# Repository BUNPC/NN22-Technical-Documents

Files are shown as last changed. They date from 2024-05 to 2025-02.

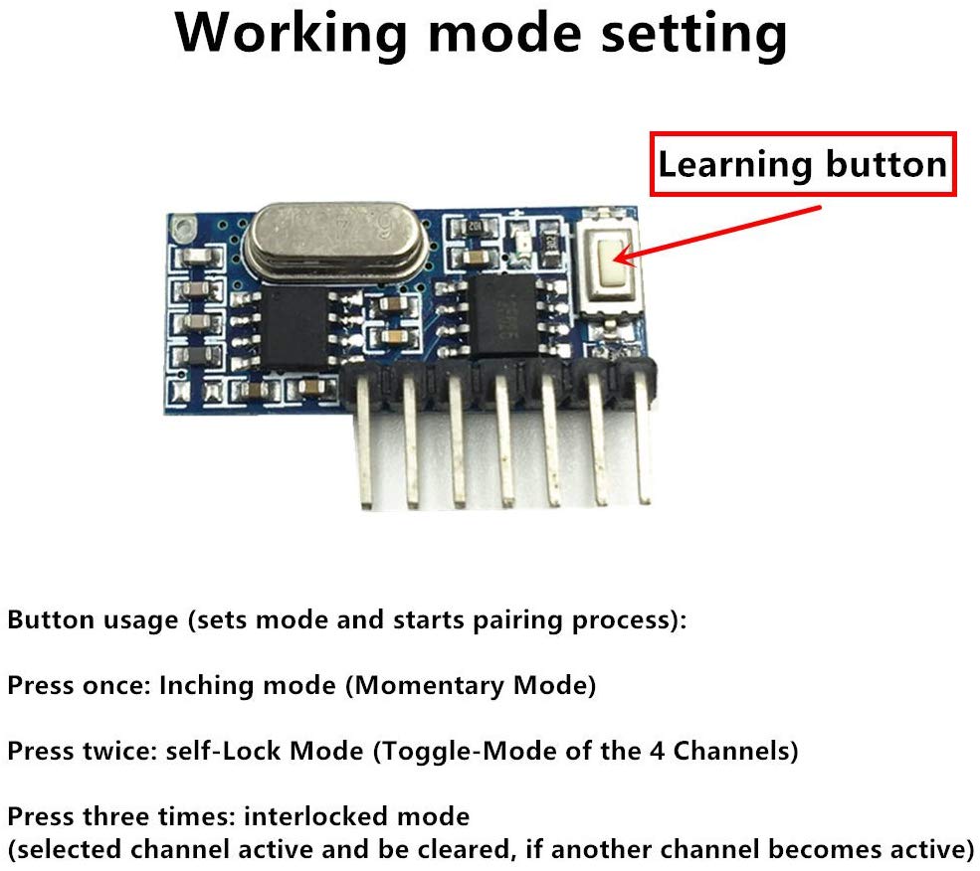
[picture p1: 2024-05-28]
Hardware Peripherial/ninjaNIRS Triggerbox/hardware/Rev1a_Eagle/61eN8m-au2L._AC_SL1001_.jpg

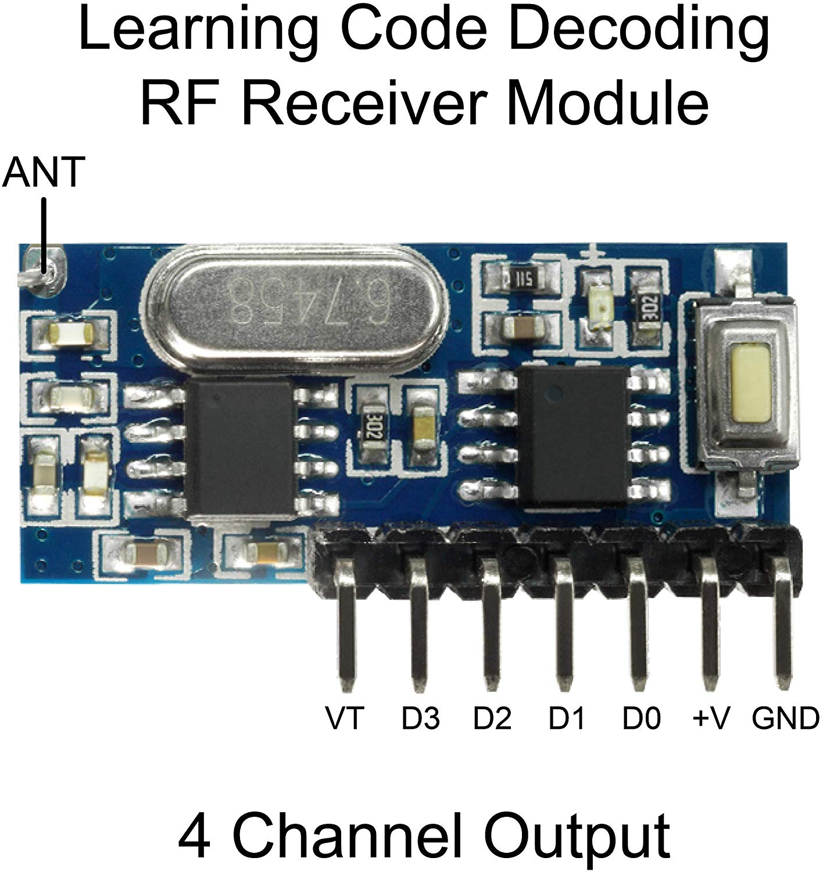
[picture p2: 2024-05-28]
Hardware Peripherial/ninjaNIRS Triggerbox/hardware/Rev1a_Eagle/81+gmd-v-IL._AC_SL1500_.jpg

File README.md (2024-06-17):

This repository contains the technical documentation used to create all parts of the NN22 whole-head fNIRS system.

A description of the documents contained in this respository and other instructions related to the ninjaNIRS system can be found at openfnirs.org [here](https://openfnirs.org/hardware/ninjanirs2022/).

Please use the [Hardware Forum](https://openfnirs.org/community/hardware-forum/) at openfnirs.org to discuss anything about the ninjaNIRS system.

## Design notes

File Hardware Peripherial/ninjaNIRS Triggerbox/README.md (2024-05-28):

# ninjaNIRS-triggerbox

This is a remote wireless trigger/IO box for the ninjaNIRS system.

## Rev 2 board To-Do

* polarity marks on LED
* fix up silkscreen and add text

## Development Log

*2023-08-07* Testing Rev 2.0 board with wireless link

All good.  Only issue is that channels 3 and 4 are swapped.

*2023-05-22* Look at Hammond box 1593XAL.  Nope!  Maybe 1598B?

Meeting with Bernhard.  Agreed-

* Proceed with new design for Hammond box
* Add an LDO on USB power input to run on e.g. 4.1V
* Adjust component values, update a few circuit issues
* Measure I-V curve on logic inputs to radio Tx, ensure 2N3904 can drive them

*2023-05-19* Footprinting and initial placement

*2023-05-17* Test Rev1a boards

*2023-05-15* Capture initial schematic in KiCAD

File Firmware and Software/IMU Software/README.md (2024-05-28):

# NN24 IMU board software

## Notes

MCU is an ATmega168 in a 28MLF package.

Pinout:

	22 PC3 - LED
    23 PC4 - SDA  (hardware TWI)
	24 PC5 - SCL  (hardware TWI)
	26 PD0 - RxD  (USART Rx)
	27 PD1 - TxD  (USART Tx)
	
Software should be pretty straightforward, since the built-in peripherals can be used.

## Software in this folder

| Folder | Description |
|---|---|
| `arduino-demo` | C code (not Arduino) to test the IMU on an Arduino uno |
| | Prints lines of text with 7 values |
| | |
| `avr-imu-readout`  | C code to receive command byte and send IMU data in binary |
| | |
| `avr-imu-blinky` | Blink the LED for quick hardware test |
| | |
| `avr-imu-led-test` | Read the IMU and encode somehow on the LED |
| | (for easy testing without a UART) |
| | |
| `linux-imu-client` | Linux client to read and display binary data from IMU |
| | |
| `BZ_example_code`  | Yes |
| | |

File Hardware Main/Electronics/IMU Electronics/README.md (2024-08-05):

# IMU Electronics
## Updated 5 August, 2024

All IMU electronics files are located in this folder. 

There is not a dedicated IMU backboard part as the IMU interface cards are intended to be used with the existing detector backplanes in place of a detector interface card.

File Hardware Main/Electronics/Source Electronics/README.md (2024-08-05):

# Source Electronics
## Updated 5 August, 2024

All source related files are located within this folder.

Two versions of the backplane are available, the 7 layer and single layer. 
- The 7 layer folder contains the files for the full height backplane to allow for up to 7 source interface cards to be connected.
- The single layer folder contains the files for the system configuration with only one interface card per backboard slot.

Two optode types are available, one standard source optode and one co-located optode.
- Standard source optode has been designed to fit in the spring loaded cap mounts made for the NIRx NIRSport 2 system
- Colocated source optode has been designed to mount on top of the active wet electrodes for the LiveAmp 8/16/32/64 EEG systems. All enclosure documents have also been included.

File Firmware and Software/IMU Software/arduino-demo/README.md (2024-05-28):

# arduino-demo

Initial IMU demo to run on an AVR "bare metal" (gcc-avr and avr-libc).

It initializes everything and prints the 7 values in decimal
(floats are too expensive).

Based on:

Bernhard Z's demo code

I2C code from USC I've used before

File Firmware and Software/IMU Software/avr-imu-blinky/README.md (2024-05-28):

# Blinky

This blinks the LED on an arduino board at 1Hz
(assuming the clock is set to 8MHz)

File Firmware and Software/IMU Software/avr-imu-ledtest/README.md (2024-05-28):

# avr-imu-readout

Readout the IMU in response to a serial command byte

send 7 signed 16-bit integers (low byte first)

see the code for more details

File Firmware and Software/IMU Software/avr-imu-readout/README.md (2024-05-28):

# avr-imu-readout

Readout the IMU in response to a serial command byte.
There are two compile-time options:

1.  Any byte recieved sends the return message
2.  'A' sends IMU data, 'T' sends 1111, 2222, 3333 etc test data

Normal data.  All 16-bit values sent LSB first.

| Offset | Value | Size | Notes |
|---|---|---|---|
| 0 | echo | 8 bits  | received byte |
| 1 | count | 8 bits  | = 14 |
| 2, 3 | temp | 16 bits | raw temperature |
| 4, 5 | gyro_x | 16 bits | raw gyro reading |
| 6, 7 | gyro_y | 16 bits | |
| 8, 9 | gyro_z | 16 bits | |
| 10, 11 | accel_x  | 16 bits | |
| 12, 13 | accel_y  | 16 bits | |
| 14, 15 | accel_z  | 16 bits | |
| 16 | checksum | 8 bits  | unsigned sum of offsets 1..15 |

Error response (may not be a complete list):

| Offset | Value | Size | Notes | |
|---|---|---|---|---|
| 0 | echo | 8 bits | received byte | |
| 1 | count | 8 bits | = 1 | |
| 2 | error | 8 bits | | |
| | | | 0x20 | NAK received after sending device address for writing |
| | | | 0x30 | NAK received after sending data |
| | | | 0x38 | Arbitration lost with address or data |
| | | | 0x48 | NAK received after sending device address for reading |
| | | | 0xff | unexpected data from IMU |
| 3 | checksum | 8 bits | | unsigned sum of offsets 1, 2 |

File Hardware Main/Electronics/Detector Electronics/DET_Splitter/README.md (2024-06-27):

# readout-splitter

This is a splitter board designed to be plug-compatible with the TIGRIS one.
See top-level README for some more details.

Connector from readout system is a Samtec SHF-117-01-L-D-SM shrouded 34-pin header
with 0.05" pitch.

Detector connector is Samtec SFMC-118-02-S-D 36-pin socket strip with 0.05" pitch.
Note that the TIGRIS schematic and layout use mirrored pinout for the detector connector
(odd-even swap).

Designed LDOs:

* Negative: ADP7182ACPZN-R7
* Positive: ADP7142ACPZN5.0-R7

The negative adjustable regulator should output -15.0V with the resistors shown.
There is an additional filter in the design (R+C on front side) which can
(according to the datasheet) reduce the noise a bit in the negative regulator.
There is no such provision for the positive regulator.

This is a 4-layer board and a bit dense.  There were a few compromises
made in routing with shared vias, etc but hopefully it will be OK.

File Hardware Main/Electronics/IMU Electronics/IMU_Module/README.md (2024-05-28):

# ninjanirs-imu

IMU and multiplexer designs for ninjaNIRS

## IMU Board

Board designed in early 2024 along with various adapters and a splitter.
The IMU board has an ATMeg168 so plenty of resources.

### UART connector pinout

    1 - VCC (5V or 3.3V)
	2 - TxD (output from MCU)
	3 - RxD (input to MCU)
	4 - GND
	
### RJ Adapter board pinout

    GND     1
	RxD        2
	TxD     3
	VCC        4

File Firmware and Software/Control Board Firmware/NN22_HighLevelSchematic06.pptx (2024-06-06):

## NinjaNIRS 2022 Firmware Schematic and Data Format Specification

Version 2023-8-17
Bernhard Zimmermann – bzim@bu.edu

## Control Card Block Diagram

Boston University Neurophotonics Center

Source Backplane

Detector Backplanes

Detector Backplanes

Detector Backplanes

Detector Backplanes

1 Backplane Connector
21 GPIO
(3 rows + 7x2 columns + 3 power select + 1 spare)

4 Backplane Connectors
Per Connector 17 GPIO
(5 common + 4x3 direct)

UART + SWD + 1 GPIO

2 GPIO (incl I2C)

Aux ADCs

PSRAM

PSRAM

6 GPIO

4 GPIO

2 GPIO

Aux DigIO

Remote Dig In

15 GPIO
UART with CTS/RTS or parallel data

2x6 GPIO

FPGA

4 GPIO

7 GPIO

Spare Con2

Spare Con.

12 GPIO

9 GPIO (incl RPi 0 SPI)

6 GPIO

FTDI USB

UART with RTS/CTS

RP2040

RPi Zero

## FPGA Firmware Block Diagram

27 x 1024
State Sequence RAM A

18 x 1024
Acquisition Sequence RAM B

Status Registers

8 rows
8 columns
3 power select

Source Backplane

Host PC

FTDI USB

USB

UART with RTS/CTS

UART Rx

Config
FSM

Program
Counter A

1 Trigger
1 Trigger Status
1 End Cycle
16 Board Select

+1

Detector Backplanes

Program
Counter B

+1

UART Rx

Clock Divider

readback

Acq
FSM/MUX

FPGA

UART Tx

FIFO

Aux ADC
Interface

## RAM Data Formats

RAM A: State Sequence

| 26 | 25 | 24 | 23 | 22 | 21 | 20 | 19 | 18 | 17 | 16 | 15 | 14 | 13 | 12 | 11 | 10 | 9 | 8 | 7 | 6 | 5 | 4 | 3 | 2 | 1 | 0
state 0 | end | X reserved | | | | stat | power | stat | power | column select | | column select | data source | | packet count | | | Lsr id | | | | | | X | row select
⁞
S 1023

End: 1 if last state in sequence: will jump to state 0 next; 0 otherwise: will jump to state i+1 next
X Reserved: reserved for later use
Status: ‘1’ send status packets instead of regular light level packets; ‘0’ send regular packets
Power: select LED power level. 0b001: high power, 0b010: mid power, 0b100: low power, 0b000: off (dark state)
Column select: Select column of LED to be illuminated. Even numbers correspond to XXX nm, odd numbers to YYY nm. This is selecting source boards.
Row select: Select row of LED to be illuminated. This is switching between LEDs in a source board

RAM B: Acquisition Sequence

| 17 | 16 | 15 | 14 | 13 | 12 | 11 | 10 | 9 | 8 | 7 | 6 | 5 | 4 | 3 | 2 | 1 | 0
State 0 | End | X | X | X | X | X | X | X | Acq Trg | End cyc | PC Tx Trg | Aux Tx Trg | DetB Rx En | X | UART Rx Mux

End: 1 if last state in sequence: will jump to state 0 next; 0 otherwise: will jump to state i+1 next
X Reserved: reserved for later use
Acq Trg: Transition form ‘0’ to ‘1’ will trigger the acquisition of one sample in the detector boards
End Cyc: Transition form ‘0’ to ‘1’ will cause the detector boards to move the current measurements to the transmit buffer, and reset the sample sums to 0
PC Tx Trg: Program counter A transmit trigger. Transition form ‘0’ to ‘1’ will cause the current program counter A (state) to be transmitted
Aux Tx Trg: Auxillary transmit trigger. Transition form ‘0’ to ‘1’ will cause the current auxiliary ADC values to be transmitted.
DetB Rx En: Enable reception of data from the detector board selected by UART Rx Mux. Sets CTS for the selected board.
UART Rx Mux: Selects from which detector board to receive data.

## Status Register Format

Status Register

| 23 | 22 | 21 | 20 | 19 | 18 | 17 | 16 | 15 | 14 | 13 | 12 | 11 | 10 | 9 | 8 | 7 | 6 | 5 | 4 | 3 | 2 | 1 | 0
| VN22Clk en | VN3P4 en | VN22 en | V9P0 en | V5P1src en | V5P1RPi en | V5P1B23 en | V5P1B01 en | Clk Div | | | | | | | | X | Rst Ram | Rst PC A | Rst DetB | | | Rst DetB | Run

Clk Div: Clock divider setting. RAM B state period = ClkDiv*8/96MHz
Rst Ram: Reset the PSRAM chip used in the external FIFO.
Rst PC A: Reset program counter A to 0
Rst DetB: Reset the microcontroller on the detector boards by pulling the RUN pins low. Each bit corresponds to one backplane.
Run: ‘1’: the clock divider and program counters A and B will run. ‘0’: Divider continues to run until PC B and the divider reach Zero, and then stay there. LED power will be set to 0 immediately.

## Command Format

Command sequence

| byte[0] | byte[1] | byte[2] | byte[3] | byte[4] | byte[5] | byte[6]
| 255 | addr[0] | addr[1] | rdat[0] | rdat[1] | rdat[2] | rdat[3]

Each command starts with a header byte (‘255’), then 2 address bytes, then 4 command payload bytes.
Addr: Address of data to be written or read. (see below)
Rdat: Register or RAM data to be written. Write all ‘0’ when reading a register / RAM location.

Command address format

| 15 | 14 | 13 | 12 | 11 | 10 | 9 | 8 | 7 | 6 | 5 | 4 | 3 | 2 | 1 | 0
| addr[1] | | | | | | | | addr[0]
| r̄/w | addr | X | X | X | X | Acq Trg | End cyc | PC Tx Trg | Aux Tx Trg | DetB Rx En | X | UART Rx Mux

r̄/w: ‘1’: write to the location specified by ‘addr’. ‘0’: read from location ‘addr’. Read is only save if Run = ‘0’.
Addr: Address to be read or written.
0b001 0000 0000 0000 through 0b 001 0011 1111 1111 : RAM A
0b010 0000 0000 0000 through 0b 001 0011 1111 1111 : RAM B
0b100 0000 0000 0001 : Status Register

## Output Data Packet Format

Note: The order of the individual data blocks below is determined by the contents of RAM A. The order shown below is a typical example as also implemented in the MATLAB helper functions.

Output data sequence

| byte[0..2] | byte[(0..7)+3] | byte[(0..27)+11] | … | byte[(0..27)+(n-1)*28+11] | byte[(0..17)+n*28+11]
| PC A packet | Auxiliary pkt | Det adapter pkt | … | Det adapter pkt | Accelerometer pkt

n: number of plugged in Detector Adapter Boards
See following slides for details on the individual packets.

## Program Counter A Packet Format

Packet generated by the FPGA, usually placed at the beginning of a sample/RAM B cycle to help framing the data.
See also PC TX Trg signal in RAM B data format slide.

Output data sequence

| byte[0] | byte[1] | byte[2]
| 254 | PC A [0] | PC A [1]

PC A [1]: high byte of program counter A
PC A [0]: low byte of program counter A

## Auxiliary Packet Format

Data packet generated by the FPGA. Contains the values of the two on-board auxiliary analog to digital converters (ADC). The ADCs are sampled and averaged at the same time and in the same manner as the main ADCs on the detector boards.
The packet also contains the status of the remote trigger signals and the Aux Digital inputs. These signals are sampled a few clock cycles after the rising edge of the “Aux Trg Tx” signal (see RAM B description).

| byte[0] | byte[1] | byte[2] | byte[3] | byte[4] | byte[5] | byte[6] | byte[7]
| 250 | Dig In | ADC0[0] | ADC0[1] | ADC0[2] | ADC1[0] | ADC1[1] | ADC1[2]

Dig In: Remote trigger and aux digital inputs sampled at time of “Aux Trg Tx” signal.
Bits (0..3): remote trigger signals.
Bits (4..5): aux digital inputs.
ADCx: 24 bit sum of all conversions since last “Aux Trg Tx” signal. [2] is the high byte (little endian). Unsigned integer.

Output data sequence

## Detector Adapter Packet Format

Data packet from the RP2040 microcontroller on a detector adapter board. Contains the main light intensity data.

| byte[0] | byte[1] | byte[2] | byte[3] | byte[4] | byte[5] | … | byte[24] | byte[25] | byte[26] | byte[27]
| 253 | 252 | Smp cnt | ADC0[0] | ADC0[1] | ADC0[2] | | ADC7[0] | ADC7[1] | ADC7[2] | 0

Smp cnt: Count of transmitted samples (modulo 256) since last restart of the detector adapter card.
ADCx: 24 bit sum of all conversions since last ‘end cycle’ signal. [2] is the high byte (little endian). Signed integer / two’s complement.

Output data sequence

## Detector Adapter Status Packet Format

Status data packet from the RP2040 microcontroller on a detector adapter board.

| byte[0] | byte[1] | byte[2] | byte[3] | … | byte[10] | byte[11] | byte[12] | byte[13] | byte[14] | byte[15] | byte[16] | byte[17]
| 237 | 236 | Smp cnt | UID[0] | | UID[7] | FWv[0] | FWv[1] | Temp[0] | Temp[1] | 0 | 0 | 0

Smp cnt: Count of transmitted samples (modulo 256) since last restart of the microcontroller.
UID: 64 bit unique ID from flash attached to microcontroller
FW: Firmware version.
Temp: Microcontroller internal temperature.
Conn flag: accelerometer connected flags (acc_connected_before_run<<1) || acc_connected_curr)

Output data sequence

## Accelerometer Packet Format

Data packet from the RP2040 microcontroller on the main control board. Contains the data read out from an IMU attached to the QWIIC port.

| byte[0] | byte[1] | byte[2] | byte[3] | byte[4] | … | byte[15] | byte[16] | byte[17]
| 249 | 248 | Smp cnt | Data0[0] | Data0[1] | | Data6[0] | Data6[1] | 0

Smp cnt: Count of transmitted samples (modulo 256) since last restart of the microcontroller.
Datax: 16 bit data words from the IMU, obtained right after last “End cyc” signal. [1] is the high byte (little endian). Signed integer / two’s complement.
Data0: Temperature
Data1: Gyro X
Data2: Gyro Y
Data3: Gyro Z
Data4: Accelerometer X
Data5: Accelerometer Y
Data6: Accelerometer Z

Output data sequence

## Accelerometer Status Packet Format

Status data packet from the RP2040 microcontroller on the main control board. Contains the controller temperature and board input voltage.

| byte[0] | byte[1] | byte[2] | byte[3] | … | byte[10] | byte[11] | byte[12] | byte[13] | byte[14] | byte[15] | byte[16] | byte[17] | byte[18] | byte[19]
| 237 | 236 | Smp cnt | UID[0] | | UID[7] | FWv[0] | FWv[1] | Temp[0] | Temp[1] | Vin[0] | Vin[1] | Conn flag | 0 | 0

Smp cnt: Count of transmitted samples (modulo 256) since last restart of the microcontroller.
UID: 64 bit unique ID from flash attached to microcontroller
FW: Firmware version.
Temp: Microcontroller internal temperature.
Vin: Control board input voltage.
Conn flag: accelerometer connected flags (acc_connected_before_run<<1) || acc_connected_curr)

Output data sequence

## Summary of Packet Headers

Summary of packet headers from the different data sources.

Packet Type | Header
Command from PC to FPGA | [255]
Reply to command (FPGA => PC) | [240]
Program Counter A Packet | [254]
Auxiliary Data Packet | [250]
Detector Adapter Data Packet | [253 252]
Detector Adapter Status Packet | [239 238]
IMU Controller Data Packet | [249 248]
IMU Controller Status Packet | [237 236]

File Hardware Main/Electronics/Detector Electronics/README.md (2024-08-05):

# Detector Electronics
## Updated 5 August, 2024

All detector related files are located within this folder.

Two versions of the backplane are available, the 6 layer and single layer. The 6 layer folder contains the files for the full height backplane to allow for up to 6 detector interface cards to be connected and the single layer folder contains the files for the system configuration with only one interface card per backboard slot.

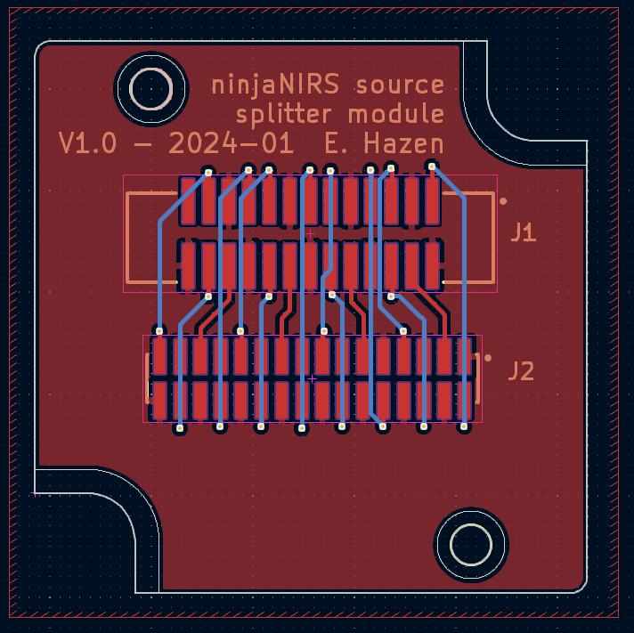
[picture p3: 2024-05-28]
Hardware Main/Electronics/Source Electronics/SRC_Splitter/source-splitter-layout-view.png

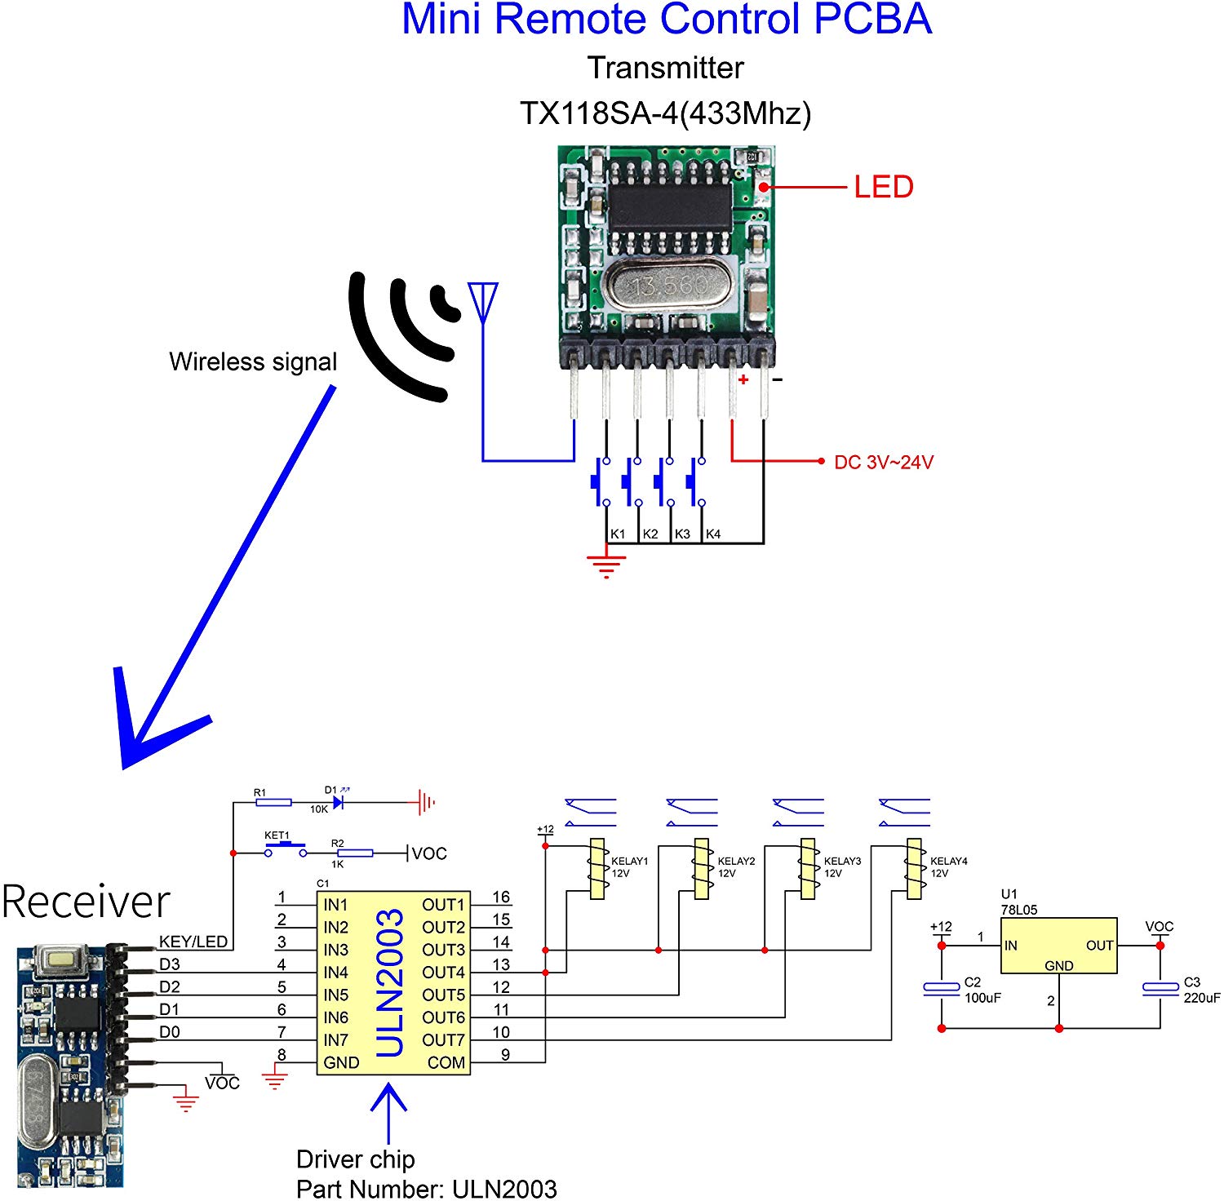
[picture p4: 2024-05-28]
Hardware Peripherial/ninjaNIRS Triggerbox/hardware/Rev1a_Eagle/81bwLxzH8NL._AC_SL1500_.jpg

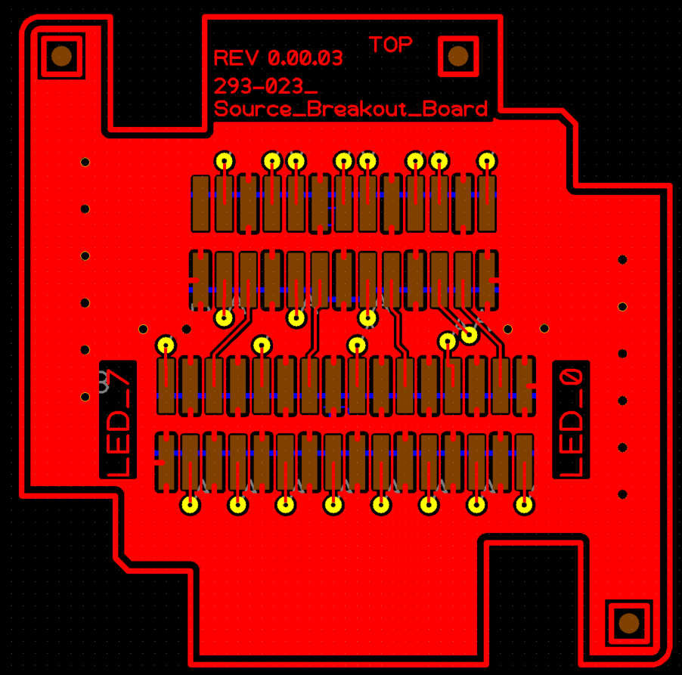
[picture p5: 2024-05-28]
Hardware Main/Electronics/Source Electronics/SRC_Optode/Standard Optode/PCB Files/Datasheets/SRC_BOX_Layout.png

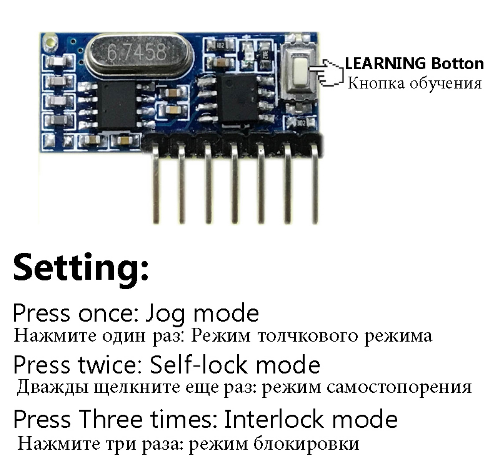
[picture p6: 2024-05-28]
Hardware Peripherial/ninjaNIRS Triggerbox/hardware/Rev1a_Eagle/423790-1a9fda4640fa45f28f44fabd3a5eae38_600x.png

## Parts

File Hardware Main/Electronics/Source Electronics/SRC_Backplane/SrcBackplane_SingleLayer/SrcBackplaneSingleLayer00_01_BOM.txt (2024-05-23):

connectors are Adam Tech ESMC-F-40-SGR-SMT-T/R

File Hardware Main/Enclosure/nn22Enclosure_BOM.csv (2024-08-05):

Line | Qty. | Item | Vendor | Part No.
1 | 2 | M4x0.7mm, 100mm Lg Socket Head Screws | McMaster Carr | 91290A185
2 | 3 | M4x0.7mm, 18mm Lg Socket Head Screws | McMaster Carr | 91290A164 | 1x fan attachment to case (interface card lower corner), 2x upper nylon strap holder (one each on end closest to ribbon cables)
3 | 9 | M4x0.7mm, 12mm Lg Socket Head Screws | McMaster Carr | 91290A148 | 4x fan filter, 1x fan attachment to case (main pcb upper corner), 2x upper nylon strap holder (one each on end closest to control board), 2x bottom ribbon cable support attachment
4 | 14 | M4x0.7mm Hex Nut | McMaster Carr | 90591A255
5 | 4 | M3x0.5mm, 8mm Lg Low-Profile Socket Head Screws | McMaster Carr | 93070A064
6 | 4 | M3x0.5mm, 5mm Lg Male-Female Threaded Hex Standoffs | McMaster Carr | 93655A091
7 | 4 | M3x0.5mm Nylon Insert Locknut | McMaster Carr | 90576A811
8 | 8 | 3/16"x3/16" Neodymium Cylinder Magnet | McMaster Carr | 5862K108 | If this size is unavailable another diameter can be used if models are altered
9 | 1 | 3/16" thick, 1/4" Wd Foam Strip w/ adhesive backing | McMaster Carr | 8694K124
10 | 1 | 3/16" thick acrylic | McMaster Carr | 8505K748
11 | 1 | 1/4" thick acrylic | McMaster Carr | 8505K754

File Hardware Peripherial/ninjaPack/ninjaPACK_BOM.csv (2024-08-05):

Line | Qty. | Item | Vendor | Part No.
1 | 4 | M3x0.5mm, 30mm Lg (Enclosure Corners) | McMaster Carr | 92125A140
2 | 4 | M3x0.5mm, 12mm Lg (PCB Corners) | McMaster Carr | 91290A117
3 | 4 | M3 nylon washer (PCB Corners) | McMaster Carr | 95610A330
4 | 8 | M3x0.5mm Hex Nut | McMaster Carr | 90591A250
5 | 4 | M4x0.7mm, 15mm Lg (Battery Carriers) | McMaster Carr | 91290A306
6 | 4 | M4x0.7mm Hex Nut | McMaster Carr | 90591A255
7 | 2 | Dewalt 12V battery adapter | Amazon | B09N42RJKW | https://a.co/d/3aEim6k
8 | 1 | WOJ-DBENC-001-RevAB (Dual Battery Enclosure Lid)
9 | 1 | WOJ-DBENC-002-RevAB (Dual Battery Enclosure Base)
10 | 1 | WOJ-DBPCB-SA-001-RevAB (Dual Battery PCB Subassembly)

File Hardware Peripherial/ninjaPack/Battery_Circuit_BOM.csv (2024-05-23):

Part | Value | Device | Package | Description | ARROW_PART_NUMBER | ARROW_PRICE-STOCK | DESCRIPTION | HEIGHT | MANUFACTURER_NAME | MANUFACTURER_PART_NUMBER | MOUSER_PART_NUMBER | MOUSER_PRICE-STOCK | PROD_ID | VALUE
C1 | 0.1uF | 0.1UF-KIT-EZ-50V-20% | CAP-PTH-SMALL-KIT | 0.1µF ceramic capacitors |  |  |  |  |  |  |  |  | CAP-08370 | 0.1uF
C2 | 0.1uF | 0.1UF-KIT-EZ-50V-20% | CAP-PTH-SMALL-KIT | 0.1µF ceramic capacitors |  |  |  |  |  |  |  |  | CAP-08370 | 0.1uF
IC2 | LTC4357IMS8#TRPBF | LTC4357IMS8#TRPBF | SOP65P490X110-8N | Hot Swap Controller 1-CH 80V N-Channel Positive High Voltage Automotive 8-Pin MSOP T/R | LTC4357IMS8#TRPBF | https://www.arrow.com/en/products/ltc4357ims8trpbf/analog-devices?region=nac | Hot Swap Controller 1-CH 80V N-Channel Positive High Voltage Automotive 8-Pin MSOP T/R | 1.1mm | Analog Devices | LTC4357IMS8#TRPBF | 584-LTC4357IMS8TRPBF | https://www.mouser.co.uk/ProductDetail/Analog-Devices/LTC4357IMS8TRPBF?qs=hVkxg5c3xu9xOCu4lpdF5Q%3D%3D
IC3 | LTC4357IMS8#TRPBF | LTC4357IMS8#TRPBF | SOP65P490X110-8N | Hot Swap Controller 1-CH 80V N-Channel Positive High Voltage Automotive 8-Pin MSOP T/R | LTC4357IMS8#TRPBF | https://www.arrow.com/en/products/ltc4357ims8trpbf/analog-devices?region=nac | Hot Swap Controller 1-CH 80V N-Channel Positive High Voltage Automotive 8-Pin MSOP T/R | 1.1mm | Analog Devices | LTC4357IMS8#TRPBF | 584-LTC4357IMS8TRPBF | https://www.mouser.co.uk/ProductDetail/Analog-Devices/LTC4357IMS8TRPBF?qs=hVkxg5c3xu9xOCu4lpdF5Q%3D%3D
Q1 | RD3P08BBDTL | RD3P08BBDTL | RD3P175SNFRATL | RD3P08BBDTL N-Channel MOSFET, 80 A, 100 V RD3P08BBD, 3-Pin DPAK ROHM |  |  | RD3P08BBDTL N-Channel MOSFET, 80 A, 100 V RD3P08BBD, 3-Pin DPAK ROHM | mm | ROHM Semiconductor | RD3P08BBDTL | 755-RD3P08BBDTL | https://www.mouser.co.uk/ProductDetail/ROHM-Semiconductor/RD3P08BBDTL?qs=qSfuJ%252Bfl%2Fd6NkJEicmek1A%3D%3D
Q2 | RD3P08BBDTL | RD3P08BBDTL | RD3P175SNFRATL | RD3P08BBDTL N-Channel MOSFET, 80 A, 100 V RD3P08BBD, 3-Pin DPAK ROHM |  |  | RD3P08BBDTL N-Channel MOSFET, 80 A, 100 V RD3P08BBD, 3-Pin DPAK ROHM | mm | ROHM Semiconductor | RD3P08BBDTL | 755-RD3P08BBDTL | https://www.mouser.co.uk/ProductDetail/ROHM-Semiconductor/RD3P08BBDTL?qs=qSfuJ%252Bfl%2Fd6NkJEicmek1A%3D%3D
R1 | 100 | 100OHM-HORIZ-1/4W-1% | AXIAL-0.3 | 100Ω resistor |  |  |  |  |  |  |  |  | RES-12181 | 100
R2 | 100 | 100OHM-HORIZ-1/4W-1% | AXIAL-0.3 | 100Ω resistor |  |  |  |  |  |  |  |  | RES-12181 | 100
S1 | A8L-21-12N2 | A8L-21-12N2 | A8L2112N2 | Rocker Switches ROCKER SWITCH |  |  | Rocker Switches ROCKER SWITCH | 22.1mm | Omron Electronics | A8L-21-12N2 | 653-A8L-21-12N2 | https://www.mouser.co.uk/ProductDetail/Omron-Electronics/A8L-21-12N2?qs=wE98CiVmOw76dmZWfHCJ3A%3D%3D

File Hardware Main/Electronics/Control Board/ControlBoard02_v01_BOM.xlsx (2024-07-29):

Designator | Value | Footprint | Populate | MPN | Manufacturer | MPN | Manufacturer
C1001 | 0.1u | 0402-CAP | 1 | GRM155R71H104KE14D | Murata
C1002 | 0.1u | 0402-CAP | 1 | GRM155R71H104KE14D | Murata
C1003 | 4.7u | 0402-CAP | 1 | CL05A475MP5NRNC | Samsung
C1004 | 22u | 0805-CAP | 1 | CL21A226MAYNNNE | Samsung
C1005 | 10n | 0603-CAP | 1 | GRM1885C1H103JA01D | Murata
C1006 | 0.1u | 0402-CAP | 1 | GRM155R71H104KE14D | Murata
C1007 | 4.7u | 0402-CAP | 1 | CL05A475MP5NRNC | Samsung
C1008 | 4.7u | 0402-CAP | 1 | CL05A475MP5NRNC | Samsung
C1009 | 0.1u | 0402-CAP | 1 | GRM155R71H104KE14D | Murata
C101 | 0.1u | 0402-CAP | 1 | GRM155R71H104KE14D | Murata
C1010 | 0.1u | 0402-CAP | 1 | GRM155R71H104KE14D | Murata
C201 | 0.1u | 0402-CAP | 1 | GRM155R71H104KE14D | Murata
C202 | 0.1u | 0402-CAP | 1 | GRM155R71H104KE14D | Murata
C203 | 0.1u | 0402-CAP | 1 | GRM155R71H104KE14D | Murata
C204 | 0.1u | 0402-CAP | 1 | GRM155R71H104KE14D | Murata
C205 | 27p | 0402-CAP | 1 | GCM1555C1H270JA16D | Murata
C206 | 27p | 0402-CAP | 1 | GCM1555C1H270JA16D | Murata
C207 | 0.1u | 0402-CAP | 1 | GRM155R71H104KE14D | Murata
C301 | 0.1u | 0402-CAP | 1 | GRM155R71H104KE14D | Murata
C501 | 0.1u | 0402-CAP | 1 | GRM155R71H104KE14D | Murata
C502 | 4.7u | 0402-CAP | 1 | CL05A475MP5NRNC | Samsung
C503 | 10n | 0603-CAP | 1 | GRM1885C1H103JA01D | Murata
C504 | 0.1u | 0402-CAP | 1 | GRM155R71H104KE14D | Murata
C505 | 10n | 0603-CAP | 1 | GRM1885C1H103JA01D | Murata
C506 | 22u | 0805-CAP | 1 | CL21A226MAYNNNE | Samsung
C507 | 0.1u | 0402-CAP | 1 | GRM155R71H104KE14D | Murata
C508 | 0.1u | 0402-CAP | 1 | GRM155R71H104KE14D | Murata
C509 | 4.7u | 0402-CAP | 1 | CL05A475MP5NRNC | Samsung
C510 | 4.7u | 0402-CAP | 1 | CL05A475MP5NRNC | Samsung
C601 | 4.7u | 0402-CAP | 1 | CL05A475MP5NRNC | Samsung
C602 | 4.7u | 0402-CAP | 1 | CL05A475MP5NRNC | Samsung
C603 | 0.1u | 0402-CAP | 1 | GRM155R71H104KE14D | Murata
C604 | 4.7u | 0402-CAP | 1 | CL05A475MP5NRNC | Samsung
C605 | 4.7u | 0402-CAP | 1 | CL05A475MP5NRNC | Samsung
C606 | 0.1u | 0402-CAP | 1 | GRM155R71H104KE14D | Murata
C607 | 0.1u | 0402-CAP | 1 | GRM155R71H104KE14D | Murata
C608 | 0.1u | 0402-CAP | 1 | GRM155R71H104KE14D | Murata
C609 | 22u | 0805-CAP | 1 | CL21A226MAYNNNE | Samsung
C610 | 4.7u | 0402-CAP | 1 | CL05A475MP5NRNC | Samsung
C611 | 27p | 0402-CAP | 1 | GCM1555C1H270JA16D | Murata
C612 | 27p | 0402-CAP | 1 | GCM1555C1H270JA16D | Murata
C613 | 0.1u | 0402-CAP | 1 | GRM155R71H104KE14D | Murata
C614 | 0.1u | 0402-CAP | 1 | GRM155R71H104KE14D | Murata
C615 | 0.1u | 0402-CAP | 1 | GRM155R71H104KE14D | Murata
C616 | 0.1u | 0402-CAP | 1 | GRM155R71H104KE14D | Murata
C617 | 0.1u | 0402-CAP | 1 | GRM155R71H104KE14D | Murata
C618 | DNP | 1210 | 0
C619 | 0.1u | 0402-CAP | 1 | GRM155R71H104KE14D | Murata
C620 | 0.1u | 0402-CAP | 1 | GRM155R71H104KE14D | Murata
C621 | 0.1u | 0402-CAP | 1 | GRM155R71H104KE14D | Murata
C622 | 0.1u | 0402-CAP | 1 | GRM155R71H104KE14D | Murata
C623 | 0.1u | 0402-CAP | 1 | GRM155R71H104KE14D | Murata
C624 | 0.1u | 0402-CAP | 1 | GRM155R71H104KE14D | Murata
C625 | 0.1u | 0402-CAP | 1 | GRM155R71H104KE14D | Murata
C626 | 0.1u | 0402-CAP | 1 | GRM155R71H104KE14D | Murata
C701 | 22p | 0402-CAP | 1 | GCM1555C1H220JA16D | Murata
C702 | 22u | 0805-CAP | 1 | CL21A226MAYNNNE | Samsung
C703 | 22u | 0805-CAP | 1 | CL21A226MAYNNNE | Samsung
C704 | 22u | 0805-CAP | 1 | CL21A226MAYNNNE | Samsung
C705 | 100u/25V | 2917-CAP | 1 | TCJD107M025R0055 | KYOCERA AVX
C706 | 22u | 0805-CAP | 1 | CL21A226MAYNNNE | Samsung
C707 | 100u/25V | 2917-CAP | 1 | TCJD107M025R0055 | KYOCERA AVX
C708 | 100u/25V | 2917-CAP | 1 | TCJD107M025R0055 | KYOCERA AVX
C709 | 22u | 0805-CAP | 1 | CL21A226MAYNNNE | Samsung
C710 | 22u | 0805-CAP | 1 | CL21A226MAYNNNE | Samsung
C711 | 39p | 0402-CAP | 1 | CC0402JRNPO9BN390 | Yageo
C712 | 22u | 0805-CAP | 1 | CL21A226MAYNNNE | Samsung
C713 | 22u | 0805-CAP | 1 | CL21A226MAYNNNE | Samsung
C714 | 22u | 0805-CAP | 1 | CL21A226MAYNNNE | Samsung
C715 | 39p | 0402-CAP | 1 | CC0402JRNPO9BN390 | Yageo
C716 | 22u | 0805-CAP | 1 | CL21A226MAYNNNE | Samsung
C717 | 22u | 0805-CAP | 1 | CL21A226MAYNNNE | Samsung
C718 | 330u/25V | CAP-SMD-POL-8X10 | 1 | EEE-FP1E331AP | Panasonic
C719 | 22u | 0805-CAP | 1 | CL21A226MAYNNNE | Samsung
C720 | 39p | 0402-CAP | 1 | CC0402JRNPO9BN390 | Yageo
C721 | 22u | 0805-CAP | 1 | CL21A226MAYNNNE | Samsung
C722 | 22u | 0805-CAP | 1 | CL21A226MAYNNNE | Samsung
C723 | 22u | 0805-CAP | 1 | CL21A226MAYNNNE | Samsung
C724 | 39p | 0402-CAP | 1 | CC0402JRNPO9BN390 | Yageo
C725 | 22u | 0805-CAP | 1 | CL21A226MAYNNNE | Samsung
C726 | 22u | 0805-CAP | 1 | CL21A226MAYNNNE | Samsung
C727 | 22u | 0805-CAP | 1 | CL21A226MAYNNNE | Samsung
C728 | 22u | 0805-CAP | 1 | CL21A226MAYNNNE | Samsung
C729 | 10n | 0603-CAP | 1 | GRM1885C1H103JA01D | Murata
C730 | 1n | 0603-CAP | 1 | GRM1885C1H102JA01D | Murata
C731 | 22u | 0805-CAP | 1 | CL21A226MAYNNNE | Samsung
C801 | 100u/25V | 2917-CAP | 1 | TCJD107M025R0055 | KYOCERA AVX
C802 | 4.7u | 0805-CAP | 1 | CL21A475KBQNNNE | Samsung
C803 | 4.7u | 0805-CAP | 1 | CL21A475KBQNNNE | Samsung
C804 | 10u | 1206 | 1 | CL31A106MBHNNNE | Samsung
C805 | 10u | 1206 | 1 | CL31A106MBHNNNE | Samsung
C806 | 10u | 1206 | 1 | CL31A106MBHNNNE | Samsung
C807 | 4.7u | 0805-CAP | 1 | CL21A475KBQNNNE | Samsung
C808 | 4.7u | 0805-CAP | 1 | CL21A475KBQNNNE | Samsung
C809 | 4.7u | 0805-CAP | 1 | CL21A475KBQNNNE | Samsung
C810 | 4.7u | 0805-CAP | 1 | CL21A475KBQNNNE | Samsung
C811 | 1u | 0603-CAP | 1 | CL10A105KB8NNNC | Samsung
C812 | 100u/25V | 2917-CAP | 1 | TCJD107M025R0055 | KYOCERA AVX
C813 | 4.7u | 0805-CAP | 1 | CL21A475KBQNNNE | Samsung
C814 | 4.7u | 0805-CAP | 1 | CL21A475KBQNNNE | Samsung
C815 | 10u | 1206 | 1 | CL31A106MBHNNNE | Samsung
C816 | 10u | 1206 | 1 | CL31A106MBHNNNE | Samsung
C817 | 10u | 1206 | 1 | CL31A106MBHNNNE | Samsung
C818 | 4.7u | 0805-CAP | 1 | CL21A475KBQNNNE | Samsung
C819 | 4.7u | 0805-CAP | 1 | CL21A475KBQNNNE | Samsung
C820 | 4.7u | 0805-CAP | 1 | CL21A475KBQNNNE | Samsung
C821 | 4.7u | 0805-CAP | 1 | CL21A475KBQNNNE | Samsung
C822 | 1u | 0603-CAP | 1 | CL10A105KB8NNNC | Samsung
C823 | 4.7u | 0805-CAP | 1 | CL21A475KBQNNNE | Samsung
C824 | 4.7u | 0805-CAP | 1 | CL21A475KBQNNNE | Samsung
C825 | 100u | 1206 | 1 | CL31A107MQHNNNE | Samsung
C826 | 100u | 1206 | 1 | CL31A107MQHNNNE | Samsung
C827 | DNP | 1206 | 0
C828 | 4.7u | 0805-CAP | 1 | CL21A475KBQNNNE | Samsung
C829 | 4.7u | 0805-CAP | 1 | CL21A475KBQNNNE | Samsung
C830 | 1u | 0603-CAP | 1 | CL10A105KB8NNNC | Samsung
C831 | 100u/25V | 2917-CAP | 1 | TCJD107M025R0055 | KYOCERA AVX
C901 | 22u | 0805-CAP | 1 | CL21A226MAYNNNE | Samsung
C902 | 22u | 0805-CAP | 1 | CL21A226MAYNNNE | Samsung
C903 | 22u | 0805-CAP | 1 | CL21A226MAYNNNE | Samsung
C904 | 4.7u | 0402-CAP | 1 | CL05A475MP5NRNC | Samsung
C905 | 4.7u | 0402-CAP | 1 | CL05A475MP5NRNC | Samsung
C906 | 4.7u | 0402-CAP | 1 | CL05A475MP5NRNC | Samsung
C907 | 4.7u | 0402-CAP | 1 | CL05A475MP5NRNC | Samsung
C908 | 4.7u | 0402-CAP | 1 | CL05A475MP5NRNC | Samsung
C909 | 4.7u | 0402-CAP | 1 | CL05A475MP5NRNC | Samsung
C910 | 4.7u | 0402-CAP | 1 | CL05A475MP5NRNC | Samsung
C911 | 4.7u | 0402-CAP | 1 | CL05A475MP5NRNC | Samsung
C912 | 4.7u | 0402-CAP | 1 | CL05A475MP5NRNC | Samsung
C913 | 4.7u | 0402-CAP | 1 | CL05A475MP5NRNC | Samsung
C914 | 4.7u | 0402-CAP | 1 | CL05A475MP5NRNC | Samsung
C915 | DNP | 0805-CAP | 0
C916 | 0.1u | 0402-CAP | 1 | GRM155R71H104KE14D | Murata
C917 | 0.1u | 0402-CAP | 1 | GRM155R71H104KE14D | Murata
C918 | 0.1u | 0402-CAP | 1 | GRM155R71H104KE14D | Murata
C919 | 0.1u | 0402-CAP | 1 | GRM155R71H104KE14D | Murata
C920 | 0.1u | 0402-CAP | 1 | GRM155R71H104KE14D | Murata
C921 | 0.1u | 0402-CAP | 1 | GRM155R71H104KE14D | Murata
C922 | 0.1u | 0402-CAP | 1 | GRM155R71H104KE14D | Murata
C923 | 0.1u | 0402-CAP | 1 | GRM155R71H104KE14D | Murata
C924 | 0.1u | 0402-CAP | 1 | GRM155R71H104KE14D | Murata
C925 | 0.1u | 0402-CAP | 1 | GRM155R71H104KE14D | Murata
C926 | 0.1u | 0402-CAP | 1 | GRM155R71H104KE14D | Murata
C927 | 0.1u | 0402-CAP | 1 | GRM155R71H104KE14D | Murata
C928 | 0.1u | 0402-CAP | 1 | GRM155R71H104KE14D | Murata
C929 | 0.1u | 0402-CAP | 1 | GRM155R71H104KE14D | Murata
C930 | 0.1u | 0402-CAP | 1 | GRM155R71H104KE14D | Murata
C931 | 0.1u | 0402-CAP | 1 | GRM155R71H104KE14D | Murata
C932 | 0.1u | 0402-CAP | 1 | GRM155R71H104KE14D | Murata
C933 | 0.1u | 0402-CAP | 1 | GRM155R71H104KE14D | Murata
C934 | 0.1u | 0402-CAP | 1 | GRM155R71H104KE14D | Murata
C935 | 0.1u | 0402-CAP | 1 | GRM155R71H104KE14D | Murata
C936 | 0.1u | 0402-CAP | 1 | GRM155R71H104KE14D | Murata
C937 | 0.1u | 0402-CAP | 1 | GRM155R71H104KE14D | Murata
C938 | 0.1u | 0402-CAP | 1 | GRM155R71H104KE14D | Murata
C939 | 0.1u | 0402-CAP | 1 | GRM155R71H104KE14D | Murata
C940 | 0.1u | 0402-CAP | 1 | GRM155R71H104KE14D | Murata
C941 | 0.1u | 0402-CAP | 1 | GRM155R71H104KE14D | Murata
C942 | 0.1u | 0402-CAP | 1 | GRM155R71H104KE14D | Murata
C943 | 22p | 0402-CAP | 1 | GCM1555C1H220JA16D | Murata
C944 | 22u | 0805-CAP | 1 | CL21A226MAYNNNE | Samsung
D101 | D1213A-02SO | SOT23-6 | 1 | D1213A-02SO-7 | Diodes Inc.
D201 | D1213A-02SO | SOT23-6 | 1 | D1213A-02SO-7 | Diodes Inc.
D202 | D1213A-02SO | SOT23-6 | 1 | D1213A-02SO-7 | Diodes Inc.
D203 |  | SOD523 | 1 | SBR1A20T5-7 | Diodes Inc.
D204 | D1213A-02SO | SOT23-6 | 1 | D1213A-02SO-7 | Diodes Inc.
D501 | D1213A-02SO | SOT23-6 | 1 | D1213A-02SO-7 | Diodes Inc.
D502 | D1213A-02SO | SOT23-6 | 1 | D1213A-02SO-7 | Diodes Inc.
D503 | D1213A-02SO | SOT23-6 | 1 | D1213A-02SO-7 | Diodes Inc.
D601 | PACDN042 | SOT23-3 | 1 | PACDN042Y3R | onsemi
D602 | D1213A-02SO | SOT23-6 | 1 | D1213A-02SO-7 | Diodes Inc.
D701 |  | SOD128 | 1 | CMS05(TE12L,Q,M) | Toshiba
D702 |  | SOD128 | 1 | CMS05(TE12L,Q,M) | Toshiba
D703 |  | SOD128 | 1 | CMS05(TE12L,Q,M) | Toshiba
D704 |  | SOD128 | 1 | CMS05(TE12L,Q,M) | Toshiba
F101 | 0ZCM0010FF2G | 0603-RES | 1 | 0ZCM0010FF2G | Bel Fuse
F201 | 0ZCM0010FF2G | 0603-RES | 1 | 0ZCM0010FF2G | Bel Fuse
F202 | 0ZCM0010FF2G | 0603-RES | 1 | 0ZCM0010FF2G | Bel Fuse
F203 | 0ZCM0010FF2G | 0603-RES | 1 | 0ZCM0010FF2G | Bel Fuse
F701 | 2920L600/16MR | 2920-FUSE | 1 | 2920L600/16MR | Littelfuse
FID901 | FIDUCIALUFIDUCIAL | MICRO-FIDUCIAL | 0
FID902 | FIDUCIALUFIDUCIAL | MICRO-FIDUCIAL | 0
FID903 | FIDUCIALUFIDUCIAL | MICRO-FIDUCIAL | 0
FID904 | FIDUCIALUFIDUCIAL | MICRO-FIDUCIAL | 0
FID905 | FIDUCIALUFIDUCIAL | MICRO-FIDUCIAL | 0
FID906 | FIDUCIALUFIDUCIAL | MICRO-FIDUCIAL | 0
FID907 | FIDUCIALUFIDUCIAL | MICRO-FIDUCIAL | 0
J1001 | U.FL | U.FL | 1 | 1909763-1 | TE Connectivity
J101 | M20X2_PTH | M20X2_PTH | 1 | PPPC202LFBN-RC | Sullins
J102 | M04X1_JST_SH_RA | M04X1_JST_SH_SM_RA | 1 | SM04B-SRSS-TB(LF)(SN) | JST
J103 | M04X1_JST_SH_RA | M04X1_JST_SH_SM_RA | 1 | SM04B-SRSS-TB(LF)(SN) | JST
J201 | M04X1_JST_SH_RA | M04X1_JST_SH_SM_RA | 1 | SM04B-SRSS-TB(LF)(SN) | JST
J202 | M04X1_JST_SH_RA | M04X1_JST_SH_SM_RA | 1 | SM04B-SRSS-TB(LF)(SN) | JST
J203 | USB-MICRO | USB-MICRO | 1 | 10118194-0001LF | Amphenol Communications Solutions
J204 | M04X2_0.050_SMD_NO_CREAM | M04X2_0.050_SMD_NO_CREAM | 0
J205 | M04X2_0.050_SMD_NO_CREAM | M04X2_0.050_SMD_NO_CREAM | 0
J206 |  | MOLEX-1X3 | 1 | 22-11-2032 | Molex
J207 |  | MOLEX-1X3 | 0 | 22-11-2032 | Molex
J301 | M04X2_0.050_SMD_NO_CREAM | M04X2_0.050_SMD_NO_CREAM | 0
J302 | M03X2PTH | 2X3-NS | 1 | 67997-206HLF | Amphenol Communications Solutions
J303 | M05X2_SMD_0.050_NOCREAM | M05X2_0.050_SMD_NO_CREAM | 0
J304 | M05X2_SMD_0.050_NOCREAM | M05X2_0.050_SMD_NO_CREAM | 0
J401 | M20X2_HARFLEX_M | M20X2_HARFLEX_M | 1 | 15150402601000 | HARTING Elektronik
J402 | M20X2_HARFLEX_M | M20X2_HARFLEX_M | 1 | 15150402601000 | HARTING Elektronik
J403 | M20X2_HARFLEX_M | M20X2_HARFLEX_M | 1 | 15150402601000 | HARTING Elektronik
J404 | M20X2_HARFLEX_M | M20X2_HARFLEX_M | 1 | 15150402601000 | HARTING Elektronik
J405 | M20X2_HARFLEX_M | M20X2_HARFLEX_M | 1 | 15150402601000 | HARTING Elektronik
J501 | SMAMMCX_PTH | MMCX_PTH_STR | 1 | 73415-1001 | Molex
J502 | SMAMMCX_PTH | MMCX_PTH_STR | 1 | 73415-1001 | Molex
J503 | SMAMMCX_PTH | MMCX_PTH_STR | 1 | 73415-1001 | Molex
J504 | SMAMMCX_PTH | MMCX_PTH_STR | 1 | 73415-1001 | Molex
J505 | SMAMMCX_PTH | MMCX_PTH_STR | 1 | 73415-1001 | Molex
J506 | SMAMMCX_PTH | MMCX_PTH_STR | 1 | 73415-1001 | Molex
J507 | U.FL | U.FL | 1 | 1909763-1 | TE Connectivity
J601 | USB-MICRO | USB-MICRO | 1 | 10118194-0001LF | Amphenol Communications Solutions
J602 | M04X2_0.050_SMD_NO_CREAM | M04X2_0.050_SMD_NO_CREAM | 0
J603 | M13X2_0.050_SHF_NO_CREAM | M13X2_0.050_SHF_NO_CREAM | 0
J604 | M07X1_PTH | M07X1_PTH | 1 | PPPC071LFBN-RC | Sullins
J701 | M04X2_SHROUDED | M04X2-SHROUDED | 1 | 75869-332LF | Amphenol Communications Solutions
J702 | POWERJACK_PJ051AH | PJ051AH | 1 | PJ-051AH | CUI Devices
LED101 | LTST-C191KRKT | LED-0603 | 1 | LTST-C191KRKT | Lite-On
LED102 | LTST-C191KGKT | LED-0603 | 1 | LTST-C191KGKT | Lite-On
LED201 | LTST-C191KRKT | LED-0603 | 1 | LTST-C191KRKT | Lite-On
LED202 | LTST-C191KGKT | LED-0603 | 1 | LTST-C191KGKT | Lite-On
LED203 | LTST-C191KGKT | LED-0603 | 1 | LTST-C191KGKT | Lite-On
LED301 | LTST-C191KRKT | LED-0603 | 1 | LTST-C191KRKT | Lite-On
LED302 | LTST-C191KGKT | LED-0603 | 1 | LTST-C191KGKT | Lite-On
LED303 | LTST-C191KRKT | LED-0603 | 1 | LTST-C191KRKT | Lite-On
LED304 | LTST-C191KGKT | LED-0603 | 1 | LTST-C191KGKT | Lite-On
LED305 | LTST-C191KRKT | LED-0603 | 1 | LTST-C191KRKT | Lite-On
LED306 | LTST-C191KGKT | LED-0603 | 1 | LTST-C191KGKT | Lite-On
LED601 | LTST-C191KGKT | LED-0603 | 1 | LTST-C191KGKT | Lite-On
LED602 | LTST-C191KGKT | LED-0603 | 1 | LTST-C191KGKT | Lite-On
LED603 | LTST-C191KRKT | LED-0603 | 1 | LTST-C191KRKT | Lite-On
LED604 | LTST-C191KGKT | LED-0603 | 1 | LTST-C191KGKT | Lite-On
LED605 | LTST-C191KRKT | LED-0603 | 1 | LTST-C191KRKT | Lite-On
LED606 | LTST-C191KRKT | LED-0603 | 1 | LTST-C191KRKT | Lite-On
LED901 | LTST-C191KRKT | LED-0603 | 1 | LTST-C191KRKT | Lite-On
LF501 | FERRITE1206 | 1206 | 1 | MH3261-601Y | Bourns
LF601 | FERRITE0603 | 0603-FER | 1 | BLM18PG121SN1D | Murata
LF602 | FERRITE0603 | 0603-FER | 1 | BLM18PG121SN1D | Murata
LF603 | FERRITE1206 | 1206 | 1 | MH3261-601Y | Bourns
LF701 | FERRITE1206 | 1206 | 1 | MH3261-601Y | Bourns
LS601 | PKMCS0909E4000-R1 | XDCR_PKMCS0909E4000-R1 | 1 | PKMCS0909E4000-R1 | Murata
Q201 | MOSFET-NCHANNELSMD | SOT23-3 | 1 | DMG3402L-7 | Diodes Inc.
Q701 | MOSFET-NCHANNELSMD | SOT23-3 | 1 | DMG3402L-7 | Diodes Inc.
Q702 | MOSFET-PCHANNEL_SO8 | SO08 | 1 | SI4431CDY-T1-GE3 | Vishay
R1001 | 15 | 0402-RES | 1 | RC0402FR-0715RL | Yageo
R1002 | 100 | 0402-RES | 1 | RC0402FR-07100RL | Yageo
R1003 | 470 | 0402-RES | 1 | RC0402FR-07470RL | Yageo
R101 | 10k | 0402-RES | 1 | RC0402FR-0710KL | Yageo
R102 | 10k | 0402-RES | 1 | RC0402FR-0710KL | Yageo
R103 | 10k | 0402-RES | 1 | RC0402FR-0710KL | Yageo
R104 | 470 | 0402-RES | 1 | RC0402FR-07470RL | Yageo
R105 | 470 | 0402-RES | 1 | RC0402FR-07470RL | Yageo
R201 | 1k | 0402-RES | 1 | RC0402FR-071KL | Yageo
R202 | DNP | 0402-RES | 0
R203 | 10k | 0402-RES | 1 | RC0402FR-0710KL | Yageo
R204 | 10k | 0402-RES | 1 | RC0402FR-0710KL | Yageo
R205 | 100k | 0402-RES | 1 | RC0402FR-07100KL | Yageo
R206 | 47k | 0402-RES | 1 | RC0402FR-0747KL | Yageo
R207 | 10k | 0402-RES | 1 | RC0402FR-0710KL | Yageo
R208 | 10k | 0402-RES | 1 | RC0402FR-0710KL | Yageo
R209 | 27 | 0402-RES | 1 | RC0402FR-0727RL | Yageo
R210 | 10k | 0402-RES | 1 | RC0402FR-0710KL | Yageo
R211 | 27 | 0402-RES | 1 | RC0402FR-0727RL | Yageo
R212 | DNP | 0402-RES | 0
R213 | 1.2k | 0402-RES | 1 | RC0402FR-071K2L | Yageo
R214 | DNP | 0402-RES | 0
R215 | 470 | 0402-RES | 1 | RC0402FR-07470RL | Yageo
R216 | 470 | 0402-RES | 1 | RC0402FR-07470RL | Yageo
R217 | 100k | 0402-RES | 1 | RC0402FR-07100KL | Yageo
R218 | 10k | 0402-RES | 1 | RC0402FR-0710KL | Yageo
R219 | 470 | 0402-RES | 1 | RC0402FR-07470RL | Yageo
R220 | 470 | 0402-RES | 1 | RC0402FR-07470RL | Yageo
R221 | 100k | 0402-RES | 1 | RC0402FR-07100KL | Yageo
R222 | 470 | 0402-RES | 1 | RC0402FR-07470RL | Yageo
R301 | 10k | 0402-RES | 1 | RC0402FR-0710KL | Yageo
R302 | 10k | 0402-RES | 1 | RC0402FR-0710KL | Yageo
R303 | DNP | 0402-RES | 0
R304 | DNP | 0402-RES | 0
R305 | 10k | 0402-RES | 1 | RC0402FR-0710KL | Yageo
R306 | 10k | 0402-RES | 1 | RC0402FR-0710KL | Yageo
R307 | 10k | 0402-RES | 1 | RC0402FR-0710KL | Yageo
R308 | 470 | 0402-RES | 1 | RC0402FR-07470RL | Yageo
R309 | 470 | 0402-RES | 1 | RC0402FR-07470RL | Yageo
R310 | 470 | 0402-RES | 1 | RC0402FR-07470RL | Yageo
R311 | 470 | 0402-RES | 1 | RC0402FR-07470RL | Yageo
R312 | 10k | 0402-RES | 1 | RC0402FR-0710KL | Yageo
R313 | 470 | 0402-RES | 1 | RC0402FR-07470RL | Yageo
R314 | 470 | 0402-RES | 1 | RC0402FR-07470RL | Yageo
R501 | 1k | 0402-RES | 1 | RC0402FR-071KL | Yageo
R502 | 82 | 0402-RES | 1 | RC0402FR-0782RL | Yageo
R503 | DNP | 0805 | 0
R504 | 10k | 0402-RES | 1 | RC0402FR-0710KL | Yageo
R505 | 1k | 0402-RES | 1 | RC0402FR-071KL | Yageo
R506 | 82 | 0402-RES | 1 | RC0402FR-0782RL | Yageo
R507 | DNP | 0805 | 0
R508 | 10k | 0402-RES | 1 | RC0402FR-0710KL | Yageo
R509 | 100 | 0402-RES | 1 | RC0402FR-07100RL | Yageo
R510 | DNP | 0805 | 0
R511 | 10k | 0402-RES | 1 | RC0402FR-0710KL | Yageo
R512 | 100 | 0402-RES | 1 | RC0402FR-07100RL | Yageo
R513 | DNP | 0805 | 0
R514 | 10k | 0402-RES | 1 | RC0402FR-0710KL | Yageo
R515 | 100 | 0402-RES | 1 | RC0402FR-07100RL | Yageo
R516 | DNP | 0805 | 0
R517 | 10k | 0402-RES | 1 | RC0402FR-0710KL | Yageo
R518 | DNP | 0805 | 0
R519 | 10k | 0402-RES | 1 | RC0402FR-0710KL | Yageo
R520 | 100 | 0402-RES | 1 | RC0402FR-07100RL | Yageo
R521 | 100 | 0402-RES | 1 | RC0402FR-07100RL | Yageo
R601 | 470 | 0402-RES | 1 | RC0402FR-07470RL | Yageo
R602 | 1k | 0402-RES | 1 | RC0402FR-071KL | Yageo
R603 | 10k | 0402-RES | 1 | RC0402FR-0710KL | Yageo
R604 | 10k | 0402-RES | 1 | RC0402FR-0710KL | Yageo
R605 | 10k | 0402-RES | 1 | RC0402FR-0710KL | Yageo
R606 | 1k | 0402-RES | 1 | RC0402FR-071KL | Yageo
R607 | 1k | 0402-RES | 1 | RC0402FR-071KL | Yageo
R608 | 1k | 0402-RES | 1 | RC0402FR-071KL | Yageo
R609 | 3.48k | 0402-RES | 1 | RC0402FR-073K48L | Yageo
R610 | 1k | 0402-RES | 1 | RC0402FR-071KL | Yageo
R611 | 12k | 0402-RES | 1 | RC0402FR-0712KL | Yageo
R612 | 1k | 0402-RES | 1 | RC0402FR-071KL | Yageo
R613 | 1k | 0402-RES | 1 | RC0402FR-071KL | Yageo
R614 | 1k | 0402-RES | 1 | RC0402FR-071KL | Yageo
R615 | 1k | 0402-RES | 1 | RC0402FR-071KL | Yageo
R616 | 1k | 0402-RES | 1 | RC0402FR-071KL | Yageo
R617 | 1k | 0402-RES | 1 | RC0402FR-071KL | Yageo
R618 | 1M | R2010 | 1 | RC2010FK-071ML | Yageo
R619 | 1k | 0402-RES | 1 | RC0402FR-071KL | Yageo
R702 | 47k | 0402-RES | 1 | RC0402FR-0747KL | Yageo
R703 | 100k | 0402-RES | 1 | RC0402FR-07100KL | Yageo
R704 | 6.2k | 0402-RES | 1 | RC0402FR-076K2L | Yageo
R705 | 1k | 0402-RES | 1 | RC0402FR-071KL | Yageo
R706 | 47k | 0402-RES | 1 | RC0402FR-0747KL | Yageo
R707 | 100k | 0402-RES | 1 | RC0402FR-07100KL | Yageo
R708 | 8.66k | 0402-RES | 1 | RC0402FR-078K66L | Yageo
R709 | 1k | 0402-RES | 1 | RC0402FR-071KL | Yageo
R710 | 47k | 0402-RES | 1 | RC0402FR-0747KL | Yageo
R711 | 100k | 0402-RES | 1 | RC0402FR-07100KL | Yageo
R712 | 8.66k | 0402-RES | 1 | RC0402FR-078K66L | Yageo
R713 | 1k | 0402-RES | 1 | RC0402FR-071KL | Yageo
R714 | 47k | 0402-RES | 1 | RC0402FR-0747KL | Yageo
R715 | 100k | 0402-RES | 1 | RC0402FR-07100KL | Yageo
R716 | 8.66k | 0402-RES | 1 | RC0402FR-078K66L | Yageo
R717 | 1k | 0402-RES | 1 | RC0402FR-071KL | Yageo
R718 | 47k | 0402-RES | 1 | RC0402FR-0747KL | Yageo
R719 | 15k | 0402-RES | 1 | RC0402FR-0715KL | Yageo
R720 | 6.2k | 0402-RES | 1 | RC0402FR-076K2L | Yageo
R721 | 100k | 0402-RES | 1 | RC0402FR-07100KL | Yageo
R722 | 0.01 | 1206 | 1 | LVT12R0100FER | Ohmite
R723 | 0.01 | 1206 | 1 | LVT12R0100FER | Ohmite
R724 | 10M | 0805 | 1 | RC0805FR-0710ML | Yageo
R801 | 82 | 0402-RES | 1 | RC0402FR-0782RL | Yageo
R802 | 180k | 0402-RES | 1 | RC0402FR-07180KL | Yageo
R803 | 220k | 0402-RES | 1 | RC0402FR-07220KL | Yageo
R804 | 100k | 0402-RES | 1 | RC0402FR-07100KL | Yageo
R805 | 82 | 0402-RES | 1 | RC0402FR-0782RL | Yageo
R806 | 180k | 0402-RES | 1 | RC0402FR-07180KL | Yageo
R807 | 15 | 0402-RES | 1 | RC0402FR-0715RL | Yageo
R808 | 68k | 0402-RES | 1 | RC0402FR-0768KL | Yageo
R901 | 47k | 0402-RES | 1 | RC0402FR-0747KL | Yageo
R902 | 100k | 0402-RES | 1 | RC0402FR-07100KL | Yageo
R904 | 3.48k | 0402-RES | 1 | RC0402FR-073K48L | Yageo
R905 | 100 | 0402-RES | 1 | RC0402FR-07100RL | Yageo
R906 | 1k | 0402-RES | 1 | RC0402FR-071KL | Yageo
S101 | SWITCH-MOMENTARY-2SMD-3 | TACTILE_SWITCH_SMD-3 | 1 | KMR231NGLFS | C&K Components
S201 | SWITCH-MOMENTARY-2SMD-3 | TACTILE_SWITCH_SMD-3 | 1 | KMR231NGLFS | C&K Components
S202 | SWITCH-MOMENTARY-2SMD-3 | TACTILE_SWITCH_SMD-3 | 1 | KMR231NGLFS | C&K Components
TP1001 | TESTPOINT_ROUND | TESTPAD_ROUND | 0
TP1002 | TESTPOINT_ROUND | TESTPAD_ROUND | 0
TP201 | TESTPOINT_ROUND | TESTPAD_ROUND | 0
TP202 | TESTPOINT_ROUND | TESTPAD_ROUND | 0
TP301 | TESTPOINT_ROUND | TESTPAD_ROUND | 0
TP302 | TESTPOINTPADSMALL | TESTPAD_SMALL | 0
TP501 | TESTPOINT_ROUND | TESTPAD_ROUND | 0
TP502 | TESTPOINT_ROUND | TESTPAD_ROUND | 0
TP601 | TESTPOINT_ROUND | TESTPAD_ROUND | 0
TP602 | TESTPOINT1X01 | 1X01 | 0
TP701 | TESTPOINT_ROUND | TESTPAD_ROUND | 0
TP702 | TESTPOINT_ROUND | TESTPAD_ROUND | 0
TP703 | TESTPOINT_ROUND | TESTPAD_ROUND | 0
TP704 | TESTPOINT_ROUND | TESTPAD_ROUND | 0
TP705 | TESTPOINT_ROUND | TESTPAD_ROUND | 0
TP706 | TESTPOINT_ROUND | TESTPAD_ROUND | 0
TP801 | TESTPOINT_ROUND | TESTPAD_ROUND | 0
TP802 | TESTPOINT_ROUND | TESTPAD_ROUND | 0
TP803 | TESTPOINT_ROUND | TESTPAD_ROUND | 0
TP804 | TESTPOINT_ROUND | TESTPAD_ROUND | 0
TP805 | TESTPOINT_ROUND | TESTPAD_ROUND | 0
TP806 | TESTPOINT_ROUND | TESTPAD_ROUND | 0
TP807 | TESTPOINT_ROUND | TESTPAD_ROUND | 0
TP808 | TESTPOINT_ROUND | TESTPAD_ROUND | 0
TP809 | TESTPOINT_ROUND | TESTPAD_ROUND | 0
TP810 | TESTPOINT_ROUND | TESTPAD_ROUND | 0
TP901 | TESTPOINT_ROUND | TESTPAD_ROUND | 0
TP902 | TESTPOINT_ROUND | TESTPAD_ROUND | 0
TP903 | TESTPOINTTUR | TURRET | 1 | 1573-2 | Keystone
U1001 | REF30XX | SOT23-3 | 1 | NCP51460SN33T1G | onsemi
U1002 | INA21X_DCK | SOT363 | 1 | INA214AIDCKR | Texas Instruments
U1003 | ADS7886 | SOT363 | 1 | ADS7886SDCKT | Texas Instruments
U1004 | ADP7182_WSON | WSON6 | 1 | ADP7182ACPZN-R7 | Analog Devices
U1005 | INA21X_DCK | SOT363 | 1 | INA214AIDCKR | Texas Instruments
U201 | RP2040 | QFN-56_EP | 1 | SC0914(13) | Raspberry Pi
U202 | W25Q_USON | USON8L-2X3MM | 1 | W25Q16JVUXIQ TR | Winbond
U301 | MACHXO2_FTBGA256 | LBGA-256 | 1 | LCMXO2-7000HC-6FTG256C | Lattice Semiconductor
U501 | ADS7886 | SOT363 | 1 | ADS7886SDCKT | Texas Instruments
U502 | LT1801 | SOP65P490X110-8N | 1 | LTC2051HVIMS8#PBF | Analog Devices | TSV912IYST | STMicroelectronics
U503 | ADS7886 | SOT363 | 1 | ADS7886SDCKT | Texas Instruments
U504 | REF30XX | SOT23-3 | 1 | NCP51460SN33T1G | onsemi
U505 | ADP7182_WSON | WSON6 | 1 | ADP7182ACPZN-R7 | Analog Devices
U601 | MCP1755_DFN | DFN8_2X3MM | 1 | MCP1755T-3302E/MC | Microchip
U602 | 93LC56 | SOT23-6 | 1 | 93LC56BT-I/OT | Microchip
U603 | APS6404L | USON8L-2X3MM | 1 | APS6404L-3SQR-ZR | AP Memory
U604 | FT2232H_QFP | QFP50P1200X1200X160-64N | 1 | FT2232HL-REEL | FTDI
U605 | ISO7742_DBQ | SSOP16 | 1 | ISO7742DBQ | Texas Instruments
U606 | ISO7742_DBQ | SSOP16 | 1 | ISO7742DBQ | Texas Instruments
U701 | MPM3630_FULL_CREAM | QFN-20-MPS_FULL_CREAM | 1 | MPM3630GQV-Z | Monolithic Power Systems
U702 | RPL-30 | RPL-30 | 1 | RPL-3.0-R | Recom Power
U703 | RPL-30 | RPL-30 | 1 | RPL-3.0-R | Recom Power
U704 | RPL-30 | RPL-30 | 1 | RPL-3.0-R | Recom Power
U705 | RPL-30 | RPL-30 | 1 | RPL-3.0-R | Recom Power
U801 | LTM4651 | BGA-77 | 1 | LTM4651EY#PBF | Analog Devices
U802 | LTM4651 | BGA-77 | 1 | LTM4651EY#PBF | Analog Devices
U803 | LTM4651 | BGA-77 | 1 | LTM4651EY#PBF | Analog Devices
U901 | MPM3630_FULL_CREAM | QFN-20-MPS_FULL_CREAM | 1 | MPM3630GQV-Z | Monolithic Power Systems
X201 | 403I35D12M00000 | CRYSTAL-3.2-2.5 | 1 | 403I35D12M00000 | CTS Components
X601 | 403I35D12M00000 | CRYSTAL-3.2-2.5 | 1 | 403I35D12M00000 | CTS Components
XO301 | OSCILLATOR_TXO2520 | TXO2520 | 1 | ECS-2520MV-480-CN-TR | ECS International

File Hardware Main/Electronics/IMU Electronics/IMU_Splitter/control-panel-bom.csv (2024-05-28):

Reference | Value | Datasheet | Footprint | Qty | DNP
C1 | 10uF | ~ | Capacitor_SMD:C_0805_2012Metric_Pad1.18x1.45mm_HandSolder | 1
C2 | 22uF | ~ | Capacitor_SMD:C_0805_2012Metric_Pad1.18x1.45mm_HandSolder | 1
D1,D2 | LED | ~ | LED_SMD:LED_0805_2012Metric_Pad1.15x1.40mm_HandSolder | 2
J1,J2,J3,J4,J5,J6 | 4P4C | ~ | my_RJ:A-2004-3-4-LP | 6
J7 | 3220-26-0200-00 | ~ | models:SAMTEC_SHF-113-01-L-D-RA | 1
J8 | Conn_01x04 | ~ | Connector_PinHeader_1.27mm:PinHeader_1x04_P1.27mm_Vertical | 1
J9 | Conn_01x05 | ~ | Connector_PinHeader_2.54mm:PinHeader_1x05_P2.54mm_Vertical | 1
R1 | 1.5k | ~ | Resistor_SMD:R_0805_2012Metric_Pad1.20x1.40mm_HandSolder | 1
R2 | 510 | ~ | Capacitor_SMD:C_0805_2012Metric_Pad1.18x1.45mm_HandSolder | 1
U1 | AP2114H-3.3TRG1 | https://www.diodes.com/assets/Datasheets/AZ1117.pdf | Package_TO_SOT_SMD:SOT-223-3_TabPin2 | 1

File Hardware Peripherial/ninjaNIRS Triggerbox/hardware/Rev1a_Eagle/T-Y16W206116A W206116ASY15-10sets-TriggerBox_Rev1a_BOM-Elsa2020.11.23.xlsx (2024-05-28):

 |  |  | ninjaNIRS_TriggerBox_Rev1a
Item # | *Designator | *Qty | Manufacturer | *Mfg Part # | Description / Value | *Package/Footprint | Type | Your Instructions / Notes | Unit Price 10sets | Total Price | Note
1 | R1, R16, R18, R20, R22 | 5 | Yageo | RC1206FR-07100RL | RES SMD 100 OHM 1% 1/4W 1206 | 1206 | SMD |  | $0.022 | $1.100
2 | C2, C3, C10 | 3 | Kemet | C0805C104M3RACTU | CAP CER 0.1UF 25V X7R 0805 | 0805 | SMD |  | $0.022 | $0.660
3 | R3, R4, R5, R6, R7, R8, R9, R10 | 8 | Yageo | RC1206JR-0710KL | RES SMD 10K OHM 5% 1/4W 1206 | 1206 | SMD |  | $0.022 | $1.760
4 | C1, C4, C9 | 3 | Samsung | CL32B106KOULNNE | CAP CER 10UF 16V X7R 1210 | 1206 | SMD |  | $0.141 | $4.230 | According to part number, correct package is 1210, not 1206, ok? | OK
5 | R2, R15, R17, R19, R21, R23, R24, R25, R26 | 9 | Yageo | RC1206JR-071KL | RES SMD 1K OHM 5% 1/4W 1206 | 1206 | SMD |  | $0.022 | $1.980
6 | R11, R12, R13, R14 | 4 | Stackpole | RMCF1206FT39R0 | RES 39 OHM 1% 1/4W 1206 | 1206 | SMD |  | $0.022 | $0.880
7 | C5, C6, C7, C8 | 4 | Kemet | C0805C473K3RACTU | CAP CER 0.047UF 25V X7R 0805 | 1206 | SMD |  | $0.043 | $1.720 | According to part number, correct package is 0805, not 1206, OK? | OK
8 | JP2 | 0 |  |  | Antenna |  |  | DNP |  | $0.000 | DNP
9 | JP1 | 1 | Mill-Max | 801-43-007-20-001000 | CONN RCPT 7POS 0.1 GOLD PCB R/A |  | PTH |  |  |  | Not available, out of stock. Plz recommend replacements. | Please use Sullins PPTC071LGBN-RC
10 | S2, S3, S4, S5 | 4 | E-switch | 800BWSP9SM6RE | SWITCH PUSH SPST-NO 0.4VA 20V |  | SMD |  | $6.386 | $255.440 | 7-10work days | How come it is this expensive? Price at Digikey is $4.14
11 | LED2, LED3, LED4, LED5 | 4 | Kingbright | APA1606QBC/D | LED BLUE CLEAR CHIP SMD R/A |  | SMD |  | $0.424 | $16.960 | 5-7work days
12 | LED1 | 1 | Lite-on | LTST-C191KGKT | LED GREEN CLEAR SMD | 0603 | SMD |  | $0.080 | $0.800
13 | X1 | 1 | Hirose | UX60A-MB-5ST | CONN RCPT USB2.0 MINI B SMD R/A |  | SMD |  | $1.247 | $12.470
14 | T1, T2, T3, T4, T5, T6, T7, T8 | 8 | Diodes | MMBT3906-7-F | TRANS PNP 40V 0.2A SOT23-3 | SOT 23-3 | SMD |  | $0.037 | $2.960
15 | IC1 | 1 | Texas Instruments | SN74HCS08QDRQ1 | IC LOGIC GATE | SO-14 | SMD |  | $0.507 | $5.070 | 5-7work days
16 | X2, X3, X4, X5 | 4 | TE Connectivity | 5227161-9 | CONN BNC JACK R/A 50 OHM PCB |  | PTH |  | $4.262 | $170.480 | 5-7work days | How come it is this expensive? Price at Digikey is $3.18
 |  |  |  |  |  |  |  |  |  | 476.51
Need a quick and accurante quote? Need an efficient production? Please read SMT Ordering Necessary Files & Info in 1 minute. Thank you very much!
Click for Instructions on How to Create a BOM (https://www.pcbway.com/blog/PCB_Assembly/How_to_Build_a_BOM__Bill_Of_Materials_.html)
 |  |  |  |  |  |  |  |  | we quoted according to the list of *Mfg Part #, all OK? |  |  | OK

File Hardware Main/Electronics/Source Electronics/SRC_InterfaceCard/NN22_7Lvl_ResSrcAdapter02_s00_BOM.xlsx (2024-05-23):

 | NN22_7Lvl_ResSrcAdapter02_s00_BOM
 | Initial version created 2023-03-15 |  | Bernhard Zimmermann / BU Neurophotonics Center |  |  | bzim@bu.edu
Item # | Designator | Qty | Mfg Part Number | Description | Values | Package | Type | Notes
1 | C4, C7, C8, C9 | 4 | GRM155R71H104KE14D | CAP CER 0.1UF 50V X7R 0402 | 0.1u | 0402-CAP | SMD
2 | R9 | 1 | RR1220P-122-D | RES SMD 1.2K OHM 0.5% 1/10W 0805 | 1.2k | 0805 | SMD
3 | R19, R20, R21, R22, R24, R25, R26, R27 | 8 | RT0805DRD075R1L | RES SMD 5.1 OHM 0.5% 1/8W 0805 | 5.1 | 0805 | SMD
4 | R3, R4, R5, R18, R23, R32 | 6 | RC0402FR-07100KL | RES 100K OHM 1% 1/16W 0402 | 100k | 0402-RES | SMD
5 | C1 | 1 | TCJY107M016R0050 | CAP TANT POLY 100UF 16V 2917 | 100u | 2917-CAP | SMD
6 | R28, R29, R30, R31, R33, R34, R35, R36 | 8 | RT0805DRD076R2L | RES SMD 6.2 OHM 0.5% 1/8W 0805 | 6.2 | 0805 | SMD
7 | R1 | 1 | ERA-2AED272X | RES SMD 2.7K OHM 0.5% 1/16W 0402 | 2.7k | 0402-RES | SMD
8 | C2, C3, C6, C10, C11 | 5 | CL31A226KAHNNNE | CAP CER 22UF 25V X5R 1206 | 22u | 1206 | SMD
9 | R7, R8, R15 | 3 | RR1220P-271-D | 270 Ohms ±0.5% 0.1W, 1/10W Chip Resistor 0805 (2012 Metric) Thin Film | 270 | 0805 | SMD
10 | R10, R13, R14 | 3 | RT0805DRD0739RL | RES SMD 39 OHM 0.5% 1/8W 0805 | 39 | 0805 | SMD
11 | R2 | 1 | ERA-2AEB3650X | RES SMD 365 OHM 0.1% 1/16W 0402 | 365 | 0402-RES | SMD
12 | R16, R17 | 2 | 4-1625868-4 | RES SMD 15 OHM 0.1% 1/4W 0805 | 15 | 0805 | SMD
13 | C5 | 1 | CL05C470JB5NNNC | CAP CER 47PF 50V C0G/NP0 0402 | 47p | 0402-CAP | SMD
14 | R12 | 1 | RR1220P-561-D | RES SMD 560 OHM 0.5% 1/10W 0805 | 560 | 0805 | SMD
15 | U2 | 1 | SN74HCS138PWR | IC DECODER/DEMUX 1X3:8 16TSSOP | 74HC138_TSSOP | TSSOP16 | SMD
16 | U3, U4 | 2 | SN74HCS238PWR | IC DECODER/DEMUX 1X3:8 16TSSOP | 74HC238_TSSOP | TSSOP16 | SMD
17 | R6, R11 | 2 |  |  | DNP | 0805 | DNP
18 | LF1 | 1 | BLM18KG121TN1D | FERRITE BEAD 120 OHM 0603 1LN | FERRITE0603 | 0603-FER | SMD
19 | FID1, FID2, FID3, FID4, FID5, FID6 | 6 |  |  | FIDUCIALUFIDUCIAL | MICRO-FIDUCIAL | DNP
20 | U1 | 1 | ISL80103IRAJZ-TK | IC REG LINEAR POS ADJ 3A 10DFN | ISL80103 | DFN10_ISL | SMD
21 | J2 | 1 | 3220-26-0300-00 | CONN HEADER SMD 26POS 1.27MM | M13X2_0.050_SHF | M13X2_0.050_SHF | SMD
22 | J1 | 1 | "15150402601000" | CONN HEADER SMD R/A 40POS 1.27MM | M20X2_HARFLEX_M | M20X2_HARFLEX_M | SMD
23 | Q5, Q6, Q7, Q8, Q9, Q10, Q11, Q12 | 8 | SSM6N67NU,LF | SMALL LOW RON DUAL NCH MOSFETS I | MOSFET-DUAL-N-UDFN8 | UDFN8 | SMD
24 | Q1, Q2, Q3, Q4 | 4 | SSM6P69NU,LF | SMALL SIGNAL MOSFET P-CHX2 VDSS- | MOSFET-DUAL-P-UDFN8 | UDFN8 | SMD
25 | D1, D2, D3, D4, D5, D6, D7, D8, D9, D10, D11, D12, D13, D14, D15, D16 | 16 | SBR1A20T5-7 | DIODE SBR 20V 1A SOD523 | SBR1A20T5 | SOD523 | SMD
26 | F1 | 1 | SMD0805B050TF | P PTC SMD 0805, 6V 0.5A | SMD0805B050TF | 0805 | SMD
27 | TP6 | 1 |  |  | TESTPOINT1X01 | 1X01 | DNP
28 | TP1, TP2, TP3, TP4, TP5 | 5 |  |  | TESTPOINT_ROUND | TESTPAD_ROUND | DNP

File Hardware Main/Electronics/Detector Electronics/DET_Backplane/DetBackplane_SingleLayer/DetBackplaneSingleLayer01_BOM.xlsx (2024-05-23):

 | DetBackplaneSingleLayer01
 | Initial version created 2023-05-31 |  | Bernhard Zimmermann / BU Neurophotonics Center |  |  | bzim@bu.edu
Item # | Designator | Qty | Mfg Part Number | Description | Values | Package | Type | Notes
1 | J1, J2 | 2 | ESMC-F-40-SGR-SMT-T/R | CONN RCPT R/A SMT 40POS 1.27MM |  |  | SMD
2 | TP2 | 1 |  | Test point through hole |  |  | DNP
3 | TP1, TP3, TP4 | 3 |  | Test pad |  |  | DNP

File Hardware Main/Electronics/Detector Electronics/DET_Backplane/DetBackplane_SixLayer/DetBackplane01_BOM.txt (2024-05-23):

all main conncectors are Harting 15210402401000

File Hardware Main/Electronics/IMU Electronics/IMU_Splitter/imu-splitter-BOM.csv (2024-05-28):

Reference | Value | Qty | CatNo | MfgNo
C1 | 10uF | 1 | 1276-1096-1-ND | CL21A106KOQNNNE
C2 | 22uF | 1 | 1276-6526-1-ND | CL21A226KOQNNNE
D1,D2 | LED | 2 | 350-5973006607FCT-ND | 5973006607F
J1,J2,J3,J4,J5,J6 | 4P4C | 6 | AE10381-ND | A-2004-3-4-LP-N-R
J7 | 3220-26-0200-00 | 1 | 1175-1640-ND | 3220-26-0200-00
J8 | Conn_01x04 | 1 | SAM10242-ND | TMS-104-01-G-S
J9 | Conn_01x05 | 1 | 609-3462-ND | 68000-105HLF
J10 | 3221-26-0100-00 | 1 | 1175-1745-ND | 3221-26-0100-00
N1 | 1551T | 1
R1 | 1.5k | 1 | 311-1.50KCRCT-ND | RC0805FR-071K5L
R2 | 510 | 1 | 311-510CRCT-ND | RC0805FR-07510RL
U1 | AP2114H-3.3TRG1 | 1 | AP2114H-3.3TRG1DICT-ND | AZ1117CH-3.3TRG1

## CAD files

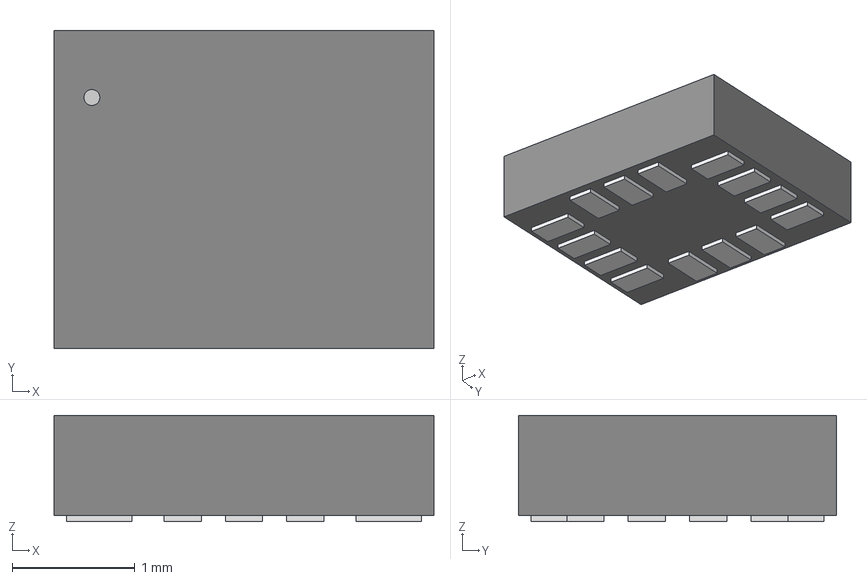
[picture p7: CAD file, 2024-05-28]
Hardware Main/Electronics/IMU Electronics/IMU_Module/models/LGA-14L_STM.step
3.10 x 2.59 x 0.866 mm

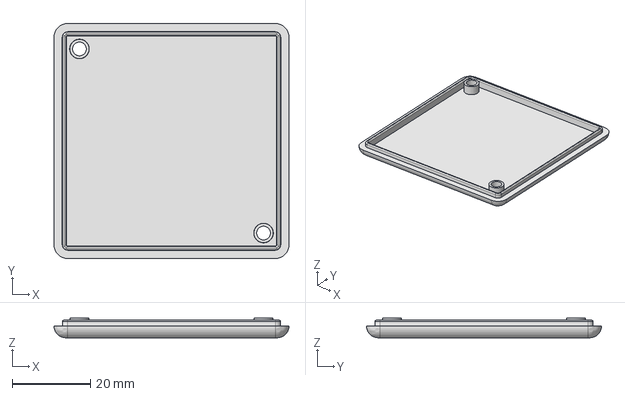
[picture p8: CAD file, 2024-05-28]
Hardware Main/Electronics/IMU Electronics/IMU_Splitter/3D/1551T_Lid_transparent.FCStd
60.0 x 60.0 x 5.00 mm

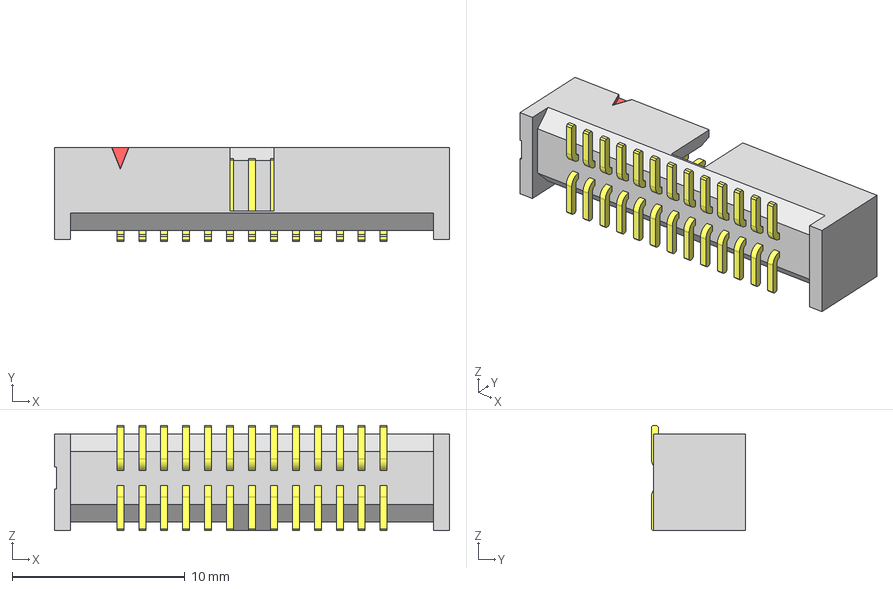
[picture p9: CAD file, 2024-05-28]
Hardware Main/Electronics/IMU Electronics/IMU_Splitter/models/SHF-113-01-L-D-SM.step
22.9 x 5.46 x 6.10 mm
T-1S71-02-13-D-SM
SHF-First_Position_Indicator
SHF-113-01-D_header

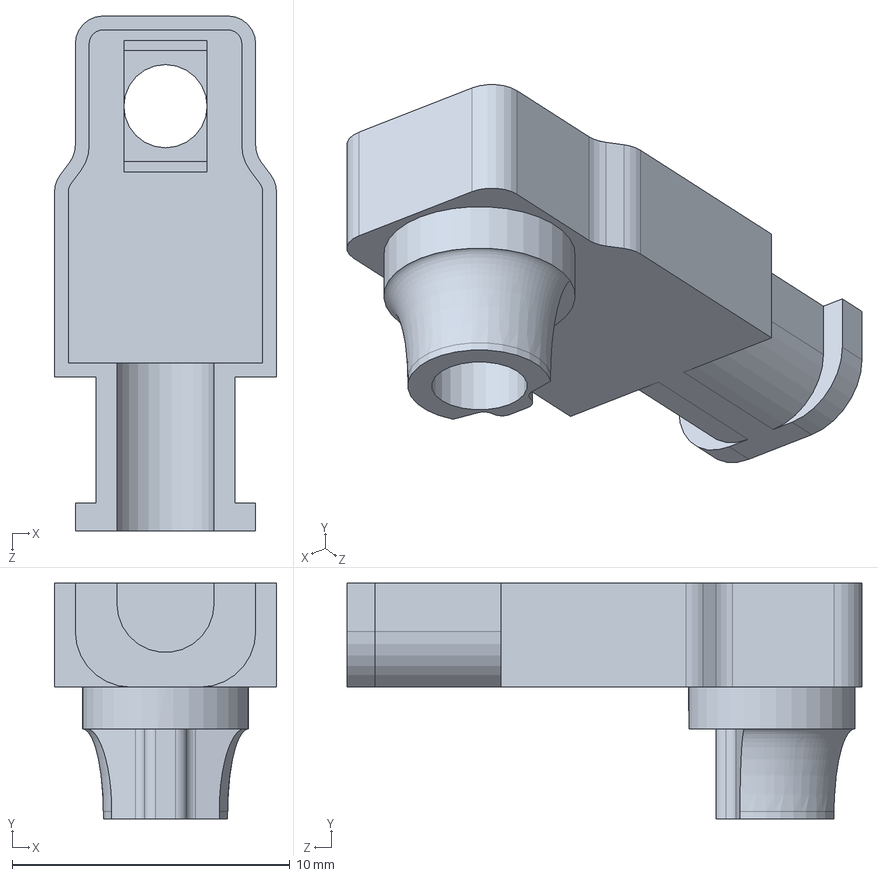
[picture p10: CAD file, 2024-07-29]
Hardware Main/Electronics/Source Electronics/SRC_Optode/Colocated Source/CAD Files/WOJ-NNEEG-EA-003-RevAD.SLDPRT
8.00 x 8.50 x 18.6 mm

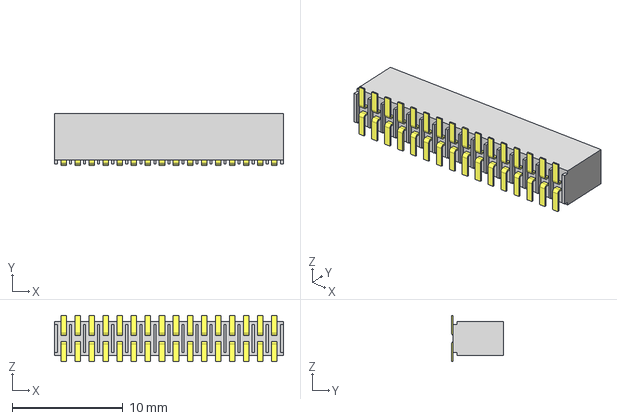
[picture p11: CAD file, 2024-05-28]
Hardware Main/Electronics/Source Electronics/SRC_Splitter/models/SFMC-116-02-S-D.step
20.7 x 4.70 x 4.19 mm
C-16-02_spins
SFMC-116-02_socket

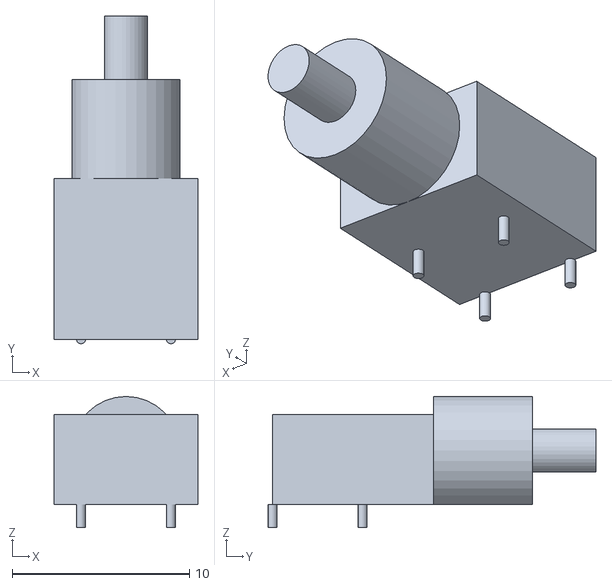
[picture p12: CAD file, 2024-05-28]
Hardware Peripherial/ninjaNIRS Triggerbox/hardware/Rev2_KiCAD/3D/sw_800.stl
8.13 x 18.5 x 7.40

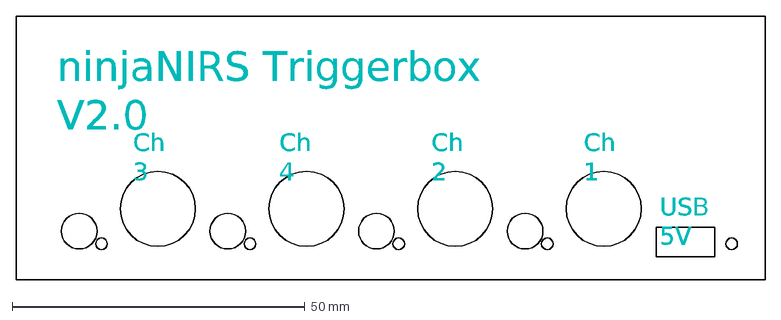
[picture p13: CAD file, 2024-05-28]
Hardware Peripherial/ninjaNIRS Triggerbox/hardware/Rev2_KiCAD/panel/panel_only.dxf
ninjaNIRS Triggerbox V2.0
Ch 1
Ch 2
Ch 4
Ch 3
USB 5V

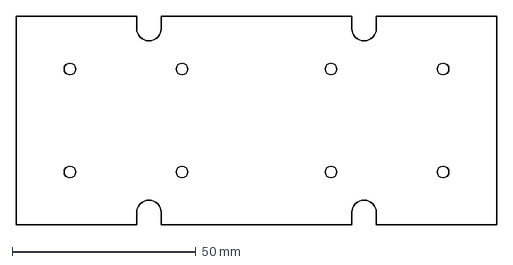
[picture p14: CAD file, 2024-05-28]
Hardware Peripherial/ninjaNIRS Triggerbox/hardware/Rev2_KiCAD/trigger-board/hammond_pcb.dxf
130.7 x 56.6 mm

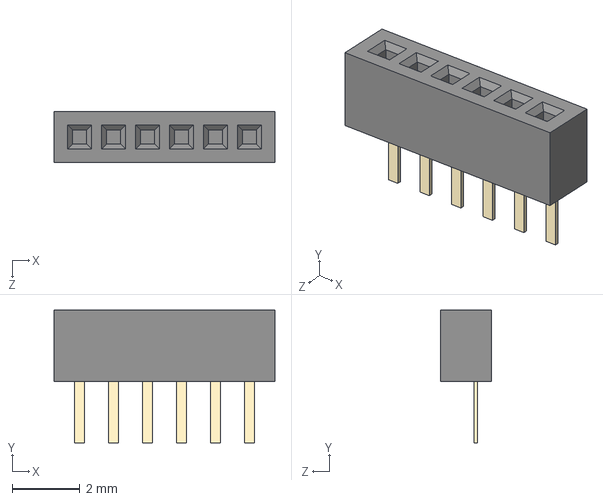
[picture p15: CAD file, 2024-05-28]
IMU-bundle/ninjanirs-imu-main/KiCAD/(Delete) imu-board/models/BC065-06-A-L-D.STEP
6.50 x 3.90 x 1.50 mm
BC065-xxx body_06
pin^BC065- xxxx Ass x 6

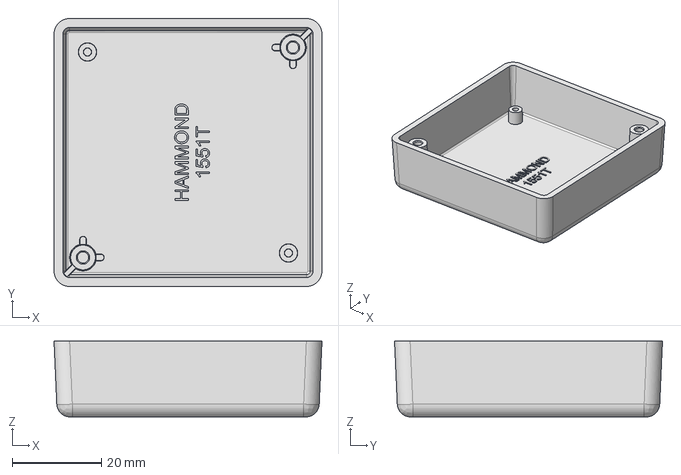
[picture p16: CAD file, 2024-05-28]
IMU-bundle/ninjanirs-imu-main/KiCAD/(Delete) imu-splitter/3D/1551T_Box.step
60.0 x 60.0 x 17.0 mm

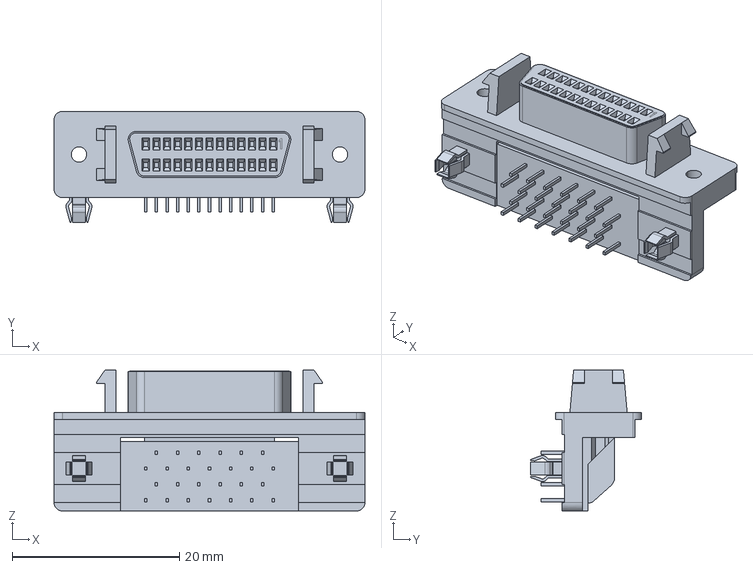
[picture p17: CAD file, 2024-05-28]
IMU-bundle/ninjanirs-imu-main/KiCAD/(Delete) imu-splitter/models/c-5787082-2-a-3d.stp
37.2 x 13.3 x 16.9 mm

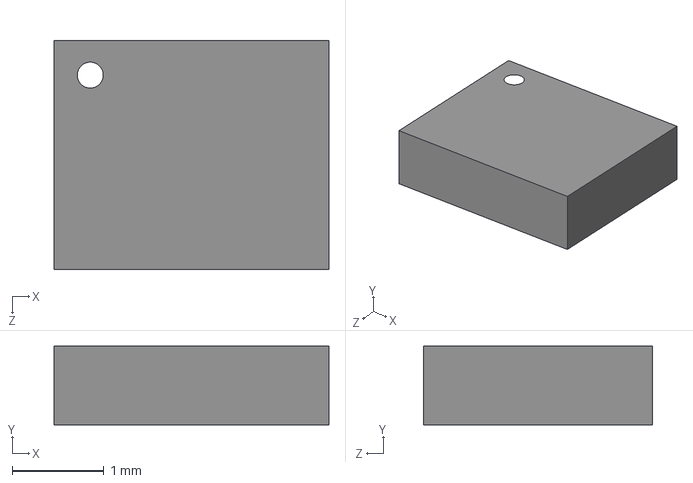
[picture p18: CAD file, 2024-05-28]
Hardware Main/Electronics/IMU Electronics/IMU_Module/models/ISM330DHCX.step
3.00 x 0.86 x 2.50 mm

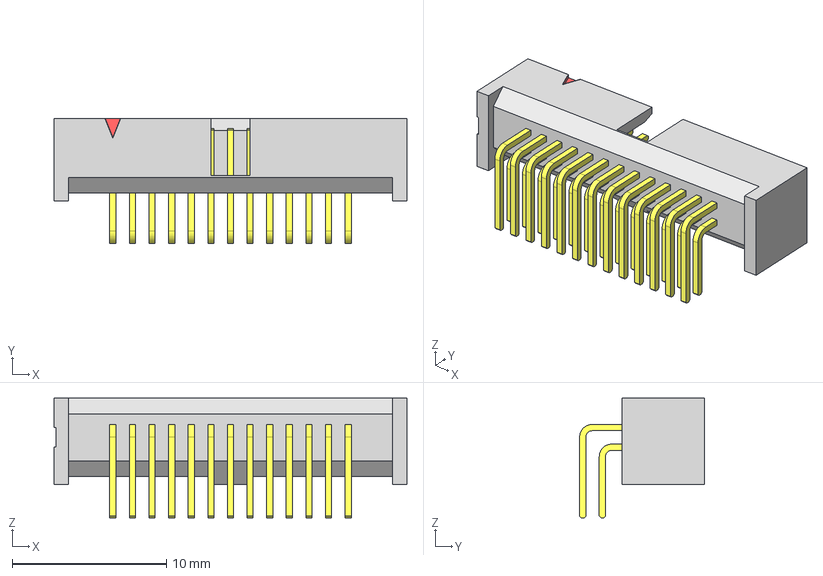
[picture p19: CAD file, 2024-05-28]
Hardware Main/Electronics/IMU Electronics/IMU_Splitter/models/SHF-113-01-L-D-RA.step
22.9 x 8.08 x 7.75 mm
T-1S71-02-13-D-RA
SHF-First_Position_Indicator
SHF-113-01-D_header

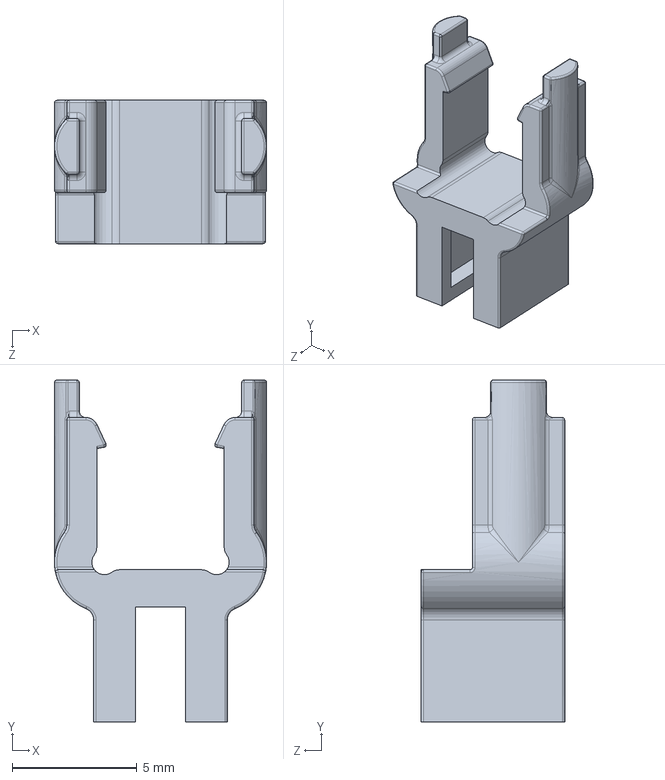
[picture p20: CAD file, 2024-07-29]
Hardware Main/Electronics/Source Electronics/SRC_Optode/Colocated Source/CAD Files/WOJ-NNEEG-EA-005-RevAE.SLDPRT
8.50 x 13.7 x 5.75 mm

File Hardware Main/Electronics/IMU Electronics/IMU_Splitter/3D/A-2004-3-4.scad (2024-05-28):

//
// Assman 4 pin RJ connector
// A-2004-3-4-LP-N
//

e = 0.1;
function mm(x)=x*25.4;
$fn=32;

pin_dia = mm(0.7);
pin_len = mm(3.25);

peg_dia = mm(2.5);
peg_len = mm(3.25);

body_wid = mm(11.2);
body_len = mm(18);
body_hgt = mm(11.7);

pin_dx = mm(1.27);
pin_dy = mm(2.54);

peg_dx = mm(7.62);

pin_x0 = (body_wid-3*pin_dx)/2;
pin_y0 = mm(14.2);

module pin_at(x,y) {
  translate( [x, y, -pin_len])
    cylinder(h=pin_len, d=pin_dia);
}

module peg_at(x,y) {
  translate( [x, y, -peg_len])
    cylinder(h=peg_len, d=peg_dia);
}

cut_wid = mm(8);
cut_hgt = mm(6);
cut_len = mm(4);

module body() {
  difference() {
    cube( [body_wid, body_len, body_hgt]);
    translate( [(body_wid-cut_wid)/2, -e, (body_hgt-cut_hgt)/2])
      cube( [cut_wid, cut_len, cut_hgt]);
  }
}


module rj() {
  body();
  peg_at( (body_wid-peg_dx)/2, mm(7.85));
  peg_at( (body_wid-peg_dx)/2+peg_dx, mm(7.85));
  pin_at( pin_x0, pin_y0);
  pin_at( pin_x0+pin_dx, pin_y0+pin_dy);
  pin_at( pin_x0+2*pin_dx, pin_y0);
  pin_at( pin_x0+3*pin_dx, pin_y0+pin_dy);
}


rj();

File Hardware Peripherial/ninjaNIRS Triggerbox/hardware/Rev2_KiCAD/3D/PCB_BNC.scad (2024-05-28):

//
// Amphenol / Adamtech PCB BNC
//

// center on signal pin

e = 0.1;
$fn = 32;

box_x = 14.75;
box_y = 14.20;
box_z = 13.11;

pin_z = 3.80;
pin_y = -2.55;
sig_d = 0.70;
gnd_d = 1.80;

thr_len = 8.8;
thr_d = 12;
cyl_len = 12;
cyl_d = 9.6;


translate( [-box_x/2, -2.02, 0]) {
     color("darkgrey")
     cube( [box_x, box_y, box_z]);
}
translate( [0, 0, -pin_z])  cylinder( d=sig_d, h=pin_z);
translate( [pin_y, 0, -pin_z])  cylinder( d=sig_d, h=pin_z);
translate( [-5.08, 5.08, -pin_z]) cylinder( d=gnd_d, h=pin_z);
translate( [ 5.08, 5.08, -pin_z]) cylinder( d=gnd_d, h=pin_z);


translate( [0, pin_y+box_y+thr_len, box_z/2])
rotate( [90, 0, 0])
cylinder( h=thr_len, d=thr_d);

translate( [0, pin_y+box_y+thr_len+cyl_len, box_z/2])
rotate( [90, 0, 0])
cylinder( h=cyl_len, d=cyl_d);

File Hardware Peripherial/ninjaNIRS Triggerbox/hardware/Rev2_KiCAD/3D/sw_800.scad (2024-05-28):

//
// E-switch 800SP9B6M6RE
//
$fn = 32;

box_x = 8.13;
box_y = 9.09;
box_z = 5.08;

pin_len = 1.3;
pin_dia = 0.51;

module pin_at(x,y) {
     translate( [x, y, -pin_len])
	  cylinder( d=pin_dia, h=pin_len);
}

module switch() {

translate( [-box_x/2, -2.54, 0])
cube( [box_x, box_y, box_z]);

translate( [0, box_y-2.54, 6.1/2] )
  rotate( [-90, 0, 0])
  cylinder( h=5.59, d=6.1);

translate( [0, box_y-2.54+5.59, 6.1/2] )
  rotate( [-90, 0, 0])
  cylinder( h=3.56, d=2.45);

pin_at(2.54,2.54);
pin_at(2.54,-2.54);
pin_at(-2.54,2.54);
pin_at(-2.54,-2.54);

}

switch();

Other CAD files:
IMU-bundle/ninjanirs-imu-main/Adapter/outline.dxf
Hardware Peripherial/ninjaNIRS Triggerbox/hardware/Rev2_KiCAD/3D/1598B Top.stp
Hardware Main/Electronics/IMU Electronics/IMU_Module/models/ATTINY10-MAHR.step
Hardware Main/Electronics/IMU Electronics/IMU_Splitter/3D/1551T.dxf
Hardware Main/Electronics/IMU Electronics/IMU_Splitter/3D/1551TGY.stp
Hardware Main/Electronics/IMU Electronics/IMU_Splitter/3D/1551T_Lid.step
Hardware Main/Electronics/IMU Electronics/IMU_Splitter/3D/1551T_Lid_trans.step
Hardware Main/Electronics/IMU Electronics/IMU_Splitter/3D/A-2004-3-4-Group.step
Hardware Main/Electronics/Source Electronics/SRC_Optode/Colocated Source/CAD Files/WOJ-NNEEG-EA-003-RevAD.STL
Hardware Main/Electronics/Source Electronics/SRC_Optode/Colocated Source/CAD Files/WOJ-NNEEG-EA-005-RevAE.STL
Hardware Peripherial/ninjaNIRS Triggerbox/hardware/Rev2_KiCAD/3D/1598B Bottom.igs
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

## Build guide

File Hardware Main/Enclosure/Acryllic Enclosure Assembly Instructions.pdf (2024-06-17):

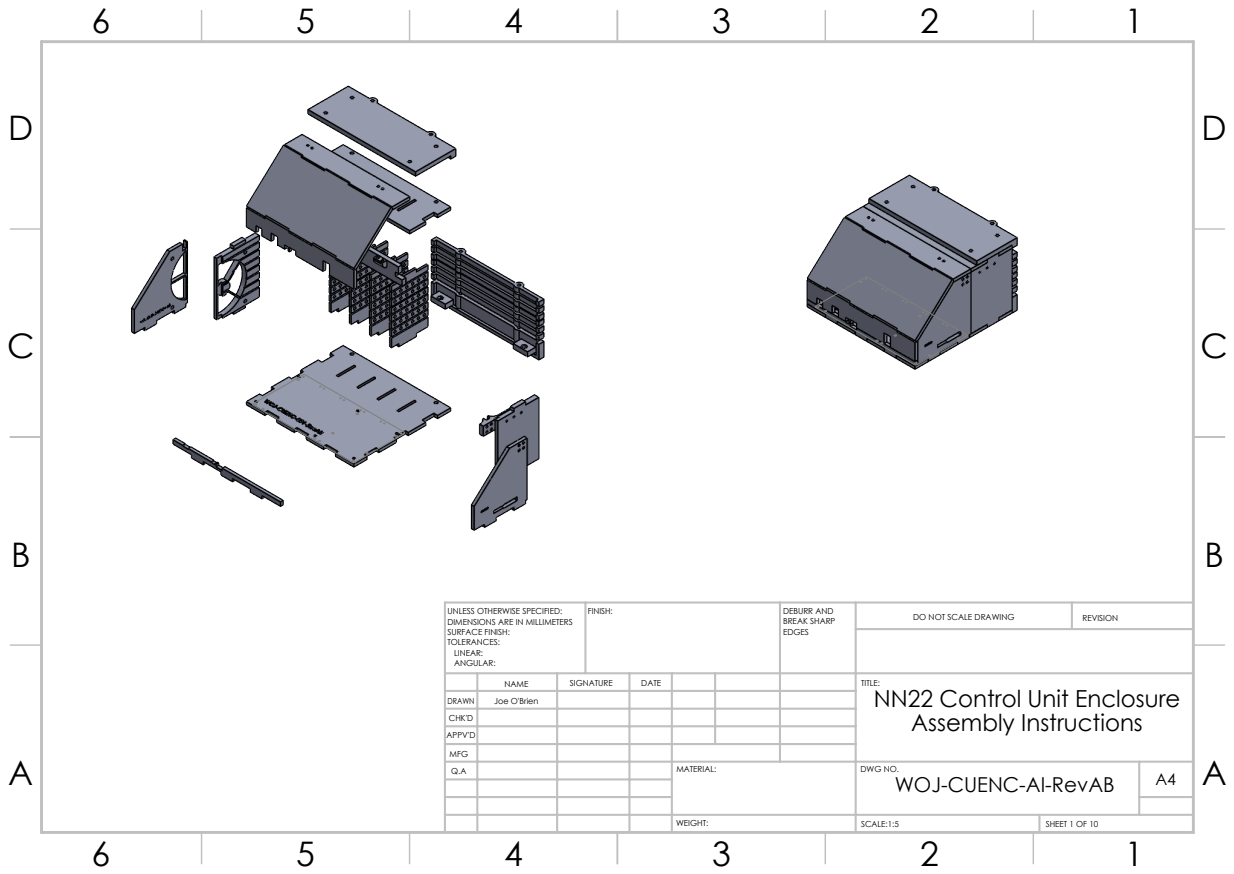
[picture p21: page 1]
FINISH:; DEBURR AND; BREAK SHARP; DO NOT SCALE DRAWING; REVISION; SCALE:1:5; SHEET 1 OF 10

UNLESS OTHERWISE SPECIFIED:
DIMENSIONS ARE IN MILLIMETERS
SURFACE FINISH:
TOLERANCES:
LINEAR:
ANGULAR:

NAME | SIGNATURE | DATE | | | | TITLE: NN22 Control Unit Enclosure Assembly Instructions

DRAWN | Joe O'Brien
CHK'D
APPV'D
MFG
Q.A | | | | MATERIAL: | DWG NO. WOJ-CUENC-AI-RevAB | A4

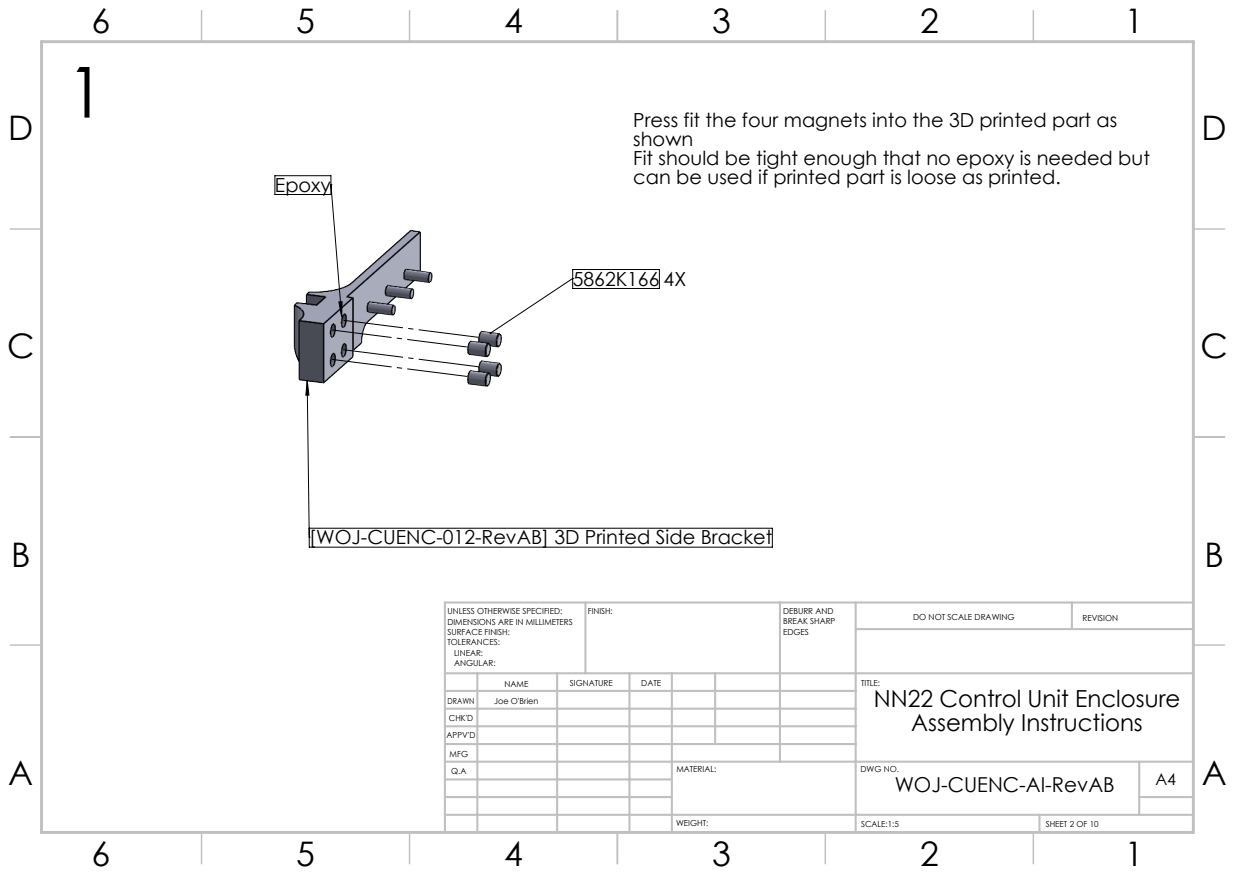
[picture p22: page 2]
FINISH:; DEBURR AND; BREAK SHARP; DO NOT SCALE DRAWING; REVISION

Press fit the four magnets into the 3D printed part as
shown
Fit should be tight enough that no epoxy is needed but
can be used if printed part is loose as printed.

[WOJ-CUENC-012-RevAB] 3D Printed Side Bracket

UNLESS OTHERWISE SPECIFIED:
DIMENSIONS ARE IN MILLIMETERS
SURFACE FINISH:
TOLERANCES:
LINEAR:
ANGULAR:

NAME | SIGNATURE | DATE | | | | TITLE: NN22 Control Unit Enclosure Assembly Instructions

DRAWN | Joe O'Brien
CHK'D
APPV'D
MFG
Q.A | | | | MATERIAL: | DWG NO. WOJ-CUENC-AI-RevAB | A4

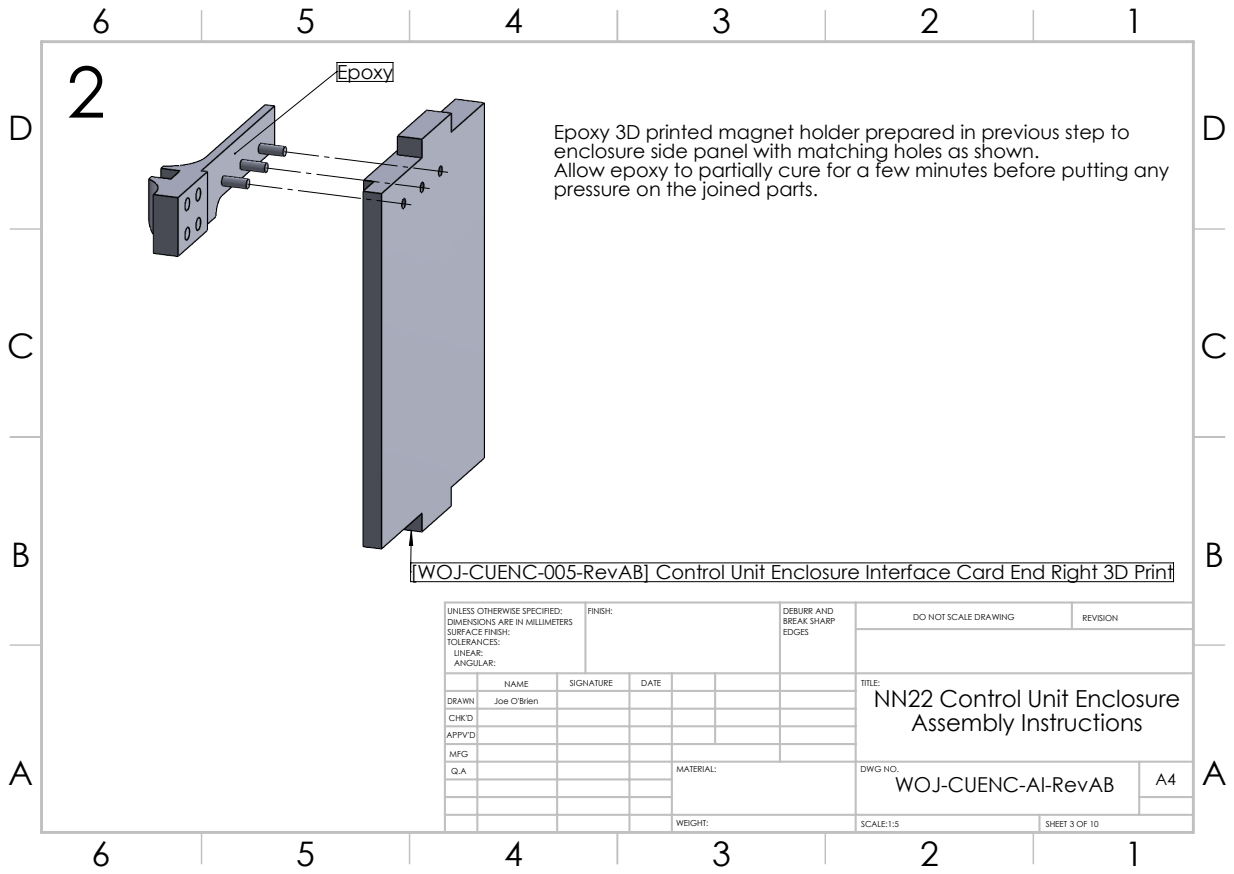
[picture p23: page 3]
FINISH:; DEBURR AND; BREAK SHARP; DO NOT SCALE DRAWING; REVISION

Epoxy 3D printed magnet holder prepared in previous step to
enclosure side panel with matching holes as shown.
Allow epoxy to partially cure for a few minutes before putting any
pressure on the joined parts.

[WOJ-CUENC-005-RevAB] Control Unit Enclosure Interface Card End Right 3D Print

UNLESS OTHERWISE SPECIFIED:
DIMENSIONS ARE IN MILLIMETERS
SURFACE FINISH:
TOLERANCES:
LINEAR:
ANGULAR:

NAME | SIGNATURE | DATE | | | | TITLE: NN22 Control Unit Enclosure Assembly Instructions

DRAWN | Joe O'Brien
CHK'D
APPV'D
MFG
Q.A | | | | MATERIAL: | DWG NO. WOJ-CUENC-AI-RevAB | A4

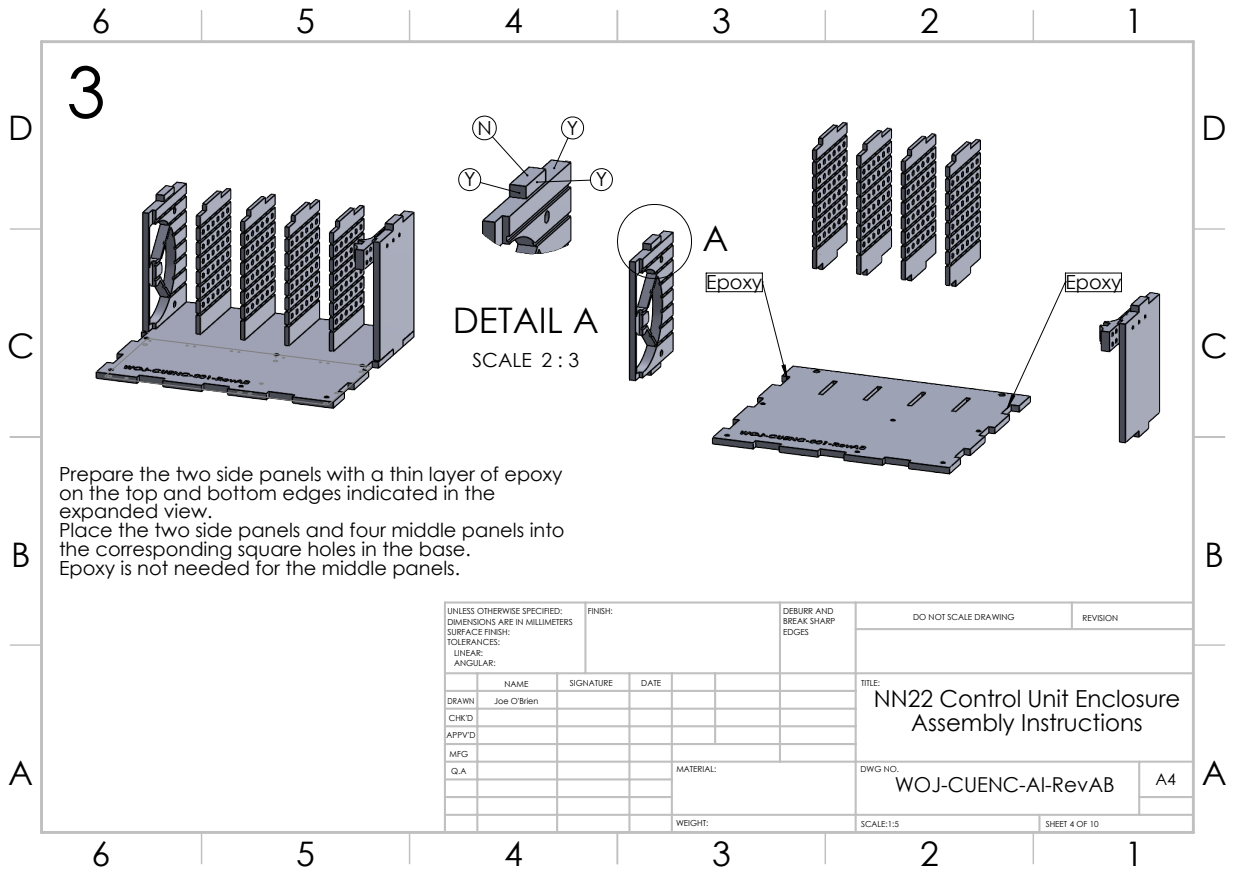
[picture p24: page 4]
DETAIL A; SCALE 2 : 3; FINISH:; DEBURR AND; BREAK SHARP; DO NOT SCALE DRAWING; REVISION

Prepare the two side panels with a thin layer of epoxy
on the top and bottom edges indicated in the
expanded view.
Place the two side panels and four middle panels into
the corresponding square holes in the base.
Epoxy is not needed for the middle panels.

UNLESS OTHERWISE SPECIFIED:
DIMENSIONS ARE IN MILLIMETERS
SURFACE FINISH:
TOLERANCES:
LINEAR:
ANGULAR:

NAME | SIGNATURE | DATE | | | | TITLE: NN22 Control Unit Enclosure Assembly Instructions

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

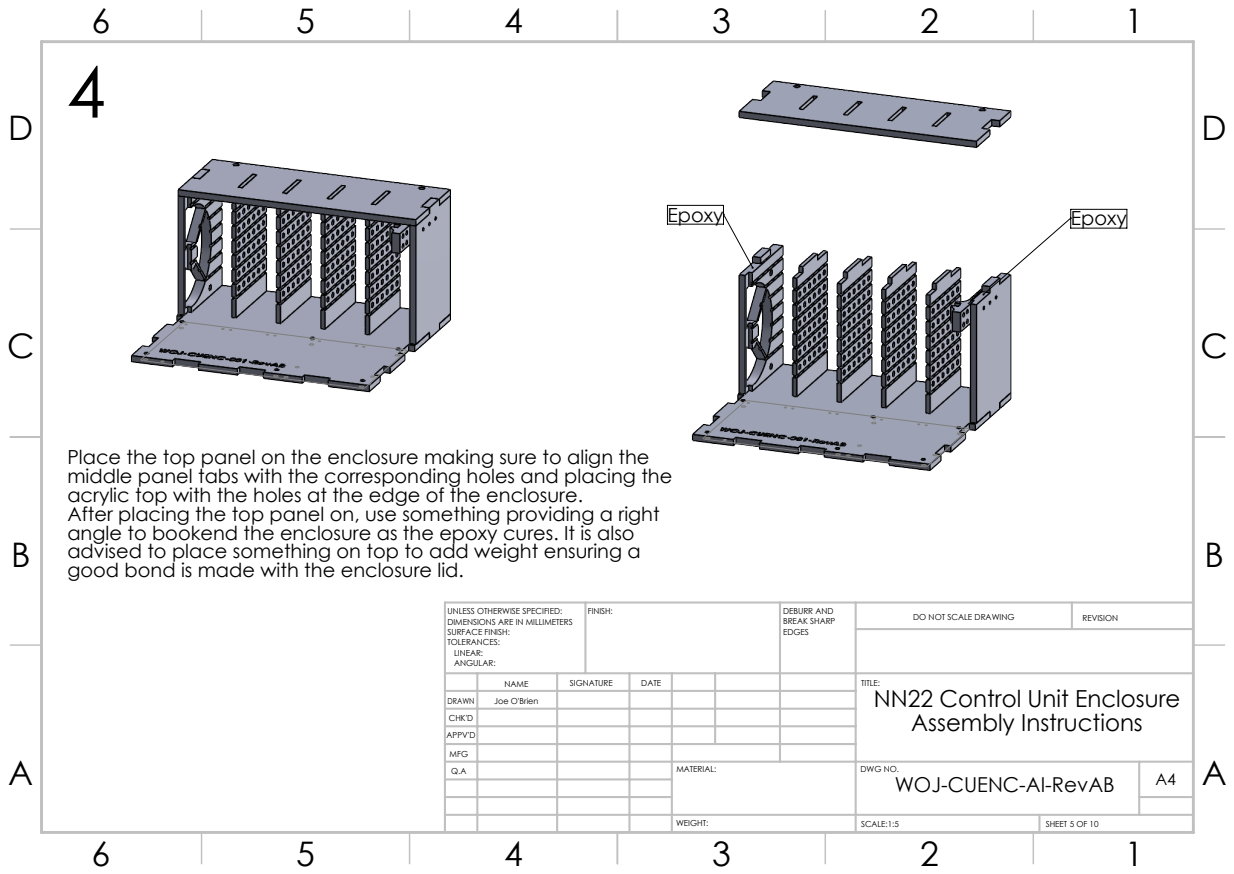
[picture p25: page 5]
FINISH:; DEBURR AND; BREAK SHARP; DO NOT SCALE DRAWING; REVISION

Place the top panel on the enclosure making sure to align the
middle panel tabs with the corresponding holes and placing the
acrylic top with the holes at the edge of the enclosure.
After placing the top panel on, use something providing a right
angle to bookend the enclosure as the epoxy cures. It is also
advised to place something on top to add weight ensuring a
good bond is made with the enclosure lid.

UNLESS OTHERWISE SPECIFIED:
DIMENSIONS ARE IN MILLIMETERS
SURFACE FINISH:
TOLERANCES:
LINEAR:
ANGULAR:

NAME | SIGNATURE | DATE | | | | TITLE: NN22 Control Unit Enclosure Assembly Instructions

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

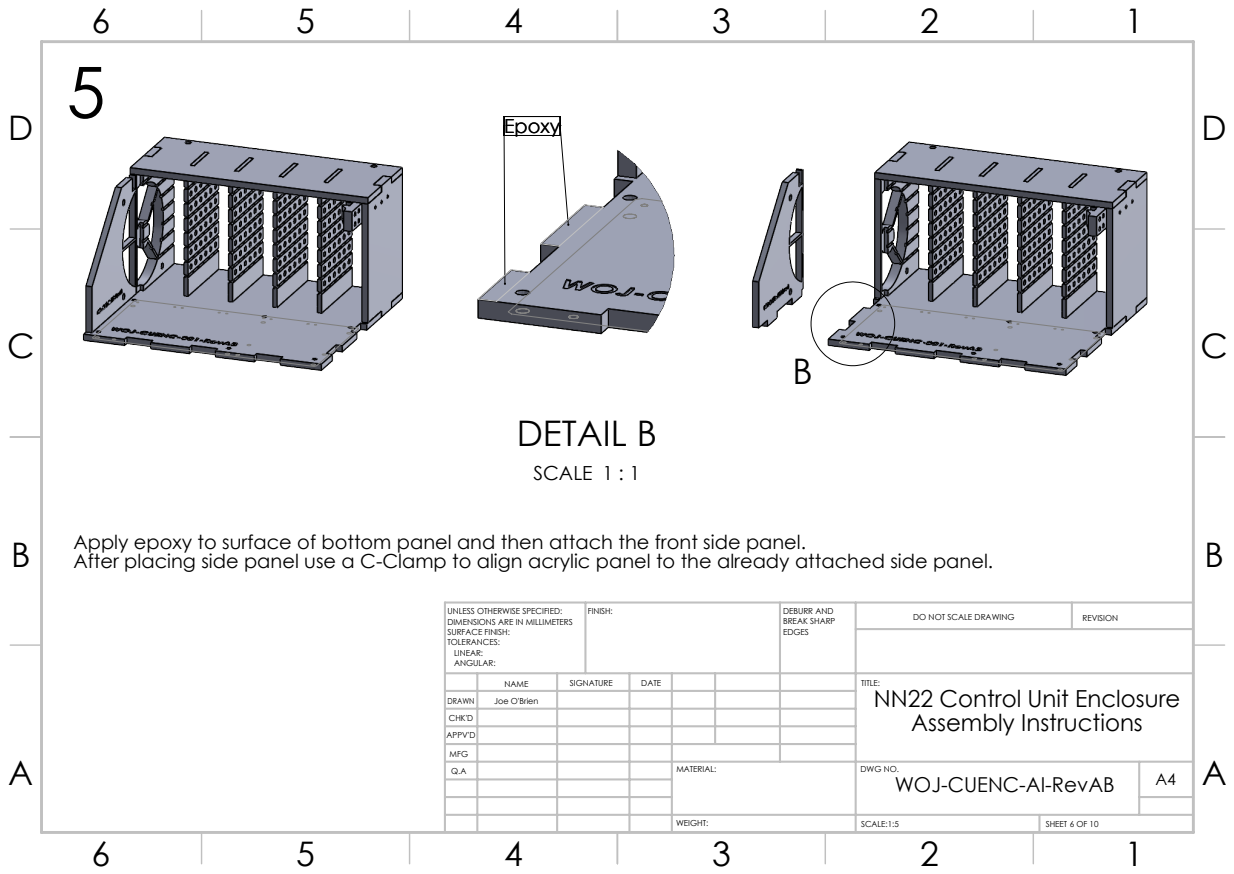
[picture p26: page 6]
DETAIL B; SCALE 1 : 1; FINISH:; DEBURR AND; BREAK SHARP; DO NOT SCALE DRAWING; REVISION

Apply epoxy to surface of bottom panel and then attach the front side panel.
After placing side panel use a C-Clamp to align acrylic panel to the already attached side panel.

UNLESS OTHERWISE SPECIFIED:
DIMENSIONS ARE IN MILLIMETERS
SURFACE FINISH:
TOLERANCES:
LINEAR:
ANGULAR:

NAME | SIGNATURE | DATE | | | | TITLE: NN22 Control Unit Enclosure Assembly Instructions

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

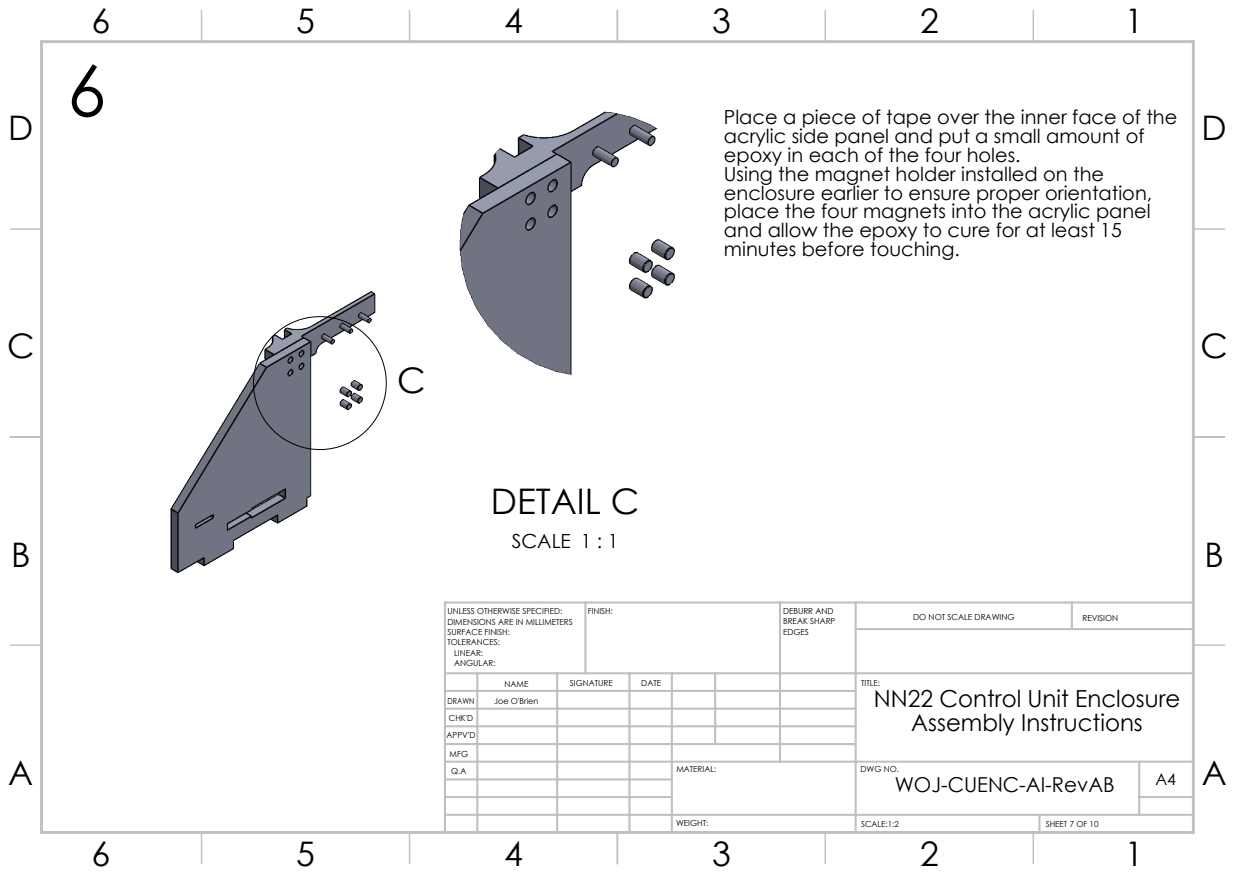
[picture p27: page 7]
DETAIL C; SCALE 1 : 1; FINISH:; DEBURR AND; BREAK SHARP; DO NOT SCALE DRAWING; REVISION; SCALE:1:2; SHEET 7 OF 10

Place a piece of tape over the inner face of the
acrylic side panel and put a small amount of
epoxy in each of the four holes.
Using the magnet holder installed on the
enclosure earlier to ensure proper orientation,
place the four magnets into the acrylic panel
and allow the epoxy to cure for at least 15
minutes before touching.

UNLESS OTHERWISE SPECIFIED:
DIMENSIONS ARE IN MILLIMETERS
SURFACE FINISH:
TOLERANCES:
LINEAR:
ANGULAR:

NAME | SIGNATURE | DATE | | | | TITLE: NN22 Control Unit Enclosure Assembly Instructions

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

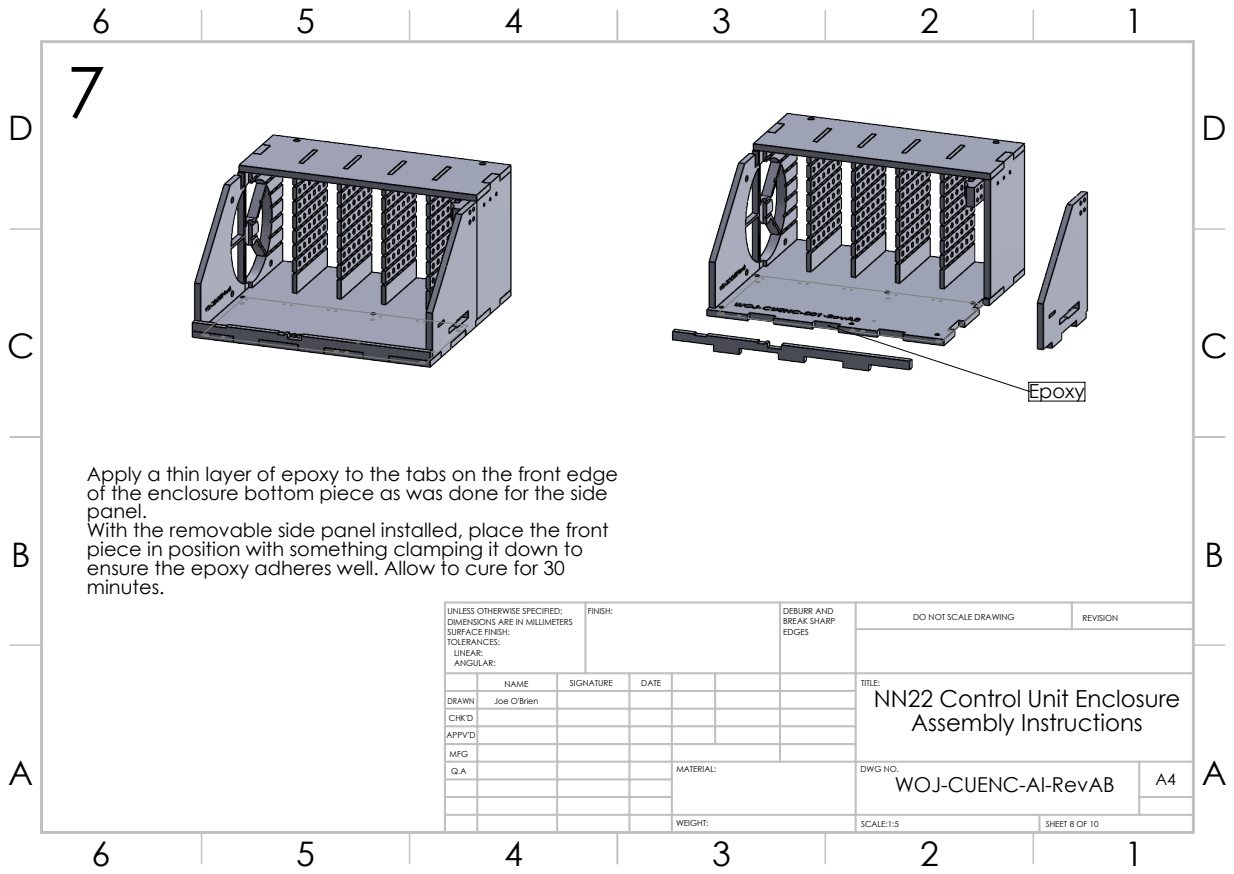
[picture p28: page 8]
FINISH:; DEBURR AND; BREAK SHARP; DO NOT SCALE DRAWING; REVISION

Apply a thin layer of epoxy to the tabs on the front edge
of the enclosure bottom piece as was done for the side
panel.
With the removable side panel installed, place the front
piece in position with something clamping it down to
ensure the epoxy adheres well. Allow to cure for 30
minutes.

UNLESS OTHERWISE SPECIFIED:
DIMENSIONS ARE IN MILLIMETERS
SURFACE FINISH:
TOLERANCES:
LINEAR:
ANGULAR:

NAME | SIGNATURE | DATE | | | | TITLE: NN22 Control Unit Enclosure Assembly Instructions

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

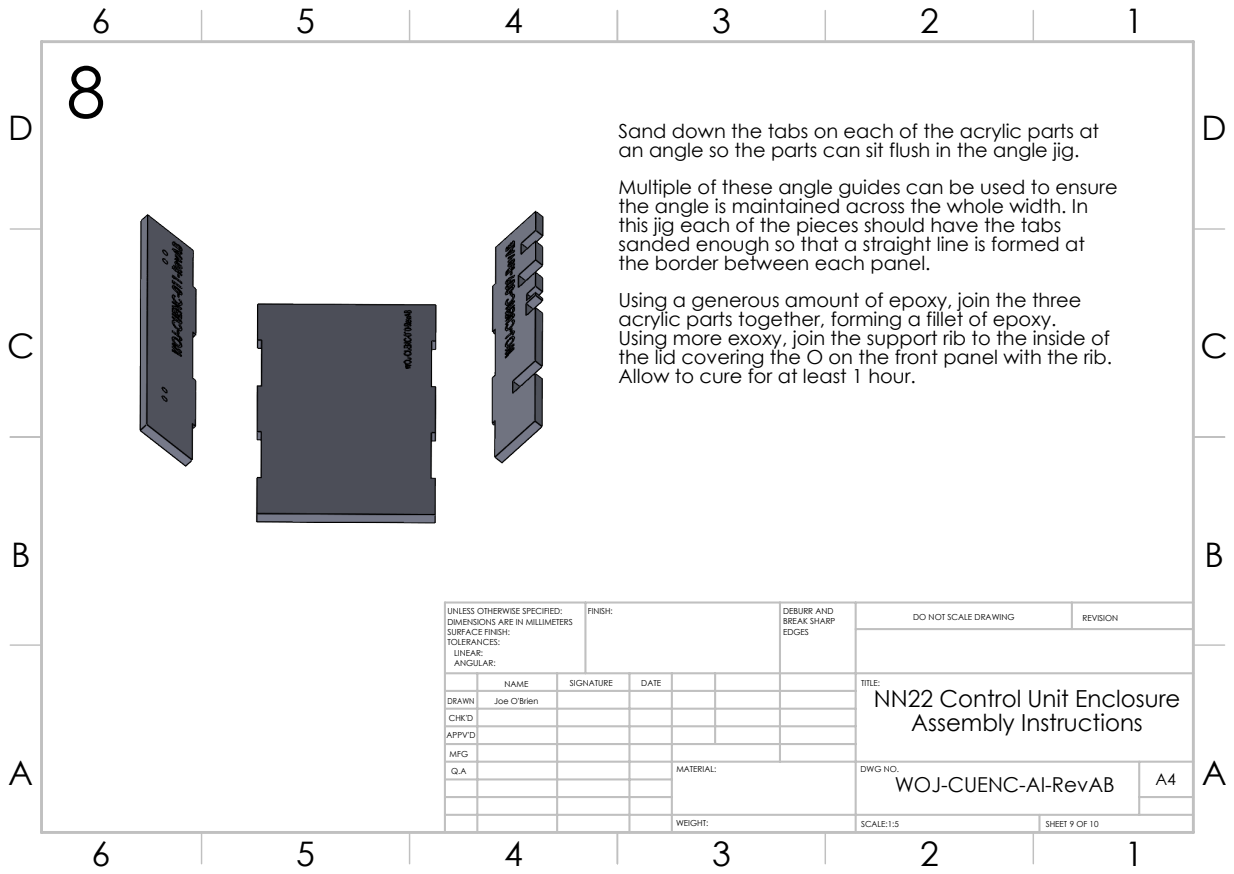
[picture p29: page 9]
FINISH:; DEBURR AND; BREAK SHARP; DO NOT SCALE DRAWING; REVISION

Sand down the tabs on each of the acrylic parts at
an angle so the parts can sit flush in the angle jig.
Multiple of these angle guides can be used to ensure
the angle is maintained across the whole width. In
this jig each of the pieces should have the tabs
sanded enough so that a straight line is formed at
the border between each panel.
Using a generous amount of epoxy, join the three
acrylic parts together, forming a fillet of epoxy.
Using more exoxy, join the support rib to the inside of
the lid covering the O on the front panel with the rib.
Allow to cure for at least 1 hour.

UNLESS OTHERWISE SPECIFIED:
DIMENSIONS ARE IN MILLIMETERS
SURFACE FINISH:
TOLERANCES:
LINEAR:
ANGULAR:

NAME | SIGNATURE | DATE | | | | TITLE: NN22 Control Unit Enclosure Assembly Instructions

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

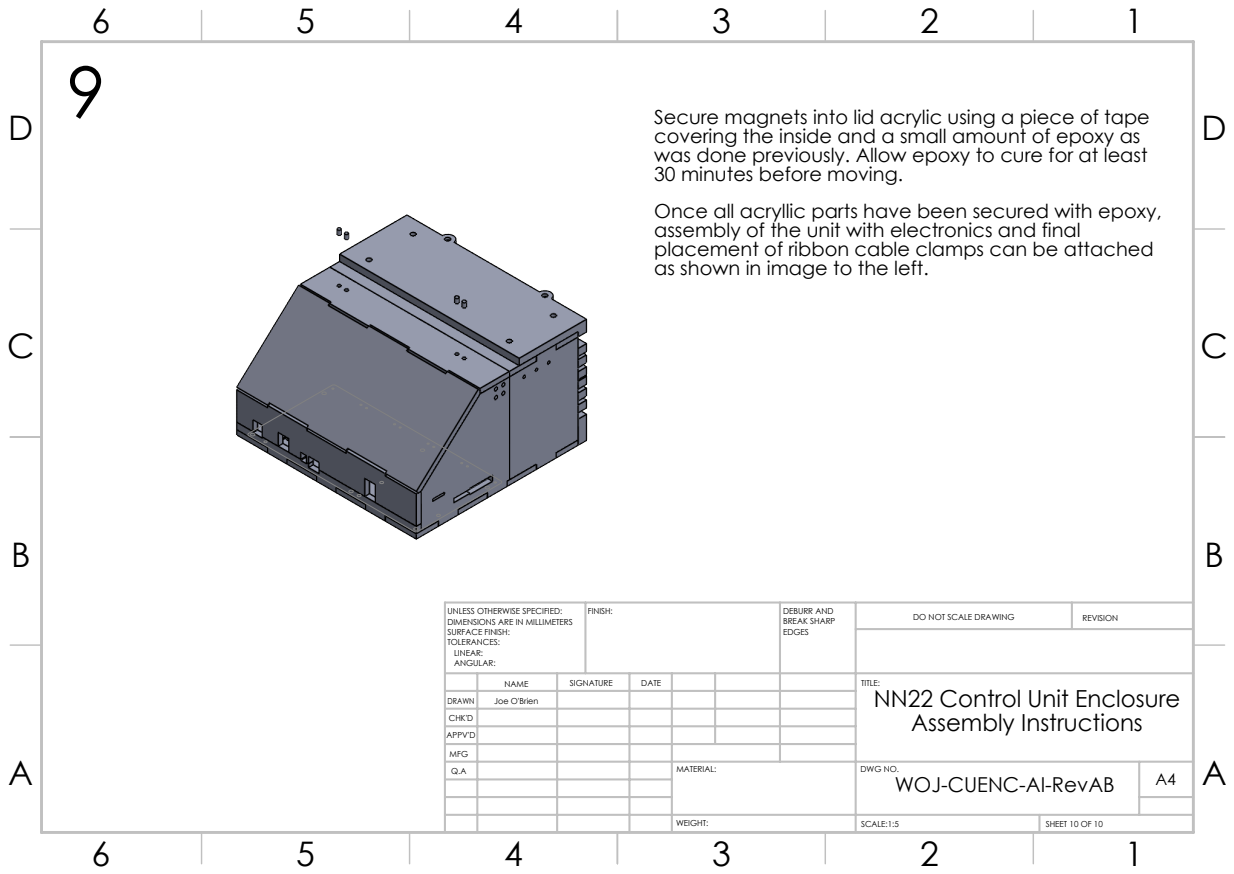
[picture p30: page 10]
FINISH:; DEBURR AND; BREAK SHARP; DO NOT SCALE DRAWING; REVISION

Secure magnets into lid acrylic using a piece of tape
covering the inside and a small amount of epoxy as
was done previously. Allow epoxy to cure for at least
30 minutes before moving.
Once all acryllic parts have been secured with epoxy,
assembly of the unit with electronics and final
placement of ribbon cable clamps can be attached
as shown in image to the left.

UNLESS OTHERWISE SPECIFIED:
DIMENSIONS ARE IN MILLIMETERS
SURFACE FINISH:
TOLERANCES:
LINEAR:
ANGULAR:

NAME | SIGNATURE | DATE | | | | TITLE: NN22 Control Unit Enclosure Assembly Instructions

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

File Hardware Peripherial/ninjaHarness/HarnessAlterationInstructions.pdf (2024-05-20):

Sewing machine settings
I used a Singer 4423 Heavy Duty Sewing Machine to sew the straps onto the harnesses. I recommend using heavy-duty needles (size 110/18), especially when you want to sew the buckle straps.
Stitch: I used double straight stretch stitches (= = = =) for everything. At the time I’m writing this, I haven’t heard of any of the stitches on the harnesses fraying.
Width: 0
Length: 1.5 - 2
Tension: Might vary with the machine, but I usually set mine as high as possible; otherwise, the thread will bird nest under the fabric.
Color: I used black thread because it matches the harness and Velcro straps.
Other materials: For cutting seams, I’d recommend using a small pair of scissors with a microtop (example: https://www.amazon.com/Westcott-Straight-Titanium-Bonded-Scissors/dp/B072RV8SC7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). (https://www.amazon.com/Westcott-Straight-Titanium-Bonded-Scissors/dp/B072RV8SC7) It requires less effort than the seam rippers that come with every sewing kit.

### 1. Cutting out the baby holder

Use scissors to snip out the baby-holding part of the harness. Make sure you don’t cut the parts of the harness behind it.

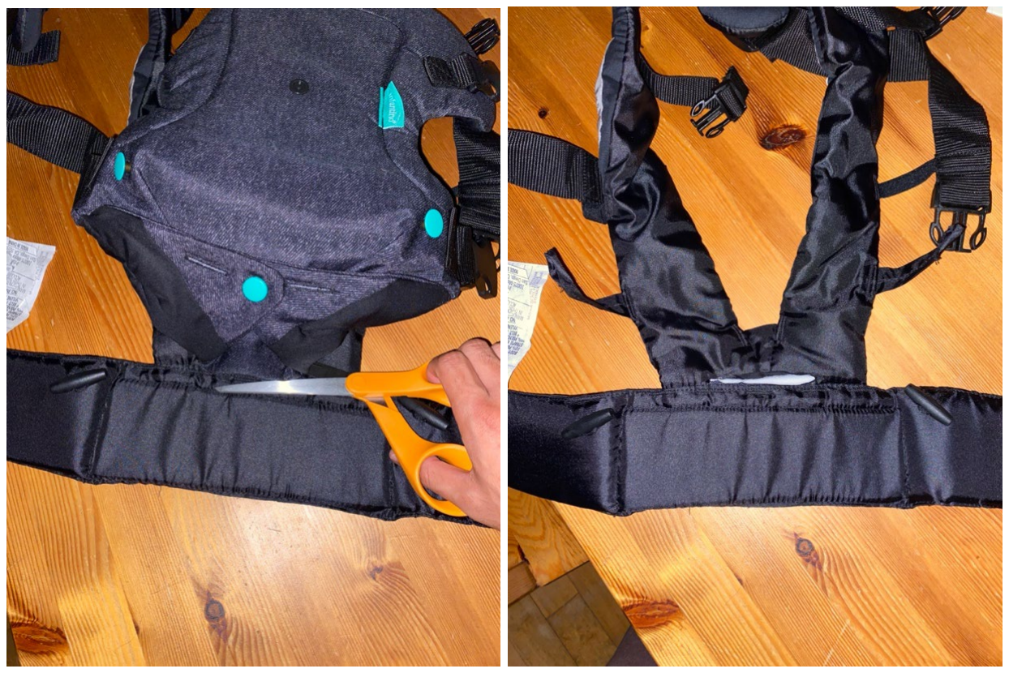
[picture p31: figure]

### 2. Removing the buckle straps

We’re going to remove the buckle straps on the front of the harness by cutting the seams and not the straps. We’ll later re-sew them to the other side of the pads (the side that touches the wearer), going sideways instead of up and down.

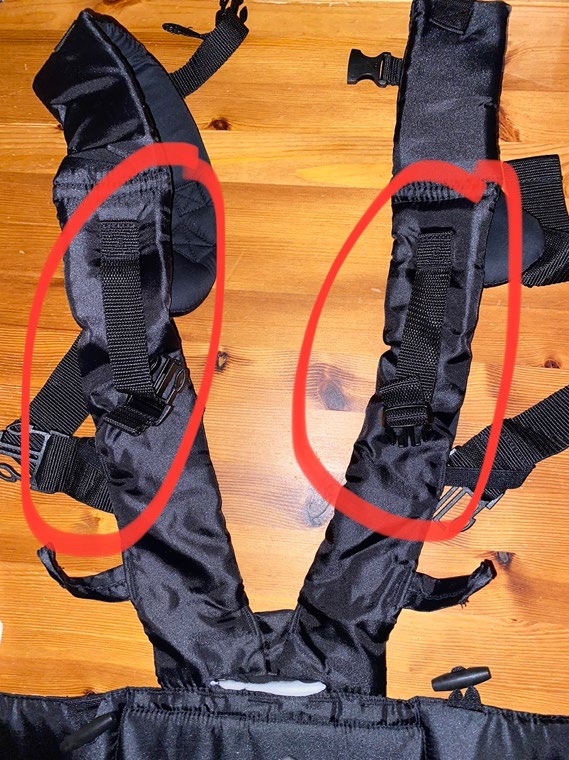
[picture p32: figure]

For this part, you can use a seam ripper or small fabric scissors. The best place to start is the zigzag seam on the other side, as your seam ripper/scissors can easily cut through the middle of the seam. Once that’s done, the seams on the other side are easier to expose. Cut through the seams (and maybe flip back and forth between sides) to fully remove the straps.

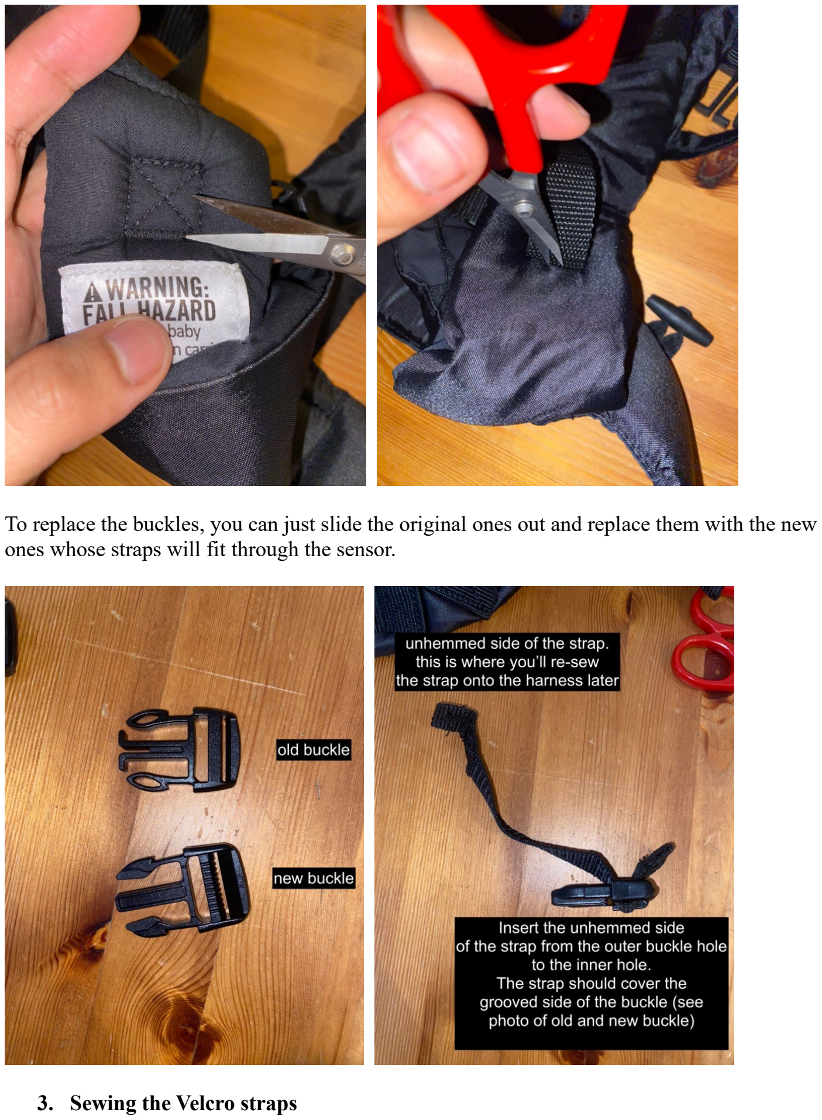
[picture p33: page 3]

To replace the buckles, you can just slide the original ones out and replace them with the new ones whose straps will fit through the sensor.

### 3. Sewing the Velcro straps

For this part, I’d recommend either having someone wear the harness to measure the required strap length. If you don’t have a willing model, you can also lay the harness flat on a table and take the measurements that way. The straps should be a little bit long to give some slack when someone wears the harness.
I start with the bottom-most strap, which will be above the horizontal pad/strap of the harness itself. I like to align the middle of the Velcro strap with the fabric hoops (circled in red) on the harness, and here, the strap is about 6.75” long:

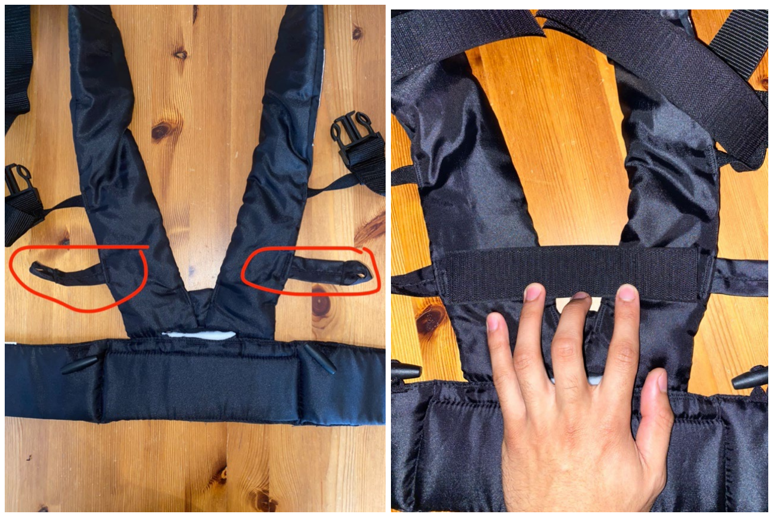
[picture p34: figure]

Tip on sewing the Velcro straps :
- For the first side of the strap (doesn’t matter which), your starting position will be on the inner edge of the harness, since the “forward” direction of the sewing machine will move the garment/harness away from you.
- I like to have very little clearance between the seam and the edge of the strap (left photo).
- Usually, about an inch into the seam, I do a reverse stitch so that this part of the seam, which will see the most tension when the harness is used, is extra secure.
- I then sew once over the strap, ending at the opposite side of where I started the seam. I don’t usually sew back to where I started (right photo), but it’s up to you. Regardless, when you end your seam, you should do a forward-reverse-forward like you did at the start.

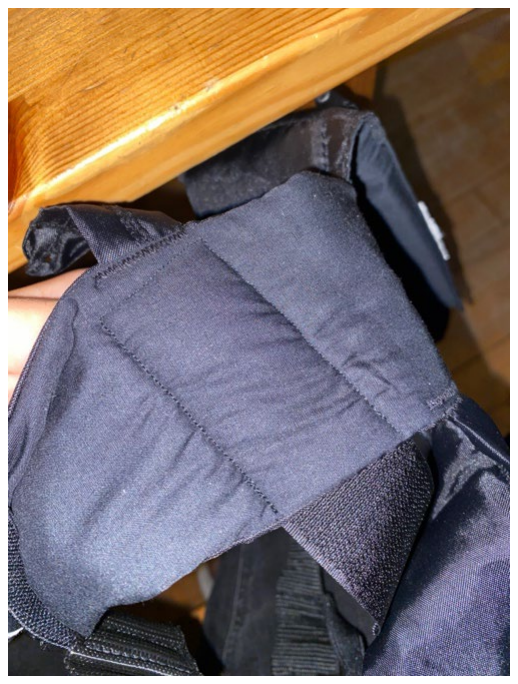
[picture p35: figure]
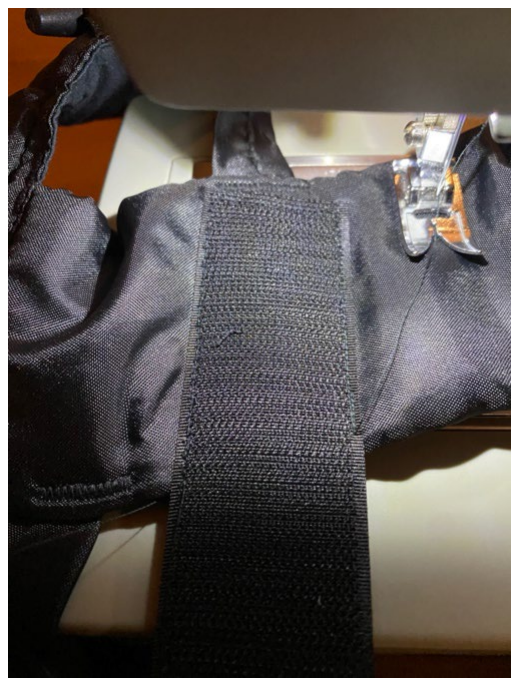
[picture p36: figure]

Sewing very close to the edge See how I don’t completely finish the seam
Repeat the process for the other side of the Velcro strap.
Second strap: The next strap is aligned with the thin middle straps on the harness and measures about 8” in this example:

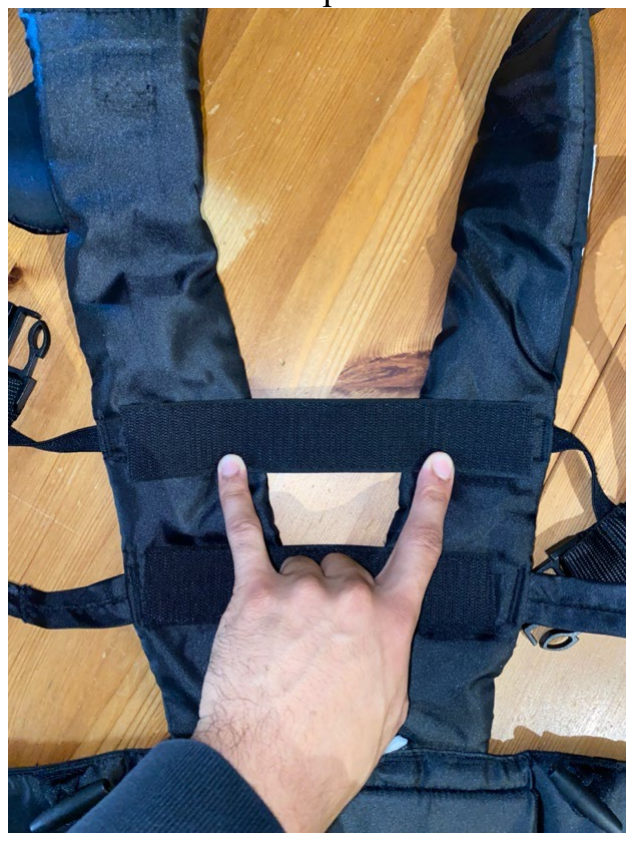
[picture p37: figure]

Repeat the same things you did for the first strap.
Re-sewing the buckle straps (probably the trickiest part of the whole process):

You will re-sew the free end of the buckle strap onto the back side of the harness (the one with the white Warning label), as close to the outer edge of the harness as you like. The two photos below show where I like to sew them:

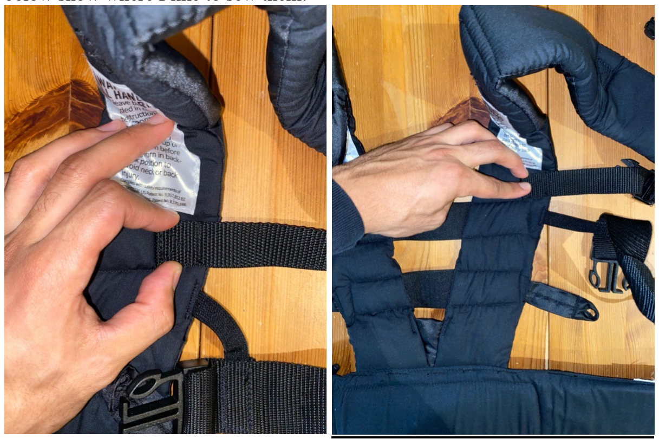
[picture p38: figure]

For both straps, I also like to keep the folded part tucked inside the seam.
The next two photos show 1) the starting point for the seam and 2) the entire path for the seam. I like to make the same X shape along the folded part of the strap, and then double over on the left and right sides for extra security.

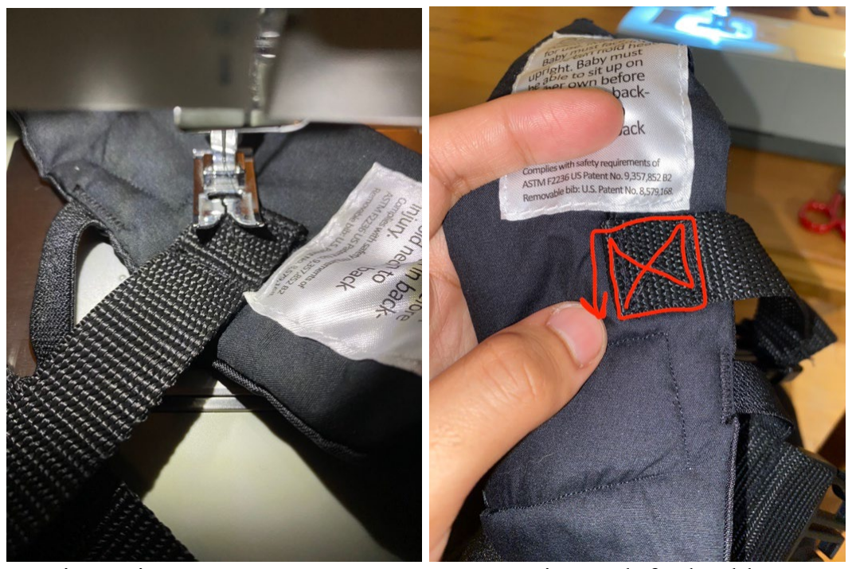
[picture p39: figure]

Starting point | Sewing path for buckle straps

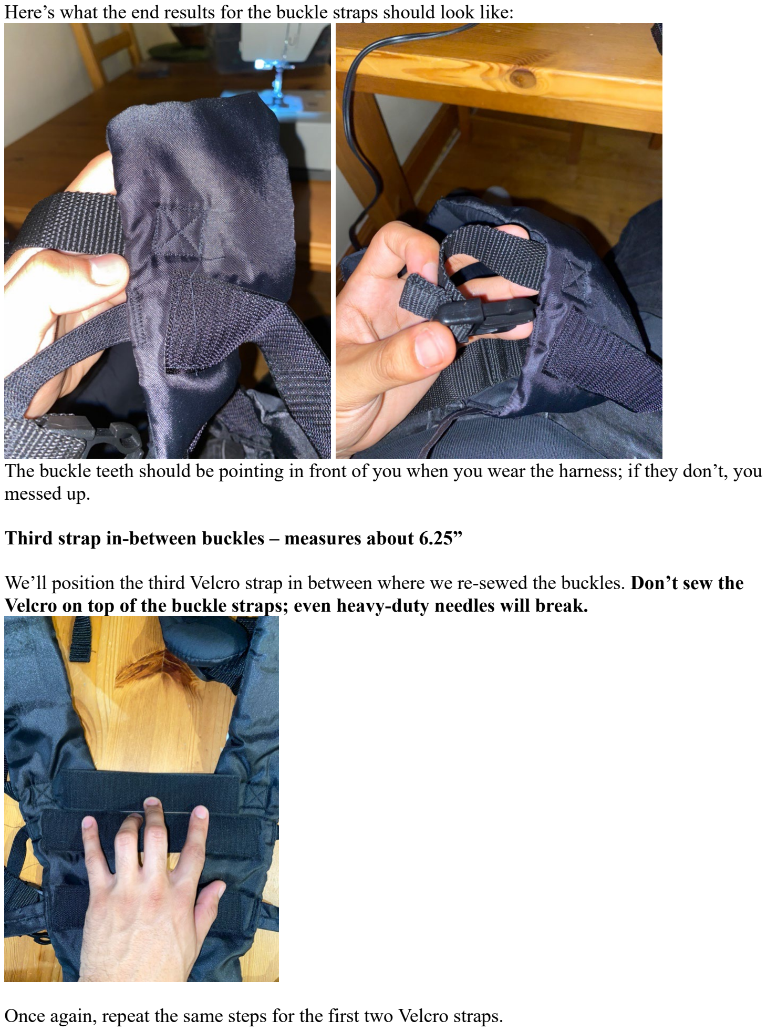
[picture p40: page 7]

Here’s what the end results for the buckle straps should look like:

The buckle teeth should be pointing in front of you when you wear the harness; if they don’t, you messed up.
Third strap in-between buckles – measures about 6.25”
We’ll position the third Velcro strap in between where we re-sewed the buckles. Don’t sew the Velcro on top of the buckle straps; even heavy-duty needles will break.

Once again, repeat the same steps for the first two Velcro straps.

Fourth and final strap – measures about 8.5”

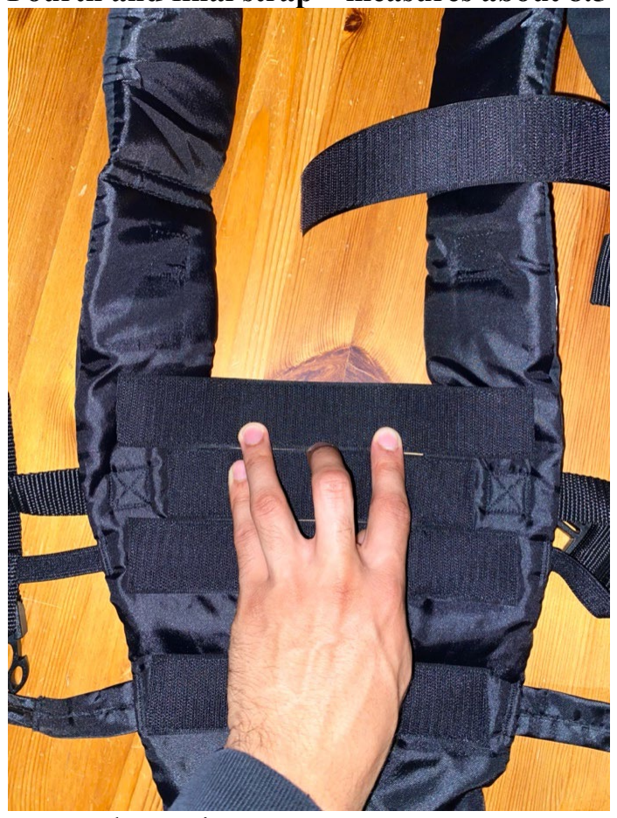
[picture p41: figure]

Repeat the sewing steps.
COMPLETE:

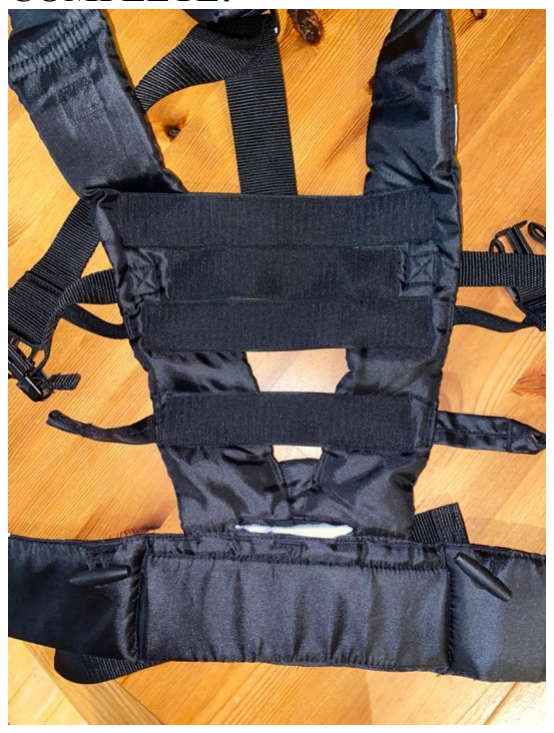
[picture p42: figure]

Final note: You might have noticed or felt that the harness above the last strap has thicker padding than the parts we sewed the Velcro and buckle straps onto. I would not recommend trying to sew any Velcro straps on these thicker parts.

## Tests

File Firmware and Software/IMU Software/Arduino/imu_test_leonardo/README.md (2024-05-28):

# imu_test_leonardo.ino

This is an arduino sketch to test readout of the NN IMU at 250k baud.
I will run on an Arduino Pro Micro with an ATMega32U4 processor.
Known to work with Arduino IDE 2.3.2.

Two serial ports are implemented:

* *Serial* is the USB interface to the computer
* *Serial1* is the Tx/Rx port on pins 0, 1

The code just prints a prompt ">" and waits for the user to either
just hit Enter or type a numeric byte to send.  Then it receives
the message from the IMU and prints the raw data, both as a byte
stream and as 16-bit IMU values.  For example, with the IMU more or
less right-side up to +Z is about 1G (8500 or so).
Note the checksum calculated and received are both displayed
and should match!

    >
    Send: 85
    Count: IMU data:
    942 171 -273 22 257 -114 8413 
    Sum rx calc: 249 249
    raw dump:
    17
    0: 85
    1: 14
    2: -82
    3: 3
    4: -85
    5: 0
    6: -17
    7: -2
    8: 22
    9: 0
    10: 1
    11: 1
    12: -114
    13: -1
    14: -35
    15: 32
    16: -7
    >

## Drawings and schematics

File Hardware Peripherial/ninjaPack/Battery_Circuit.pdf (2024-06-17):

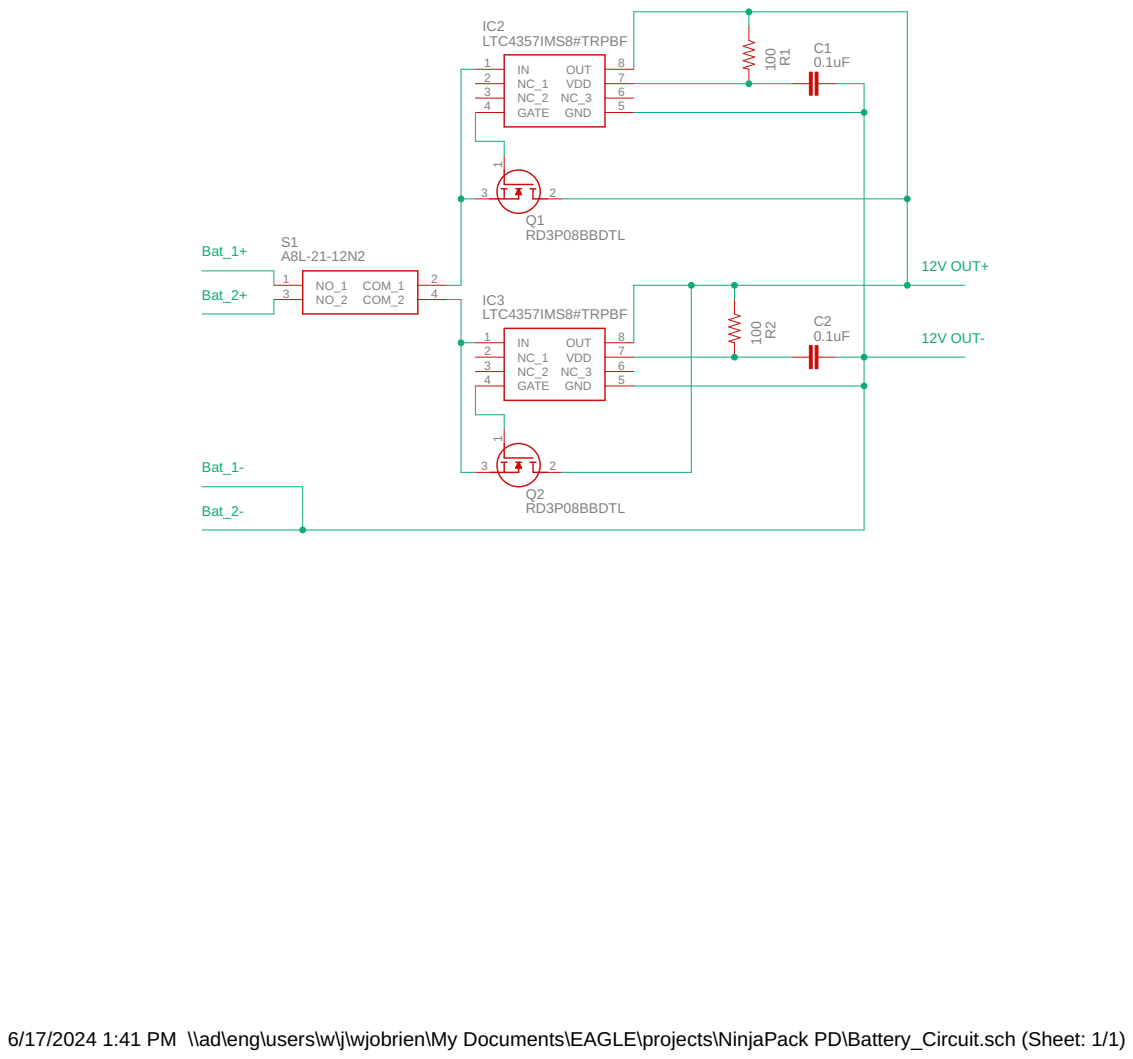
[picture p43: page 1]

6/17/2024 1:41 PM \\ad\eng\users\w\j\wjobrien\My Documents\EAGLE\projects\NinjaPack PD\Battery_Circuit.sch (Sheet: 1/1)

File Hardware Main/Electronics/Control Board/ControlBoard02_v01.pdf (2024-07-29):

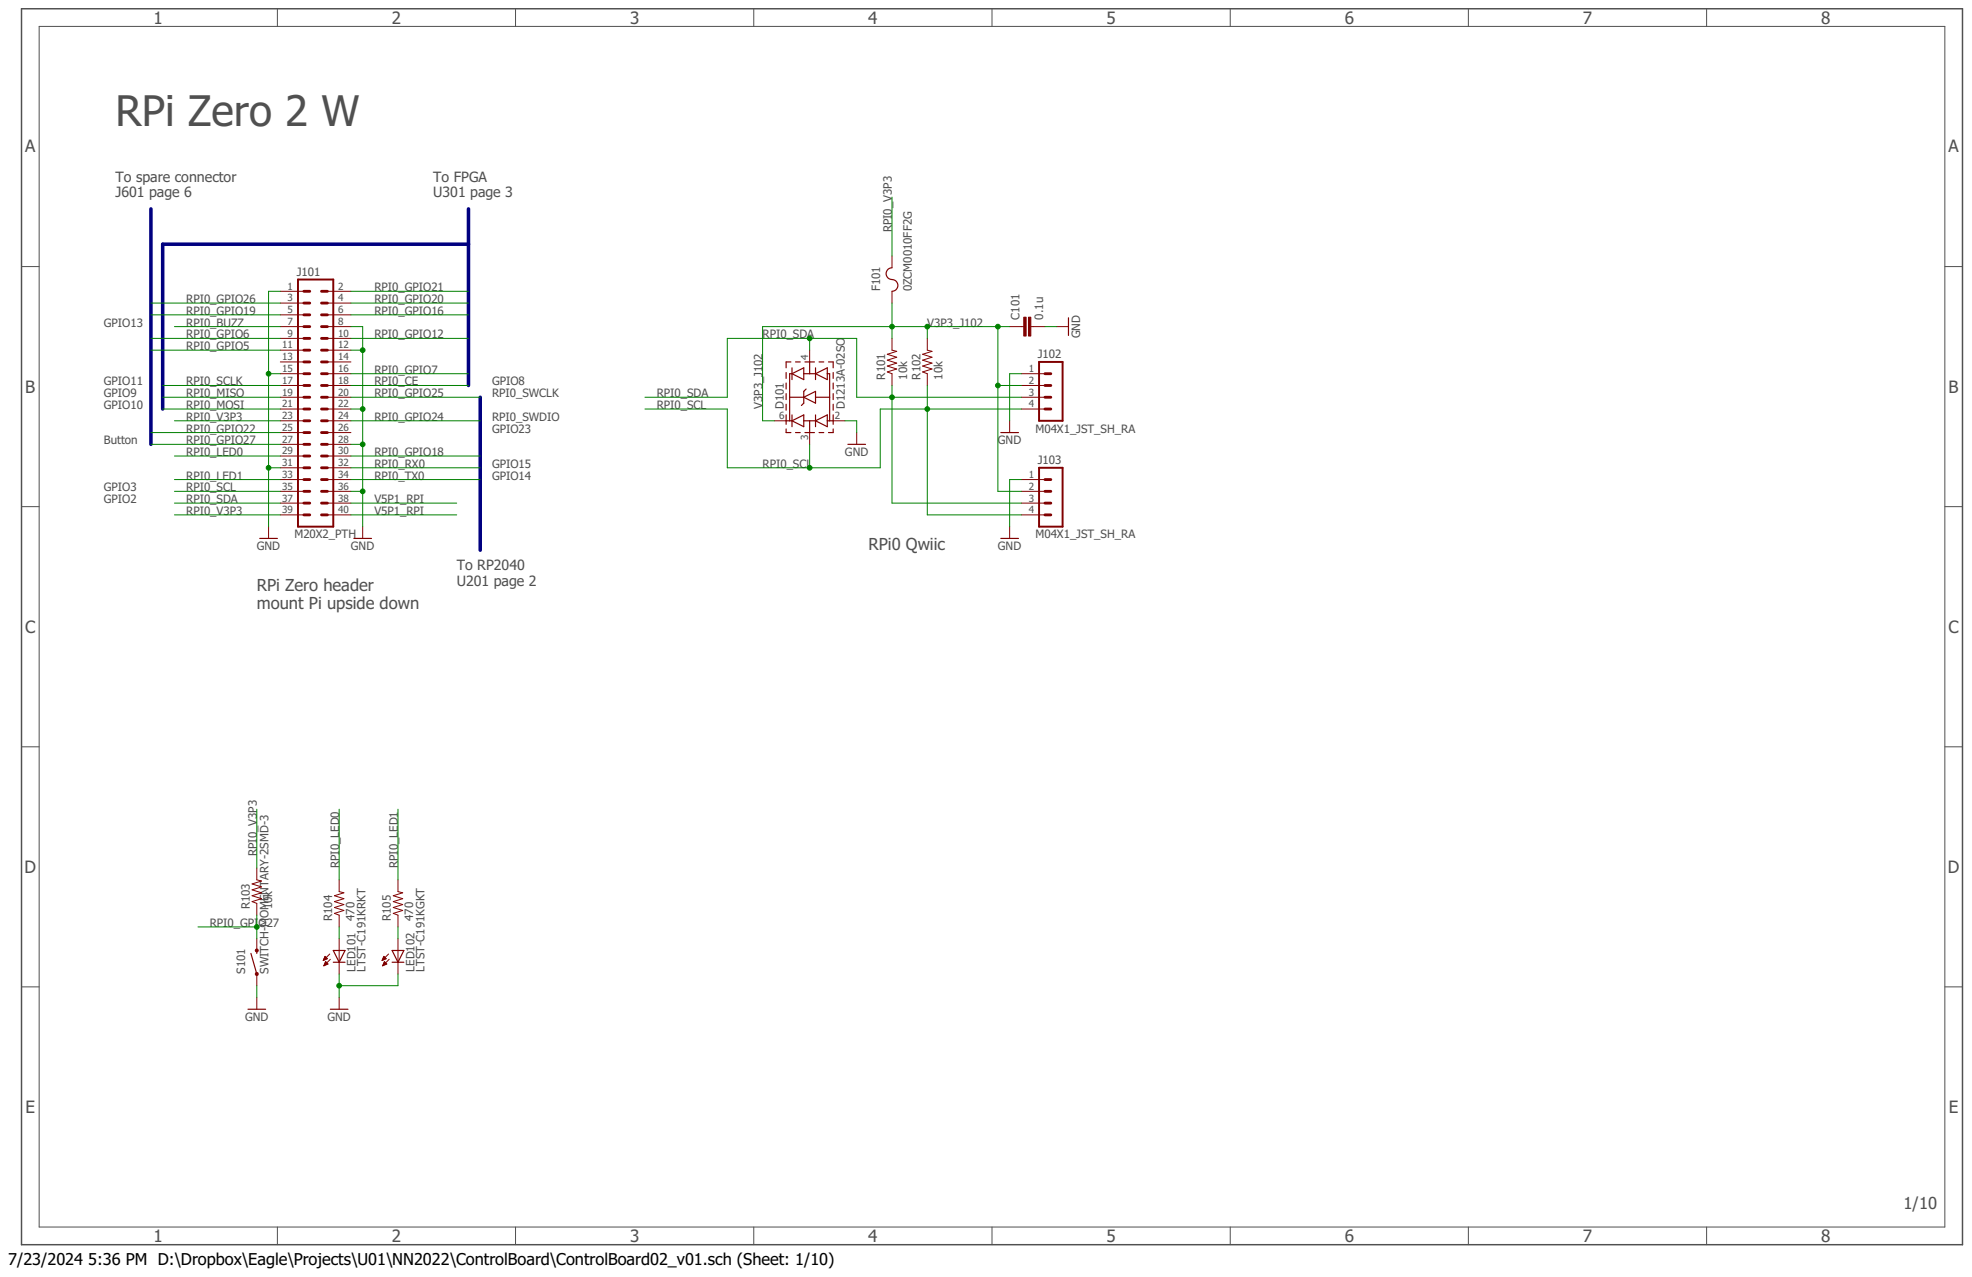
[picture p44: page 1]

RPi Zero header
mount Pi upside down

7/23/2024 5:36 PM D:\Dropbox\Eagle\Projects\U01\NN2022\ControlBoard\ControlBoard02_v01.sch (Sheet: 1/10)

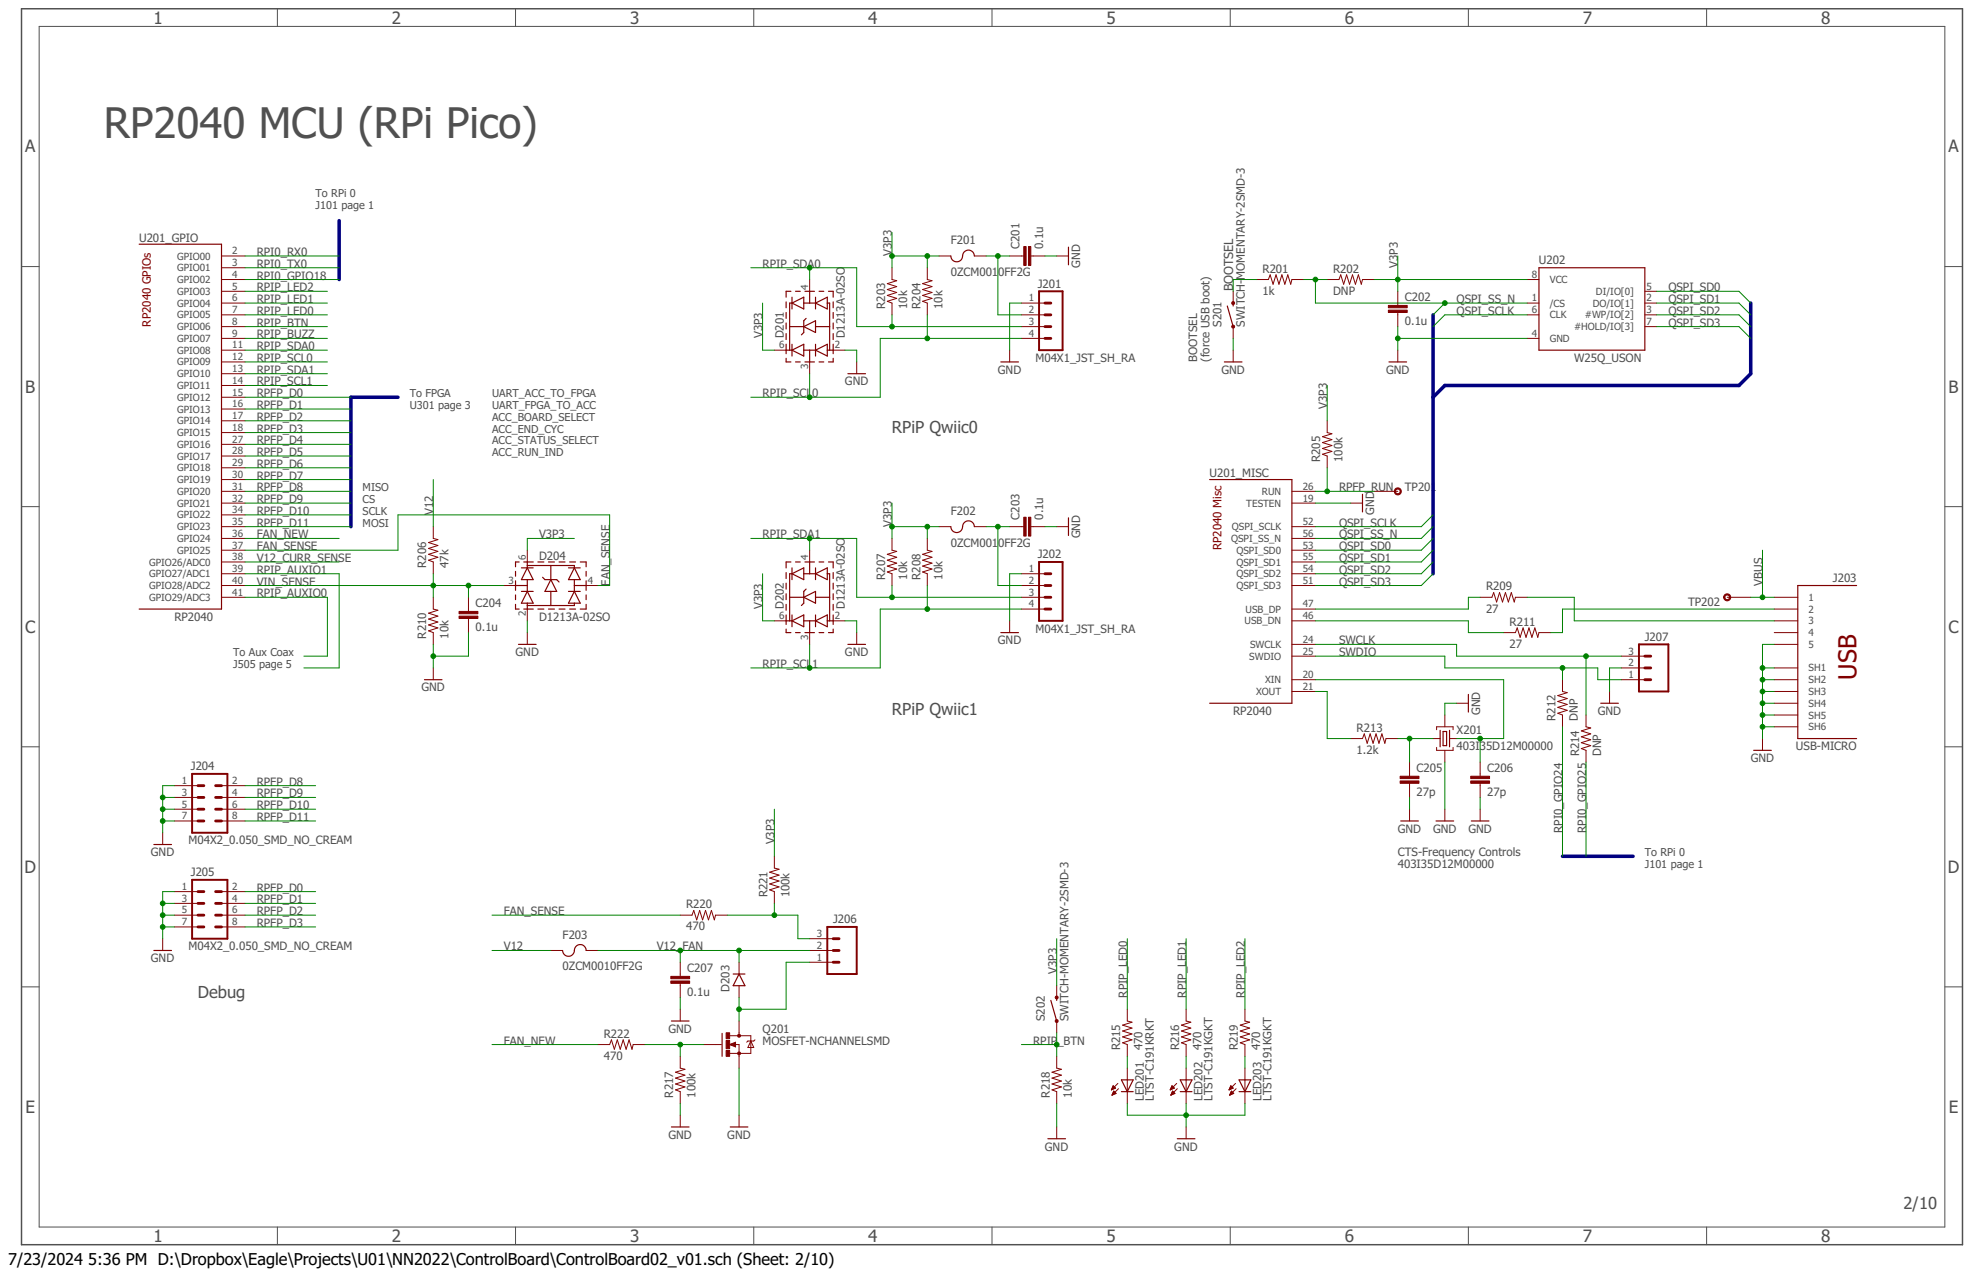
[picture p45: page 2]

7/23/2024 5:36 PM D:\Dropbox\Eagle\Projects\U01\NN2022\ControlBoard\ControlBoard02_v01.sch (Sheet: 2/10)

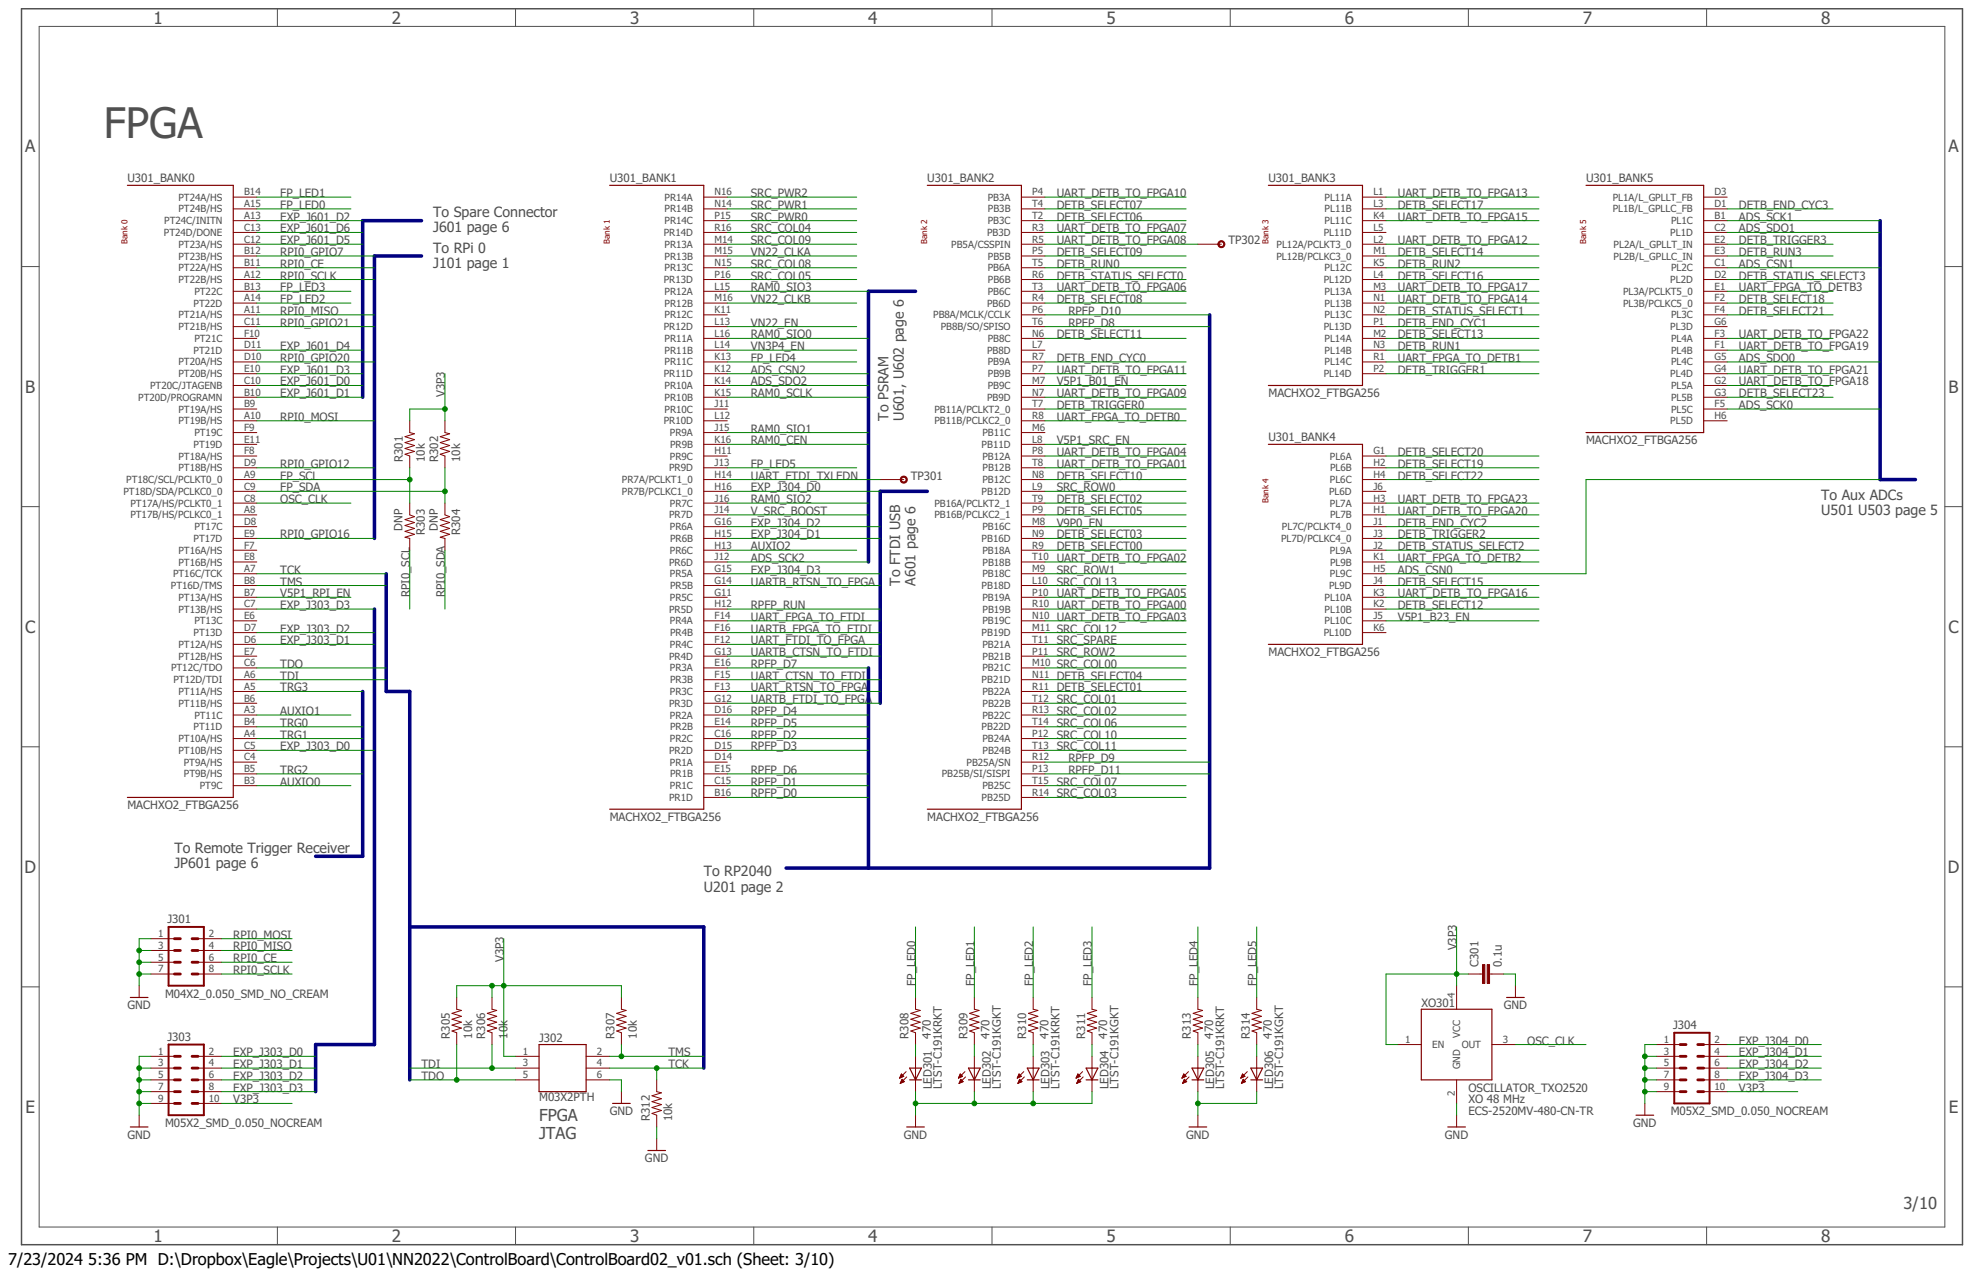
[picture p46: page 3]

To Remote Trigger Receiver
JP601 page 6

OSCILLATOR_TXO2520
XO 48 MHz ECS-2520MV-480-CN-TR

7/23/2024 5:36 PM D:\Dropbox\Eagle\Projects\U01\NN2022\ControlBoard\ControlBoard02_v01.sch (Sheet: 3/10)

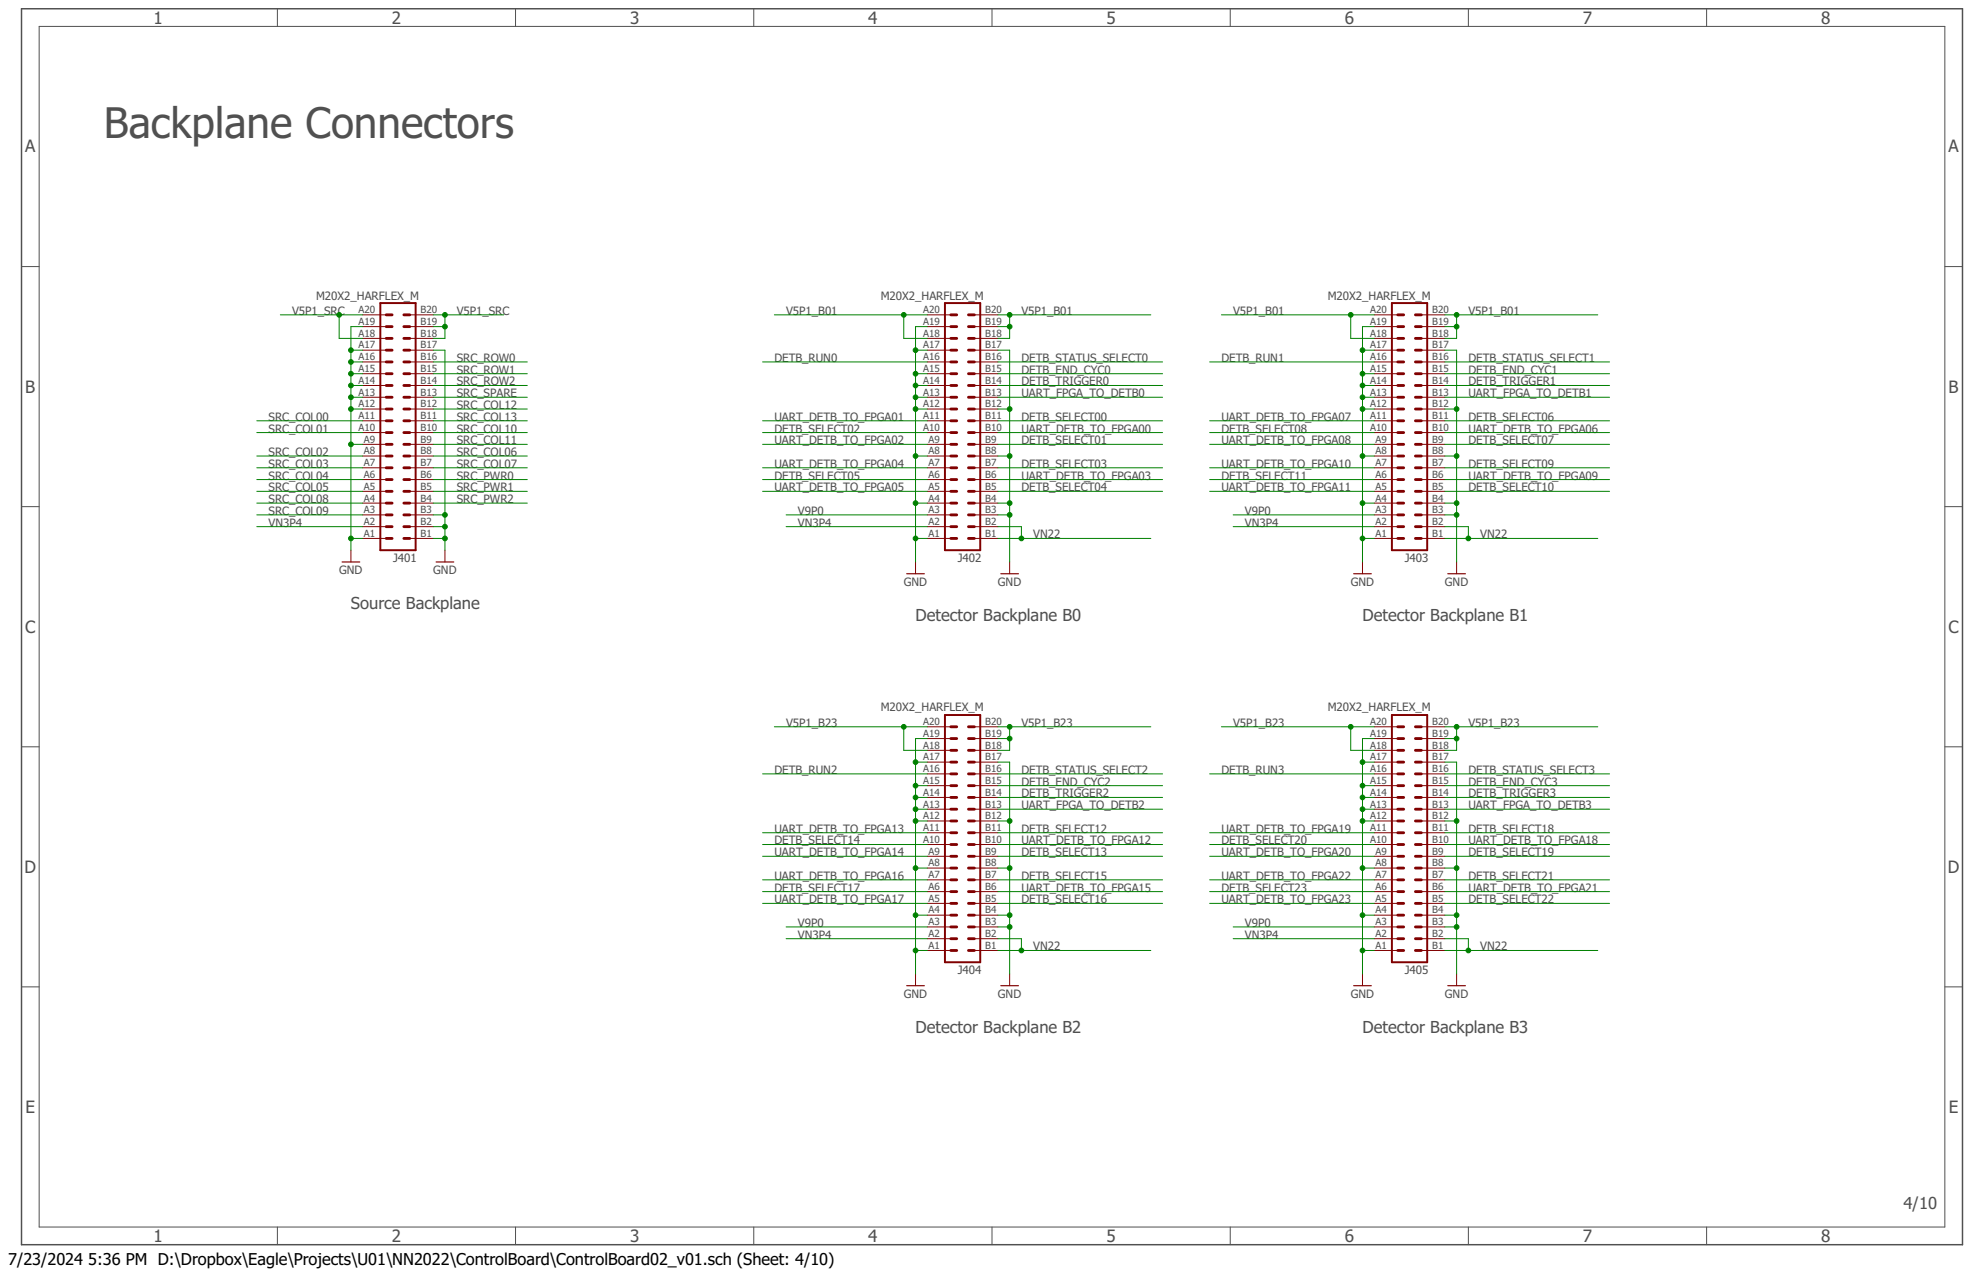
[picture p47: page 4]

7/23/2024 5:36 PM D:\Dropbox\Eagle\Projects\U01\NN2022\ControlBoard\ControlBoard02_v01.sch (Sheet: 4/10)

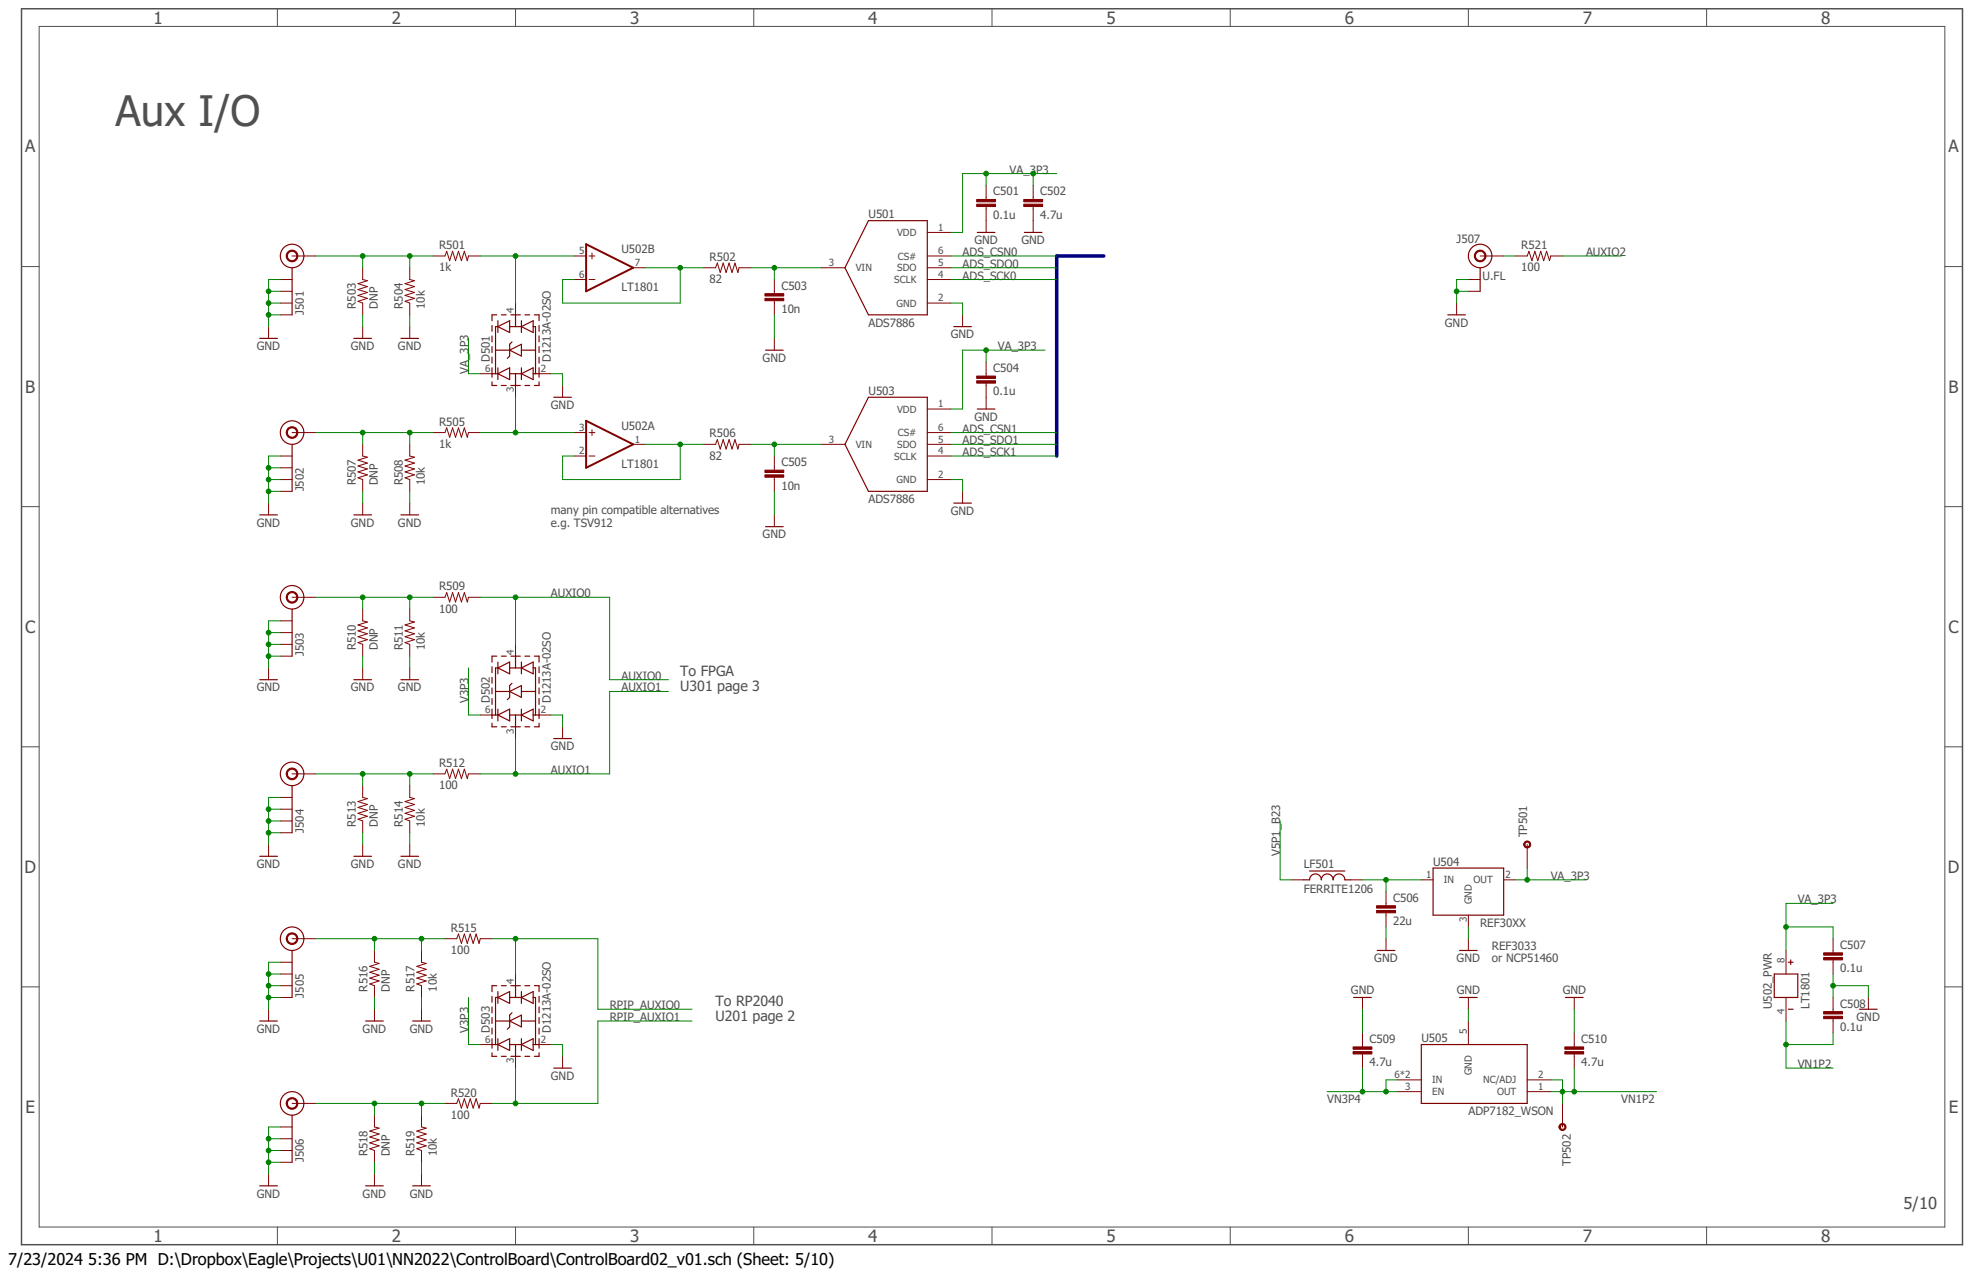
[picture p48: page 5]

many pin compatible alternatives e.g. TSV912

7/23/2024 5:36 PM D:\Dropbox\Eagle\Projects\U01\NN2022\ControlBoard\ControlBoard02_v01.sch (Sheet: 5/10)

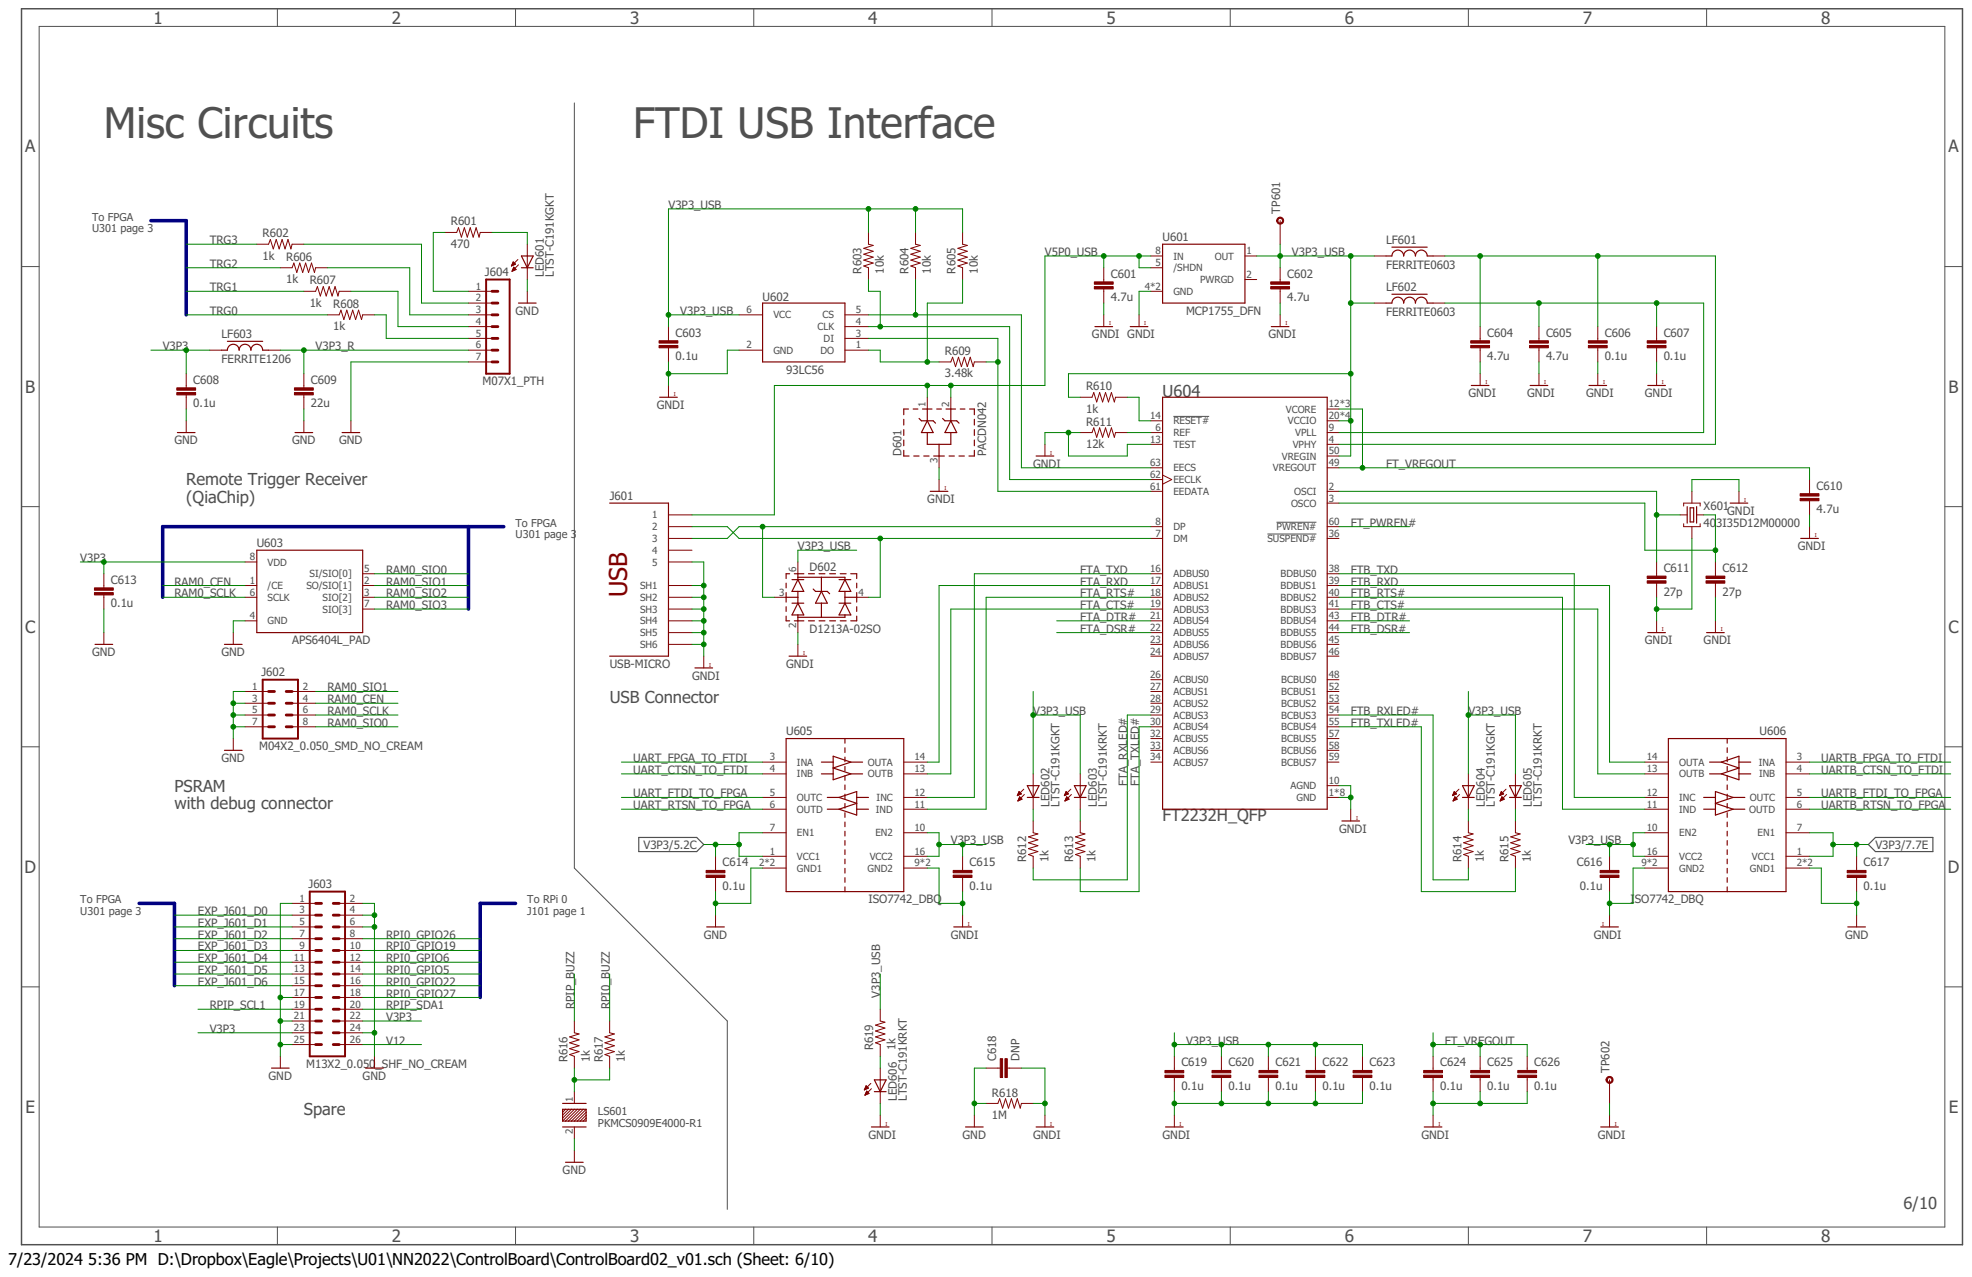
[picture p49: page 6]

7/23/2024 5:36 PM D:\Dropbox\Eagle\Projects\U01\NN2022\ControlBoard\ControlBoard02_v01.sch (Sheet: 6/10)

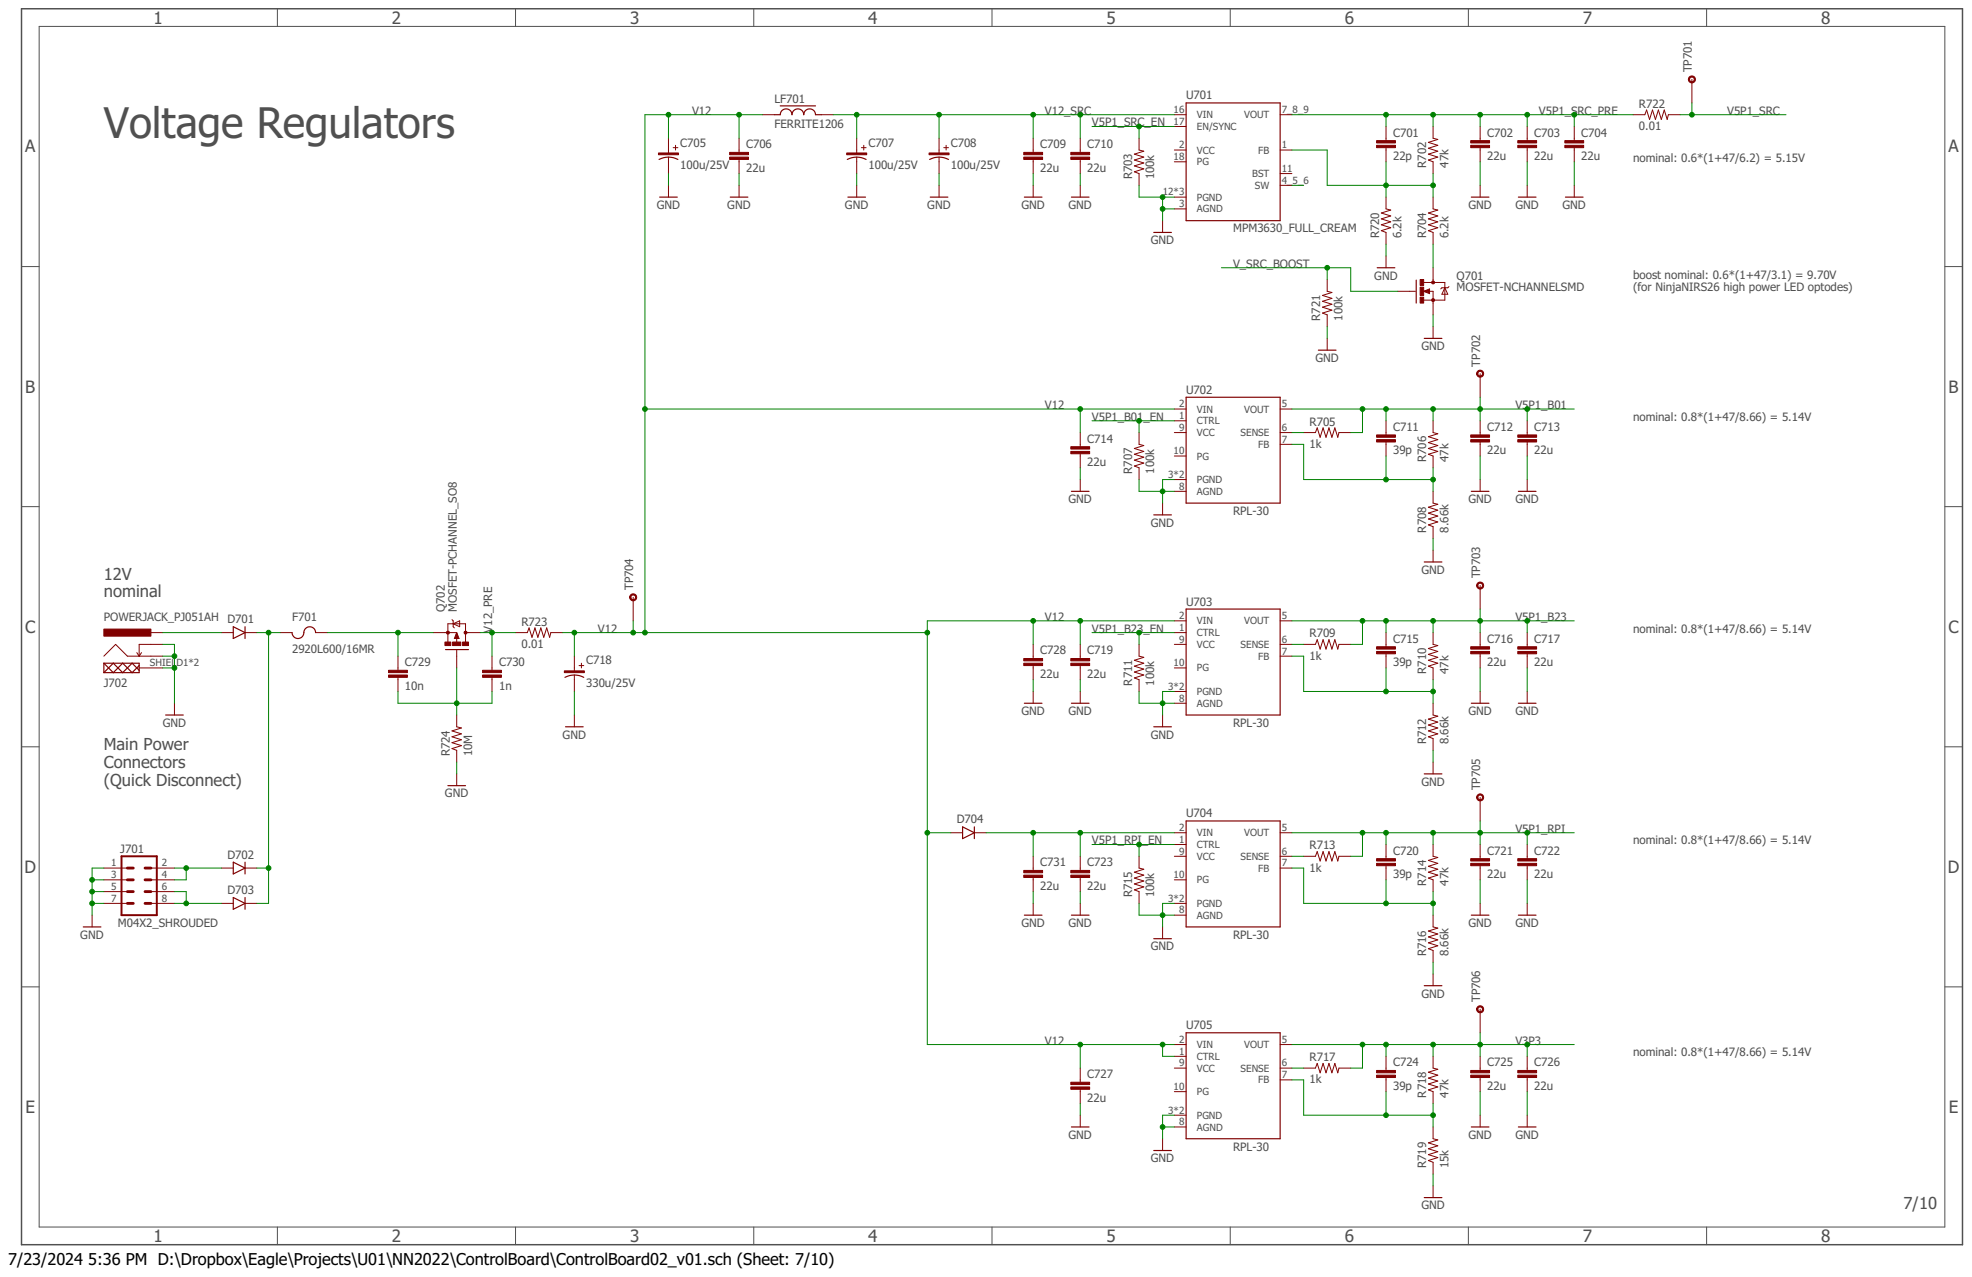
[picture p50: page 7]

boost nominal: 0.6*(1+47/3.1) = 9.70V
(for NinjaNIRS26 high power LED optodes)

7/23/2024 5:36 PM D:\Dropbox\Eagle\Projects\U01\NN2022\ControlBoard\ControlBoard02_v01.sch (Sheet: 7/10)

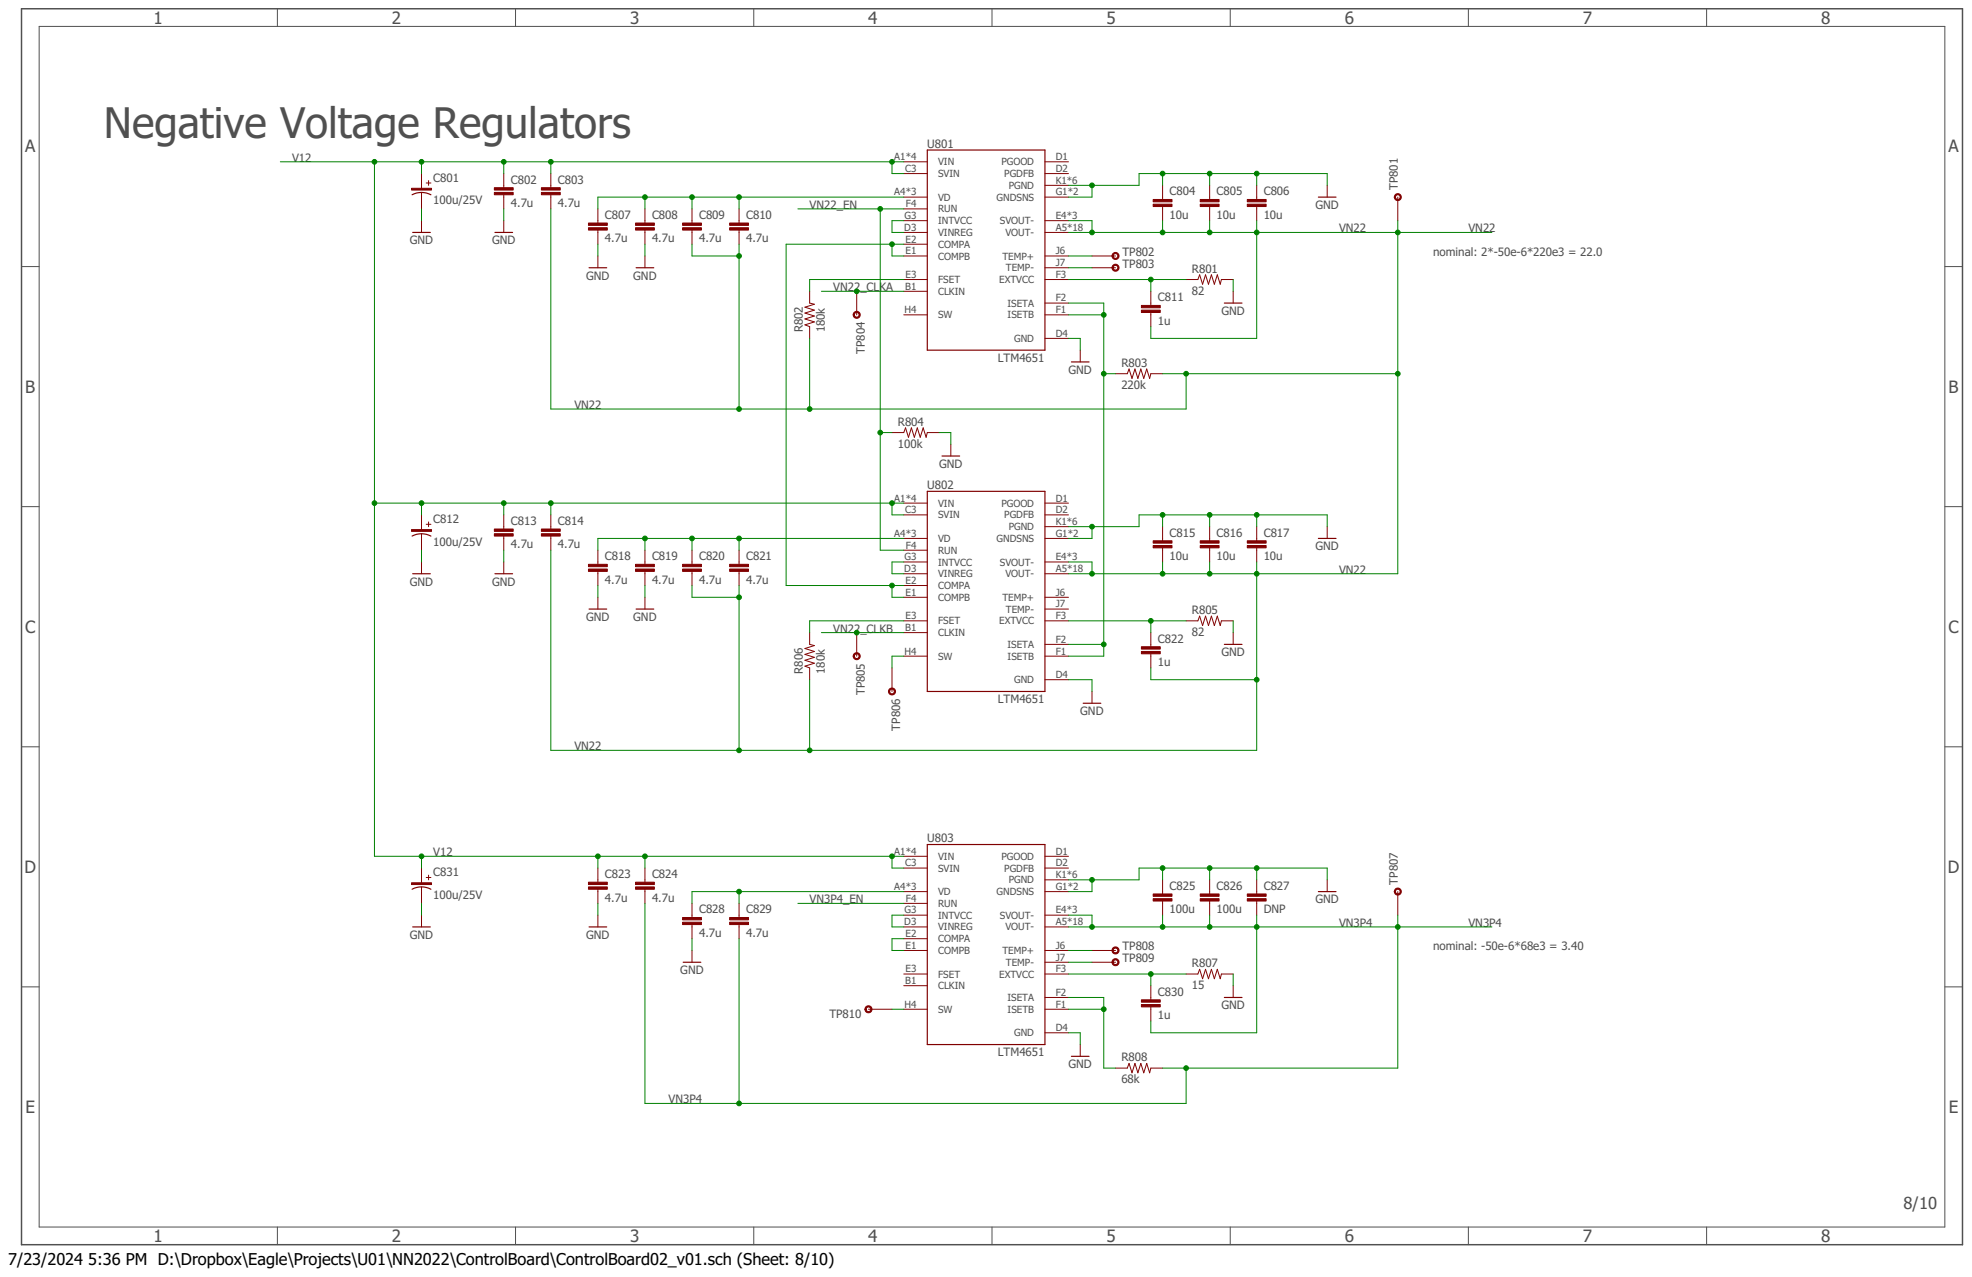
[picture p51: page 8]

F4
VINREG D3 INTVCC G3 | J6 TEMP-J7 EXTVCC F3

7/23/2024 5:36 PM D:\Dropbox\Eagle\Projects\U01\NN2022\ControlBoard\ControlBoard02_v01.sch (Sheet: 8/10)

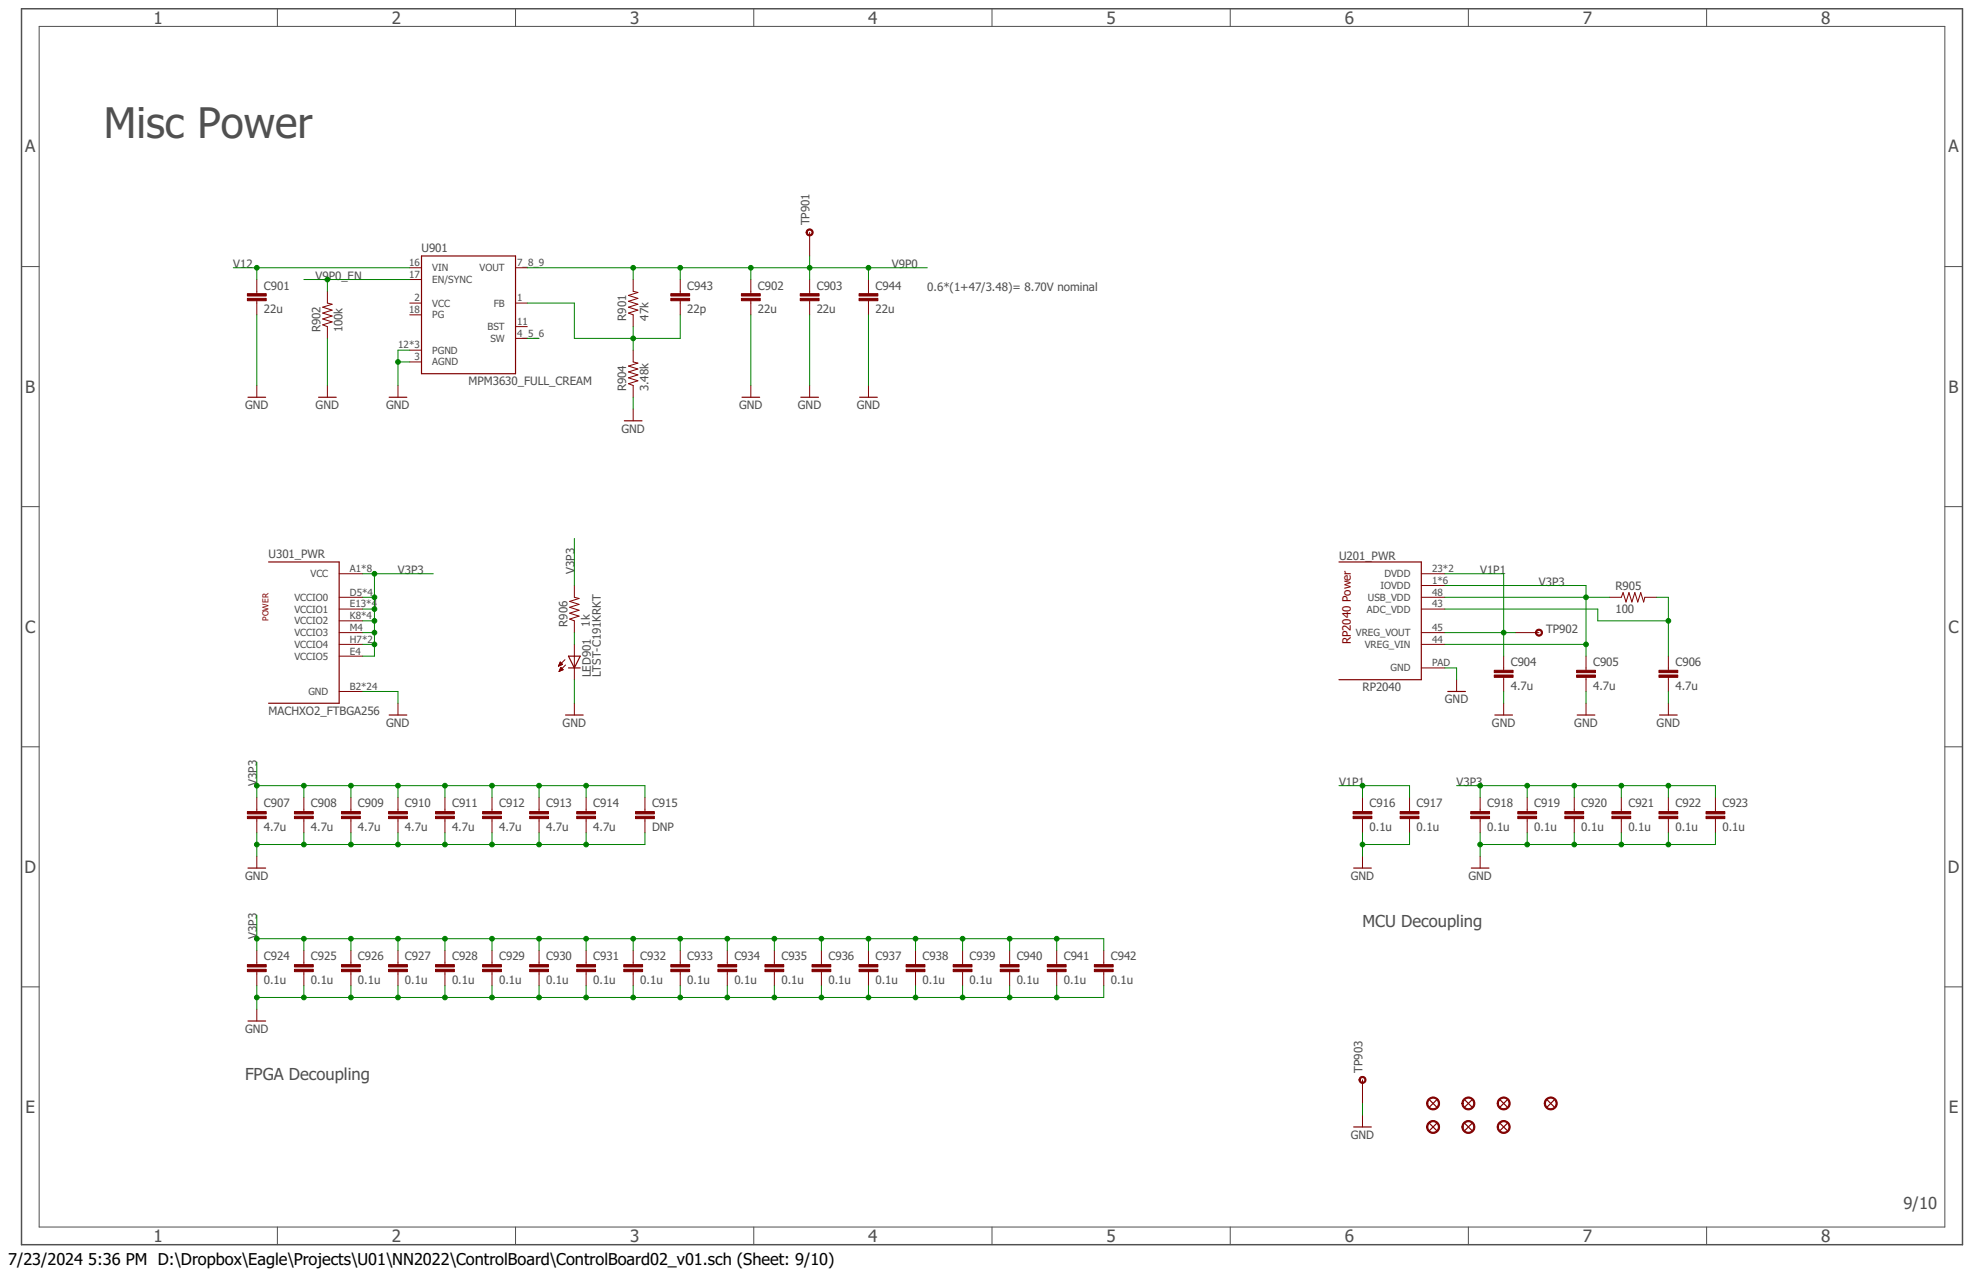
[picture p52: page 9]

48 ADC_VDD | TP902 DVDD

43 VREG_VOUT 45 VREG_VIN

44 GND PAD GND

7/23/2024 5:36 PM D:\Dropbox\Eagle\Projects\U01\NN2022\ControlBoard\ControlBoard02_v01.sch (Sheet: 9/10)

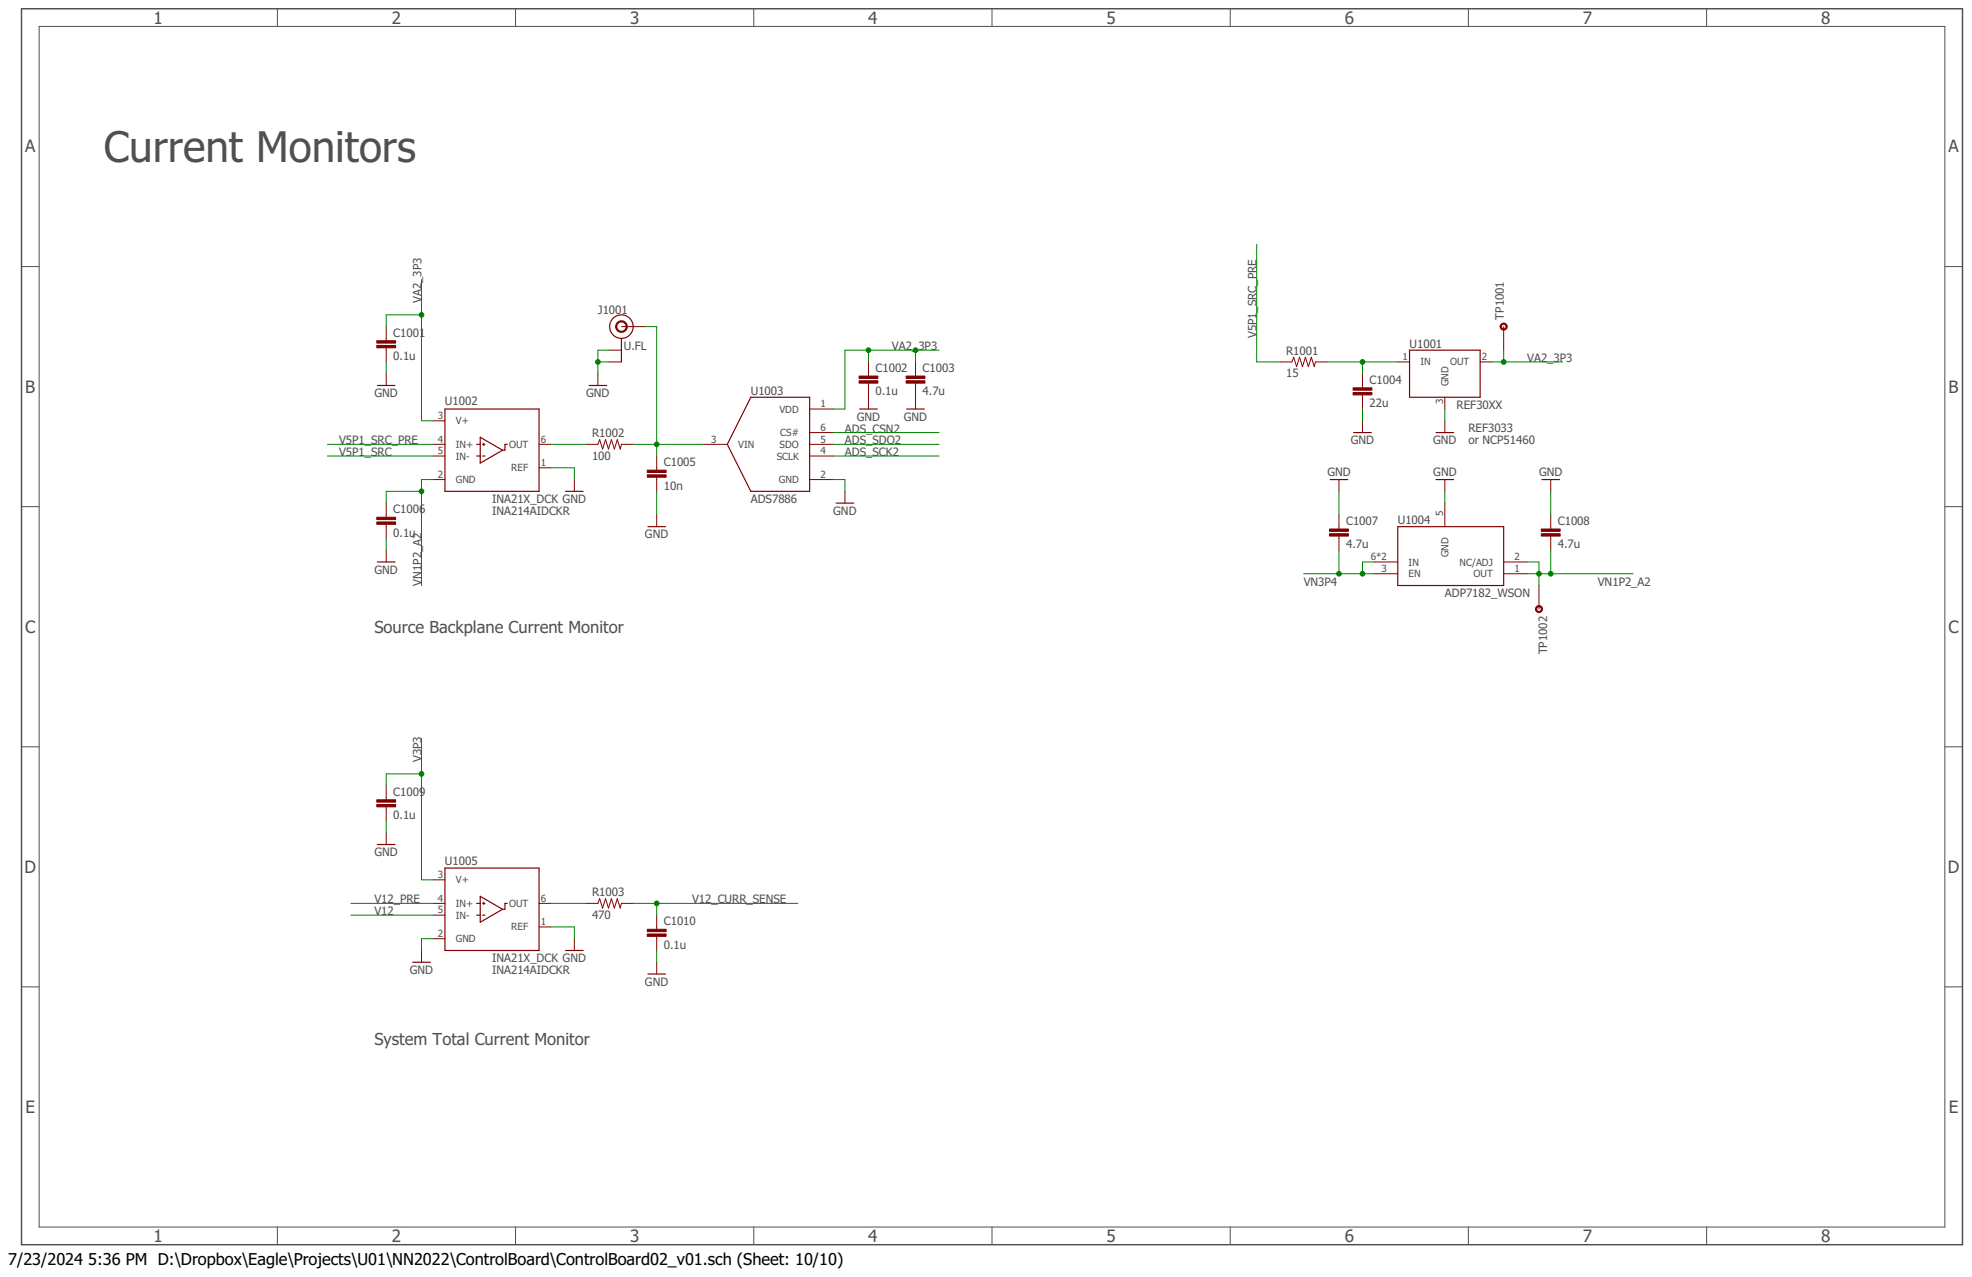
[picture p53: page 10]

Source Backplane Current Monitor

System Total Current Monitor

7/23/2024 5:36 PM D:\Dropbox\Eagle\Projects\U01\NN2022\ControlBoard\ControlBoard02_v01.sch (Sheet: 10/10)

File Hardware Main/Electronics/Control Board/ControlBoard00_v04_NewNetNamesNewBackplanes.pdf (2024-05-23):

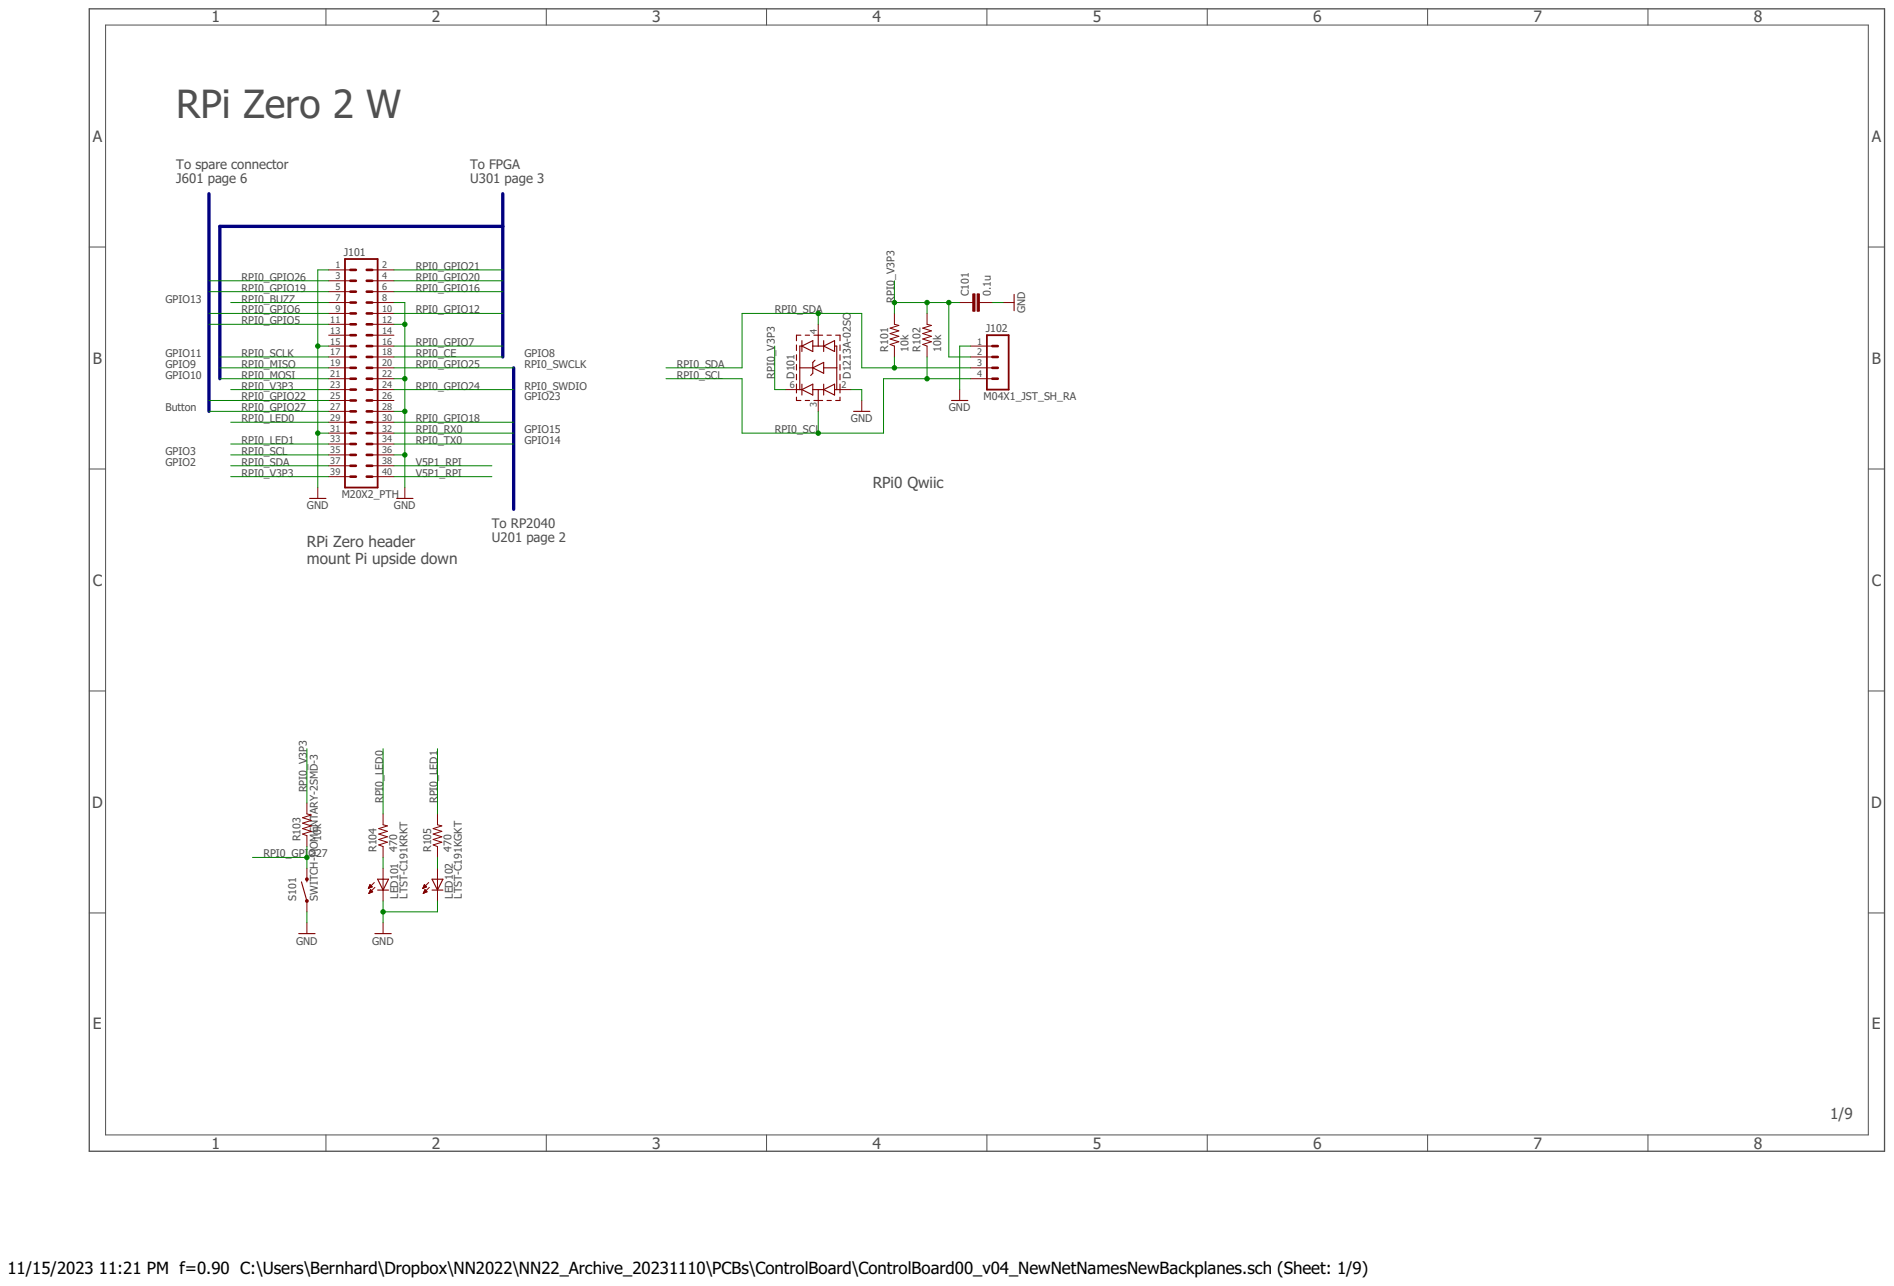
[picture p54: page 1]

To spare connector J601 page 6

RPi Zero header
mount Pi upside down

11/15/2023 11:21 PM f=0.90 C:\Users\Bernhard\Dropbox\NN2022\NN22_Archive_20231110\PCBs\ControlBoard\ControlBoard00_v04_NewNetNamesNewBackplanes.sch (Sheet: 1/9)


To FTDI USB A601 page 6 To Aux Coax
J505 page 5

11/15/2023 11:21 PM f=0.90 C:\Users\Bernhard\Dropbox\NN2022\NN22_Archive_20231110\PCBs\ControlBoard\ControlBoard00_v04_NewNetNamesNewBackplanes.sch (Sheet: 2/9)


To Spare Connector J601 page 6

Error: TP301 should be connected to V5P1_B23_EN (U703)

(boards fixed with jumper wire)

To Remote Trigger Receiver JP601 page 6

OSCILLATOR_TXO2520
XO 48 MHz ECS-2520MV-480-CN-TR

11/15/2023 11:21 PM f=0.90 C:\Users\Bernhard\Dropbox\NN2022\NN22_Archive_20231110\PCBs\ControlBoard\ControlBoard00_v04_NewNetNamesNewBackplanes.sch (Sheet: 3/9)


11/15/2023 11:21 PM f=0.90 C:\Users\Bernhard\Dropbox\NN2022\NN22_Archive_20231110\PCBs\ControlBoard\ControlBoard00_v04_NewNetNamesNewBackplanes.sch (Sheet: 4/9)


Aux Analog In Aux Digital IO

many pin compatible alternatives e.g. TSV912

11/15/2023 11:21 PM f=0.90 C:\Users\Bernhard\Dropbox\NN2022\NN22_Archive_20231110\PCBs\ControlBoard\ControlBoard00_v04_NewNetNamesNewBackplanes.sch (Sheet: 5/9)


can also implement parallel / FIFO interface

EXP_J601_D3
EXP_J601_D4
EXP_J601_D5
EXP_J601_D6

11/15/2023 11:21 PM f=0.90 C:\Users\Bernhard\Dropbox\NN2022\NN22_Archive_20231110\PCBs\ControlBoard\ControlBoard00_v04_NewNetNamesNewBackplanes.sch (Sheet: 6/9)


Error: TP301 should be connected to V5P1_B23_EN (U703)

(boards fixed with jumper wire)

11/15/2023 11:21 PM f=0.90 C:\Users\Bernhard\Dropbox\NN2022\NN22_Archive_20231110\PCBs\ControlBoard\ControlBoard00_v04_NewNetNamesNewBackplanes.sch (Sheet: 7/9)


11/15/2023 11:21 PM f=0.90 C:\Users\Bernhard\Dropbox\NN2022\NN22_Archive_20231110\PCBs\ControlBoard\ControlBoard00_v04_NewNetNamesNewBackplanes.sch (Sheet: 8/9)


DNP GND GND GND

48 ADC_VDD | TP902 DVDD

43 VREG_VOUT 45 VREG_VIN

44 GND PAD GND

11/15/2023 11:21 PM f=0.90 C:\Users\Bernhard\Dropbox\NN2022\NN22_Archive_20231110\PCBs\ControlBoard\ControlBoard00_v04_NewNetNamesNewBackplanes.sch (Sheet: 9/9)

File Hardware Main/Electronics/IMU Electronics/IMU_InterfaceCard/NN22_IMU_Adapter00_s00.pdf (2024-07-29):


RX: from IMU Adapter to IMU Board
TX: from IMU Board to IMU Adapter
(IMU Board centric labeling)

3/20/2024 2:59 PM D:\Dropbox\Eagle\Projects\U01\NN2022\IMU\IMU_Adapter\NN22_IMU_Adapter00_s00.sch (Sheet: 1/2)


48 ADC_VDD
43 VREG_VOUT 45 VREG_VIN | TP4

3/20/2024 2:59 PM D:\Dropbox\Eagle\Projects\U01\NN2022\IMU\IMU_Adapter\NN22_IMU_Adapter00_s00.sch (Sheet: 2/2)

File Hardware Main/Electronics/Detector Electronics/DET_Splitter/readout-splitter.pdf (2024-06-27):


Id: 1/9 Title: File: readout-splitter.kicad_sch Sheet: /


2 EN 3 SENSE/ADJ 4 VOUT 5 U17 ADP7142WAUJZ-5.0

2 EN 3 SENSE/ADJ 4 VOUT 5 U1 ADP7182AUJZ

(see ADP7182 data sheet page 25) R1

1 VIN 2 EN 3 ADJ 4 VOUT 5 U1 ADP7182AUJZ
505-ADP7182AUJZ-R7CT-ND GND

1 VIN 2 EN 3 ADJ 4 VOUT 5

Id: 2/9 Title: File: vregs.kicad_sch Sheet: /vregs/


2 EN 3 SENSE/ADJ 4 VOUT 5 U18 ADP7142WAUJZ-5.0

2 EN 3 SENSE/ADJ 4 VOUT 5 U2 ADP7182AUJZ

(see ADP7182 data sheet page 25) C7

1 VIN 2 EN 3 ADJ 4 VOUT 5 U2 ADP7182AUJZ
505-ADP7182AUJZ-R7CT-ND GND

1 VIN 2 EN 3 ADJ 4 VOUT 5

Id: 3/9 Title: File: vregs.kicad_sch Sheet: /vregs1/


2 EN 3 SENSE/ADJ 4 VOUT 5 U19 ADP7142WAUJZ-5.0

2 EN 3 SENSE/ADJ 4 VOUT 5 U3 ADP7182AUJZ

(see ADP7182 data sheet page 25) C11

1 VIN 2 EN 3 ADJ 4 VOUT 5 U3 ADP7182AUJZ
505-ADP7182AUJZ-R7CT-ND GND

1 VIN 2 EN 3 ADJ 4 VOUT 5

Id: 4/9 Title: File: vregs.kicad_sch Sheet: /vregs2/


2 EN 3 SENSE/ADJ 4 VOUT 5 U20 ADP7142WAUJZ-5.0

2 EN 3 SENSE/ADJ 4 VOUT 5 U4 ADP7182AUJZ

(see ADP7182 data sheet page 25) C15

1 VIN 2 EN 3 ADJ 4 VOUT 5 U4 ADP7182AUJZ
505-ADP7182AUJZ-R7CT-ND GND

1 VIN 2 EN 3 ADJ 4 VOUT 5

Id: 5/9 Title: File: vregs.kicad_sch Sheet: /vregs3/


2 EN 3 SENSE/ADJ 4 VOUT 5 U21 ADP7142WAUJZ-5.0

2 EN 3 SENSE/ADJ 4 VOUT 5 U5 ADP7182AUJZ

(see ADP7182 data sheet page 25) C19

1 VIN 2 EN 3 ADJ 4 VOUT 5 U5 ADP7182AUJZ
505-ADP7182AUJZ-R7CT-ND GND

1 VIN 2 EN 3 ADJ 4 VOUT 5

Id: 6/9 Title: File: vregs.kicad_sch Sheet: /vregs4/


2 EN 3 SENSE/ADJ 4 VOUT 5 U22 ADP7142WAUJZ-5.0

2 EN 3 SENSE/ADJ 4 VOUT 5 U6 ADP7182AUJZ

(see ADP7182 data sheet page 25) C23

1 VIN 2 EN 3 ADJ 4 VOUT 5 U6 ADP7182AUJZ
505-ADP7182AUJZ-R7CT-ND GND

1 VIN 2 EN 3 ADJ 4 VOUT 5

Id: 7/9 Title: File: vregs.kicad_sch Sheet: /vregs5/


2 EN 3 SENSE/ADJ 4 VOUT 5 U23 ADP7142WAUJZ-5.0

2 EN 3 SENSE/ADJ 4 VOUT 5 U7 ADP7182AUJZ

(see ADP7182 data sheet page 25) C27

1 VIN 2 EN 3 ADJ 4 VOUT 5 U7 ADP7182AUJZ
505-ADP7182AUJZ-R7CT-ND GND

1 VIN 2 EN 3 ADJ 4 VOUT 5

Id: 8/9 Title: File: vregs.kicad_sch Sheet: /vregs6/


2 EN 3 SENSE/ADJ 4 VOUT 5 U24 ADP7142WAUJZ-5.0

2 EN 3 SENSE/ADJ 4 VOUT 5 U8 ADP7182AUJZ

(see ADP7182 data sheet page 25) C31

1 VIN 2 EN 3 ADJ 4 VOUT 5 U8 ADP7182AUJZ
505-ADP7182AUJZ-R7CT-ND GND

1 VIN 2 EN 3 ADJ 4 VOUT 5

Id: 9/9 Title: File: vregs.kicad_sch Sheet: /vregs7/

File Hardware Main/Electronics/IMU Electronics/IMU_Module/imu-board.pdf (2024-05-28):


2 SCK 3 MOSI 4 ~{RST} 5 GND
SCL SCK

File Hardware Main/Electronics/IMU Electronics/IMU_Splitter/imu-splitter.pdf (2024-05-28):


Id: 1/1 Title: File: imu-splitter.kicad_sch Sheet: / 12345

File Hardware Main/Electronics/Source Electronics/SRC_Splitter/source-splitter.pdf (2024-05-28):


Id: 1/1 Title: File: source-splitter.kicad_sch Sheet: / N1 Housing

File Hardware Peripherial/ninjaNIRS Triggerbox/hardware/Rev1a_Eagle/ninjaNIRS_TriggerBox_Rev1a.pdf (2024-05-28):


TE_CON_BNC_5227161-9 TE_CON_BNC_5227161-9 TE_CON_BNC_5227161-9 TE_CON_BNC_5227161-9 MINI-USB-UX60A-MB-5ST 10uF 100 GND GNDCONN RCPT 7POS 0.1" GOLD PCB R/A GND E-SWITCH-800BWSP9SM6RE E-SWITCH-800BWSP9SM6RE E-SWITCH-800BWSP9SM6RE E-SWITCH-800BWSP9SM6RE LTST-C191KGKT 1k Antenna 10k 10k 10k 10k 10k 10k 10k 10k SN74HCS08-Q1 SN74HCS08-Q1 SN74HCS08-Q1 SN74HCS08-Q1 GND GND +5V 100nF GND GND GND GND GND GND +5V +5V +5V +5V +5V +5V +5V +5V 100nF+5V 10uF GND 39 47n 47n 47n 47n 39 39 39 PNP MMB+T3906 5V 1k Kingbright APA1606QBC/D 100 GND PNP MMBT3906 +5V 1k Kingbright APA1606QBC/D 100 GND PNP MMBT3906 +5V 1k Kingbright APA1606QBC/D 100 GND PNP MMBT3906 +5V 1k Kingbright APA1606QBC/D 100 GND 10uF 100nF GND +5V PNP MMBT3906 GND 1k1k 1k1k PNP MMBT3906 PNP MMBT3906 PNP MMBT3906 GND GNDGND SHIELD P$3 SIG P$4 N/C2 P$2 N/C1 XP$1 2 SHIELD P$3 SIG P$4 N/C2 P$2 N/C1 XP$1 3 SHIELD P$3 SIG P$4 N/C2 P$2 N/C1 XP$1 4 SHIELD P$3 SIG P$4 N/C2 P$2 N/C1 XP$1 5 X1 12345 C1 R1 JP11234567 P$1 P$1 P$2 P$2 S2 P$1 P$1 P$2 P$2 S3 P$1 P$1 P$2 P$2 S5 P$1 P$1 P$2 P$2 S4 LED1 R2 JP2 1 R3 R4 R5 R6 R7R8 R9R10 1 IC1A 2 3 4 IC1B 5 6 9 IC1C 10 8 12 IC1D 13 11 C2 IC1PGND VCC 7 14 C4 C3 R11 C5C6 C7C8 R12 R13 R14 T1R15 LED2 R16 T2R17 LED3 R18 T3R19 LED4 R20 T4R21 LED5 R22 C9 C10 T5R23R24 R25R26 T6 T8 T7 K1 K1 K2 K2 K4 K4 K3 K3 ninjaNIRS_TriggerBox_Rev1a 11/23/2020 12:10 PM Sheet: 1/1 ABCD 1 2 3 4 5 6 ABCD 1 2 3 4 5 6

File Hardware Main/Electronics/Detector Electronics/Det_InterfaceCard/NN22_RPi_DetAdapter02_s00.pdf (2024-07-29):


VOCM /DISABLE -VS

3/20/2024 3:26 PM D:\Dropbox\Eagle\Projects\U01\NN2022\DetAdapter\v02\NN22_RPi_DetAdapter02_s00.sch (Sheet: 1/6)


VOCM /DISABLE -VS

3/20/2024 3:26 PM D:\Dropbox\Eagle\Projects\U01\NN2022\DetAdapter\v02\NN22_RPi_DetAdapter02_s00.sch (Sheet: 2/6)


VOCM /DISABLE -VS

3/20/2024 3:26 PM D:\Dropbox\Eagle\Projects\U01\NN2022\DetAdapter\v02\NN22_RPi_DetAdapter02_s00.sch (Sheet: 3/6)


VOCM /DISABLE -VS

3/20/2024 3:26 PM D:\Dropbox\Eagle\Projects\U01\NN2022\DetAdapter\v02\NN22_RPi_DetAdapter02_s00.sch (Sheet: 4/6)


3/20/2024 3:26 PM D:\Dropbox\Eagle\Projects\U01\NN2022\DetAdapter\v02\NN22_RPi_DetAdapter02_s00.sch (Sheet: 5/6)


48 ADC_VDD
43 VREG_VOUT 45 VREG_VIN | TP21

use 5V fixed output version
ADP7142ACPZN5.0-R7

3/20/2024 3:26 PM D:\Dropbox\Eagle\Projects\U01\NN2022\DetAdapter\v02\NN22_RPi_DetAdapter02_s00.sch (Sheet: 6/6)

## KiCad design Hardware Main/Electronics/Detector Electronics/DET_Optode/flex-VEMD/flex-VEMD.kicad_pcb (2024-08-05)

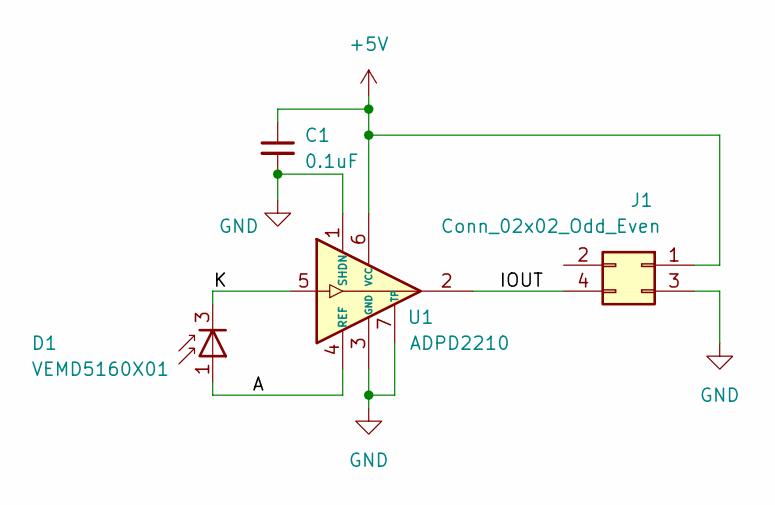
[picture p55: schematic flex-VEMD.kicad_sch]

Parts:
C1: 0.1uF; C_0402_1005Metric
D1: VEMD5160X01; VEMD-4-4.1x5.2mm
J1: Conn_02x02_Odd_Even; PinHeader_2x02_P1.27mm_compact
U1: ADPD2210; LFCSP-6-2x2mm

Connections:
+5V: C1.1, J1.1, U1.6 (VCC)
/A: D1.1 (A), U1.4 (REF)
/IOUT: J1.4, U1.2
/K: D1.3 (K), D1.4 (K), U1.5
GND: C1.2, J1.3, U1.1 (SHDN), U1.3 (GND), U1.7 (TP)

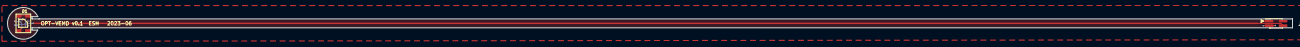
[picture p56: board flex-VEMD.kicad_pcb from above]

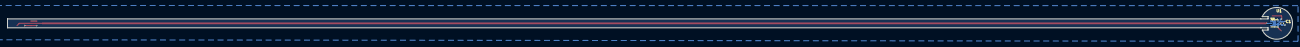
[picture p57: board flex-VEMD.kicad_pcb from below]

Board: 2 copper layers, 360.0 x 8.9 mm, 4 parts (2 on the bottom side), 5 nets.

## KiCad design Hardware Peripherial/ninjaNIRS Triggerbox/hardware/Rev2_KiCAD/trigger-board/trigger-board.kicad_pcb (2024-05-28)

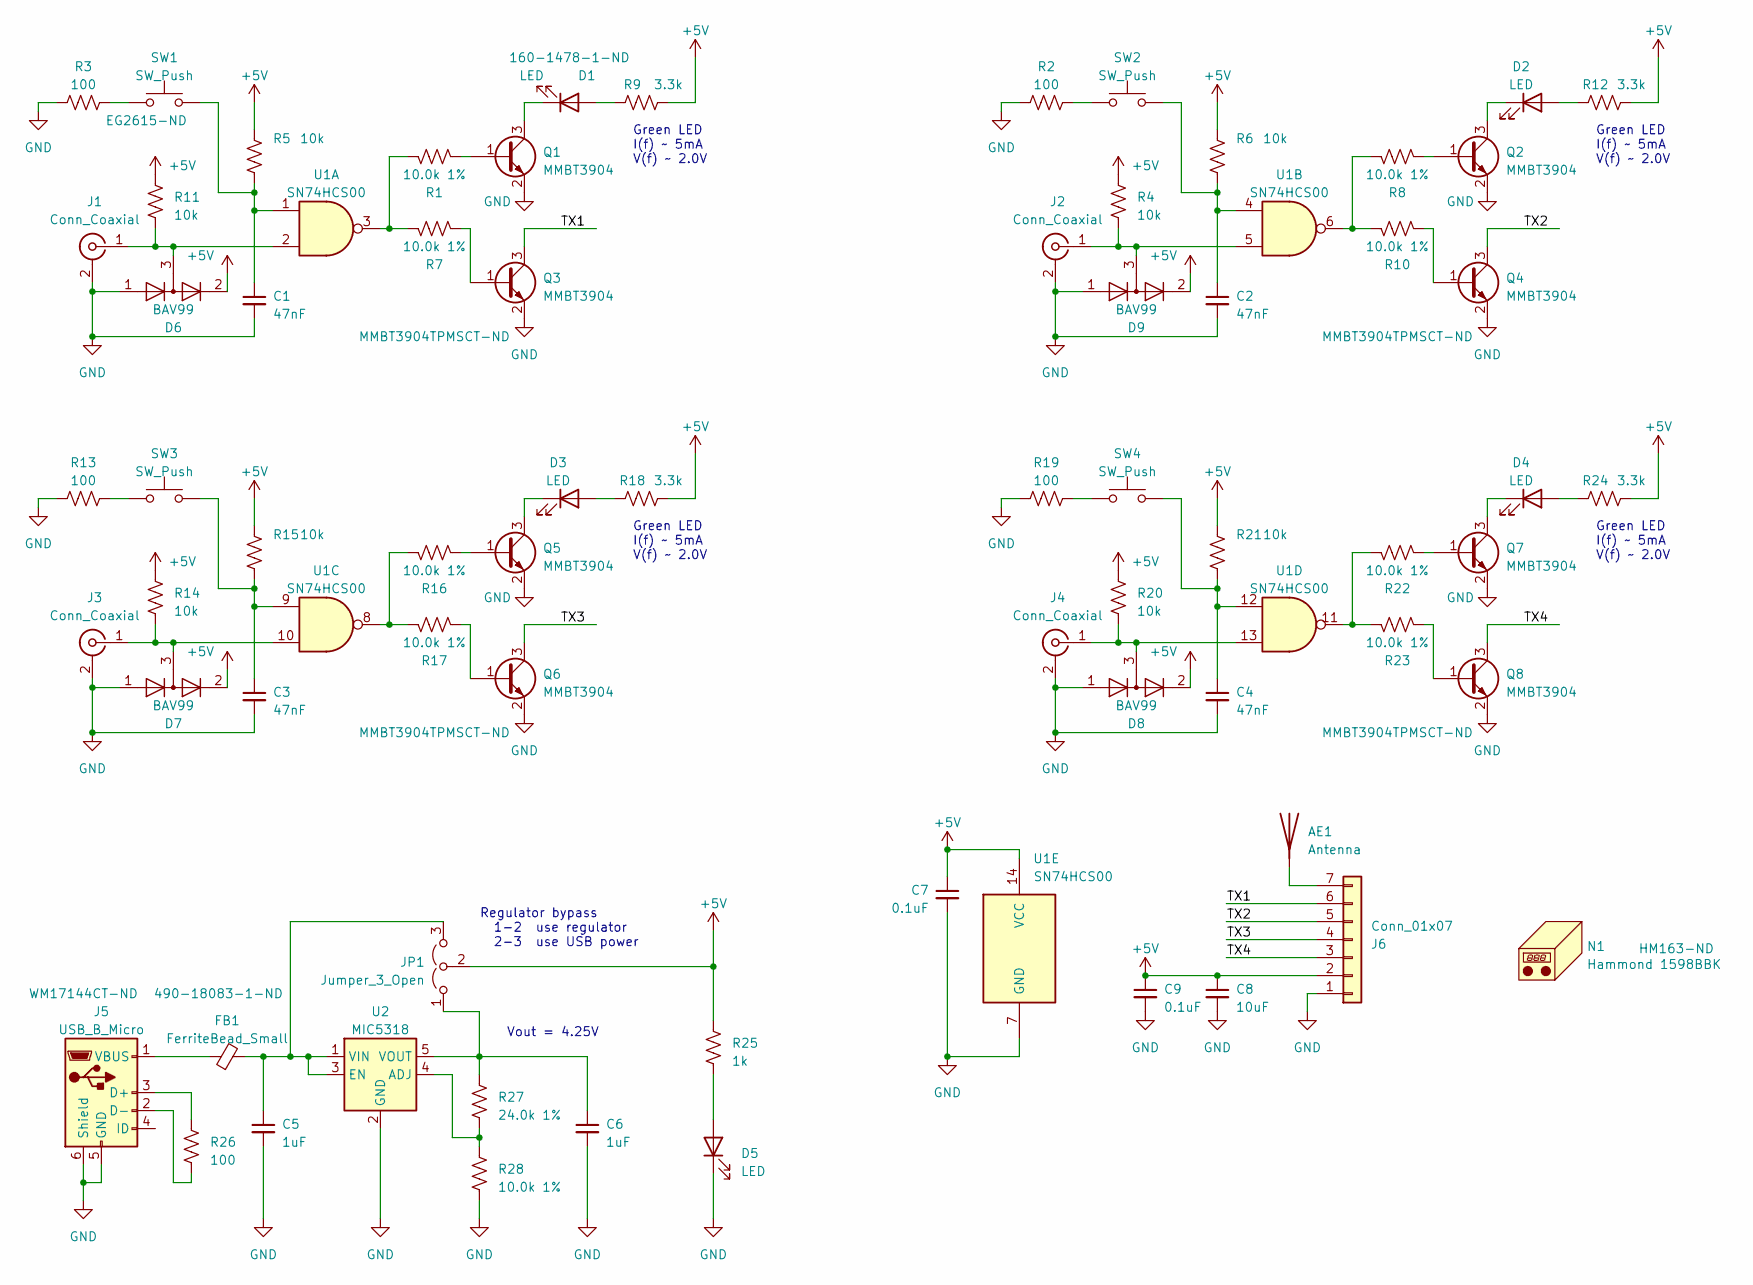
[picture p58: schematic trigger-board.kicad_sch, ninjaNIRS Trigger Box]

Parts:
AE1: Antenna; PinHeader_1x01_P2.54mm_Vertical; Manufacturers P/N -DNP-
C1, C2, C3, C4: 47nF; C_0805_2012Metric_Pad1.18x1.45mm_HandSolder; Manufacturers P/N CL21B473KCCWPNC
C5, C6: 1uF; C_0805_2012Metric_Pad1.18x1.45mm_HandSolder; Manufacturers P/N CL21B105KPFNNNE
C7, C9: 0.1uF; C_0805_2012Metric_Pad1.18x1.45mm_HandSolder; Manufacturers P/N 08053C104KAT2A
C8: 10uF; C_0805_2012Metric_Pad1.18x1.45mm_HandSolder; Manufacturers P/N CL21A106KOQNNNE
D1, D2, D3, D4: LED; LED_0603_marked; Manufacturers P/N 160-1478-1-ND
D5: LED; LED_0603_marked; Manufacturers P/N LTST-S270EKT
D6, D7, D8, D9: BAV99; SOT-23; Manufacturers P/N BAV99,215
FB1: FerriteBead_Small; L_1210_3225Metric_Pad1.42x2.65mm_HandSolder; Manufacturers P/N BLM31KN102BH1L
J1, J2, J3, J4: Conn_Coaxial; BNC_Amphenol_B6252HB-NPP3G-50_Horizontal; Manufacturers P/N RF1-01K-D-00-50-BK-HDW
J5: USB_B_Micro; USB_Micro-AB_Molex_47590-0001; Manufacturers P/N 0475900001
J6: Conn_01x07; PinSocket_1x07_P2.54mm_Horizontal; Manufacturers P/N SSW-107-02-G-S-RA
JP1: Jumper_3_Open; PinHeader_1x03_P2.54mm_Vertical; Manufacturers P/N 61300311121
N1: Hammond 1598BBK; Hammond_1598B; Manufacturers P/N -DNP-
Q1, Q2, Q3, Q4, Q5, Q6, Q7, Q8: MMBT3904; SOT-23; Manufacturers P/N MMBT3904-TP
R1, R7, R8, R10, R16, R17, R22, R23, R28: 10.0k 1%; R_0805_2012Metric_Pad1.20x1.40mm_HandSolder; Manufacturers P/N RNCP0805FTD10K0
R2, R3, R13, R19, R26: 100; R_0805_2012Metric_Pad1.20x1.40mm_HandSolder; Manufacturers P/N RC0805FR-07100RL
R4, R5, R6, R11, R14, R15, R20, R21: 10k; R_0805_2012Metric_Pad1.20x1.40mm_HandSolder; Manufacturers P/N RNCP0805FTD1K00
R9, R12, R18, R24: 3.3k; R_0805_2012Metric_Pad1.20x1.40mm_HandSolder; Manufacturers P/N RC0805FR-073K3L
R25: 1k; R_0805_2012Metric_Pad1.20x1.40mm_HandSolder; Manufacturers P/N RNCP0805FTD1K00
R27: 24.0k 1%; R_0805_2012Metric_Pad1.20x1.40mm_HandSolder; Manufacturers P/N RMCF0805FT24K0
SW1, SW2, SW3, SW4: SW_Push; 800SP9B6M6RE; Manufacturers P/N 800SP9B6M6RE
U1: SN74HCS00; SOIC-14_3.9x8.7mm_P1.27mm; Manufacturers P/N SN74HCS00DR
U2: MIC5318; SOT-23-5_HandSoldering; Manufacturers P/N MIC5318YD5-TR

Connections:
+5V: C7.1, C8.1, C9.1, D6.2 (A), D7.2 (A), D8.2 (A), D9.2 (A), J6.2, JP1.2 (C), R4.2, R5.2, R6.2, R9.1, R11.2, R12.1, R14.2, R15.2, R18.1, R20.2, R21.2, R24.1, R25.1, U1.14 (VCC)
/TX1: J6.6, Q3.3 (C)
/TX2: J6.5, Q4.3 (C)
/TX3: J6.4, Q6.3 (C)
/TX4: J6.3, Q8.3 (C)
GND: C1.2, C2.2, C3.2, C4.2, C5.2, C6.2, C7.2, C8.2, C9.2, D5.1 (K), D6.1 (K), D7.1 (K), D8.1 (K), D9.1 (K), J1.2 (Ext), J2.2 (Ext), J3.2 (Ext), J4.2 (Ext), J5.5 (GND), J5.6 (Shield), J6.1, Q1.2 (E), Q2.2 (E), Q3.2 (E), Q4.2 (E), Q5.2 (E), Q6.2 (E), Q7.2 (E), Q8.2 (E), R2.2, R3.2, R13.2, R19.2, R28.1, U1.7 (GND), U2.2 (GND)
unnamed: AE1.1 (A), J6.7
unnamed: C1.1, R5.1, SW1.2, U1.1
unnamed: C2.1, R6.1, SW2.2, U1.4
unnamed: C3.1, R15.1, SW3.2, U1.9
unnamed: C4.1, R21.1, SW4.2, U1.12
unnamed: D1.2 (A), R9.2
unnamed: D1.1 (K), Q1.3 (C)
unnamed: D2.2 (A), R12.2
unnamed: D2.1 (K), Q2.3 (C)
unnamed: D3.2 (A), R18.2
unnamed: D3.1 (K), Q5.3 (C)
unnamed: D4.2 (A), R24.2
unnamed: D4.1 (K), Q7.3 (C)
unnamed: D5.2 (A), R25.2
unnamed: D6.3 (K), J1.1 (In), R11.1, U1.2
unnamed: D9.3 (K), J2.1 (In), R4.1, U1.5
unnamed: D7.3 (K), J3.1 (In), R14.1, U1.10
unnamed: D8.3 (K), J4.1 (In), R20.1, U1.13
unnamed: J5.3 (D+), R26.2
unnamed: J5.2 (D-), R26.1
unnamed: FB1.1, J5.1 (VBUS)
unnamed: C6.1, JP1.1 (A), R27.2, U2.5 (VOUT)
unnamed: C5.1, FB1.2, JP1.3 (B), U2.1 (VIN), U2.3 (EN)
unnamed: Q1.1 (B), R1.2
unnamed: Q2.1 (B), R8.2
unnamed: Q3.1 (B), R7.2
unnamed: Q4.1 (B), R10.2
unnamed: Q5.1 (B), R16.2
unnamed: Q6.1 (B), R17.2
unnamed: Q7.1 (B), R22.2
unnamed: Q8.1 (B), R23.2
unnamed: R1.1, R7.1, U1.3
unnamed: R2.1, SW2.1
unnamed: R3.1, SW1.1
unnamed: R8.1, R10.1, U1.6
unnamed: R13.1, SW3.1
unnamed: R16.1, R17.1, U1.8
unnamed: R19.1, SW4.1
unnamed: R22.1, R23.1, U1.11
unnamed: R27.1, R28.2, U2.4 (ADJ)

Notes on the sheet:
Vout = 4.25V
Green LED I(f) ~ 5mA V(f) ~ 2.0V
Regulator bypass 1-2 use regulator 2-3 use USB power

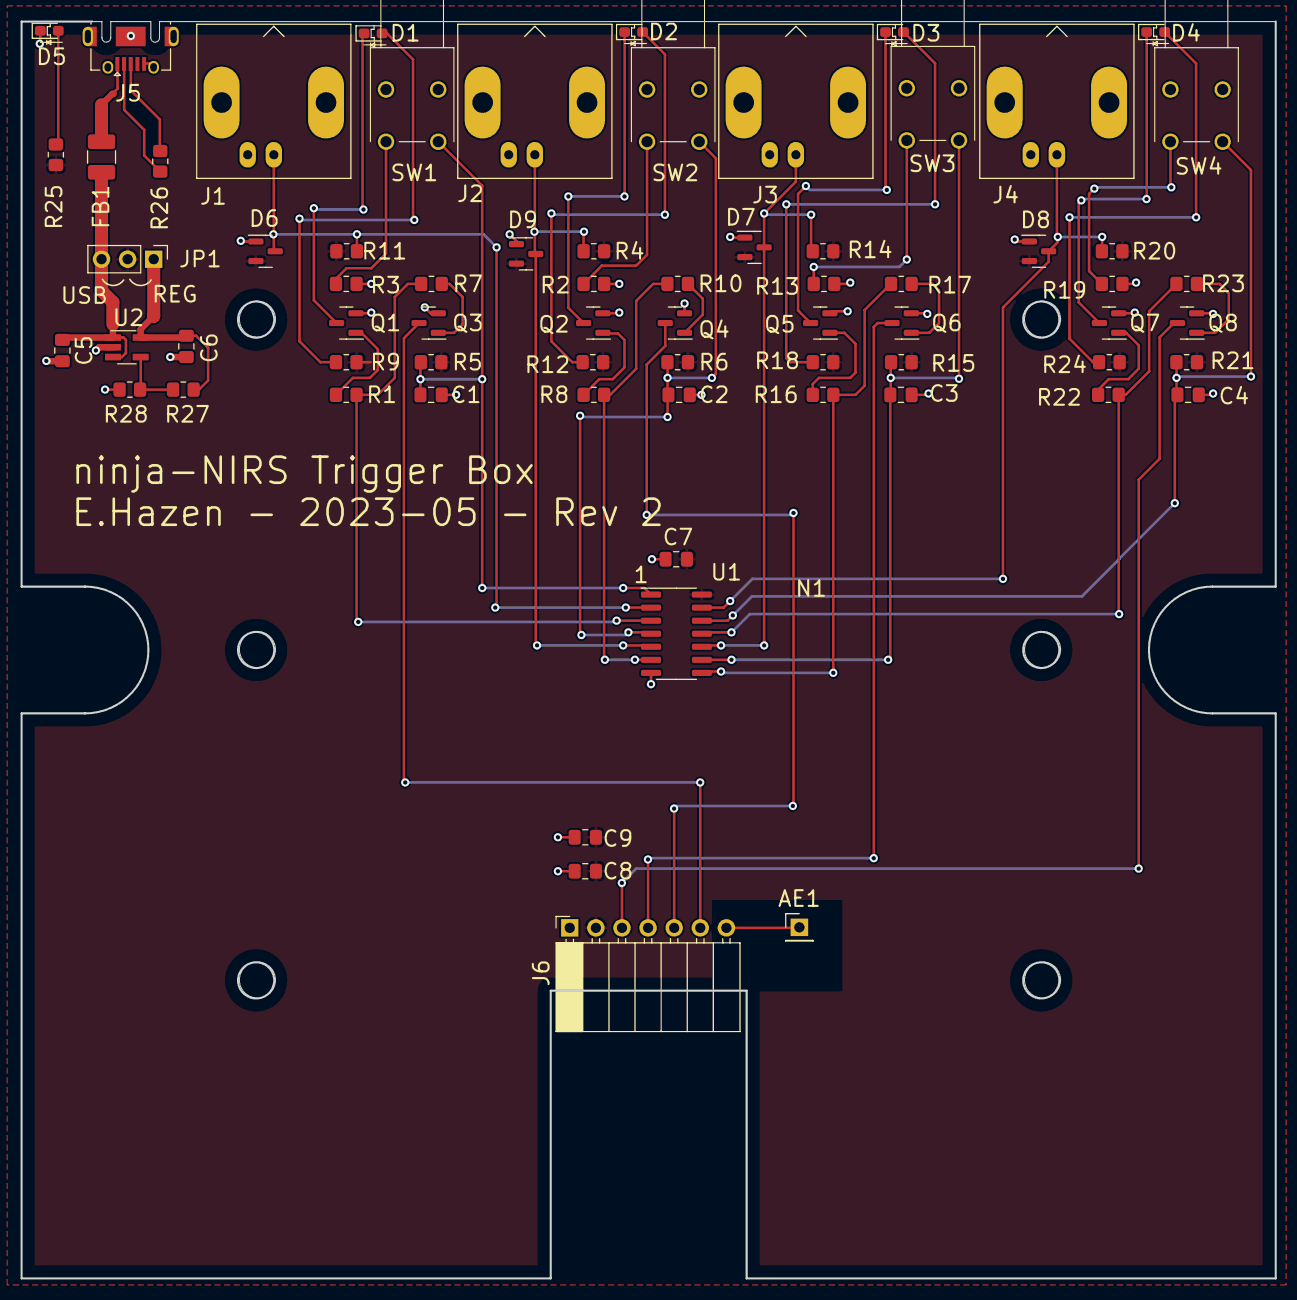
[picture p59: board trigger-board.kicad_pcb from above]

Board: 2 copper layers, 122.0 x 122.3 mm, 70 parts (0 on the bottom side), 46 nets.

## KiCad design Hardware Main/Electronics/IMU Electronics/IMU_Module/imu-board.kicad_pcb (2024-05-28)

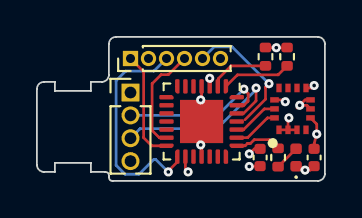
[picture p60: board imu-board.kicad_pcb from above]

Board: 4 copper layers, 16.0 x 8.0 mm, 10 parts (0 on the bottom side), 14 nets.

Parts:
C1, C2: C_Small; C_0402_1005Metric
D1: LED; LED_0402_1005Metric
J1: Conn_01x04; PinHeader_1x04_P1.27mm_Vertical
J3: AVR-ISP-6; PinHeader_1x06_P1.00mm_Vertical
JP1, JP2: JPR2; R_0402_1005Metric
R1: R_US; R_0402_1005Metric
U2: ISM330DHCX; LGA-14L
U3: ATmega168A-MM; QFN-28-1EP_4x4mm_P0.45mm_EP2.4x2.4mm

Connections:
/MISO: J3.1 (MISO), U3.14 (PB4)
/MOSI: J3.4 (MOSI), U3.13 (PB3)
/RXD: J1.3, U3.26 (PD0)
/SCK: J3.3 (SCK), U3.15 (PB5)
/SCL: U2.P13 (SCL), U3.24 (PC5)
/SDA: U2.P14 (SDA/SDI/SDO), U3.23 (PC4)
/TXD: J1.2, U3.27 (PD1)
/nRESET: J3.5 (~RST), U3.25 (~RESET/PC6)
GND: C1.2, C2.2, D1.1 (K), J1.4, J3.6 (GND), JP1.2 (B), JP2.2 (B), U2.P1 (SDO/SA0), U2.P2 (SDX), U2.P3 (SCX), U2.P6 (GND@6), U2.P7 (GND@7), U3.4 (GND), U3.18 (GND), U3.29 (GND)
unnamed: D1.2 (A), R1.2
unnamed: JP1.1 (A), U3.2 (PD4)
unnamed: JP2.1 (A), U3.1 (PD3)
unnamed: R1.1, U3.22 (PC3)
VCC: C1.1, C2.1, J1.1, J3.2 (VCC), U2.P5 (VDD_IO), U2.P8 (VDD), U2.P12 (~CS), U3.3 (VCC), U3.16 (AVCC)

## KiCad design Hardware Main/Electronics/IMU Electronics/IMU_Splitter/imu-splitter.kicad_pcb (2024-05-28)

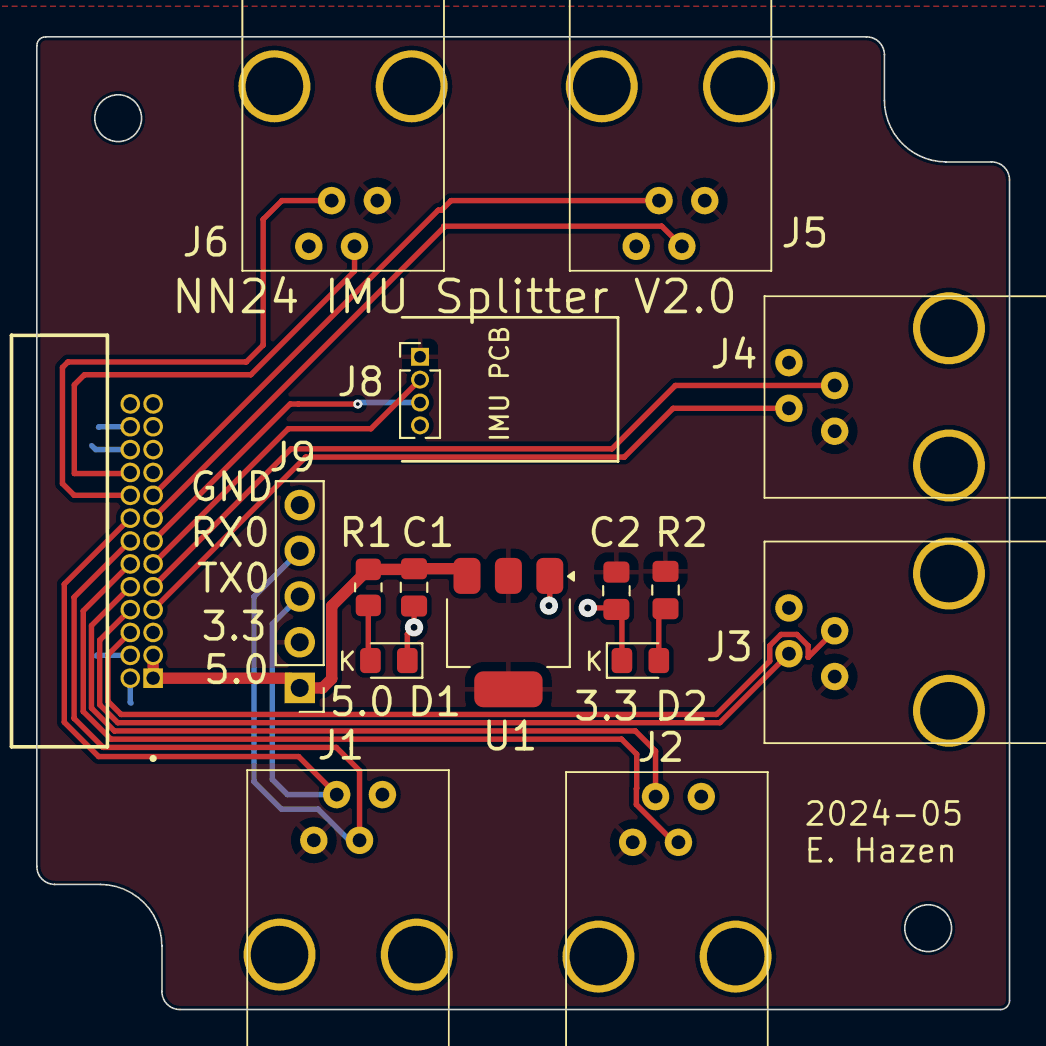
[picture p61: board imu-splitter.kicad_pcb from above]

Board: 2 copper layers, 54.0 x 54.0 mm, 16 parts (0 on the bottom side), 19 nets.

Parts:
C1: 10uF; C_0805_2012Metric_Pad1.18x1.45mm_HandSolder
C2: 22uF; C_0805_2012Metric_Pad1.18x1.45mm_HandSolder
D1, D2: LED; LED_0805_2012Metric_Pad1.15x1.40mm_HandSolder
J1, J2, J3, J4, J5, J6: 4P4C; A-2004-3-4-LP
J7: 3220-26-0200-00; SAMTEC_SHF-113-01-L-D-RA
J8: Conn_01x04; PinHeader_1x04_P1.27mm_Vertical
J9: Conn_01x05; PinHeader_1x05_P2.54mm_Vertical
R1: 1.5k; R_0805_2012Metric_Pad1.20x1.40mm_HandSolder
R2: 510; C_0805_2012Metric_Pad1.18x1.45mm_HandSolder
U1: AP2114H-3.3TRG1; SOT-223-3_TabPin2

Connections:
+3.3V: C2.1, J1.1, J2.1, J3.1, J4.1, J5.1, J6.1, J8.1, J9.2, R2.1, U1.2 (VO)
+5V: C1.1, J7.1, J7.3, J9.1, R1.1, U1.3 (VI)
/RX0: J1.3, J7.14, J9.4
/RX1: J2.3, J7.12
/RX2: J3.3, J7.6
/RX3: J4.3, J7.9
/RX4: J5.3, J7.17
/RX5: J6.3, J7.18
/RX6: J7.13, J8.3
/TX0: J1.2, J7.16, J9.3
/TX1: J2.2, J7.10
/TX2: J3.2, J7.8
/TX3: J4.2, J7.7
/TX4: J5.2, J7.15
/TX5: J6.2, J7.20
/TX6: J7.11, J8.2
GND: C1.2, C2.2, D1.1 (K), D2.1 (K), J1.4, J2.4, J3.4, J4.4, J5.4, J6.4, J7.2, J7.4, J7.22, J7.24, J8.4, J9.5, U1.1 (GND)
unnamed: D1.2 (A), R1.2
unnamed: D2.2 (A), R2.2

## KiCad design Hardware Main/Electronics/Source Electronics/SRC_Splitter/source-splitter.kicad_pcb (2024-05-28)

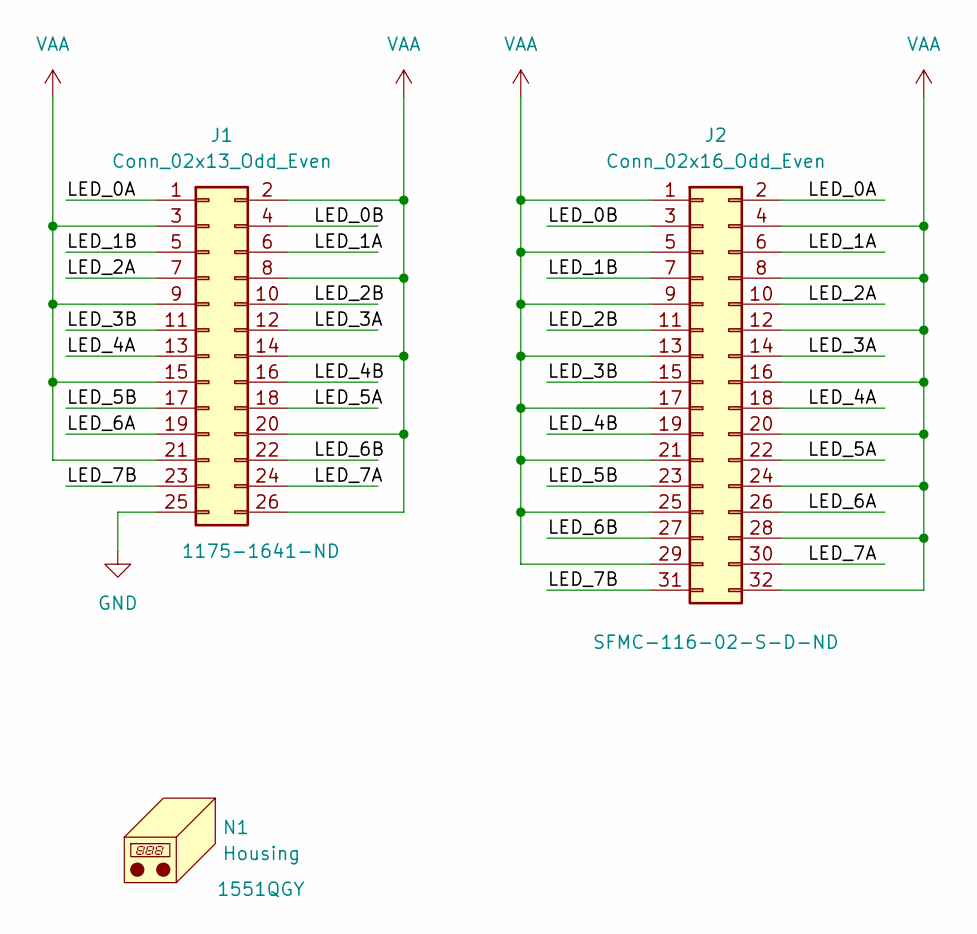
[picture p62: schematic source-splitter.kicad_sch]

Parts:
J1: Conn_02x13_Odd_Even; SAMTEC_SHF-113-01-L-D-SM
J2: Conn_02x16_Odd_Even; SAMTEC_SFMC-116-02-S-D_swap12
N1: Housing; 1551QGY

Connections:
/LED_0A: J1.1, J2.2
/LED_0B: J1.4, J2.3
/LED_1A: J1.6, J2.6
/LED_1B: J1.5, J2.7
/LED_2A: J1.7, J2.10
/LED_2B: J1.10, J2.11
/LED_3A: J1.12, J2.14
/LED_3B: J1.11, J2.15
/LED_4A: J1.13, J2.18
/LED_4B: J1.16, J2.19
/LED_5A: J1.18, J2.22
/LED_5B: J1.17, J2.23
/LED_6A: J1.19, J2.26
/LED_6B: J1.22, J2.27
/LED_7A: J1.24, J2.30
/LED_7B: J1.23, J2.31
GND: J1.25
VAA: J1.2, J1.3, J1.8, J1.9, J1.14, J1.15, J1.20, J1.21, J1.26, J2.1, J2.4, J2.5, J2.8, J2.9, J2.12, J2.13, J2.16, J2.17, J2.20, J2.21, J2.24, J2.25, J2.28, J2.29, J2.32

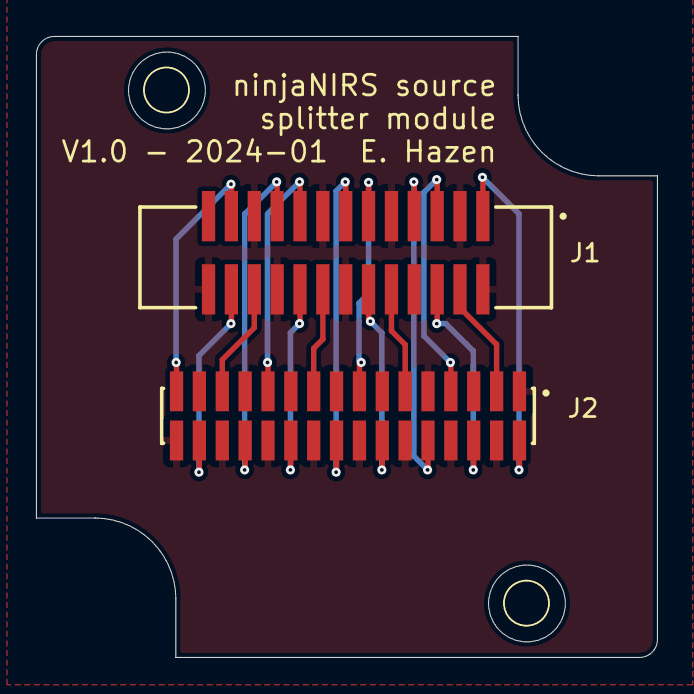
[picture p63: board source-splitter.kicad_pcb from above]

Board: 2 copper layers, 34.5 x 34.5 mm, 3 parts (0 on the bottom side), 17 nets.

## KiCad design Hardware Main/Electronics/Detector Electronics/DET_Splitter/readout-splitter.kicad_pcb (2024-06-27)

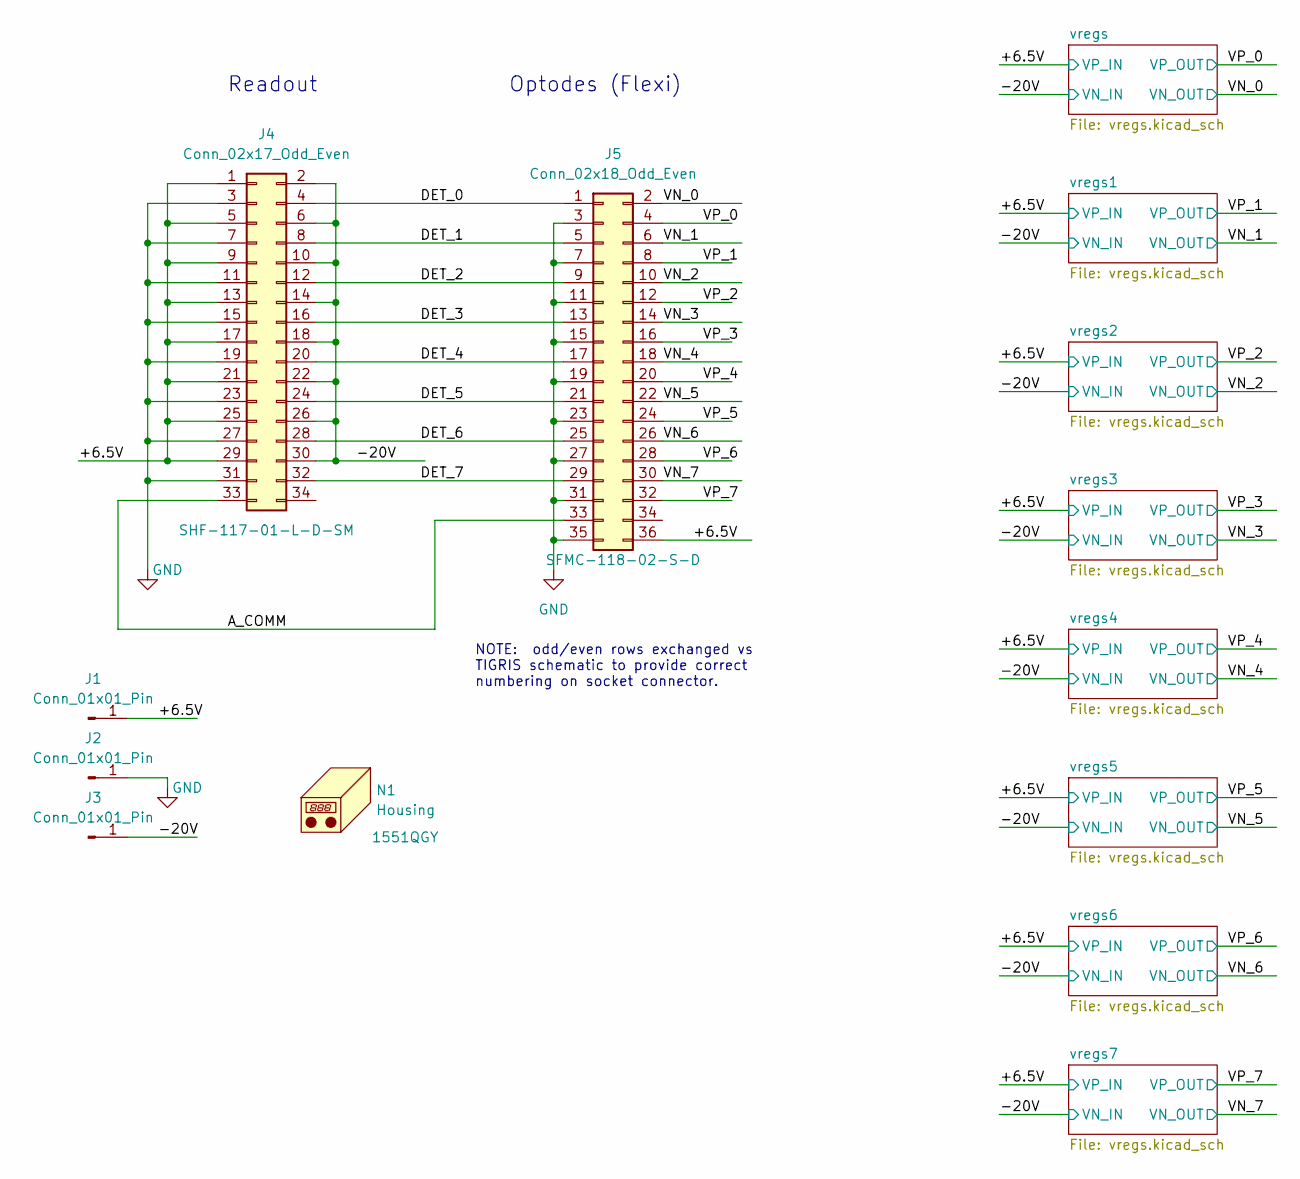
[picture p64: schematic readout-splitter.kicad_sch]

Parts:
J1, J2, J3: Conn_01x01_Pin; TestPoint_THTPad_1.0x1.0mm_Drill0.5mm
J4: Conn_02x17_Odd_Even; SHF-117-01-X-D-SM
J5: Conn_02x18_Odd_Even; SAMTEC_SFMC-118-02-L-D
N1: Housing; 1551QGY

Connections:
/+6.5V: J1.1, J4.1, J4.5, J4.9, J4.13, J4.17, J4.21, J4.25, J4.29, J5.36; also elsewhere on the board
/-20V: J3.1, J4.2, J4.6, J4.10, J4.14, J4.18, J4.22, J4.26, J4.30; also elsewhere on the board
/A_COMM: J4.33, J5.33
/DET_0: J4.4, J5.1
/DET_1: J4.8, J5.5
/DET_2: J4.12, J5.9
/DET_3: J4.16, J5.13
/DET_4: J4.20, J5.17
/DET_5: J4.24, J5.21
/DET_6: J4.28, J5.25
/DET_7: J4.32, J5.29
/VN_0: J5.2; also elsewhere on the board
/VN_1: J5.6; also elsewhere on the board
/VN_2: J5.10; also elsewhere on the board
/VN_3: J5.14; also elsewhere on the board
/VN_4: J5.18; also elsewhere on the board
/VN_5: J5.22; also elsewhere on the board
/VN_6: J5.26; also elsewhere on the board
/VN_7: J5.30; also elsewhere on the board
/VP_0: J5.4; also elsewhere on the board
/VP_1: J5.8; also elsewhere on the board
/VP_2: J5.12; also elsewhere on the board
/VP_3: J5.16; also elsewhere on the board
/VP_4: J5.20; also elsewhere on the board
/VP_5: J5.24; also elsewhere on the board
/VP_6: J5.28; also elsewhere on the board
/VP_7: J5.32; also elsewhere on the board
GND: J2.1, J4.3, J4.7, J4.11, J4.15, J4.19, J4.23, J4.27, J4.31, J5.3, J5.7, J5.11, J5.15, J5.19, J5.23, J5.27, J5.31, J5.35; also elsewhere on the board

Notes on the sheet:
NOTE: odd/even rows exchanged vs TIGRIS schematic to provide correct numbering on socket connector.
Optodes (Flexi)
Readout

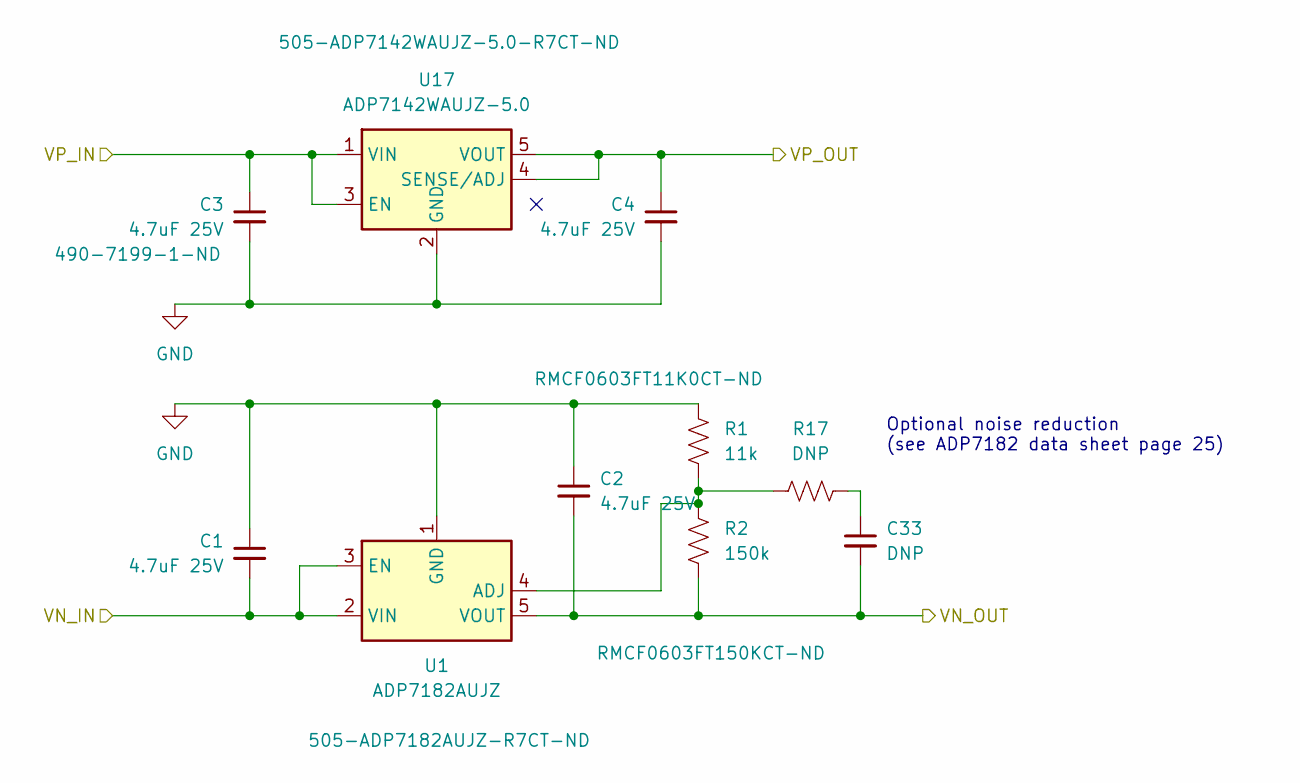
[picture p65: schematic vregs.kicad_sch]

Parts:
C1, C2, C3, C4: 4.7uF 25V; C_0603_1608Metric
C33: DNP; C_0603_1608Metric
R1: 11k; R_0603_1608Metric
R2: 150k; R_0603_1608Metric
R17: DNP; R_0603_1608Metric
U1: ADP7182AUJZ; TSOT-23-5
U17: ADP7142WAUJZ-5.0; TSOT-23-5

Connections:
/+6.5V: C3.1, U17.1 (VIN), U17.3 (EN); also elsewhere on the board
/-20V: C1.2, U1.2 (VIN), U1.3 (EN); also elsewhere on the board
/VN_0: C2.2, C33.2, R2.2, U1.5 (VOUT); also elsewhere on the board
/VP_0: C4.1, U17.4 (SENSE/ADJ), U17.5 (VOUT); also elsewhere on the board
GND: C1.1, C2.1, C3.2, C4.2, R1.1, U1.1 (GND), U17.2 (GND); also elsewhere on the board
unnamed: C33.1, R17.2
unnamed: R1.2, R2.1, R17.1, U1.4 (ADJ)

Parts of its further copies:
C5, C6, C7, C8, C9, C10, C11, C12, C13, C14, C15, C16, C17, C18, C19, C20, C21, C22, C23, C24, C25, C26, C27, C28, C29, C30, C31, C32: 4.7uF 25V; C_0603_1608Metric
C34, C35, C36, C37, C38, C39, C40: DNP; C_0603_1608Metric
R3, R5, R7, R9, R11, R13, R15: 11k; R_0603_1608Metric
R4, R6, R8, R10, R12, R14, R16: 150k; R_0603_1608Metric
R18, R19, R20, R21, R22, R23, R24: DNP; R_0603_1608Metric
U2, U3, U4, U5, U6, U7, U8: ADP7182AUJZ; TSOT-23-5
U18, U19, U20, U21, U22, U23, U24: ADP7142WAUJZ-5.0; TSOT-23-5

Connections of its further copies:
/+6.5V: C5.1, C9.1, C13.1, C17.1, C21.1, C25.1, C29.1, U18.1 (VIN), U18.3 (EN), U19.1 (VIN), U19.3 (EN), U20.1 (VIN), U20.3 (EN), U21.1 (VIN), U21.3 (EN), U22.1 (VIN), U22.3 (EN), U23.1 (VIN), U23.3 (EN), U24.1 (VIN), U24.3 (EN); also elsewhere on the board
/-20V: C6.2, C10.2, C14.2, C18.2, C22.2, C26.2, C30.2, U2.2 (VIN), U2.3 (EN), U3.2 (VIN), U3.3 (EN), U4.2 (VIN), U4.3 (EN), U5.2 (VIN), U5.3 (EN), U6.2 (VIN), U6.3 (EN), U7.2 (VIN), U7.3 (EN), U8.2 (VIN), U8.3 (EN); also elsewhere on the board
/VN_1: C7.2, C34.2, R4.2, U2.5 (VOUT); also elsewhere on the board
/VN_2: C11.2, C35.2, R6.2, U3.5 (VOUT); also elsewhere on the board
/VN_3: C15.2, C36.2, R8.2, U4.5 (VOUT); also elsewhere on the board
/VN_4: C19.2, C37.2, R10.2, U5.5 (VOUT); also elsewhere on the board
/VN_5: C23.2, C38.2, R12.2, U6.5 (VOUT); also elsewhere on the board
/VN_6: C27.2, C39.2, R14.2, U7.5 (VOUT); also elsewhere on the board
/VN_7: C31.2, C40.2, R16.2, U8.5 (VOUT); also elsewhere on the board
/VP_1: C8.1, U18.4 (SENSE/ADJ), U18.5 (VOUT); also elsewhere on the board
/VP_2: C12.1, U19.4 (SENSE/ADJ), U19.5 (VOUT); also elsewhere on the board
/VP_3: C16.1, U20.4 (SENSE/ADJ), U20.5 (VOUT); also elsewhere on the board
/VP_4: C20.1, U21.4 (SENSE/ADJ), U21.5 (VOUT); also elsewhere on the board
/VP_5: C24.1, U22.4 (SENSE/ADJ), U22.5 (VOUT); also elsewhere on the board
/VP_6: C28.1, U23.4 (SENSE/ADJ), U23.5 (VOUT); also elsewhere on the board
/VP_7: C32.1, U24.4 (SENSE/ADJ), U24.5 (VOUT); also elsewhere on the board
GND: C5.2, C6.1, C7.1, C8.2, C9.2, C10.1, C11.1, C12.2, C13.2, C14.1, C15.1, C16.2, C17.2, C18.1, C19.1, C20.2, C21.2, C22.1, C23.1, C24.2, C25.2, C26.1, C27.1, C28.2, C29.2, C30.1, C31.1, C32.2, R3.1, R5.1, R7.1, R9.1, R11.1, R13.1, R15.1, U2.1 (GND), U3.1 (GND), U4.1 (GND), U5.1 (GND), U6.1 (GND), U7.1 (GND), U8.1 (GND), U18.2 (GND), U19.2 (GND), U20.2 (GND), U21.2 (GND), U22.2 (GND), U23.2 (GND), U24.2 (GND); also elsewhere on the board
unnamed: C34.1, R18.2
unnamed: C35.1, R19.2
unnamed: C36.1, R20.2
unnamed: C37.1, R21.2
unnamed: C38.1, R22.2
unnamed: C39.1, R23.2
unnamed: C40.1, R24.2
unnamed: R3.2, R4.1, R18.1, U2.4 (ADJ)
unnamed: R5.2, R6.1, R19.1, U3.4 (ADJ)
unnamed: R7.2, R8.1, R20.1, U4.4 (ADJ)
unnamed: R9.2, R10.1, R21.1, U5.4 (ADJ)
unnamed: R11.2, R12.1, R22.1, U6.4 (ADJ)
unnamed: R13.2, R14.1, R23.1, U7.4 (ADJ)
unnamed: R15.2, R16.1, R24.1, U8.4 (ADJ)

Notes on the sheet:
Optional noise reduction (see ADP7182 data sheet page 25)

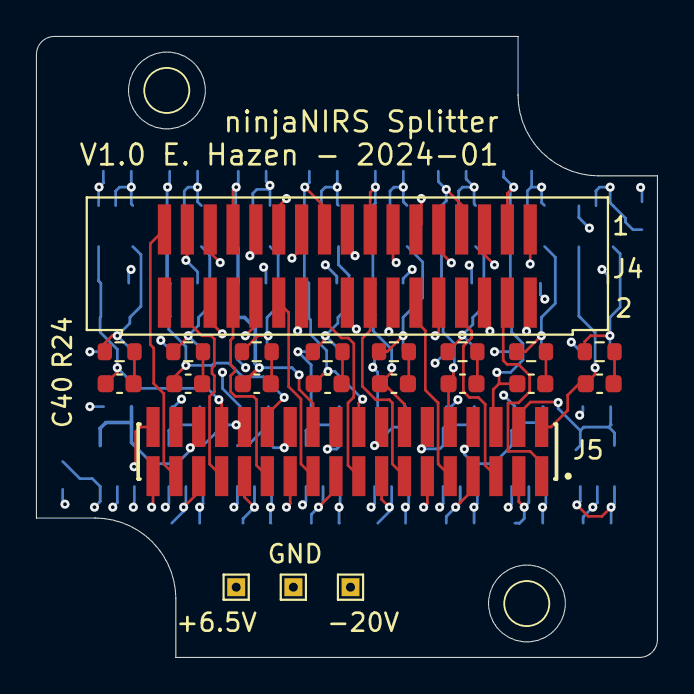
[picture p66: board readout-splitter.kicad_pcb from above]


Board: 4 copper layers, 34.5 x 34.5 mm, 86 parts (64 on the bottom side), 44 nets.

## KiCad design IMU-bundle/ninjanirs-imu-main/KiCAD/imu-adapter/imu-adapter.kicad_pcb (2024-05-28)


Board: 2 copper layers, 29.0 x 21.0 mm, 4 parts (0 on the bottom side), 6 nets.

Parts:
H1, H2: MountingHole; MountingHole_2.5mm_Pad
J1: 2x3_0.1in; PinHeader_2x03_P2.54mm_Vertical
J2: 1mm_SIP; PinHeader_1x06_P1.00mm_Vertical

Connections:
unnamed: J1.6 (GND), J2.6 (GND)
unnamed: J1.1 (MISO), J2.1 (MISO)
unnamed: J1.4 (MOSI), J2.4 (MOSI)
unnamed: J1.3 (SCK), J2.3 (SCK)
unnamed: J1.2 (VCC), J2.2 (VCC)
unnamed: J1.5 (~RST), J2.5 (~RST)

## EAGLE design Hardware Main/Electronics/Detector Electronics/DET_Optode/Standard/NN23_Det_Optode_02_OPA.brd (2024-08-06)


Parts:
C1, C2: 0.1u; 0402-CAP
C3: DNP; 0402-CAP
PD1: VEMD5060
R1: 330M; 0402-RES
R2: 47; 0402-RES
TP1, TP2, TP3, TP4: TESTPOINTPADSMALL; TESTPAD_SMALL
U1: OPA810; SOT353

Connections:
GND: C1.2, C2.2, PD1.C1 (C), PD1.C2 (C), TP3.P$1, U1.3 (+IN)
unnamed: C3.2, R1.2, R2.1, U1.1 (OUT)
unnamed: C3.1, PD1.A, R1.1, U1.4 (-IN)
OUT: R2.2, TP2.P$1
V6P5: C2.1, TP1.P$1, U1.5 (V+)
VN20: C1.1, TP4.P$1, U1.2 (V-)

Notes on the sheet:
VEMD5160 (IR pass)
BU Neurophotonics Center bzim@bu.edu 2023


Board: 2 copper layers, 8.9 x 8.9 mm, 11 parts (1 on the bottom side), 6 nets.

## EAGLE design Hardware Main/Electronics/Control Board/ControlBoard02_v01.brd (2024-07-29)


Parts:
C101: 0.1u; 0402-CAP
D101: D1213A-02SO; SOT23-6
F101: 0ZCM0010FF2G; 0603-RES
J101: M20X2_PTH
J102, J103: M04X1_JST_SH_RA; M04X1_JST_SH_SM_RA
LED101: LTST-C191KRKT; LED-0603
LED102: LTST-C191KGKT; LED-0603
R101, R102, R103: 10k; 0402-RES
R104, R105: 470; 0402-RES
S101: SWITCH-MOMENTARY-2SMD-3; TACTILE_SWITCH_SMD-3

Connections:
GND: C101.2, D101.2 (VN), J101.1, J101.8, J101.12, J101.15, J101.22, J101.28, J101.31, J101.36, J102.1, J103.1, LED101.C, LED102.C, S101.1; also elsewhere on the board
unnamed: LED101.A, R104.1
unnamed: LED102.A, R105.1
RPI0_BUZZ: J101.7; also elsewhere on the board
RPI0_CE: J101.18; also elsewhere on the board
RPI0_GPIO5: J101.11; also elsewhere on the board
RPI0_GPIO6: J101.9; also elsewhere on the board
RPI0_GPIO7: J101.16; also elsewhere on the board
RPI0_GPIO12: J101.10; also elsewhere on the board
RPI0_GPIO16: J101.6; also elsewhere on the board
RPI0_GPIO18: J101.30; also elsewhere on the board
RPI0_GPIO19: J101.5; also elsewhere on the board
RPI0_GPIO20: J101.4; also elsewhere on the board
RPI0_GPIO21: J101.2; also elsewhere on the board
RPI0_GPIO22: J101.25; also elsewhere on the board
RPI0_GPIO24: J101.24; also elsewhere on the board
RPI0_GPIO25: J101.20; also elsewhere on the board
RPI0_GPIO26: J101.3; also elsewhere on the board
RPI0_GPIO27: J101.27, R103.1, S101.4 (2); also elsewhere on the board
RPI0_LED0: J101.29, R104.2
RPI0_LED1: J101.33, R105.2
RPI0_MISO: J101.19; also elsewhere on the board
RPI0_MOSI: J101.21; also elsewhere on the board
RPI0_RX0: J101.32; also elsewhere on the board
RPI0_SCL: D101.3 (CH1), J101.35, J102.4, J103.4, R102.1; also elsewhere on the board
RPI0_SCLK: J101.17; also elsewhere on the board
RPI0_SDA: D101.4 (CH2), J101.37, J102.3, J103.3, R101.1; also elsewhere on the board
RPI0_TX0: J101.34; also elsewhere on the board
RPI0_V3P3: F101.2, J101.23, J101.39, R103.2
V3P3_J102: C101.1, D101.6 (VP), F101.1, J102.2, J103.2, R101.2, R102.2
V5P1_RPI: J101.38, J101.40; also elsewhere on the board

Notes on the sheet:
GPIO15
GPIO14
RPI0_SWDIO
RPI0_SWCLK
GPIO8
GPIO11
GPIO9
GPIO10
GPIO2
GPIO3
GPIO13
RPi Zero 2 W
RPi Zero header mount Pi upside down
RPi0 Qwiic
GPIO23
Button
To spare connector J601 page 6
To FPGA U301 page 3
To RP2040 U201 page 2


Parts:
C201, C202, C203, C204, C207: 0.1u; 0402-CAP
C205, C206: 27p; 0402-CAP
D201, D202, D204: D1213A-02SO; SOT23-6
D203: DIODE_SOD523; SOD523
F201, F202, F203: 0ZCM0010FF2G; 0603-RES
J201, J202: M04X1_JST_SH_RA; M04X1_JST_SH_SM_RA
J203: USB-MICRO
J204, J205: M04X2_0.050_SMD_NO_CREAM
J206, J207: M03POLAR; MOLEX-1X3
LED201: LTST-C191KRKT; LED-0603
LED202, LED203: LTST-C191KGKT; LED-0603
Q201: MOSFET-NCHANNELSMD; SOT23-3
R201: 1k; 0402-RES
R202, R212, R214: DNP; 0402-RES
R203, R204, R207, R208, R210, R218: 10k; 0402-RES
R205, R217, R221: 100k; 0402-RES
R206: 47k; 0402-RES
R209, R211: 27; 0402-RES
R213: 1.2k; 0402-RES
R215, R216, R219, R220, R222: 470; 0402-RES
S201, S202: SWITCH-MOMENTARY-2SMD-3; TACTILE_SWITCH_SMD-3
TP201, TP202: TESTPOINT_ROUND; TESTPAD_ROUND
U201: RP2040; QFN-56_EP
U202: W25Q_USON; USON8L-2X3MM
X201: 403I35D12M00000; CRYSTAL-3.2-2.5

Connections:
BOOTSEL: R201.1, S201.4 (2)
FAN_NEW: R222.1, U201.36 (GPIO24)
FAN_SENSE: D204.4 (CH2), R220.1, U201.37 (GPIO25)
GND: C201.2, C202.2, C203.2, C204.2, C205.2, C206.2, C207.2, D201.2 (VN), D202.2 (VN), D204.2 (VN), J201.1, J202.1, J203.5, J203.SH1, J203.SH2, J203.SH3, J203.SH4, J203.SH5, J203.SH6, J204.1, J204.3, J204.5, J204.7, J205.1, J205.3, J205.5, J205.7, J207.2, LED201.C, LED202.C, LED203.C, Q201.2 (S), R210.1, R217.1, R218.1, S201.1, U201.19 (TESTEN), U202.4 (GND), X201.2 (GND), X201.4 (GND); also elsewhere on the board
unnamed: C206.1, U201.20 (XIN), X201.3 (C2)
unnamed: C205.1, R213.2, X201.1 (C1)
unnamed: R213.1, U201.21 (XOUT)
unnamed: R209.1, U201.47 (USB_DP)
unnamed: R211.1, U201.46 (USB_DN)
unnamed: J203.2, R211.2
unnamed: J203.3, R209.2
unnamed: LED203.A, R219.1
unnamed: J206.3, R220.2, R221.1
unnamed: LED202.A, R216.1
unnamed: LED201.A, R215.1
unnamed: D203.A, J206.1, Q201.3 (D)
unnamed: Q201.1 (G), R217.2, R222.2
QSPI_SCLK: U201.52 (QSPI_SCLK), U202.6 (CLK)
QSPI_SD0: U201.53 (QSPI_SD0), U202.5 (DI/IO[0])
QSPI_SD1: U201.55 (QSPI_SD1), U202.2 (DO/IO[1])
QSPI_SD2: U201.54 (QSPI_SD2), U202.3 (#WP/IO[2])
QSPI_SD3: U201.51 (QSPI_SD3), U202.7 (#HOLD/IO[3])
QSPI_SS_N: R201.2, R202.1, U201.56 (QSPI_SS_N), U202.1 (/CS)
RPFP_D0: J205.2, U201.15 (GPIO12); also elsewhere on the board
RPFP_D1: J205.4, U201.16 (GPIO13); also elsewhere on the board
RPFP_D2: J205.6, U201.17 (GPIO14); also elsewhere on the board
RPFP_D3: J205.8, U201.18 (GPIO15); also elsewhere on the board
RPFP_D4: U201.27 (GPIO16); also elsewhere on the board
RPFP_D5: U201.28 (GPIO17); also elsewhere on the board
RPFP_D6: U201.29 (GPIO18); also elsewhere on the board
RPFP_D7: U201.30 (GPIO19); also elsewhere on the board
RPFP_D8: J204.2, U201.31 (GPIO20); also elsewhere on the board
RPFP_D9: J204.4, U201.32 (GPIO21); also elsewhere on the board
RPFP_D10: J204.6, U201.34 (GPIO22); also elsewhere on the board
RPFP_D11: J204.8, U201.35 (GPIO23); also elsewhere on the board
RPFP_RUN: R205.1, TP201.P$1, U201.26 (RUN); also elsewhere on the board
RPI0_GPIO18: U201.4 (GPIO02); also elsewhere on the board
RPI0_GPIO24: R212.1; also elsewhere on the board
RPI0_GPIO25: R214.1; also elsewhere on the board
RPI0_RX0: U201.2 (GPIO00); also elsewhere on the board
RPI0_TX0: U201.3 (GPIO01); also elsewhere on the board
RPIP_AUXIO0: U201.41 (GPIO29/ADC3); also elsewhere on the board
RPIP_AUXIO1: U201.39 (GPIO27/ADC1); also elsewhere on the board
RPIP_BTN: R218.2, S202.1, U201.8 (GPIO06)
RPIP_BUZZ: U201.9 (GPIO07); also elsewhere on the board
RPIP_LED0: R215.2, U201.7 (GPIO05)
RPIP_LED1: R216.2, U201.6 (GPIO04)
RPIP_LED2: R219.2, U201.5 (GPIO03)
RPIP_SCL0: D201.3 (CH1), J201.4, R204.1, U201.12 (GPIO09)
RPIP_SCL1: D202.3 (CH1), J202.4, R208.1, U201.14 (GPIO11); also elsewhere on the board
RPIP_SDA0: D201.4 (CH2), J201.3, R203.1, U201.11 (GPIO08)
RPIP_SDA1: D202.4 (CH2), J202.3, R207.1, U201.13 (GPIO10); also elsewhere on the board
SWCLK: J207.3, R214.2, U201.24 (SWCLK)
SWDIO: J207.1, R212.2, U201.25 (SWDIO)
V3P3: C202.1, D201.6 (VP), D202.6 (VP), D204.6 (VP), F201.1, F202.1, R202.2, R203.2, R204.2, R205.2, R207.2, R208.2, R221.2, S202.4 (2), U202.8 (VCC); also elsewhere on the board
V3P3_J201: C201.1, F201.2, J201.2
V3P3_J202: C203.1, F202.2, J202.2
V12: F203.1, R206.2; also elsewhere on the board
V12_CURR_SENSE: U201.38 (GPIO26/ADC0); also elsewhere on the board
V12_FAN: C207.1, D203.C, F203.2, J206.2
VBUS: J203.1, TP202.P$1
VIN_SENSE: C204.1, D204.3 (CH1), R206.1, R210.2, U201.40 (GPIO28/ADC2)

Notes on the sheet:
BOOTSEL (force USB boot)
CTS-Frequency Controls 403I35D12M00000
RP2040 MCU (RPi Pico)
RPiP Qwiic0
RPiP Qwiic1
Debug
To RPi 0 J101 page 1
To FPGA U301 page 3
To Aux Coax J505 page 5
MISO
SCLK
MOSI
UART_ACC_TO_FPGA
UART_FPGA_TO_ACC
ACC_BOARD_SELECT
ACC_END_CYC
ACC_STATUS_SELECT
ACC_RUN_IND


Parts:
C301: 0.1u; 0402-CAP
J301: M04X2_0.050_SMD_NO_CREAM
J302: M03X2PTH; 2X3-NS
J303, J304: M05X2_SMD_0.050_NOCREAM; M05X2_0.050_SMD_NO_CREAM
LED301, LED303, LED305: LTST-C191KRKT; LED-0603
LED302, LED304, LED306: LTST-C191KGKT; LED-0603
R301, R302, R305, R306, R307, R312: 10k; 0402-RES
R303, R304: DNP; 0402-RES
R308, R309, R310, R311, R313, R314: 470; 0402-RES
TP301: TESTPOINT_ROUND; TESTPAD_ROUND
TP302: TESTPOINTPADSMALL; TESTPAD_SMALL
U301: MACHXO2_FTBGA256; LBGA-256
XO301: OSCILLATOR_TXO2520; TXO2520

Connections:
ADS_CSN0: U301.H5 (PL9C); also elsewhere on the board
ADS_CSN1: U301.C1 (PL2C); also elsewhere on the board
ADS_CSN2: U301.K12 (PR11D); also elsewhere on the board
ADS_SCK0: U301.F5 (PL5C); also elsewhere on the board
ADS_SCK1: U301.B1 (PL1C); also elsewhere on the board
ADS_SCK2: U301.J12 (PR6D); also elsewhere on the board
ADS_SDO0: U301.G5 (PL4C); also elsewhere on the board
ADS_SDO1: U301.C2 (PL1D); also elsewhere on the board
ADS_SDO2: U301.K14 (PR10A); also elsewhere on the board
AUXIO0: U301.B3 (PT9C); also elsewhere on the board
AUXIO1: U301.A3 (PT11C); also elsewhere on the board
AUXIO2: U301.H13 (PR6C); also elsewhere on the board
DETB_END_CYC0: U301.R7 (PB9A); also elsewhere on the board
DETB_END_CYC1: U301.P1 (PL13D); also elsewhere on the board
DETB_END_CYC2: U301.J1 (PL7C/PCLKT4_0); also elsewhere on the board
DETB_END_CYC3: U301.D1 (PL1B/L_GPLLC_FB); also elsewhere on the board
DETB_RUN0: U301.T5 (PB6A); also elsewhere on the board
DETB_RUN1: U301.N3 (PL14B); also elsewhere on the board
DETB_RUN2: U301.K5 (PL12C); also elsewhere on the board
DETB_RUN3: U301.E3 (PL2B/L_GPLLC_IN); also elsewhere on the board
DETB_SELECT00: U301.R9 (PB18A); also elsewhere on the board
DETB_SELECT01: U301.R11 (PB22A); also elsewhere on the board
DETB_SELECT02: U301.T9 (PB16A/PCLKT2_1); also elsewhere on the board
DETB_SELECT03: U301.N9 (PB16D); also elsewhere on the board
DETB_SELECT04: U301.N11 (PB21D); also elsewhere on the board
DETB_SELECT05: U301.P9 (PB16B/PCLKC2_1); also elsewhere on the board
DETB_SELECT06: U301.T2 (PB3C); also elsewhere on the board
DETB_SELECT07: U301.T4 (PB3B); also elsewhere on the board
DETB_SELECT08: U301.R4 (PB6D); also elsewhere on the board
DETB_SELECT09: U301.P5 (PB5B); also elsewhere on the board
DETB_SELECT10: U301.N8 (PB12C); also elsewhere on the board
DETB_SELECT11: U301.N6 (PB8C); also elsewhere on the board
DETB_SELECT12: U301.K2 (PL10B); also elsewhere on the board
DETB_SELECT13: U301.M2 (PL14A); also elsewhere on the board
DETB_SELECT14: U301.M1 (PL12B/PCLKC3_0); also elsewhere on the board
DETB_SELECT15: U301.J4 (PL9D); also elsewhere on the board
DETB_SELECT16: U301.L4 (PL12D); also elsewhere on the board
DETB_SELECT17: U301.L3 (PL11B); also elsewhere on the board
DETB_SELECT18: U301.F2 (PL3B/PCLKC5_0); also elsewhere on the board
DETB_SELECT19: U301.H2 (PL6B); also elsewhere on the board
DETB_SELECT20: U301.G1 (PL6A); also elsewhere on the board
DETB_SELECT21: U301.F4 (PL3C); also elsewhere on the board
DETB_SELECT22: U301.H4 (PL6C); also elsewhere on the board
DETB_SELECT23: U301.G3 (PL5B); also elsewhere on the board
DETB_STATUS_SELECT0: U301.R6 (PB6B); also elsewhere on the board
DETB_STATUS_SELECT1: U301.N2 (PL13C); also elsewhere on the board
DETB_STATUS_SELECT2: U301.J2 (PL9A); also elsewhere on the board
DETB_STATUS_SELECT3: U301.D2 (PL2D); also elsewhere on the board
DETB_TRIGGER0: U301.T7 (PB11A/PCLKT2_0); also elsewhere on the board
DETB_TRIGGER1: U301.P2 (PL14D); also elsewhere on the board
DETB_TRIGGER2: U301.J3 (PL7D/PCLKC4_0); also elsewhere on the board
DETB_TRIGGER3: U301.E2 (PL2A/L_GPLLT_IN); also elsewhere on the board
EXP_J303_D0: J303.2, U301.C5 (PT10B/HS)
EXP_J303_D1: J303.4, U301.D6 (PT12A/HS)
EXP_J303_D2: J303.6, U301.D7 (PT13D)
EXP_J303_D3: J303.8, U301.C7 (PT13B/HS)
EXP_J304_D0: J304.2, U301.H16 (PR7B/PCLKC1_0)
EXP_J304_D1: J304.4, U301.H15 (PR6B)
EXP_J304_D2: J304.6, U301.G16 (PR6A)
EXP_J304_D3: J304.8, U301.G15 (PR5A)
EXP_J601_D0: U301.C10 (PT20C/JTAGENB); also elsewhere on the board
EXP_J601_D1: U301.B10 (PT20D/PROGRAMN); also elsewhere on the board
EXP_J601_D2: U301.A13 (PT24C/INITN); also elsewhere on the board
EXP_J601_D3: U301.E10 (PT20B/HS); also elsewhere on the board
EXP_J601_D4: U301.D11 (PT21D); also elsewhere on the board
EXP_J601_D5: U301.C12 (PT23A/HS); also elsewhere on the board
EXP_J601_D6: U301.C13 (PT24D/DONE); also elsewhere on the board
FP_LED0: R308.2, U301.A15 (PT24B/HS)
FP_LED1: R309.2, U301.B14 (PT24A/HS)
FP_LED2: R310.2, U301.A14 (PT22D)
FP_LED3: R311.2, U301.B13 (PT22C)
FP_LED4: R313.2, U301.K13 (PR11C)
FP_LED5: R314.2, U301.J13 (PR9D)
FP_SCL: R301.1, R303.1, U301.A9 (PT18C/SCL/PCLKT0_0)
FP_SDA: R302.1, R304.1, U301.C9 (PT18D/SDA/PCLKC0_0)
GND: C301.2, J301.1, J301.3, J301.5, J301.7, J302.6, J303.1, J303.3, J303.5, J303.7, J303.9, J304.1, J304.3, J304.5, J304.7, J304.9, LED301.C, LED302.C, LED303.C, LED304.C, LED305.C, LED306.C, R312.1, XO301.2 (GND); also elsewhere on the board
unnamed: LED301.A, R308.1
unnamed: LED302.A, R309.1
unnamed: LED303.A, R310.1
unnamed: LED304.A, R311.1
unnamed: LED305.A, R313.1
unnamed: LED306.A, R314.1
OSC_CLK: U301.C8 (PT17A/HS/PCLKT0_1), XO301.3 (OUT)
RAM0_CEN: U301.K16 (PR9B); also elsewhere on the board
RAM0_SCLK: U301.K15 (PR10B); also elsewhere on the board
RAM0_SIO0: U301.L16 (PR11A); also elsewhere on the board
RAM0_SIO1: U301.J15 (PR9A); also elsewhere on the board
RAM0_SIO2: U301.J16 (PR7C); also elsewhere on the board
RAM0_SIO3: U301.L15 (PR12A); also elsewhere on the board
RPFP_D0: U301.B16 (PR1D); also elsewhere on the board
RPFP_D1: U301.C15 (PR1C); also elsewhere on the board
RPFP_D2: U301.C16 (PR2C); also elsewhere on the board
RPFP_D3: U301.D15 (PR2D); also elsewhere on the board
RPFP_D4: U301.D16 (PR2A); also elsewhere on the board
RPFP_D5: U301.E14 (PR2B); also elsewhere on the board
RPFP_D6: U301.E15 (PR1B); also elsewhere on the board
RPFP_D7: U301.E16 (PR3A); also elsewhere on the board
RPFP_D8: U301.T6 (PB8B/SO/SPISO); also elsewhere on the board
RPFP_D9: U301.R12 (PB25A/SN); also elsewhere on the board
RPFP_D10: U301.P6 (PB8A/MCLK/CCLK); also elsewhere on the board
RPFP_D11: U301.P13 (PB25B/SI/SISPI); also elsewhere on the board
RPFP_RUN: U301.H12 (PR5D); also elsewhere on the board
RPI0_CE: J301.6, U301.B11 (PT22A/HS); also elsewhere on the board
RPI0_GPIO7: U301.B12 (PT23B/HS); also elsewhere on the board
RPI0_GPIO12: U301.D9 (PT18B/HS); also elsewhere on the board
RPI0_GPIO16: U301.E9 (PT17D); also elsewhere on the board
RPI0_GPIO20: U301.D10 (PT20A/HS); also elsewhere on the board
RPI0_GPIO21: U301.C11 (PT21B/HS); also elsewhere on the board
RPI0_MISO: J301.4, U301.A11 (PT21A/HS); also elsewhere on the board
RPI0_MOSI: J301.2, U301.A10 (PT19B/HS); also elsewhere on the board
RPI0_SCL: R303.2; also elsewhere on the board
RPI0_SCLK: J301.8, U301.A12 (PT22B/HS); also elsewhere on the board
RPI0_SDA: R304.2; also elsewhere on the board
SRC_COL00: U301.M10 (PB21C); also elsewhere on the board
SRC_COL01: U301.T12 (PB22B); also elsewhere on the board
SRC_COL02: U301.R13 (PB22C); also elsewhere on the board
SRC_COL03: U301.R14 (PB25D); also elsewhere on the board
SRC_COL04: U301.R16 (PR14D); also elsewhere on the board
SRC_COL05: U301.P16 (PR13D); also elsewhere on the board
SRC_COL06: U301.T14 (PB22D); also elsewhere on the board
SRC_COL07: U301.T15 (PB25C); also elsewhere on the board
SRC_COL08: U301.N15 (PR13C); also elsewhere on the board
SRC_COL09: U301.M14 (PR13A); also elsewhere on the board
SRC_COL10: U301.P12 (PB24A); also elsewhere on the board
SRC_COL11: U301.T13 (PB24B); also elsewhere on the board
SRC_COL12: U301.M11 (PB19D); also elsewhere on the board
SRC_COL13: U301.L10 (PB18D); also elsewhere on the board
SRC_PWR0: U301.P15 (PR14C); also elsewhere on the board
SRC_PWR1: U301.N14 (PR14B); also elsewhere on the board
SRC_PWR2: U301.N16 (PR14A); also elsewhere on the board
SRC_ROW0: U301.L9 (PB12D); also elsewhere on the board
SRC_ROW1: U301.M9 (PB18C); also elsewhere on the board
SRC_ROW2: U301.P11 (PB21B); also elsewhere on the board
SRC_SPARE: U301.T11 (PB21A); also elsewhere on the board
TCK: J302.4, R312.2, U301.A7 (PT16C/TCK)
TDI: J302.3, R306.1, U301.A6 (PT12D/TDI)
TDO: J302.5, R305.1, U301.C6 (PT12C/TDO)
TMS: J302.2, R307.1, U301.B8 (PT16D/TMS)
TRG0: U301.B4 (PT11D); also elsewhere on the board
TRG1: U301.A4 (PT10A/HS); also elsewhere on the board
TRG2: U301.B5 (PT9B/HS); also elsewhere on the board
TRG3: U301.A5 (PT11A/HS); also elsewhere on the board
UARTB_CTSN_TO_FTDI: U301.G13 (PR4D); also elsewhere on the board
UARTB_FPGA_TO_FTDI: U301.F16 (PR4B); also elsewhere on the board
UARTB_FTDI_TO_FPGA: U301.G12 (PR3D); also elsewhere on the board
UARTB_RTSN_TO_FPGA: U301.G14 (PR5B); also elsewhere on the board
UART_CTSN_TO_FTDI: U301.F15 (PR3B); also elsewhere on the board
UART_DETB_TO_FPGA00: U301.R10 (PB19B); also elsewhere on the board
UART_DETB_TO_FPGA01: U301.T8 (PB12B); also elsewhere on the board
UART_DETB_TO_FPGA02: U301.T10 (PB18B); also elsewhere on the board
UART_DETB_TO_FPGA03: U301.N10 (PB19C); also elsewhere on the board
UART_DETB_TO_FPGA04: U301.P8 (PB12A); also elsewhere on the board
UART_DETB_TO_FPGA05: U301.P10 (PB19A); also elsewhere on the board
UART_DETB_TO_FPGA06: U301.T3 (PB6C); also elsewhere on the board
UART_DETB_TO_FPGA07: U301.R3 (PB3D); also elsewhere on the board
UART_DETB_TO_FPGA08: TP302.P$1, U301.R5 (PB5A/CSSPIN); also elsewhere on the board
UART_DETB_TO_FPGA09: U301.N7 (PB9D); also elsewhere on the board
UART_DETB_TO_FPGA10: U301.P4 (PB3A); also elsewhere on the board
UART_DETB_TO_FPGA11: U301.P7 (PB9B); also elsewhere on the board
UART_DETB_TO_FPGA12: U301.L2 (PL12A/PCLKT3_0); also elsewhere on the board
UART_DETB_TO_FPGA13: U301.L1 (PL11A); also elsewhere on the board
UART_DETB_TO_FPGA14: U301.N1 (PL13B); also elsewhere on the board
UART_DETB_TO_FPGA15: U301.K4 (PL11C); also elsewhere on the board
UART_DETB_TO_FPGA16: U301.K3 (PL10A); also elsewhere on the board
UART_DETB_TO_FPGA17: U301.M3 (PL13A); also elsewhere on the board
UART_DETB_TO_FPGA18: U301.G2 (PL5A); also elsewhere on the board
UART_DETB_TO_FPGA19: U301.F1 (PL4B); also elsewhere on the board
UART_DETB_TO_FPGA20: U301.H1 (PL7B); also elsewhere on the board
UART_DETB_TO_FPGA21: U301.G4 (PL4D); also elsewhere on the board
UART_DETB_TO_FPGA22: U301.F3 (PL4A); also elsewhere on the board
UART_DETB_TO_FPGA23: U301.H3 (PL7A); also elsewhere on the board
UART_FPGA_TO_DETB0: U301.R8 (PB11B/PCLKC2_0); also elsewhere on the board
UART_FPGA_TO_DETB1: U301.R1 (PL14C); also elsewhere on the board
UART_FPGA_TO_DETB2: U301.K1 (PL9B); also elsewhere on the board
UART_FPGA_TO_DETB3: U301.E1 (PL3A/PCLKT5_0); also elsewhere on the board
UART_FPGA_TO_FTDI: U301.F14 (PR4A); also elsewhere on the board
UART_FTDI_TO_FPGA: U301.F12 (PR4C); also elsewhere on the board
UART_FTDI_TXLEDN: TP301.P$1, U301.H14 (PR7A/PCLKT1_0)
UART_RTSN_TO_FPGA: U301.F13 (PR3C); also elsewhere on the board
V3P3: C301.1, J302.1, J303.10, J304.10, R301.2, R302.2, R305.2, R306.2, R307.2, XO301.1 (EN), XO301.4 (VCC); also elsewhere on the board
V5P1_B01_EN: U301.M7 (PB9C); also elsewhere on the board
V5P1_B23_EN: U301.J5 (PL10C); also elsewhere on the board
V5P1_RPI_EN: U301.B7 (PT13A/HS); also elsewhere on the board
V5P1_SRC_EN: U301.L8 (PB11D); also elsewhere on the board
V9P0_EN: U301.M8 (PB16C); also elsewhere on the board
VN3P4_EN: U301.L14 (PR11B); also elsewhere on the board
VN22_CLKA: U301.M15 (PR13B); also elsewhere on the board
VN22_CLKB: U301.M16 (PR12B); also elsewhere on the board
VN22_EN: U301.L13 (PR12D); also elsewhere on the board
V_SRC_BOOST: U301.J14 (PR7D); also elsewhere on the board

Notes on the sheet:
XO 48 MHz ECS-2520MV-480-CN-TR
FPGA
FPGA JTAG
To RPi 0 J101 page 1
To RP2040 U201 page 2
To FTDI USB A601 page 6
To Spare Connector J601 page 6
To Remote Trigger Receiver JP601 page 6
To Aux ADCs U501 U503 page 5
To PSRAM U601, U602 page 6

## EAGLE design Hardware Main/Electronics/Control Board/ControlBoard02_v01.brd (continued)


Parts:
J401, J402, J403, J404, J405: M20X2_HARFLEX_M

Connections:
DETB_END_CYC0: J402.B15 (29); also elsewhere on the board
DETB_END_CYC1: J403.B15 (29); also elsewhere on the board
DETB_END_CYC2: J404.B15 (29); also elsewhere on the board
DETB_END_CYC3: J405.B15 (29); also elsewhere on the board
DETB_RUN0: J402.A16 (32); also elsewhere on the board
DETB_RUN1: J403.A16 (32); also elsewhere on the board
DETB_RUN2: J404.A16 (32); also elsewhere on the board
DETB_RUN3: J405.A16 (32); also elsewhere on the board
DETB_SELECT00: J402.B11 (21); also elsewhere on the board
DETB_SELECT01: J402.B9 (17); also elsewhere on the board
DETB_SELECT02: J402.A10 (20); also elsewhere on the board
DETB_SELECT03: J402.B7 (13); also elsewhere on the board
DETB_SELECT04: J402.B5 (9); also elsewhere on the board
DETB_SELECT05: J402.A6 (12); also elsewhere on the board
DETB_SELECT06: J403.B11 (21); also elsewhere on the board
DETB_SELECT07: J403.B9 (17); also elsewhere on the board
DETB_SELECT08: J403.A10 (20); also elsewhere on the board
DETB_SELECT09: J403.B7 (13); also elsewhere on the board
DETB_SELECT10: J403.B5 (9); also elsewhere on the board
DETB_SELECT11: J403.A6 (12); also elsewhere on the board
DETB_SELECT12: J404.B11 (21); also elsewhere on the board
DETB_SELECT13: J404.B9 (17); also elsewhere on the board
DETB_SELECT14: J404.A10 (20); also elsewhere on the board
DETB_SELECT15: J404.B7 (13); also elsewhere on the board
DETB_SELECT16: J404.B5 (9); also elsewhere on the board
DETB_SELECT17: J404.A6 (12); also elsewhere on the board
DETB_SELECT18: J405.B11 (21); also elsewhere on the board
DETB_SELECT19: J405.B9 (17); also elsewhere on the board
DETB_SELECT20: J405.A10 (20); also elsewhere on the board
DETB_SELECT21: J405.B7 (13); also elsewhere on the board
DETB_SELECT22: J405.B5 (9); also elsewhere on the board
DETB_SELECT23: J405.A6 (12); also elsewhere on the board
DETB_STATUS_SELECT0: J402.B16 (31); also elsewhere on the board
DETB_STATUS_SELECT1: J403.B16 (31); also elsewhere on the board
DETB_STATUS_SELECT2: J404.B16 (31); also elsewhere on the board
DETB_STATUS_SELECT3: J405.B16 (31); also elsewhere on the board
DETB_TRIGGER0: J402.B14 (27); also elsewhere on the board
DETB_TRIGGER1: J403.B14 (27); also elsewhere on the board
DETB_TRIGGER2: J404.B14 (27); also elsewhere on the board
DETB_TRIGGER3: J405.B14 (27); also elsewhere on the board
GND: J401.A1 (2), J401.A9 (18), J401.A12 (24), J401.A13 (26), J401.A14 (28), J401.A15 (30), J401.A16 (32), J401.A17 (34), J401.A19 (38), J401.B1 (1), J401.B2 (3), J401.B3 (5), J401.B17 (33), J402.A1 (2), J402.A4 (8), J402.A8 (16), J402.A12 (24), J402.A13 (26), J402.A14 (28), J402.A15 (30), J402.A17 (34), J402.A19 (38), J402.B3 (5), J402.B4 (7), J402.B8 (15), J402.B12 (23), J402.B17 (33), J403.A1 (2), J403.A4 (8), J403.A8 (16), J403.A12 (24), J403.A13 (26), J403.A14 (28), J403.A15 (30), J403.A17 (34), J403.A19 (38), J403.B3 (5), J403.B4 (7), J403.B8 (15), J403.B12 (23), J403.B17 (33), J404.A1 (2), J404.A4 (8), J404.A8 (16), J404.A12 (24), J404.A13 (26), J404.A14 (28), J404.A15 (30), J404.A17 (34), J404.A19 (38), J404.B3 (5), J404.B4 (7), J404.B8 (15), J404.B12 (23), J404.B17 (33), J405.A1 (2), J405.A4 (8), J405.A8 (16), J405.A12 (24), J405.A13 (26), J405.A14 (28), J405.A15 (30), J405.A17 (34), J405.A19 (38), J405.B3 (5), J405.B4 (7), J405.B8 (15), J405.B12 (23), J405.B17 (33); also elsewhere on the board
SRC_COL00: J401.A11 (22); also elsewhere on the board
SRC_COL01: J401.A10 (20); also elsewhere on the board
SRC_COL02: J401.A8 (16); also elsewhere on the board
SRC_COL03: J401.A7 (14); also elsewhere on the board
SRC_COL04: J401.A6 (12); also elsewhere on the board
SRC_COL05: J401.A5 (10); also elsewhere on the board
SRC_COL06: J401.B8 (15); also elsewhere on the board
SRC_COL07: J401.B7 (13); also elsewhere on the board
SRC_COL08: J401.A4 (8); also elsewhere on the board
SRC_COL09: J401.A3 (6); also elsewhere on the board
SRC_COL10: J401.B10 (19); also elsewhere on the board
SRC_COL11: J401.B9 (17); also elsewhere on the board
SRC_COL12: J401.B12 (23); also elsewhere on the board
SRC_COL13: J401.B11 (21); also elsewhere on the board
SRC_PWR0: J401.B6 (11); also elsewhere on the board
SRC_PWR1: J401.B5 (9); also elsewhere on the board
SRC_PWR2: J401.B4 (7); also elsewhere on the board
SRC_ROW0: J401.B16 (31); also elsewhere on the board
SRC_ROW1: J401.B15 (29); also elsewhere on the board
SRC_ROW2: J401.B14 (27); also elsewhere on the board
SRC_SPARE: J401.B13 (25); also elsewhere on the board
UART_DETB_TO_FPGA00: J402.B10 (19); also elsewhere on the board
UART_DETB_TO_FPGA01: J402.A11 (22); also elsewhere on the board
UART_DETB_TO_FPGA02: J402.A9 (18); also elsewhere on the board
UART_DETB_TO_FPGA03: J402.B6 (11); also elsewhere on the board
UART_DETB_TO_FPGA04: J402.A7 (14); also elsewhere on the board
UART_DETB_TO_FPGA05: J402.A5 (10); also elsewhere on the board
UART_DETB_TO_FPGA06: J403.B10 (19); also elsewhere on the board
UART_DETB_TO_FPGA07: J403.A11 (22); also elsewhere on the board
UART_DETB_TO_FPGA08: J403.A9 (18); also elsewhere on the board
UART_DETB_TO_FPGA09: J403.B6 (11); also elsewhere on the board
UART_DETB_TO_FPGA10: J403.A7 (14); also elsewhere on the board
UART_DETB_TO_FPGA11: J403.A5 (10); also elsewhere on the board
UART_DETB_TO_FPGA12: J404.B10 (19); also elsewhere on the board
UART_DETB_TO_FPGA13: J404.A11 (22); also elsewhere on the board
UART_DETB_TO_FPGA14: J404.A9 (18); also elsewhere on the board
UART_DETB_TO_FPGA15: J404.B6 (11); also elsewhere on the board
UART_DETB_TO_FPGA16: J404.A7 (14); also elsewhere on the board
UART_DETB_TO_FPGA17: J404.A5 (10); also elsewhere on the board
UART_DETB_TO_FPGA18: J405.B10 (19); also elsewhere on the board
UART_DETB_TO_FPGA19: J405.A11 (22); also elsewhere on the board
UART_DETB_TO_FPGA20: J405.A9 (18); also elsewhere on the board
UART_DETB_TO_FPGA21: J405.B6 (11); also elsewhere on the board
UART_DETB_TO_FPGA22: J405.A7 (14); also elsewhere on the board
UART_DETB_TO_FPGA23: J405.A5 (10); also elsewhere on the board
UART_FPGA_TO_DETB0: J402.B13 (25); also elsewhere on the board
UART_FPGA_TO_DETB1: J403.B13 (25); also elsewhere on the board
UART_FPGA_TO_DETB2: J404.B13 (25); also elsewhere on the board
UART_FPGA_TO_DETB3: J405.B13 (25); also elsewhere on the board
V5P1_B01: J402.A18 (36), J402.A20 (40), J402.B18 (35), J402.B19 (37), J402.B20 (39), J403.A18 (36), J403.A20 (40), J403.B18 (35), J403.B19 (37), J403.B20 (39); also elsewhere on the board
V5P1_B23: J404.A18 (36), J404.A20 (40), J404.B18 (35), J404.B19 (37), J404.B20 (39), J405.A18 (36), J405.A20 (40), J405.B18 (35), J405.B19 (37), J405.B20 (39); also elsewhere on the board
V5P1_SRC: J401.A18 (36), J401.A20 (40), J401.B18 (35), J401.B19 (37), J401.B20 (39); also elsewhere on the board
V9P0: J402.A3 (6), J403.A3 (6), J404.A3 (6), J405.A3 (6); also elsewhere on the board
VN3P4: J401.A2 (4), J402.A2 (4), J403.A2 (4), J404.A2 (4), J405.A2 (4); also elsewhere on the board
VN22: J402.B1 (1), J402.B2 (3), J403.B1 (1), J403.B2 (3), J404.B1 (1), J404.B2 (3), J405.B1 (1), J405.B2 (3); also elsewhere on the board

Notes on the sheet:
Backplane Connectors
Source Backplane
Detector Backplane B0
Detector Backplane B1
Detector Backplane B2
Detector Backplane B3


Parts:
C501, C504, C507, C508: 0.1u; 0402-CAP
C502, C509, C510: 4.7u; 0402-CAP
C503, C505: 10n; 0603-CAP
C506: 22u; 0805-CAP
D501, D502, D503: D1213A-02SO; SOT23-6
J501, J502, J503, J504, J505, J506: SMA_MMCX_PTH_RA; MMCX_PTH_RA
J507: U.FL
LF501: FERRITE1206; 1206
R501, R505: 1k; 0402-RES
R502, R506: 82; 0402-RES
R503, R507, R510, R513, R516, R518: DNP; 0805
R504, R508, R511, R514, R517, R519: 10k; 0402-RES
R509, R512, R515, R520, R521: 100; 0402-RES
TP501, TP502: TESTPOINT_ROUND; TESTPAD_ROUND
U501, U503: ADS7886; SOT363
U502: LT1801; SOP65P490X110-8N
U504: REF30XX; SOT23-3
U505: ADP7182_WSON; WSON6

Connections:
ADS_CSN0: U501.6 (CS#); also elsewhere on the board
ADS_CSN1: U503.6 (CS#); also elsewhere on the board
ADS_SCK0: U501.4 (SCLK); also elsewhere on the board
ADS_SCK1: U503.4 (SCLK); also elsewhere on the board
ADS_SDO0: U501.5 (SDO); also elsewhere on the board
ADS_SDO1: U503.5 (SDO); also elsewhere on the board
AUXIO0: D502.4 (CH2), R509.2; also elsewhere on the board
AUXIO1: D502.3 (CH1), R512.2; also elsewhere on the board
AUXIO2: R521.2; also elsewhere on the board
GND: C501.2, C502.2, C503.2, C504.2, C505.2, C506.2, C507.2, C508.1, C509.1, C510.1, D501.2 (VN), D502.2 (VN), D503.2 (VN), J501.G@1 (GND), J501.G@2 (GND), J501.G@3 (GND), J501.G@4 (GND), J502.G@1 (GND), J502.G@2 (GND), J502.G@3 (GND), J502.G@4 (GND), J503.G@1 (GND), J503.G@2 (GND), J503.G@3 (GND), J503.G@4 (GND), J504.G@1 (GND), J504.G@2 (GND), J504.G@3 (GND), J504.G@4 (GND), J505.G@1 (GND), J505.G@2 (GND), J505.G@3 (GND), J505.G@4 (GND), J506.G@1 (GND), J506.G@2 (GND), J506.G@3 (GND), J506.G@4 (GND), J507.P$1 (GND), J507.P$2 (GND), R503.1, R504.1, R507.1, R508.1, R510.1, R511.1, R513.1, R514.1, R516.1, R517.1, R518.1, R519.1, U501.2 (GND), U503.2 (GND), U504.3 (GND), U505.5 (GND); also elsewhere on the board
unnamed: J501.C (SIGNAL), R501.1, R503.2, R504.2
unnamed: D501.4 (CH2), R501.2, U502.5 (+IN)
unnamed: J502.C (SIGNAL), R505.1, R507.2, R508.2
unnamed: D501.3 (CH1), R505.2, U502.3 (+IN)
unnamed: J505.C (SIGNAL), R515.1, R516.2, R517.2
unnamed: J503.C (SIGNAL), R509.1, R510.2, R511.2
unnamed: J504.C (SIGNAL), R512.1, R513.2, R514.2
unnamed: C503.1, R502.2, U501.3 (VIN)
unnamed: R502.1, U502.6 (-IN), U502.7 (OUT)
unnamed: C505.1, R506.2, U503.3 (VIN)
unnamed: R506.1, U502.1 (OUT), U502.2 (-IN)
unnamed: J507.P$3 (SIGNAL), R521.1
unnamed: J506.C (SIGNAL), R518.2, R519.2, R520.1
unnamed: C506.1, LF501.2, U504.1 (IN)
RPIP_AUXIO0: D503.4 (CH2), R515.2; also elsewhere on the board
RPIP_AUXIO1: D503.3 (CH1), R520.2; also elsewhere on the board
V3P3: D502.6 (VP), D503.6 (VP); also elsewhere on the board
V5P1_B23: LF501.1; also elsewhere on the board
VA_3P3: C501.1, C502.1, C504.1, C507.1, D501.6 (VP), TP501.P$1, U501.1 (VDD), U502.8 (V+), U503.1 (VDD), U504.2 (OUT)
VN1P2: C508.2, C510.2, TP502.P$1, U502.4 (V-), U505.1 (OUT), U505.2 (NC/ADJ)
VN3P4: C509.2, U505.3 (EN), U505.6 (IN), U505.PAD (IN); also elsewhere on the board

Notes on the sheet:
many pin compatible alternatives e.g. TSV912
Aux I/O
REF3033 or NCP51460
To FPGA U301 page 3
To RP2040 U201 page 2


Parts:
C601, C602, C604, C605, C610: 4.7u; 0402-CAP
C603, C606, C607, C608, C613, C614, C615, C616, C617, C619, C620, C621, C622, C623, C624, C625, C626: 0.1u; 0402-CAP
C609: 22u; 0805-CAP
C611, C612: 27p; 0402-CAP
C618: DNP; 1210
D601: PACDN042; SOT23-3
D602: D1213A-02SO; SOT23-6
J601: USB-MICRO
J602: M04X2_0.050_SMD_NO_CREAM
J603: M13X2_0.050_SHF_NO_CREAM
J604: M07X1_PTH
LED601, LED602, LED604: LTST-C191KGKT; LED-0603
LED603, LED605, LED606: LTST-C191KRKT; LED-0603
LF601, LF602: FERRITE0603; 0603-FER
LF603: FERRITE1206; 1206
LS601: PKMCS0909E4000-R1; XDCR_PKMCS0909E4000-R1
R601: 470; 0402-RES
R602, R606, R607, R608, R610, R612, R613, R614, R615, R616, R617, R619: 1k; 0402-RES
R603, R604, R605: 10k; 0402-RES
R609: 3.48k; 0402-RES
R611: 12k; 0402-RES
R618: 1M; R2010
TP601: TESTPOINT_ROUND; TESTPAD_ROUND
TP602: TESTPOINT1X01; 1X01
U601: MCP1755_DFN; DFN8_2X3MM
U602: 93LC56; SOT23-6
U603: APS6404L_PAD; USON8L-2X3MM_APM
U604: FT2232H_QFP; QFP50P1200X1200X160-64N
U605, U606: ISO7742_DBQ; SSOP16
X601: 403I35D12M00000; CRYSTAL-3.2-2.5

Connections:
EXP_J601_D0: J603.3; also elsewhere on the board
EXP_J601_D1: J603.5; also elsewhere on the board
EXP_J601_D2: J603.7; also elsewhere on the board
EXP_J601_D3: J603.9; also elsewhere on the board
EXP_J601_D4: J603.11; also elsewhere on the board
EXP_J601_D5: J603.13; also elsewhere on the board
EXP_J601_D6: J603.15; also elsewhere on the board
FTA_CTS#: U604.19 (ADBUS3), U605.13 (OUTB)
FTA_DSR#: U604.22 (ADBUS5)
FTA_DTR#: U604.21 (ADBUS4)
FTA_RTS#: U604.18 (ADBUS2), U605.11 (IND)
FTA_RXD: U604.17 (ADBUS1), U605.14 (OUTA)
FTA_RXLED#: R612.1, U604.29 (ACBUS3)
FTA_TXD: U604.16 (ADBUS0), U605.12 (INC)
FTA_TXLED#: R613.1, U604.30 (ACBUS4)
FTB_CTS#: U604.41 (BDBUS3), U606.13 (OUTB)
FTB_DSR#: U604.44 (BDBUS5)
FTB_DTR#: U604.43 (BDBUS4)
FTB_RTS#: U604.40 (BDBUS2), U606.11 (IND)
FTB_RXD: U604.39 (BDBUS1), U606.14 (OUTA)
FTB_RXLED#: R614.1, U604.54 (BCBUS3)
FTB_TXD: U604.38 (BDBUS0), U606.12 (INC)
FTB_TXLED#: R615.1, U604.55 (BCBUS4)
FT_PWREN#: U604.60 (!PWREN#)
FT_VREGOUT: C610.1, C624.1, C625.1, C626.1, U604.12 (VCORE), U604.37 (VCORE), U604.49 (VREGOUT), U604.64 (VCORE)
GND: C608.2, C609.2, C613.2, C614.2, C617.2, C618.1, J602.1, J602.3, J602.5, J602.7, J603.1, J603.2, J603.4, J603.6, J603.17, J603.21, J603.24, J603.25, J604.7, LED601.C, LS601.2, R618.1, U603.4 (GND), U605.2 (GND1), U605.8 (GND1), U606.2 (GND1), U606.8 (GND1); also elsewhere on the board
GNDI: C601.2, C602.2, C603.2, C604.2, C605.2, C606.2, C607.2, C610.2, C611.2, C612.2, C615.2, C616.2, C618.2, C619.2, C620.2, C621.2, C622.2, C623.2, C624.2, C625.2, C626.2, D601.3 (A), D602.2 (VN), J601.5, J601.SH1, J601.SH2, J601.SH3, J601.SH4, J601.SH5, J601.SH6, LED606.C, R611.1, R618.2, TP602.1, U601.4 (GND), U601.P (GND), U602.2 (GND), U604.1 (GND), U604.5 (GND), U604.10 (AGND), U604.11 (GND), U604.13 (TEST), U604.15 (GND), U604.25 (GND), U604.35 (GND), U604.47 (GND), U604.51 (GND), U605.9 (GND2), U605.15 (GND2), U606.9 (GND2), U606.15 (GND2), X601.2 (GND), X601.4 (GND)
LED: J604.1, R601.1
unnamed: LED606.A, R619.1
unnamed: R604.1, U602.5 (CS), U604.63 (EECS)
unnamed: R603.1, U602.4 (CLK), U604.62 (EECLK)
unnamed: R605.1, R609.1, U602.1 (DO)
unnamed: LS601.1, R616.1, R617.1
unnamed: R609.2, U602.3 (DI), U604.61 (EEDATA)
unnamed: C605.1, C607.1, LF602.2, U604.9 (VPLL)
unnamed: C604.1, C606.1, LF601.2, U604.4 (VPHY)
unnamed: R610.2, U604.14 (!RESET#)
unnamed: R611.2, U604.6 (REF)
unnamed: C611.1, U604.2 (OSCI), X601.1 (C1)
unnamed: C612.1, U604.3 (OSCO), X601.3 (C2)
unnamed: LED604.C, R614.2
unnamed: LED605.C, R615.2
unnamed: LED602.C, R612.2
unnamed: LED603.C, R613.2
unnamed: D602.3 (CH1), J601.3, U604.8 (DP)
unnamed: D602.4 (CH2), J601.2, U604.7 (DM)
unnamed: J604.5, R608.2
unnamed: J604.4, R607.2
unnamed: J604.3, R606.2
unnamed: J604.2, R602.2
unnamed: LED601.A, R601.2
RAM0_CEN: J602.4, U603.1 (/CE); also elsewhere on the board
RAM0_SCLK: J602.6, U603.6 (SCLK); also elsewhere on the board
RAM0_SIO0: J602.8, U603.5 (SI/SIO[0]); also elsewhere on the board
RAM0_SIO1: J602.2, U603.2 (SO/SIO[1]); also elsewhere on the board
RAM0_SIO2: U603.3 (SIO[2]); also elsewhere on the board
RAM0_SIO3: U603.7 (SIO[3]); also elsewhere on the board
RPI0_BUZZ: R617.2; also elsewhere on the board
RPI0_GPIO5: J603.14; also elsewhere on the board
RPI0_GPIO6: J603.12; also elsewhere on the board
RPI0_GPIO19: J603.10; also elsewhere on the board
RPI0_GPIO22: J603.16; also elsewhere on the board
RPI0_GPIO26: J603.8; also elsewhere on the board
RPI0_GPIO27: J603.18; also elsewhere on the board
RPIP_BUZZ: R616.2; also elsewhere on the board
RPIP_SCL1: J603.19; also elsewhere on the board
RPIP_SDA1: J603.20; also elsewhere on the board
TRG0: R608.1; also elsewhere on the board
TRG1: R607.1; also elsewhere on the board
TRG2: R606.1; also elsewhere on the board
TRG3: R602.1; also elsewhere on the board
UARTB_CTSN_TO_FTDI: U606.4 (INB); also elsewhere on the board
UARTB_FPGA_TO_FTDI: U606.3 (INA); also elsewhere on the board
UARTB_FTDI_TO_FPGA: U606.5 (OUTC); also elsewhere on the board
UARTB_RTSN_TO_FPGA: U606.6 (OUTD); also elsewhere on the board
UART_CTSN_TO_FTDI: U605.4 (INB); also elsewhere on the board
UART_FPGA_TO_FTDI: U605.3 (INA); also elsewhere on the board
UART_FTDI_TO_FPGA: U605.5 (OUTC); also elsewhere on the board
UART_RTSN_TO_FPGA: U605.6 (OUTD); also elsewhere on the board
V3P3: C608.1, C613.1, C614.1, C617.1, J603.22, J603.23, LF603.1, U603.8 (VDD), U605.1 (VCC1), U605.7 (EN1), U606.1 (VCC1), U606.7 (EN1); also elsewhere on the board
V3P3_R: C609.1, J604.6, LF603.2
V3P3_USB: C602.1, C603.1, C615.1, C616.1, C619.1, C620.1, C621.1, C622.1, C623.1, D602.6 (VP), LED602.A, LED603.A, LED604.A, LED605.A, LF601.1, LF602.1, R603.2, R604.2, R605.2, R610.1, R619.2, TP601.P$1, U601.1 (OUT), U602.6 (VCC), U604.20 (VCCIO), U604.31 (VCCIO), U604.42 (VCCIO), U604.50 (VREGIN), U604.56 (VCCIO), U605.10 (EN2), U605.16 (VCC2), U606.10 (EN2), U606.16 (VCC2)
V5P0_USB: C601.1, D601.1 (C), D601.2 (C), J601.1, U601.5 (/SHDN), U601.8 (IN)
V12: J603.26; also elsewhere on the board

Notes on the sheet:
Misc Circuits
Remote Trigger Receiver (QiaChip)
PSRAM with debug connector
Spare
To FPGA U301 page 3
To RPi 0 J101 page 1
FTDI USB Interface
USB Connector

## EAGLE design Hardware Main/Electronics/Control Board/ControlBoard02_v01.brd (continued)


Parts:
C701: 22p; 0402-CAP
C702, C703, C704, C706, C709, C710, C712, C713, C714, C716, C717, C719, C721, C722, C723, C725, C726, C727, C728, C731: 22u; 0805-CAP
C705, C707, C708: 100u/25V; 2917-CAP
C711, C715, C720, C724: 39p; 0402-CAP
C718: 330u/25V; CAP-SMD-POL-8X10
C729: 10n; 0603-CAP
C730: 1n; 0603-CAP
D701, D702, D703, D704: DIODESOD128; SOD128
F701: 2920L600/16MR; 2920-FUSE
J701: M04X2_SHROUDED; M04X2-SHROUDED
J702: POWERJACK_PJ051AH; PJ051AH
LF701: FERRITE1206; 1206
Q701: MOSFET-NCHANNELSMD; SOT23-3
Q702: MOSFET-PCHANNEL_SO8; SO08
R702, R706, R710, R714, R718: 47k; 0402-RES
R703, R707, R711, R715, R721: 100k; 0402-RES
R704, R720: 6.2k; 0402-RES
R705, R709, R713, R717: 1k; 0402-RES
R708, R712, R716: 8.66k; 0402-RES
R719: 15k; 0402-RES
R722, R723: 0.01; 1206
R724: 10M; 0805
TP701, TP702, TP703, TP704, TP705, TP706: TESTPOINT_ROUND; TESTPAD_ROUND
U701: MPM3630_FULL_CREAM; QFN-20-MPS_FULL_CREAM
U702, U703, U704, U705: RPL-30

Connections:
GND: C702.2, C703.2, C704.2, C705.N, C706.2, C707.N, C708.N, C709.2, C710.2, C712.2, C713.2, C714.2, C716.2, C717.2, C718.N, C719.2, C721.2, C722.2, C723.2, C725.2, C726.2, C727.2, C728.2, C731.2, J701.1, J701.3, J701.5, J701.7, J702.SHIELD1 (SHIELD), J702.SHIELD2 (SHIELD), J702.SLEEVE (GND), J702.SWITCH (GNDBREAK), Q701.2 (S), R703.1, R707.1, R708.1, R711.1, R712.1, R715.1, R716.1, R719.1, R720.1, R721.1, R724.1, U701.3 (AGND), U701.12 (PGND), U701.13 (PGND), U701.14 (PGND), U702.3 (PGND), U702.4 (PGND), U702.8 (AGND), U703.3 (PGND), U703.4 (PGND), U703.8 (AGND), U704.3 (PGND), U704.4 (PGND), U704.8 (AGND), U705.3 (PGND), U705.4 (PGND), U705.8 (AGND); also elsewhere on the board
unnamed: C701.2, R702.1, R704.2, R720.2, U701.1 (FB)
unnamed: Q701.3 (D), R704.1
unnamed: D701.A, J702.CENTER (PWR)
unnamed: C711.2, R706.1, R708.2, U702.7 (FB)
unnamed: R705.1, U702.6 (SENSE)
unnamed: C715.2, R710.1, R712.2, U703.7 (FB)
unnamed: R709.1, U703.6 (SENSE)
unnamed: C720.2, R714.1, R716.2, U704.7 (FB)
unnamed: R713.1, U704.6 (SENSE)
unnamed: C724.2, R718.1, R719.2, U705.7 (FB)
unnamed: R717.1, U705.6 (SENSE)
unnamed: D702.A, J701.2, J701.4
unnamed: C729.1, F701.2, Q702.1 (S), Q702.2 (S), Q702.3 (S)
unnamed: D703.A, J701.6, J701.8
unnamed: D701.C, D702.C, D703.C, F701.1
unnamed: C729.2, C730.2, Q702.4 (G), R724.2
V3P3: C724.1, C725.1, C726.1, R717.2, R718.2, TP706.P$1, U705.5 (VOUT); also elsewhere on the board
V5P1_B01: C711.1, C712.1, C713.1, R705.2, R706.2, TP702.P$1, U702.5 (VOUT); also elsewhere on the board
V5P1_B01_EN: R707.2, U702.1 (CTRL); also elsewhere on the board
V5P1_B23: C715.1, C716.1, C717.1, R709.2, R710.2, TP703.P$1, U703.5 (VOUT); also elsewhere on the board
V5P1_B23_EN: R711.2, U703.1 (CTRL); also elsewhere on the board
V5P1_RPI: C720.1, C721.1, C722.1, R713.2, R714.2, TP705.P$1, U704.5 (VOUT); also elsewhere on the board
V5P1_RPI_EN: R715.2, U704.1 (CTRL); also elsewhere on the board
V5P1_SRC: R722.2, TP701.P$1; also elsewhere on the board
V5P1_SRC_EN: R703.2, U701.17 (EN/SYNC); also elsewhere on the board
V5P1_SRC_PRE: C701.1, C702.1, C703.1, C704.1, R702.2, R722.1, U701.7_8_9 (VOUT); also elsewhere on the board
V12: C705.P, C706.1, C714.1, C718.P, C719.1, C727.1, C728.1, D704.A, LF701.1, R723.2, TP704.P$1, U702.2 (VIN), U703.2 (VIN), U705.1 (CTRL), U705.2 (VIN); also elsewhere on the board
V12_PRE: C730.1, Q702.5 (D), Q702.6 (D), Q702.7 (D), Q702.8 (D), R723.1; also elsewhere on the board
V12_RPI: C723.1, C731.1, D704.C, U704.2 (VIN)
V12_SRC: C707.P, C708.P, C709.1, C710.1, LF701.2, U701.16 (VIN)
V_SRC_BOOST: Q701.1 (G), R721.2; also elsewhere on the board

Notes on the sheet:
Main Power Connectors (Quick Disconnect)
12V nominal
Voltage Regulators
nominal: 0.6*(1+47/6.2) = 5.15V
nominal: 0.8*(1+47/8.66) = 5.14V
0.6*(1+47/3.48)= 8.70V nominal
boost nominal: 0.6*(1+47/3.1) = 9.70V (for NinjaNIRS26 high power LED optodes)


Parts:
C801, C812, C831: 100u/25V; 2917-CAP
C802, C803, C807, C808, C809, C810, C813, C814, C818, C819, C820, C821, C823, C824, C828, C829: 4.7u; 0805-CAP
C804, C805, C806, C815, C816, C817: 10u; 1206
C811, C822, C830: 1u; 0603-CAP
C825, C826: 100u; 1206
C827: DNP; 1206
R801, R805: 82; 0402-RES
R802, R806: 180k; 0402-RES
R803: 220k; 0402-RES
R804: 100k; 0402-RES
R807: 15; 0402-RES
R808: 68k; 0402-RES
TP801, TP802, TP803, TP804, TP805, TP806, TP807, TP808, TP809, TP810: TESTPOINT_ROUND; TESTPAD_ROUND
U801, U802, U803: LTM4651; BGA-77

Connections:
GND: C801.N, C802.2, C804.1, C805.1, C806.1, C807.2, C808.2, C812.N, C813.2, C815.1, C816.1, C817.1, C818.2, C819.2, C823.2, C825.1, C826.1, C827.1, C828.2, C831.N, R801.2, R804.2, R805.2, R807.2, U801.D4 (GND), U801.G1 (GNDSNS), U801.H1 (GNDSNS), U801.K1 (PGND), U801.K2 (PGND), U801.K3 (PGND), U801.L1 (PGND), U801.L2 (PGND), U801.L3 (PGND), U802.D4 (GND), U802.G1 (GNDSNS), U802.H1 (GNDSNS), U802.K1 (PGND), U802.K2 (PGND), U802.K3 (PGND), U802.L1 (PGND), U802.L2 (PGND), U802.L3 (PGND), U803.D4 (GND), U803.G1 (GNDSNS), U803.H1 (GNDSNS), U803.K1 (PGND), U803.K2 (PGND), U803.K3 (PGND), U803.L1 (PGND), U803.L2 (PGND), U803.L3 (PGND); also elsewhere on the board
unnamed: U803.D3 (VINREG), U803.G3 (INTVCC)
unnamed: TP802.P$1, U801.J6 (TEMP+)
unnamed: U803.E1 (COMPB), U803.E2 (COMPA)
unnamed: U801.D3 (VINREG), U801.G3 (INTVCC)
unnamed: U801.E1 (COMPB), U801.E2 (COMPA), U802.E1 (COMPB), U802.E2 (COMPA)
unnamed: R802.2, U801.E3 (FSET)
unnamed: TP803.P$1, U801.J7 (TEMP-)
unnamed: C811.1, R801.1, U801.F3 (EXTVCC)
unnamed: C822.1, R805.1, U802.F3 (EXTVCC)
unnamed: TP808.P$1, U803.J6 (TEMP+)
unnamed: TP809.P$1, U803.J7 (TEMP-)
unnamed: R803.1, U801.F1 (ISETB), U801.F2 (ISETA), U802.F1 (ISETB), U802.F2 (ISETA)
unnamed: U802.D3 (VINREG), U802.G3 (INTVCC)
unnamed: TP806.P$1, U802.H4 (SW)
unnamed: C830.1, R807.1, U803.F3 (EXTVCC)
unnamed: C807.1, C808.1, C809.1, C810.1, U801.A4 (VD), U801.B4 (VD), U801.C4 (VD)
unnamed: C818.1, C819.1, C820.1, C821.1, U802.A4 (VD), U802.B4 (VD), U802.C4 (VD)
unnamed: R806.2, U802.E3 (FSET)
unnamed: R808.1, U803.F1 (ISETB), U803.F2 (ISETA)
unnamed: TP810.P$1, U803.H4 (SW)
unnamed: C828.1, C829.1, U803.A4 (VD), U803.B4 (VD), U803.C4 (VD)
V12: C801.P, C802.1, C803.1, C812.P, C813.1, C814.1, C823.1, C824.1, C831.P, U801.A1 (VIN), U801.A2 (VIN), U801.A3 (VIN), U801.B3 (VIN), U801.C3 (SVIN), U802.A1 (VIN), U802.A2 (VIN), U802.A3 (VIN), U802.B3 (VIN), U802.C3 (SVIN), U803.A1 (VIN), U803.A2 (VIN), U803.A3 (VIN), U803.B3 (VIN), U803.C3 (SVIN); also elsewhere on the board
VN3P4: C824.2, C825.2, C826.2, C827.2, C829.2, C830.2, R808.2, TP807.P$1, U803.A5 (VOUT-), U803.B5 (VOUT-), U803.C2 (VOUT-), U803.C5 (VOUT-), U803.D5 (VOUT-), U803.E4 (SVOUT-), U803.E5 (VOUT-), U803.F5 (VOUT-), U803.G2 (SVOUT-), U803.G4 (VOUT-), U803.G5 (VOUT-), U803.H2 (SVOUT-), U803.H3 (VOUT-), U803.H5 (VOUT-), U803.J3 (VOUT-), U803.J4 (VOUT-), U803.J5 (VOUT-), U803.K4 (VOUT-), U803.K5 (VOUT-), U803.L4 (VOUT-), U803.L5 (VOUT-); also elsewhere on the board
VN3P4_EN: U803.F4 (RUN); also elsewhere on the board
VN22: C803.2, C804.2, C805.2, C806.2, C809.2, C810.2, C811.2, C814.2, C815.2, C816.2, C817.2, C820.2, C821.2, C822.2, R802.1, R803.2, R806.1, TP801.P$1, U801.A5 (VOUT-), U801.B5 (VOUT-), U801.C2 (VOUT-), U801.C5 (VOUT-), U801.D5 (VOUT-), U801.E4 (SVOUT-), U801.E5 (VOUT-), U801.F5 (VOUT-), U801.G2 (SVOUT-), U801.G4 (VOUT-), U801.G5 (VOUT-), U801.H2 (SVOUT-), U801.H3 (VOUT-), U801.H5 (VOUT-), U801.J3 (VOUT-), U801.J4 (VOUT-), U801.J5 (VOUT-), U801.K4 (VOUT-), U801.K5 (VOUT-), U801.L4 (VOUT-), U801.L5 (VOUT-), U802.A5 (VOUT-), U802.B5 (VOUT-), U802.C2 (VOUT-), U802.C5 (VOUT-), U802.D5 (VOUT-), U802.E4 (SVOUT-), U802.E5 (VOUT-), U802.F5 (VOUT-), U802.G2 (SVOUT-), U802.G4 (VOUT-), U802.G5 (VOUT-), U802.H2 (SVOUT-), U802.H3 (VOUT-), U802.H5 (VOUT-), U802.J3 (VOUT-), U802.J4 (VOUT-), U802.J5 (VOUT-), U802.K4 (VOUT-), U802.K5 (VOUT-), U802.L4 (VOUT-), U802.L5 (VOUT-); also elsewhere on the board
VN22_CLKA: TP804.P$1, U801.B1 (CLKIN); also elsewhere on the board
VN22_CLKB: TP805.P$1, U802.B1 (CLKIN); also elsewhere on the board
VN22_EN: R804.1, U801.F4 (RUN), U802.F4 (RUN); also elsewhere on the board

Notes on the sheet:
Negative Voltage Regulators
nominal: -50e-6*68e3 = 3.40
nominal: 2*-50e-6*220e3 = 22.0

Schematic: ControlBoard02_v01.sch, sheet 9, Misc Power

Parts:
C901, C902, C903, C944: 22u; 0805-CAP
C904, C905, C906, C907, C908, C909, C910, C911, C912, C913, C914: 4.7u; 0402-CAP
C915: DNP; 0805-CAP
C916, C917, C918, C919, C920, C921, C922, C923, C924, C925, C926, C927, C928, C929, C930, C931, C932, C933, C934, C935, C936, C937, C938, C939, C940, C941, C942: 0.1u; 0402-CAP
C943: 22p; 0402-CAP
FID901, FID902, FID903, FID904, FID905, FID906, FID907: FIDUCIALUFIDUCIAL; MICRO-FIDUCIAL
LED901: LTST-C191KRKT; LED-0603
R901: 47k; 0402-RES
R902: 100k; 0402-RES
R904: 3.48k; 0402-RES
R905: 100; 0402-RES
R906: 1k; 0402-RES
TP901, TP902: TESTPOINT_ROUND; TESTPAD_ROUND
TP903: TESTPOINTTUR; TURRET
U201: RP2040; QFN-56_EP
U301: MACHXO2_FTBGA256; LBGA-256
U901: MPM3630_FULL_CREAM; QFN-20-MPS_FULL_CREAM

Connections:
GND: C901.2, C902.2, C903.2, C904.2, C905.2, C906.2, C907.2, C908.2, C909.2, C910.2, C911.2, C912.2, C913.2, C914.2, C915.2, C916.2, C917.2, C918.2, C919.2, C920.2, C921.2, C922.2, C923.2, C924.2, C925.2, C926.2, C927.2, C928.2, C929.2, C930.2, C931.2, C932.2, C933.2, C934.2, C935.2, C936.2, C937.2, C938.2, C939.2, C940.2, C941.2, C942.2, C944.2, LED901.C, R902.1, R904.1, TP903.P$1, U201.PAD (GND), U301.B2 (GND), U301.B15 (GND), U301.C3 (GND), U301.C14 (GND), U301.D4 (GND), U301.D13 (GND), U301.E5 (GND), U301.E12 (GND), U301.F6 (GND), U301.F11 (GND), U301.H8 (GND), U301.H9 (GND), U301.J8 (GND), U301.J9 (GND), U301.L6 (GND), U301.L11 (GND), U301.M5 (GND), U301.M12 (GND), U301.N4 (GND), U301.N13 (GND), U301.P3 (GND), U301.P14 (GND), U301.R2 (GND), U301.R15 (GND), U901.3 (AGND), U901.12 (PGND), U901.13 (PGND), U901.14 (PGND); also elsewhere on the board
unnamed: LED901.A, R906.1
unnamed: C906.1, R905.2, U201.43 (ADC_VDD)
unnamed: C943.2, R901.1, R904.2, U901.1 (FB)
V1P1: C904.1, C916.1, C917.1, TP902.P$1, U201.23 (DVDD), U201.45 (VREG_VOUT), U201.50 (DVDD)
V3P3: C905.1, C907.1, C908.1, C909.1, C910.1, C911.1, C912.1, C913.1, C914.1, C915.1, C918.1, C919.1, C920.1, C921.1, C922.1, C923.1, C924.1, C925.1, C926.1, C927.1, C928.1, C929.1, C930.1, C931.1, C932.1, C933.1, C934.1, C935.1, C936.1, C937.1, C938.1, C939.1, C940.1, C941.1, C942.1, R905.1, R906.2, U201.1 (IOVDD), U201.10 (IOVDD), U201.22 (IOVDD), U201.33 (IOVDD), U201.42 (IOVDD), U201.44 (VREG_VIN), U201.48 (USB_VDD), U201.49 (IOVDD), U301.A1 (VCC), U301.A16 (VCC), U301.D5 (VCCIO0), U301.D12 (VCCIO0), U301.E4 (VCCIO5), U301.E13 (VCCIO1), U301.G7 (VCC), U301.G8 (VCCIO0), U301.G9 (VCCIO0), U301.G10 (VCC), U301.H7 (VCCIO4), U301.H10 (VCCIO1), U301.J7 (VCCIO4), U301.J10 (VCCIO1), U301.K7 (VCC), U301.K8 (VCCIO2), U301.K9 (VCCIO2), U301.K10 (VCC), U301.M4 (VCCIO3), U301.M13 (VCCIO1), U301.N5 (VCCIO2), U301.N12 (VCCIO2), U301.T1 (VCC), U301.T16 (VCC); also elsewhere on the board
V9P0: C902.1, C903.1, C943.1, C944.1, R901.2, TP901.P$1, U901.7_8_9 (VOUT); also elsewhere on the board
V9P0_EN: R902.2, U901.17 (EN/SYNC); also elsewhere on the board
V12: C901.1, U901.16 (VIN); also elsewhere on the board
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

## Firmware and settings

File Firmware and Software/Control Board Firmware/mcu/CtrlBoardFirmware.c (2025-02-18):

// Supporting RP2040 firmware for NinjaNIRS2022 Control Board
//
// This version is only for the second generation board with the LCMXO2-7000HC FPGA. 

// Update for new control board: 2024-4-19
// Initial version: 2023-3-3
// Bernhard Zimmermann - bzim@bu.edu
// Boston University Neurophotonics Center

// This firmware will read the output of an ISM330DHCX 6DOF IMU connected
// to a QWIIC port on the Control Board, and will then forward it to the FPGA.
// It behaves similar to a NN22 detector adapter card.

#include <stdio.h>
#include "pico/stdlib.h"
#include "pico/unique_id.h"
#include "hardware/i2c.h"
#include "hardware/pll.h"
#include "hardware/pwm.h"
#include "hardware/clocks.h"
//#include "hardware/watchdog.h"
#include "hardware/adc.h"
#include "ctrl_board_pins.h"


// Address of ISM330DHCX 6DOF IMU
// 0x6A if SA0 = low, 0x6B if SA0 = high
// (SA0 pin on sparkfun board is pulled high by default)
const uint8_t ACC_ADDR= 0x6B;
const uint8_t ACC_WHO_AM_I_ADDR = 0x0F;
const uint8_t ACC_WHO_AM_I_VAL = 0x6B;
const uint8_t ACC_CTRL3_C_ADDR = 0x12; 
const uint8_t ACC_CTRL3_C_VAL = 0x03; // software reset
const uint8_t ACC_CTRL1_XL_ADDR = 0x10;
const uint8_t ACC_CTRL1_XL_VAL = 0b01111000; //accel ODR (833Hz) and FS (+-4g)
const uint8_t ACC_CTRL2_G_VAL = 0b01110000; //gyro ODR (833Hz) and FS (+-250dps)
const uint8_t ACC_OUT_TEMP_L_ADDR = 0x20; //start of output registers
const uint8_t ACC_CTRL5_C_ADDR = 0x14;

// scaling factors and offsets
// const float ACC_ACCEL_SCF = 4.0/(2<<14);
// const float ACC_GYRO_SCF = 250.0/(2<<14);
// const float ACC_TEMP_SCF = 1.0/256;
// const float ACC_TEMP_OFFSET = 25.0;

// function declarations
int acc_set_self_test(int8_t st_val);
int read_acc_raw(uint8_t res_buf[14]);
int read_acc(int16_t res_buf[7]);
int init_acc();

int main()
{
    uint8_t loop_cnt = 0;
    uint8_t acc_res[14];
    int res;
    bool acc_connected_curr = false;
    bool acc_connected_before_run = false;
    bool acq_run_curr = false;
    bool acq_run_last;

    bool end_cyc_last = false;
	bool end_cyc_curr;
    bool start_phase = false;
    uint8_t cyc_cnt_run = 0;
	uint8_t cyc_cnt_tot = 0;
	const uint8_t PKT_HEADER[] = {249, 248};
    const uint8_t STATUS_PKT_HEADER[] = {237, 236};
	const uint8_t FIRMWARE_VERSION[] = {0, 1};

    pico_unique_board_id_t board_id;
	uint16_t temp_dig;
    uint16_t vin_dig;

    // Change system clock to 96 MHz to run at the same frequency as the FPGA and 
    // other RP2040s in the system.
    // 96 MHz allows us to get an exact baud rate of 6MBPS.
    /*
	$ python pll_divs.py 96
	Requested: 96.0 MHz
	Achieved: 96.0 MHz
	FBDIV: 128 (VCO = 1536 MHz)
	PD1: 4
	PD2: 4
	*/
	clock_stop(clk_peri);
	clock_configure(clk_sys,
					CLOCKS_CLK_SYS_CTRL_SRC_VALUE_CLK_REF,
					0,
					12 * MHZ,
					12 * MHZ);
	pll_deinit(pll_sys);
	pll_init(pll_sys, 1, 1536 * MHZ, 4, 4);
	clock_configure(clk_sys,
					CLOCKS_CLK_SYS_CTRL_SRC_VALUE_CLKSRC_CLK_SYS_AUX,
					CLOCKS_CLK_SYS_CTRL_AUXSRC_VALUE_CLKSRC_PLL_SYS,
					96 * MHZ,
					96 * MHZ);
	clock_configure(clk_peri,
					0,
					CLOCKS_CLK_PERI_CTRL_AUXSRC_VALUE_CLKSRC_PLL_SYS,
					96 * MHZ,
					96 * MHZ);

    stdio_init_all();

    // Unique board ID - read from flash
	pico_get_unique_board_id(&board_id);

    // Init LED pins
    gpio_init(LED_R_PIN);
    gpio_set_dir(LED_R_PIN, GPIO_OUT);
    gpio_init(LED_G_PINS[0]);
    gpio_set_dir(LED_G_PINS[0], GPIO_OUT);
    gpio_init(LED_G_PINS[1]);
    gpio_set_dir(LED_G_PINS[1], GPIO_OUT);
    

    gpio_init(END_CYC_PIN); //input
    gpio_init(STATUS_SELECT_PIN); //input
    gpio_init(RUN_IND_PIN); //input
    
    gpio_put(LED_R_PIN, 1);
    sleep_ms(50);
    gpio_put(LED_R_PIN, 0);

    // Internal ADC setup
	adc_init();
    adc_set_temp_sensor_enabled(true);
    adc_gpio_init(VIN_SENSE_PIN);
    adc_select_input(TEMP_ACH);
	temp_dig = adc_read();
    adc_select_input(VIN_SENSE_ACH);
	vin_dig = adc_read();

    // Turn Fan on
    gpio_init(FAN_PWR_PIN);
    gpio_set_dir(FAN_PWR_PIN, GPIO_OUT);
    gpio_put(FAN_PWR_PIN, 1);

    // Enable watchdog timer
    //watchdog_enable(500, true); //500 ms
    
    // UART initialisation
	uart_init(uart0, 6000000);
	uart_set_hw_flow(uart0, true, false); // enable CTS (tx flow control)
	gpio_set_function(UART_TX_PIN, GPIO_FUNC_UART);
	gpio_set_function(UART_RX_PIN, GPIO_FUNC_UART);
	gpio_set_function(BOARD_SELECT_PIN, GPIO_FUNC_UART);

    // I2C initialisation. Using it at 200Khz.
    i2c_init(ACC_I2C, 200*1000);
    gpio_set_function(I2C1_SDA_PIN, GPIO_FUNC_I2C);
    gpio_set_function(I2C1_SCL_PIN, GPIO_FUNC_I2C);
    gpio_pull_up(I2C1_SDA_PIN);
    gpio_pull_up(I2C1_SCL_PIN);

    // Blink + beep
    gpio_put(LED_G_PINS[1], 1);
    uint buzz_slice = pwm_gpio_to_slice_num(BUZZER_PIN);
    pwm_set_wrap(buzz_slice, 0xEFFF);
    pwm_set_chan_level(buzz_slice,  pwm_gpio_to_slice_num(BUZZER_PIN), 0xDFFF);
    pwm_set_clkdiv_int_frac(buzz_slice, 4, 0);
    pwm_set_enabled(buzz_slice, true);
    gpio_set_drive_strength(BUZZER_PIN, GPIO_DRIVE_STRENGTH_2MA);
    gpio_set_function(BUZZER_PIN, GPIO_FUNC_PWM);
    sleep_ms(100);
    pwm_set_clkdiv_int_frac(buzz_slice, 2, 0);
    sleep_ms(100);
    pwm_set_clkdiv_int_frac(buzz_slice, 1, 0);
    sleep_ms(160);
    pwm_set_enabled(buzz_slice, false);
    gpio_deinit(BUZZER_PIN);
    gpio_put(LED_G_PINS[1], 0);

    // Main Loop
    while (true) {
        acq_run_curr = gpio_get(RUN_IND_PIN);

        // Accelerometer init or reconnect
        if (!acc_connected_curr && (!acq_run_curr || acc_connected_before_run)){
            res = init_acc();
            if (res==PICO_ERROR_GENERIC){ // Accelerometer not connected or not replying.
                sleep_us(100);
            } else {
                acc_connected_curr = true;
            }
        }
        // acquisition starting 
        if (acq_run_curr && !acq_run_last) {
            acc_connected_before_run = acc_connected_curr;
            cyc_cnt_run = 0;
            start_phase = true;
        }
        // acquisition end
        if (!acq_run_curr && acq_run_last) {
            gpio_put(LED_G_PINS[0], 0);
        }
        gpio_put(LED_R_PIN, !acc_connected_curr);

        end_cyc_curr = gpio_get(END_CYC_PIN);
        if (end_cyc_curr == 1 && end_cyc_last == 0) { // FPGA requesting result
            if (gpio_get(STATUS_SELECT_PIN)){
                // write status packet into uart fifo
                uart_write_blocking(uart0, STATUS_PKT_HEADER, 2);
                uart_putc_raw(uart0, (char)cyc_cnt_tot);
                uart_write_blocking(uart0, board_id.id, 8);
                uart_write_blocking(uart0, FIRMWARE_VERSION, 2);
                uart_write_blocking(uart0, (uint8_t *) &temp_dig, 2);
                uart_write_blocking(uart0, (uint8_t *) &vin_dig, 2);
                uart_putc_raw(uart0, (acc_connected_before_run<<1) || acc_connected_curr);
                uart_putc_raw(uart0, 0); // future additional status info
                uart_putc_raw(uart0, 0); //possibly tx crc in future
                adc_select_input(TEMP_ACH);
                temp_dig = adc_read();
                adc_select_input(VIN_SENSE_ACH);
                vin_dig = adc_read();

            } else if (acc_connected_before_run){
                // write results into uart fifo
                // if IMU / acc somehow disconnected during acquisition run
                // send zeros instead
                // if IMU / acc was disconnected before run, send nothing
                uart_write_blocking(uart0, PKT_HEADER, 2);
                uart_putc_raw(uart0, (char)cyc_cnt_tot);
                uart_write_blocking(uart0, acc_res, 14);
                uart_putc_raw(uart0, 0); //possibly tx crc in future
                gpio_put(LED_G_PINS[0], 1);

                // get new result from IMU
                if (acc_connected_curr) {
                    res = read_acc_raw(acc_res);
                    if (res==PICO_ERROR_GENERIC){ // Accelerometer not replying
                        acc_connected_curr = false;
                        for (int ii=0; ii<14; ii++){
                            acc_res[ii] = 0;
                        }
                    }
                }
                
                // use first few samples of run to test the accelerometer
                if (start_phase){
                    if (cyc_cnt_run==10){
                        acc_set_self_test(-1);
                    } else if (cyc_cnt_run==20){
                        acc_set_self_test(1);
                    } else if (cyc_cnt_run>=30) {
                        acc_set_self_test(0);
                        start_phase = false;
                    }
                }
            }
            cyc_cnt_run += 1;
			cyc_cnt_tot += 1;
		}
		end_cyc_last = end_cyc_curr;
        acq_run_last = acq_run_curr;
        //watchdog_update();
    }

    return 0;
}

int acc_set_self_test(int8_t st_val)
{
    // this function enables the accelerometer and gyro self test
    // st_val = -1: negative self test (both gyro and acc)
    // st_val = 0: self_test off
    // st_val = 1: positive self test (both gyro and acc)

    uint8_t buf[2];

    buf[0] = ACC_CTRL5_C_ADDR;
    if (st_val==-1) { // negative self-test
        buf[1] = 0b00001110;
    } else if (st_val==1) { // positive self-test
        buf[1] = 0b00000101;
    } else { // normal mode (self-test off)
        buf[1] = 0;
    }
    i2c_write_blocking(ACC_I2C, ACC_ADDR, buf, 2, false);
    return 0;
}

int read_acc_raw(uint8_t res_buf[14])
{
    // this function reads temperature, accelerometer, and gyro data into res_buf
    i2c_write_blocking(ACC_I2C, ACC_ADDR, &ACC_OUT_TEMP_L_ADDR, 1, true);
    return i2c_read_blocking(ACC_I2C, ACC_ADDR, res_buf, 14, false);
}

int init_acc()
{
    // this fuction resets and initializes the ISM330DHCX IMU

    int res = 0;
    uint8_t buf[3];

    // check whether "who am i" register is ok
    res = i2c_write_blocking(ACC_I2C, ACC_ADDR, &ACC_WHO_AM_I_ADDR, 1, true);
    if (res==PICO_ERROR_GENERIC) { // acc not replying to I2C address/command
        return PICO_ERROR_GENERIC;
    } else {
        i2c_read_blocking(ACC_I2C, ACC_ADDR, buf, 1, false);
        if (buf[0]!=ACC_WHO_AM_I_VAL){ // not the correct model connected
            return PICO_ERROR_GENERIC;
        }
    }  

    // reset the acc
    buf[0] = ACC_CTRL3_C_ADDR;
    buf[1] = ACC_CTRL3_C_VAL;
    i2c_write_blocking(ACC_I2C, ACC_ADDR, buf, 2, false);
    sleep_us(100);

    // config acc
    buf[0] = ACC_CTRL1_XL_ADDR;
    buf[1] = ACC_CTRL1_XL_VAL;
    buf[2] = ACC_CTRL2_G_VAL;
    i2c_write_blocking(ACC_I2C, ACC_ADDR, buf, 3, false);

    //read back and verify
    buf[0]=0;
    buf[1]=0;
    i2c_write_blocking(ACC_I2C, ACC_ADDR, &ACC_CTRL1_XL_ADDR, 1, true);
    i2c_read_blocking(ACC_I2C, ACC_ADDR, buf, 2, false);
    if (buf[0]!=ACC_CTRL1_XL_VAL || buf[1]!=ACC_CTRL2_G_VAL){
        return PICO_ERROR_GENERIC;
    }

    return 0;
}

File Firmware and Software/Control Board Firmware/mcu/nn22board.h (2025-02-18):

/*
 * Copyright (c) 2020 Raspberry Pi (Trading) Ltd.
 *
 * SPDX-License-Identifier: BSD-3-Clause
 */

// -----------------------------------------------------
// NOTE: THIS HEADER IS ALSO INCLUDED BY ASSEMBLER SO
//       SHOULD ONLY CONSIST OF PREPROCESSOR DIRECTIVES
// -----------------------------------------------------

// ---  NinjaNIRS 2022  ---
// Modified from pico.h for NinjaNIRS.
// Should be compatible with all NinjaNIRS boards that use the RP2040,
// except the first generation control board, which has a larger EEPROM.
//
// Initial version: 2024-4-20 (DetBoardTest00)
// Bernhard Zimmermann - bzim@bu.edu
// Boston University Neurophotonics Center

#ifndef _BOARDS_NN22BOARD_H
#define _BOARDS_NN22BOARD_H

// For board detection
#define NN22BOARD

// --- FLASH ---

// On some samples (~10%), the xosc can take longer to stabilize than is usual
#ifndef PICO_XOSC_STARTUP_DELAY_MULTIPLIER
#define PICO_XOSC_STARTUP_DELAY_MULTIPLIER 64
#endif

#define PICO_BOOT_STAGE2_CHOOSE_W25Q080 1

#ifndef PICO_FLASH_SPI_CLKDIV
#define PICO_FLASH_SPI_CLKDIV 4
#endif

#ifndef PICO_FLASH_SIZE_BYTES
#define PICO_FLASH_SIZE_BYTES (2 * 1024 * 1024)
#endif

/*
// --- UART ---
#ifndef PICO_DEFAULT_UART
#define PICO_DEFAULT_UART 0
#endif
#ifndef PICO_DEFAULT_UART_TX_PIN
#define PICO_DEFAULT_UART_TX_PIN 0
#endif
#ifndef PICO_DEFAULT_UART_RX_PIN
#define PICO_DEFAULT_UART_RX_PIN 1
#endif

// --- LED ---
#ifndef PICO_DEFAULT_LED_PIN
#define PICO_DEFAULT_LED_PIN 25
#endif
// no PICO_DEFAULT_WS2812_PIN

// --- I2C ---
#ifndef PICO_DEFAULT_I2C
#define PICO_DEFAULT_I2C 0
#endif
#ifndef PICO_DEFAULT_I2C_SDA_PIN
#define PICO_DEFAULT_I2C_SDA_PIN 4
#endif
#ifndef PICO_DEFAULT_I2C_SCL_PIN
#define PICO_DEFAULT_I2C_SCL_PIN 5
#endif

// --- SPI ---
#ifndef PICO_DEFAULT_SPI
#define PICO_DEFAULT_SPI 0
#endif
#ifndef PICO_DEFAULT_SPI_SCK_PIN
#define PICO_DEFAULT_SPI_SCK_PIN 18
#endif
#ifndef PICO_DEFAULT_SPI_TX_PIN
#define PICO_DEFAULT_SPI_TX_PIN 19
#endif
#ifndef PICO_DEFAULT_SPI_RX_PIN
#define PICO_DEFAULT_SPI_RX_PIN 16
#endif
#ifndef PICO_DEFAULT_SPI_CSN_PIN
#define PICO_DEFAULT_SPI_CSN_PIN 17
#endif
*/


#ifndef PICO_RP2040_B0_SUPPORTED
#define PICO_RP2040_B0_SUPPORTED 0
#endif


#endif

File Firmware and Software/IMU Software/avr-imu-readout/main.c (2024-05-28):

/*
 * main.c - main program for AVR IMU readout
 * 
 * wait to receive any character
 *
 * sends a binary return record
 *   <echo> <count> <length> <checksum>
 *
 * offset 0      <echo>     = xx   echo of byte received
 * offset 1      <count>    = 14   normal data, 
 * offset 2..15  <data>     =      (7) 16-bit words of Temp, GyroX/Y/Z, Accel X/Y/Z
 * offset 16     <checksum> =      uint8_t sum of bytes at offset 1..15
 *
 * if any error occurs, <count> = 1 and the error code is somehow related
 * to the I2C error.
 */

#include <stdio.h>
#include <string.h>
#include <stdbool.h>
#include <avr/io.h>
#include <util/delay.h>
#include "uart.h"
#include "i2c.h"

#include "imu.h"
#include "imu_const.h"

// #define LED_BLINKS
// #define DEBUG_COMMANDS

#include "leds.h"

#ifdef AVR_TARGET
// bits for TWI interface for pull-up enable
#define TWI_PORT PORTC
#define TWI_BITS_MASK ((1 << 4) | (1 << 5))
#endif


// these work for both (jumpers on target, D3 and D4 on Arduino)
#define JUMPER_DDR DDRD
#define JUMPER_PORT PORTD
#define JUMPER_1_BIT 4
#define JUMPER_2_BIT 3

void send_data( uint8_t nb, uint8_t* d);

// dummy data for testing
static int16_t acc_test[] = { 1111, 2222, 3333, 4444, 5555, 6666, 7777 };

int main (void)
{
  uint8_t loop_cnt = 0;
  int16_t acc_res[7];
  uint8_t res;
  uint8_t chr;
  bool acc_connected = false;

  USART0Init();			/* initialize USART (no interrupts) */

#ifdef AVR_TARGET
  // activate internal pull-ups on I2C pins
  TWI_PORT |= TWI_BITS_MASK;
#endif

  // activate pull-ups on jumpers
  JUMPER_PORT |= ((1 << JUMPER_1_BIT) | (1 << JUMPER_2_BIT));

  // setup I/O bits
  LED_DDR |= (1 << LED_BIT);

  i2c_init( BDIV);		/* initialize I2C */

#ifdef LED_BLINKS
  // blink the LED
  blink_led( 3, 250);
#endif
  
#ifdef DEBUG_COMMANDS
  // send a '*' to indicate we're alive
  USART0SendByte( '*', 0);
#endif

  while ( true) {

    res = USART0ReceiveByte(0);

#ifdef DEBUG_COMMANDS
    if( res == 'T') {

#ifdef LED_BLINKS
      blink_led( 2, 100);
#endif
      // send fake data
      send_data( 14, (uint8_t *)acc_test);

    } else if( res == 'A') {
#ifdef LED_BLINKS
      blink_led( 1, 100);
#endif

#endif


      // Accelerometer init
      while (!acc_connected){
	res = init_acc();
	if (res){      		/* error return */
	  //	  chr = 'E';
	  //	  send_data( 1, &chr);
	  send_data( 1, &res);
	  _delay_ms(250);
	  acc_connected = false;
	} else {
	  //	  chr = 'O';
	  //	  send_data( 1, &chr);
	  acc_connected = true;
	}
      }

      // simple mode, just send the data or an error packet
      res = read_acc(acc_res);
      if (res){    		/* error return */
	send_data( 1, &res);
	acc_connected = false;
      }

      // send the data
      send_data( sizeof(acc_res), (uint8_t *)acc_res);

#ifdef DEBUG_COMMANDS      

    } else {
      res = 'X';
      send_data( 1, &res);
    }      
#endif

  }

}

//
// send nb bytes of data from d to serial port
// (blocking) followed by checksum
//
void send_data( uint8_t nb, uint8_t* d) {
  uint8_t sum = nb;
  USART0SendByte( nb, 0);
  for( uint8_t i=0; i<nb; i++) {
    USART0SendByte( d[i], 0);
    sum += d[i];
  }
  USART0SendByte( sum, 0);
}

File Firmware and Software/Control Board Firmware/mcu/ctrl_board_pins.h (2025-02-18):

// ---  NinjaNIRS 2022  ---
// Pin constants for ControlBoard02_v01 board
// This is the new control board with LCMXO2-7000HC FPGA.
//
// Initial version: 2024-04-19
// Bernhard Zimmermann - bzim@bu.edu
// Boston University Neurophotonics Center
//

// FPGA interface pins
const uint UART_TX_PIN = 12;
const uint UART_RX_PIN = 13;
const uint BOARD_SELECT_PIN = 14;  //CTS flow control
const uint END_CYC_PIN = 15;
const uint STATUS_SELECT_PIN = 16;
const uint RUN_IND_PIN = 17; // Run indicator input

// Qwiic RPiP1 port
const uint I2C1_SDA_PIN = 10;
const uint I2C1_SCL_PIN = 11;
#define ACC_I2C i2c1

// Misc Pins
const uint LED_R_PIN = 5;
const uint LED_G_PINS[] = {4, 3};
const uint BUTTON_PIN = 6;
const uint BUZZER_PIN = 7;
const uint FAN_PWR_PIN = 24;
const uint FAN_SENSE_PIN = 25;
const uint V12_CURR_SENSE_PIN = 26;
const uint V12_CURR_SENSE_ACH = 0;
const uint AUXIO_PINS[] = {29, 27};
const uint AUXIO_ACHS[] = {3, 1};
const uint VIN_SENSE_PIN = 28;
const uint VIN_SENSE_ACH = 2;
const uint TEMP_ACH = 4; // Internal temperature sensor virtual pin

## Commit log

2024-02-12 Acrylic Enclosure Technical Documents
    Uploading all technical documents for the acryllic and 3D printed components in enclosure revision AB
2024-03-22 Updated Assembly Instructions 22 March 2024
2024-05-20 Add files via upload
    Updated version of Assembly Instructions with all part files and drawings 20 May, 2024.
2024-05-20 Delete Acryllic Enclosure Assembly.zip
    Removal of incorrect zip file
2024-05-22 Add Battery Box Files
    Zip files containing Solidworks 2023 parts and Eagle PCB files
2024-05-23 Add battery box BOM file
    [Battery_Circuit_BOM.csv]
2024-05-23 Add files via upload
    Splitter box electrical circuit diagram files for sources and detectors.
2024-05-23 Add files via upload
    NN22 Control Board V4 files
    [ControlBoard00_v04_NewNetNamesNewBackplanes.brd, ControlBoard00_v04_NewNetNamesNewBackplanes.sch, ControlBoard00_v04_NewNetNamesNewBackplanes_BOMbyDesignator.x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]
2024-05-23 Add files via upload
    Detector backplane files
    [DetBackplaneSingleLayer01.brd, DetBackplaneSingleLayer01.sch, DetBackplaneSingleLayer01_BOM.xlsx]
2024-05-23 Add files via upload
    Detector interface board files
    [NN22_RPi_DetAdapter01_s00.brd, NN22_RPi_DetAdapter01_s00.sch, NN22_RPi_DetAdapter01_s00_BOM_b.xlsx]
2024-05-23 Add files via upload
    7 slot source backplane files
    [SrcBackplane01_7slots.brd, SrcBackplane01_7slots.sch]
2024-05-23 Add files via upload
    1 slot source backplane files
    [SrcBackplaneSingleLayer00_01.brd, SrcBackplaneSingleLayer00_01.sch]
2024-05-23 Add files via upload
    Source interface card files
    [NN22_7Lvl_ResSrcAdapter02_s00.brd, NN22_7Lvl_ResSrcAdapter02_s00.sch, NN22_7Lvl_ResSrcAdapter02_s00_BOM.xlsx]
2024-05-23 Add files via upload
    6 slot detector backplane files
    [DetBackplane01.brd, DetBackplane01.sch]
2024-05-23 Organization of file system.
    [Battery_Circuit_BOM.csv, ControlBoard00_v04_NewNetNamesNewBackplanes.brd, ControlBoard00_v04_NewNetNamesNewBackplanes.sch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]
2024-05-24 File reorganization
    [DetBackplane01.brd, DetBackplane01.sch, DetBackplaneSingleLayer01.brd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]
2024-05-24 Source PCB File Reorganization
    [NN22_7Lvl_ResSrcAdapter02_s00.brd, NN22_7Lvl_ResSrcAdapter02_s00.sch, NN22_7Lvl_ResSrcAdapter02_s00_BOM.xlsx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]
2024-05-28 Add files from EH.
    [1551T.dxf, 1551TGY.stp, 1551T_Box.step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]
2024-06-17 Add files via upload
    PDF of acrylic enclosure assembly documentation.
2024-06-17 Add Schematic PDF for battery circuit
2024-06-27 Add Detector Files
    [#curve_flexi_ra.dxf, 1551Q.igs, 1551Q.stp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]
2024-06-27 Revert "Add Detector Files"
    This reverts commit e8c7ac16a3e25841cc6b62164293f4582a5eec2a.
    [#curve_flexi_ra.dxf, 1551Q.igs, 1551Q.stp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]
2024-06-27 Detector File Updates
    [#curve_flexi_ra.dxf, 1551Q.igs, 1551Q.stp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]
2024-07-24 Adding Control Board v2 with gerbers.
    [ControlBoard02_v01.brd, ControlBoard02_v01.sch, ControlBoard02_v01_BOM.xlsx]
2024-07-24 Adding gerbers to backplanes.
    [DetBackplaneSingleLayer01.XYRS.csv]
2024-07-24 Adding gerbers to source interface card.
    [NN22_7Lvl_ResSrcAdapter02_s00.XYRS.csv]
2024-07-24 Updating detector interface card and adding gerbers.
    [NN22_RPi_DetAdapter01_s00_BOM_b.xlsx, NN22_RPi_DetAdapter02_s00.brd, NN22_RPi_DetAdapter02_s00.sch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]
2024-07-25 Adding IMU interface card.
    [1551T.dxf, 1551TGY.stp, 1551T_Box.step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]
2024-07-25 ninjaPACK BOM Upload
    [ninjaPACK_BOM.csv]
2024-07-29 Add Colocated Source Part Files
    [WOJ-NNEEG-EA-003-RevAD.SLDPRT, WOJ-NNEEG-EA-003-RevAD.STL, WOJ-NNEEG-EA-005-RevAE.SLDPRT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]
2024-07-29 Colocation Organization
    [WOJ-NNEEG-EA-003-RevAD.SLDPRT, WOJ-NNEEG-EA-003-RevAD.STL, WOJ-NNEEG-EA-005-RevAE.SLDPRT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]
2024-07-29 Added gerbers for co-located source optode.
    [LEDadapter00.brd, LEDadapter00.sch]
2024-07-29 Adder gerbers for source optode pcb.
    [NN23_Dual_Src_Optode_00.brd, NN23_Dual_Src_Optode_00.sch]
2024-08-05 File system reorganization
    [1551T.dxf, 1551TGY.stp, 1551T_Box.step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]
2024-08-05 Fix Flex Optode Folder
    [flex-VEMD.kicad_pcb, flex-VEMD.kicad_sch]
2024-08-06 Add Standard Detector Files
    [NN23_Det_Optode_02_OPA.brd, NN23_Det_Optode_02_OPA.sch]
2024-08-29 Remove Old FIles
    [1598B Bottom.igs, 1598B Bottom.stp, 1598B End Plate.igs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]

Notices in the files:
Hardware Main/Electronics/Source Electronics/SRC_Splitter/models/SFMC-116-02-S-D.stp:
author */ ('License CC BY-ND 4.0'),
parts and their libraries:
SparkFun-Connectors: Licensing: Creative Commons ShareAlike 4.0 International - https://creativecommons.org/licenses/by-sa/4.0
